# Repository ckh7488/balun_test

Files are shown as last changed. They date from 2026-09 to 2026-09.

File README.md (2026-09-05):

# LibreVNA balun Ethernet 측정

**2026-09-05 임피던스·주문 갱신:** [실제 화면과 옵션별 이유](docs/jlcpcb/README.md) · [계산기 결과 및 CAD 변경/검증](docs/jlcpcb/IMPEDANCE.md). 현재 W/G=0.234/0.216 mm, RF W=0.357 mm를 적용했다.

**Molex 배선 후속 개선:** [전후 그림·수치·설계 판단](docs/molex-routing/README.md). 신호 비아 0개를 유지하며 폭 0.234 mm 통일, A/B 길이 차이 0.79/0.99 mm를 적용했다.

산업용 100BASE-TX 케이블·커넥터·슬립링의 **정적 전송 품질을 먼저 평가**하기 위한 프로젝트다. 일반 RJ45 케이블과 사내 전용 핀맵의 케이블을 같은 플랫폼에서 측정한다.

**설계 검토를 시작한다면 [설계 의도·패치 범위·검토 인계](DESIGN_REVIEW_HANDOFF.md)를 먼저 읽는다.** 사용자 요구, 구현 선택 이유, 현재/이전 문서 구분, 검증 증거와 남은 질문을 정리했다. 현재는 배선된 CAD와 합성 검증 단계이며, O/S/L/T 표준 PCB·실물 RF 검증·새 구성의 제조 release는 아직 없다.

## 현재 기본 구성

양쪽에 `LibreVNA coax → SMA–balun–RJ45 PCB → 고정 RJ45 연결 → 교체형 커넥터 어댑터 → DUT`를 사용한다. 일반 RJ45 DUT는 어댑터 없이 연결한다. 최종 보정 기준면은 **어댑터 뒤의 DUT 접속면**이다. M12와 Molex 조합처럼 양끝 커넥터가 달라도 같은 원리를 사용한다.

1. LibreVNA에서 두 coax 끝의 **50 Ω full 2-port SOLT**를 수행하고 계속 활성화한다.
2. 지그와 어댑터를 고정하고 양쪽 DUT 접속면에서 O/S/L 각 3개와 자작 reciprocal thru 1개를 **측정·저장**한다.
3. Python `UnknownThru`가 이 **7개 표준 데이터**로 커넥터 끝 보정계수를 만든다.
4. 같은 SMA 보정 상태로 측정한 DUT `.s2p`에 저장된 계수를 적용한다. 결과는 **100 Ω balanced effective two-port** `.s2p`, CSV, 그래프다.

LibreVNA 화면은 SMA 기준으로 남는다. 자작 thru를 이상적인 0 ps thru로 등록해 LibreVNA에서 두 번째 SOLT를 켜는 절차가 아니다. 보정에 DUT 파일을 포함하지 않는다.

## 읽는 순서

| 문서/경로 | 내용 |
| --- | --- |
| [DESIGN_REVIEW_HANDOFF.md](DESIGN_REVIEW_HANDOFF.md) | 패치 목적과 변경 범위, 설계 판단 근거, 검토 우선순위·재현 방법 |
| [VNA_TEST_PLAN.md](VNA_TEST_PLAN.md) | 목적, 기준면, 표준 제작, 측정·검증 순서 |
| [analysis/README.md](analysis/README.md) | 설치, 3+3+1 파일 입력, 보정 저장과 DUT 처리 |
| [balun_eth_rj45](balun_eth_rj45/README.md) | 공통 SMA–RJ45 balun PCB |
| [adapters](adapters/README.md) | JLCPCB용 교체형 어댑터와 지그 검토 |
| [docs/legacy](docs/legacy/README.md) | 종전 SMA 기준 비교 계획; 변경 이력용 |

`balun_slipring/`과 `balun_llc16/`의 커넥터 전용 balun PCB는 기존 설계 자산이다. 현재 기본안은 **공통 RJ45 balun PCB + 커넥터별 수동 어댑터 PCB**이며, 과거 4/8/10장 등 구매 문서는 이 기본안의 최신 발주 수량표가 아니다. 기존 설계·BOM을 삭제하거나 이미 주문한 물량을 취소한 것은 아니다. 기존 `export_jlc_release.ps1`도 새 `adapters/`를 export하지 않는다. [이력 자료 목록](docs/legacy/README.md)에서 적용 범위를 확인한다.

## 결과의 의미

OSL의 모델 오차, 재체결 변화, 지그 간 누설과 mode conversion은 남는다. 소프트웨어의 합성 데이터 검증은 실제 커넥터 정확도 검증과 구분한다. 보정된 IL/RL이 좋아도 산업 환경의 EMC·회전 중 순간단선·장기 수명을 보장하지 않는다. 먼저 실제 길이의 수동 조립체를 평가하고, 이후 동작·환경 시험으로 이어간다.

실측 데이터와 결과는 기본적으로 `measurements/`, `results/`에 두며 Git에서 제외한다. 이 공개 저장소에는 코드와 설계·절차를 관리한다.

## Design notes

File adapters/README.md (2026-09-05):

# RJ45 공통 지그용 커넥터 어댑터 PCB

설계 의도·이전 전용 지그와의 차이·검토 우선순위는 [설계 검토 인계](../DESIGN_REVIEW_HANDOFF.md)를 따른다. 아래 세 보드는 **수동 연결 어댑터**다. O/S/L/T 표준 PCB와 패널 도면, 제조 release까지 설계된 상태는 아니다.

**선택: 공통 balun 지그는 기존 RJ45 Rev B를 사용하고, 반복 측정용 어댑터는 PCB로 만든다.** 손배선에서 움직이는 untwist·납땜 부위의 형상을 고정할 수 있고, 커넥터 종류가 바뀌어도 balun PCB를 새로 만들 필요가 없다.

상태: **배선 완료, KiCad 10.0.x DRC/ERC/회로도 대조 통과. 실물 mating·패널 기구·JLC 생산 CAM/coupon 승인 전 설계 초안. 공식 계산기 치수 반영은 완료했다.** 정확한 재검증 버전은 `verification.json`에 기록한다. 제조사 임피던스 시험이나 실측 RF 검증까지 완료했다는 뜻은 아니다.

## 구성과 제작 방식

`공통 SMA–balun–RJ45 PCB → 짧은 shielded RJ45 patch cable → 이 어댑터 PCB → DUT`

PCB용 RJ45 jack과 공장제 patch cable을 사용한다. 일반 RJ45 plug를 PCB 끝에 억지로 납땜하는 형태는 피하고, 측정 중 patch cable과 두 PCB를 고정한다. patch cable까지 어댑터 끝 보정에 포함한다. 일반 RJ45 DUT는 어댑터 없이 공통 지그에 연결한다.

| 어댑터 | DUT 쪽 PCB 커넥터 | 조립 판단 |
| --- | --- | --- |
| [m12_slipring](m12_slipring/m12_slipring.kicad_pro) | Finecables `MB12FBAFF08ST-3`, A-code 8핀 **암** | THT; 부품 조달 뒤 손납땜 가능한 구조. PG9 패널/브래킷으로 체결 토크 지지 |
| [m12_llc](m12_llc/m12_llc.kicad_pro) | Finecables `MB12MBAFF08ST-3`, A-code 8핀 **수** | THT; LLC 암 케이블용. 위 암 버전과 핀맵/성별이 다름 |
| [molex_slipring](molex_slipring/molex_slipring.kicad_pro) | Molex `5055680571`, 1.25 mm 5핀 SMT | 손납땜 가능성은 있으나 작은 SMT이므로 stencil/reflow 또는 JLC PCBA 권장 |

M12는 기존 저장소의 PCB 핀형 후보를 사용했다. 사내에 있는 **전선 인출형/납땜 컵형 M12 몸체를 그대로 이 풋프린트에 꽂을 수 있다는 의미가 아니다.** 실제 사내 부품을 재사용하려면 몸체 형식·핀 배열 도면에 맞춘 별도 carrier가 필요하다. 본 세 설계는 표에 적힌 PCB용 부품을 기준으로 한다.

Molex 케이블 housing은 기존 문서의 `5055650501` 후보와 실제 체결을 확인해야 한다. 같은 Molex 브랜드, 같은 핀 수만으로 호환되지 않는다. [제조사 제품 페이지](https://www.molex.com/en-us/products/part-detail/5055680571)의 mating cycle 정격도 고려해 시험용 커넥터의 교체/재체결 기록을 남긴다.

## 고정 핀맵

다음은 **저장소에 있던 사내 케이블 두 종류의 전용 배선**이다. 범용 M12 Ethernet 핀맵이 아니다. 임의 solder jumper 선택지를 넣지 않고 각 PCB 이름과 결선을 고정했다.

| RJ45 | 신호 | M12 슬립링 암 | M12 LLC 수 | Molex 슬립링 |
| --- | --- | ---: | ---: | ---: |
| 1 | A+ | 4 | 8 | 1 |
| 2 | A− | 3 | 2 | 2 |
| 3 | B+ | 2 | 3 | 3 |
| 6 | B− | 1 | 4 | 4 |
| 4, 5, 7, 8 | 미사용 | 연결 안 함 | 연결 안 함 | 연결 안 함 |

- 슬립링 M12 5–8, LLC M12 1/5/6/7, Molex 5는 PCB에서 각각 독립 NC다.
- LLC 전원 핀이나 슬립링 보조 신호/전원 핀을 GND 또는 shell에 연결하지 않는다.
- 핀맵 근거: [슬립링 PINMAP](../balun_slipring/PINMAP.md), [LLC fixture_spec](../balun_llc16/fixture_spec.json). 실제 DUT continuity 검증은 별도다.
- Open/Short/Load는 각 DUT 접속면에서 해당 **pair의 두 핀 사이**로 만든다. 이 어댑터 자체에 O/S/L 스위치를 넣지 않았다. 표준 정의는 [측정 계획](../VNA_TEST_PLAN.md)을 따른다.

## PCB 사양

| 항목 | 설계값 |
| --- | --- |
| 크기 / 홀 | 66 × 40 mm / 네 모서리 Ø3.2 mm NPTH, M3용 |
| stack-up | 4층 `JLC04161H-7628`, 주문 1.6 mm, nominal 1.5862 mm |
| 동박 | 외층 1 oz, 내층 0.5 oz |
| reference planes | L2/L3 SHIELD plane, stitch via 연결; 내층 신호 배선 없음 |
| pair A / pair B | M12 슬립링·Molex는 두 pair 모두 F.Cu; M12 LLC만 각각 F.Cu / B.Cu |
| coupled trunk | 100 Ω 목표, W 0.234 mm / edge gap 0.216 mm |
| KiCad differential pair 설정 | `ETH100`: width 0.234 mm / gap 0.216 mm; `/PAIR_*` 자동 할당 |
| RJ45 pad escape | M12는 W 0.15 mm neckdown; **Molex는 전 구간 W 0.234 mm**. 팬아웃 전체의 100Ω 보장을 의미하지 않음 |
| signal via | 세 어댑터 모두 0개 |
| shield 접속 | RJ45 SH ↔ 내층 plane; TP1은 M12 두 종류에만 있고 Molex에는 DUT-side bond 없음 |
| M12 body | PCB 신호 핀에 shell 접속 없음; 패널/TP1 연결 여부를 별도 정의·기록 |

모든 부품 몸체는 F면이다. LLC M12는 부품 기준 180° 회전이며 도면/PCB의 A-key와 pin 1 표시를 따른다. M12 체결 토크를 신호 핀 납땜부에 맡기지 않는다. M3 head/washer는 OD 7 mm 이하의 기구 검토 범위이며, M12 panel 높이·nut 접근·실제 connector seating은 실물 도면으로 맞춘다.

| 어댑터 | A+ / A− 배선 길이 | B+ / B− 배선 길이 |
| --- | ---: | ---: |
| M12 슬립링 | 32.793 / 31.855 mm | 32.253 / 33.084 mm |
| M12 LLC | 36.659 / 36.659 mm | 28.514 / 28.514 mm |
| Molex 슬립링 | 31.247 / 30.455 mm | 30.410 / 29.424 mm |

M12 슬립링은 M12 body를 −30° 회전하고 두 pair를 F.Cu에 배치했다. PCB track 길이 차이는 A 약 0.94 mm, B 약 0.83 mm이며 signal via는 없다. [계산·검증 상세](../docs/jlcpcb/IMPEDANCE.md)를 참고한다.

길이는 track 중심선 합계이며 커넥터 내부 핀 길이와 via 전기 길이를 포함하지 않는다. M12 슬립링과 Molex는 큰 길이보정 우회로·layer change보다 짧고 밀접한 배선을 우선했다. Molex는 후속 RJ45 탈출부 개선으로 0.15 mm 구간을 제거했고, PCB track 길이 차이는 **A 0.792 mm / B 0.987 mm**다. 긴 결합 구간과 페어 간격을 함께 고려했으며 [수정 의도·전후 비교](../docs/molex-routing/README.md)를 참고한다. 최종 mode conversion이나 정확한 임피던스는 이 표만으로 보장하지 않는다.

**RF 재검토 우선 항목:** 특히 M12 LLC pair A의 넓은 fanout이 작은 skew를 허용한 더 짧고 밀접한 배선보다 유리한지 확인해야 한다. track 합계 길이 일치에 앞서 uncoupled 길이, loop 면적, 기준면에 대한 대칭을 함께 비교한다. 현재 형상의 우월성을 EM 해석이나 실측으로 검증하지 않았다.

## 레이아웃

빨강 F.Cu, 파랑 B.Cu. M12 LLC의 교차처럼 보이는 다른 색 선은 서로 다른 외층이며 사이에 두 reference plane이 있다. M12 슬립링과 Molex의 두 pair는 모두 빨강 F.Cu다. `planes.svg`에서 채워진 내층 plane도 확인할 수 있다.

### M12 슬립링용 암

M12 slipring layout

[회로도](m12_slipring/m12_slipring.kicad_sch) · [PCB](m12_slipring/m12_slipring.kicad_pcb) · [내층](m12_slipring/planes.svg)

### M12 LLC용 수

M12 LLC layout

[회로도](m12_llc/m12_llc.kicad_sch) · [PCB](m12_llc/m12_llc.kicad_pcb) · [내층](m12_llc/planes.svg)

### Molex 슬립링용

Molex slipring layout

[회로도](molex_slipring/molex_slipring.kicad_sch) · [PCB](molex_slipring/molex_slipring.kicad_pcb) · [내층](molex_slipring/planes.svg)

## 검증과 JLC 제작

- [기존 지그 검토](FIXTURE_REVIEW.md)
- [JLCPCB 제작 조건과 조립 BOM](JLCPCB_BUILD.md)
- [검증 결과와 CAD SHA-256](verification.json)
- [풋프린트 출처](FOOTPRINT_SOURCES.md)

```bash
# KiCad 10의 pcbnew가 설치된 Python으로 새 폴더에만 재생성
python adapters/generate_adapters.py /path/to/new-output
# 저장소의 세 보드 zone refill / DRC / ERC / parity / pinmap / SVG
python adapters/verify_adapters.py --kicad-cli /path/to/kicad-cli
```

generator는 이미 존재하는 출력 폴더를 덮어쓰지 않는다. `verify_adapters.py`는 zone fill을 보드에 저장한 뒤 검사와 hash를 기록한다. 검사 통과는 핀맵의 CAD 전사·배선 검증이며 제조사 mating 검증이나 양산 release 승인이 아니다.

세 프로젝트의 `ETH100` netclass에는 differential width 0.234 mm와 gap 0.216 mm가 실제 저장되어 있다. 사용자 규칙은 coupled gap 최소 0.21 mm, pair skew 최대 2.00 mm, uncoupled 길이 최대 16.60 mm와 signal via 0개를 DRC에서 추가로 강제한다.

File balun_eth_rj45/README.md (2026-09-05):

# balun_eth_rj45 Rev B

**2026-09-05 현재 역할:** 교체형 수동 어댑터와 공유하는 공통 balun PCB다. 방향 전환 당시 회로/동박을 유지했으며, 후속 임피던스 확인에서 배선 폭을 수정했다. [2026-09-05 계산·검증](../docs/jlcpcb/IMPEDANCE.md)과 [주문 화면 가이드](../docs/jlcpcb/README.md)를 따른다. 설계 선택 이유와 검증 한계는 [설계 검토 인계](../DESIGN_REVIEW_HANDOFF.md), 실제 CAD 검토는 [FIXTURE_REVIEW](../adapters/FIXTURE_REVIEW.md)를 참고한다.

2026-09-03: 기존 회로도를 채널별 A3 한 장으로 재배치했다. 연결·부품·DNP와 PCB는 그대로이며, [가독성 정리 결과 및 PDF](../SCHEMATIC_READABILITY_2026-09-03.md)를 참고한다.

LibreVNA 2-port로 일반 Ethernet 케이블과 전용 Ethernet 슬립링을 측정하기 위한 수동 4-pair RJ45 지그다. 동일 보드 2장을 DUT 양쪽에 사용하며, 한 번에 한 pair를 VNA의 두 포트로 측정한다. through 측정에서는 각 보드의 미사용 SMA 3개씩, 두 장 합계 **6개**에 외부 50 Ω 종단기를 연결한다. NEXT/FEXT 등 다른 포트 배치에서도 전체 8개 중 미사용 6개를 종단한다.

> 수동 DUT 전용이다. PoE나 동작 중인 Ethernet 장비에는 연결하지 않는다.

현재 기본안은 이 공통 PCB 두 장과 교체형 RJ45–M12/Molex 어댑터다. 최종 기준면은 어댑터 뒤 DUT 접속면으로 두며 [공통 측정 계획](../VNA_TEST_PLAN.md)과 [어댑터 설계](../adapters/README.md)를 따른다. 기존 LLC/M12 전용 balun PCB와 PCBA 10장 계획은 이전 설계 선택지로 보존한다.

## 채널 구성

| SMA | RJ45 pair | Balun |
|---|---|---|
| J2 / A | 1(+)–2(-) | T1 |
| J3 / B | 3(+)–6(-) | T2 |
| J4 / C | 4(+)–5(-) | T3 |
| J5 / D | 7(+)–8(-) | T4 |

T1–T4는 Mini-Circuits `ADT2-1T+`다. primary pin 3은 SMA center, pin 1은 GND이며, secondary pin 4/6은 각각 pair P/N, pin 5는 RCT, pin 2는 NC다.

ADT2-1T+의 dot은 primary pin 3과 secondary pin 6이다. 따라서 현재 `P=pin 4`, `N=pin 6` 명명은 **지그 한 장에서 한 번의 극성 반전**을 만든다. 동일한 두 보드를 back-to-back으로 쓰는 기본 비교에서는 두 번 반전되어 전달 극성이 복구되지만, 단일 지그 de-embedding, 절대 위상 또는 mixed-mode 부호에는 이 convention을 반영해야 한다.

## JLCPCB Rev B 기판 사양

- KiCad 10, 4층, 주문 두께 1.6 mm, 외층 1 oz / 내층 0.5 oz.
- JLCPCB stack-up `JLC04161H-7628 (Standard)`, nominal stack 1.5862 mm.
- 재료 `FR-4 TG155 / Nan Ya NP-155F`, green solder mask, ENIG.
- L1(F.Cu): 신호와 필요한 짧은 GND 연결만 사용. blanket GND pour 없음.
- L2(In1.Cu): 끊김 없는 `/GND` plane.
- L3(In2.Cu): 끊김 없는 `/GND` plane.
- L4(B.Cu): pair B와 필요한 짧은 GND 연결만 사용. blanket GND pour 없음.
- L1/L4 신호 아래의 기준면은 각각 L2/L3이며, outer pour가 없는 non-coplanar microstrip으로 계산했다.

상세 주문값과 적층 구조는 [JLCPCB_FAB_NOTES.md](JLCPCB_FAB_NOTES.md)를 따른다. 주문 화면에서 다른 stack-up으로 자동 변경되면 그대로 발주하지 말고 선폭을 다시 계산한다.

## 임피던스와 배선 규칙

- SMA single-ended 50 Ω 목표: 외층 폭 `0.357 mm`.
- Ethernet differential 100 Ω 목표: 외층 폭 `0.234 mm`, edge-to-edge gap `0.216 mm`. 2026-09-05 공식 계산기 결과를 반영한 nominal 치수이며 제조 CAM/coupon은 별도 확인한다.
- RJ45 pin field만 폭 `0.15 mm`로 짧게 neck-down한다.
- J1 signal PTH는 pad `1.30 mm`, drill `0.90 mm`; 인접 PTH와 escape trace 사이 최소 동박 간격은 약 `0.295 mm`다.
- 일반 신호 via는 `0.60/0.30 mm`; pair B만 P/N에 각각 같은 through-via 1개를 쓴다.
- A/C/D는 F.Cu, B는 J1 쪽 B.Cu에서 진행한 뒤 T2 앞에서 대칭적으로 F.Cu로 전환한다.
- T2의 기준면 전환용 GND via 네 개는 P/N 사이가 아닌 바깥쪽에 대칭 배치한다. 각 signal via와의 중심 간격은 `1.355 mm`, 동박 가장자리 간격은 `0.755 mm`다.
- T4도 F.Cu에 둔다. B.Cu로 뒤집으면 F.Cu 전용 SMA center launch 때문에 single-ended 쪽 via가 필요하고 채널 간 fixture 대칭성이 나빠진다.
- SMA는 MyAntenna `A-SMA-KE-16.5A` (`C22467617`)로 통일한다. 권장 PCB 두께 `1.6 ±0.05 mm`에 nominal 1.5862 mm는 들어가지만 JLC 일반 두께 ±10%는 이 기구 공차를 보장하지 않으며, 정격은 50 Ω / DC–6 GHz다. 기존 Amphenol `132289`는 PCB 두께 상한 1.57 mm가 nominal stack보다 작아 최종 BOM에서 제외했다.
- `A-SMA-KE-16.5A`는 기존 JLC 조달 검토에서 Standard PCBA의 wave-solder/high-difficulty 품목으로 분류됐다. 현재 CAD의 부품/land pattern을 유지하며, 실제 조립 방식에 맞춰 board-edge 안착, 방향, 납땜 접근성과 두께 공차를 확인한다. PCBA를 선택하면 업체 공정도 확인한다.
- 서로 다른 controlled signal 사이 최소 clearance는 `0.60 mm`; 가능하면 그 이상을 유지한다.
- 결합 gap은 최소 `0.21 mm` / 권장 `0.216 mm`; fan-out을 포함한 uncoupled 길이는 일반 pair `16.0 mm`, split pair B `16.5 mm` 이하로 제한한다.
- transformer 앞에서는 한쪽 선에 짧은 U자 보정을 넣지 않는다. 대신 coupled trunk의 마지막 분기점을 약 1.3 mm 이동해 부드러운 fan-out 형상으로 end-to-end 길이를 맞춘다.
- RCT4를 포함한 선택형 CT-GND 경로는 0 Ω 저항의 GND pad를 내부 GND plane에 짧게 연결한다. RCT가 DNP이면 GND측 동박과 via는 plane에 남지만 transformer center-tap으로 이어지는 경로는 개방된다.
- L2/L3에는 track 및 non-GND zone을 금지한다.

저장된 외층 선분 길이 검산 결과는 다음과 같다. B만 P/N에 동일한 via 한 개가 있으므로 via 지연도 대칭이다.

| Pair | P length | N length | P–N 차이 | P/N via |
|---|---:|---:|---:|---:|
| A | 44.9649 mm | 44.9649 mm | 0.0000 mm | 0 / 0 |
| B | 32.9301 mm | 32.9301 mm | 0.0000 mm | 1 / 1 |
| C | 32.8357 mm | 32.8357 mm | 0.0000 mm | 0 / 0 |
| D | 43.6677 mm | 43.6677 mm | 0.0000 mm | 0 / 0 |

KiCad의 `skew (within_diff_pairs)`는 전체 선분 합이 아니라 결합 구간을 평가한다. bend의 안쪽/바깥쪽 차이를 허용하도록 최대 `0.55 mm`로 두었고, 위 표의 end-to-end 합계는 별도로 검산했다.

## 조립

- T1–T4: Mini-Circuits `ADT2-1T+`, CD542.
- J1: Amphenol `RJE591885401`, CAT6 shielded, LED/magnetics 없음.
- J2–J5: MyAntenna `A-SMA-KE-16.5A` edge-mount SMA, JLC/LCSC `C22467617`; 현재 CAD 기준 부품. 손납땜/PCBA 중 실제 조립 방법에 맞는 안착·납땜 조건을 확인한다.
- RCT1–RCT4: 각 보드에서 기본 DNP이며, 이 `CT-FLOAT` 상태를 golden/DUT 비교의 baseline으로 사용한다.
- `CT-GND` 영향만 별도로 비교할 때 두 보드의 RCT1–RCT4, 총 8개 위치에 0 Ω을 모두 장착한다. 보드 한쪽만 또는 일부 pair만 장착한 mixed 상태는 사용하지 않는다.
- RSH1: 동일 PCB 두 장 중 VNA Port 1 쪽 보드에만 기본 0 Ω을 장착하고, Port 2 쪽 보드는 DNP로 둬 DUT shield의 DC 접점을 한 점으로 만든다. 어느 쪽을 접지했는지는 결과와 함께 기록한다.
- CSH1: 두 보드 모두 기본 DNP. AC shield bond 시험 시 해당 보드의 RSH1을 제거한 뒤 1 nF / 2 kV를 장착한다. 한 보드에서 RSH1과 CSH1을 동시에 장착하지 않는다.

LibreVNA의 두 RF port는 공통 GND를 사용하므로 RCT 8개를 장착하면 두 fixture의 center tap에 공통모드 기준 경로가 추가된다. 따라서 `CT-GND` 결과는 케이블/슬립링 고유값이 아니라 해당 종단 조건을 포함한 비교값으로 해석한다.

두 지그는 같은 PCB artwork를 사용하지만 기본 RSH1 상태는 서로 다르다. CT-FLOAT와 CT-GND를 비교할 때 RSH1/CSH1과 cable 배치를 고정하고, **CT 상태 변경 후 커넥터 끝 O/S/L/T 보정을 다시 취득**한다. patch shield, 어댑터 SHIELD plane, M12 body/패널에 추가 접지 경로가 있으면 한쪽 RSH1만 장착했다는 사실만으로 전체가 단일 접지점이라고 할 수 없다. 실제 경계를 기록한다.

현재 구성의 최소 공통 지그는 한 측정 세트당 **2장**이며, 예비품과 동시 운용 세트 수를 포함한 신규 총 발주량은 아직 정하지 않았다. 사용자가 희망한 bare PCB + 손납땜을 기본 조립 선택지로 검토하고, 작은 RF/SMT 부품의 작업성에 따라 부분 reflow/PCBA를 선택할 수 있다. 과거 문서의 “사용자 납땜을 가정하지 않는다”는 조건을 현재 요구에 적용하지 않는다.

RSH1 조립 상태는 실제 작업 지시와 보드 표기에 반영한다. 공통 CAD/export의 RSH1 DNP 후보를 그대로 쓰면 bonded variant가 자동으로 만들어지지 않는다. 과거 구매 수량·BOM은 [이력 자료](../docs/legacy/README.md)이며, 새 어댑터의 조립 부품은 [JLCPCB_BUILD](../adapters/JLCPCB_BUILD.md)에 있다. 조립 후 RJ45 1–8, shield tab, SMA–transformer 연결과 RSH1 상태를 continuity로 확인한다.

## 측정 순서

1. 두 coax 끝에서 50 Ω full 2-port SOLT를 수행하고 활성화한다.
2. 이 보드와 선택한 어댑터·RJ45 연결을 고정한다. 각 보드의 미사용 SMA를 50 Ω으로 종단한다.
3. 어댑터 뒤 DUT 접속면에서 Port 1 O/S/L 3개, Port 2 O/S/L 3개, reciprocal 자작 thru 1개를 측정해 저장한다.
4. [Python 도구](../analysis/README.md)로 커넥터 끝 UnknownThru 보정계수를 만든다.
5. 같은 SMA 보정 상태에서 DUT를 측정하고 저장된 계수로 보정한 100 Ω 결과를 분석한다.
6. pair·어댑터·포트 할당·CT/shield 상태가 달라지면 해당 구성의 보정을 새로 만든다.

SMA SOLT만 적용한 원본에는 지그가 포함된다. Python 결과는 표준 모델과 고정된 두 error box 가정 아래 커넥터 기준면으로 이동한 balanced effective two-port다. full mixed-mode Sdd/Sdc/Scd/Scc나 산업 환경 적합 판정을 뜻하지 않는다. NEXT/FEXT는 별도 연결별 보정 및 fixture 누설 검증이 필요하다. 최신 설정과 결과 해석은 [VNA_TEST_PLAN.md](../VNA_TEST_PLAN.md)를 따른다.

## 파일과 재생성 주의

- `balun_eth_rj45.kicad_pcb/.kicad_pro/.kicad_dru`: Rev B 설계와 규칙.
- `balun_eth_rj45_drc.rpt`: 최종 KiCad DRC 결과.
- `apply_jlc_rev_b.py`: 수동 저장본을 JLC Rev B로 변환한 재현용 updater. 전체/`--routing-only` 경로 모두 변경 뒤 native KiCad zone refill+save와 DRC/schematic parity를 강제하고, 실패하면 nonzero로 중단한다. 이미 Rev B인 보드에는 전체 변환을 다시 실행하지 말고 fan-out만 갱신할 때 `--routing-only`를 사용한다.
- `generate_pcb.py`: 이전 Rev A 생성기. 기본 실행은 차단되어 있으며 현 Rev B PCB를 만들지 못한다.
- `fabrication/`과 `*_fabrication_HOLD.zip`: 폐기된 Rev A 로컬 참고 자료다. Git에서 제외하며 발주에 사용하지 않는다.

제작 Gerber는 항상 zone을 확인·재충전하는 `--check-zones`로 export하고, In1/In2에 실제 GND plane region이 있는지 CAM에서 확인한다. updater가 fill을 저장하더라도 이후 수동 편집본에 대한 release 검사는 생략하지 않는다.

## 공식 자료

- [JLCPCB impedance calculator guide](https://jlcpcb.com/help/article/user-guide-to-the-jlcpcb-impedance-calculator)
- [JLCPCB impedance stack-ups](https://jlcpcb.com/impedance)
- [JLCPCB multilayer structures](https://jlcpcb.com/help/article/multi-layer-pcb-standard-laminated-structures)
- [JLCPCB PCB capabilities](https://jlcpcb.com/capabilities/pcb-capabilities/)
- [ADT2-1T+ datasheet](https://www.minicircuits.com/pdfs/ADT2-1T+.pdf)
- [RJE591885401 product page](https://www.amphenol-cs.com/product/rje591885401.html)
- [MyAntenna A-SMA-KE-16.5A / C22467617](https://jlcpcb.com/partdetail/MyAntenna-A_SMA_KE_165A/C22467617)
- 현재 제작 범위는 [설계 검토 인계](../DESIGN_REVIEW_HANDOFF.md)와 [어댑터 제작 초안](../adapters/JLCPCB_BUILD.md)을 따른다. 루트의 기존 합산 구매 CSV/가이드는 과거 구성의 기록이다.

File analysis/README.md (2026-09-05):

# M12 / 커넥터 끝 UnknownThru 보정 도구

전체 설계와 보정 가정을 검토할 때는 [설계 검토 인계](../DESIGN_REVIEW_HANDOFF.md)를 먼저 읽는다. 특히 adapter-end 기준면, 50/100 Ω 처리, 첫 full SMA SOLT 이후의 zero switch terms 가정과 실물 미검증 범위를 확인한다.

대상: **LibreVNA full 2-port SMA SOLT가 이미 적용된** complex Touchstone. raw 측정, 포트별 SOL만 적용한 측정, 크기만 저장한 CSV에는 사용하지 않는다. 이름은 `m12_cal`이지만 양끝이 M12/RJ45/Molex인 경우도 해당 접속면의 표준과 핀맵을 정의하면 같은 방식이다.

## 설치

저장소 루트에서 실행한다. Python 3.10 이상을 사용한다.

```bash
python -m venv .venv
# Windows PowerShell: .venv\Scripts\Activate.ps1
# Linux/macOS: source .venv/bin/activate
python -m pip install -r requirements-analysis.txt
```

## 입력: 3 + 3 + 1, DUT는 별도

하나의 고정된 VNA 포트/지그/어댑터/차동 pair 조합마다 한 세트를 만든다.

| 기본 파일명 | 내용 |
| --- | --- |
| `p1_open.s1p`, `p1_short.s1p`, `p1_load.s1p` | Port 1에서 본 세 표준의 S11 |
| `p2_open.s1p`, `p2_short.s1p`, `p2_load.s1p` | Port 2에서 본 세 표준의 **S22를 단일 포트로 내보낸 값** |
| `thru.s2p` | 양 어댑터 사이 자작 thru의 S11/S21/S12/S22 |
| `dut_001.s2p` 등 | 같은 SMA 보정 상태의 DUT; 보정계수 생성에 사용하지 않음 |

Port 2의 잘못된 S11 내보내기를 피하려면 O/S/L도 `.s2p`로 저장하고 설정의 파일명을 바꿔도 된다. 코드는 `p1`에서는 S11, `p2`에서는 S22를 추출한다. 단일 `.s1p` 안에는 원래 어느 포트에서 왔는지 표준화된 정보가 없으므로 사용자가 확인해야 한다.

모든 파일은 같은 주파수 grid와 50 Ω SMA reference를 유지한다. 자동 보간하지 않는다. RI, MA, DB 형식은 Touchstone이 지원하는 복소 표현이면 읽을 수 있다. LibreVNA에서 보정을 켠 채 내보냈는지는 파일만으로 증명할 수 없으므로 세션 기록에 남긴다.

## 사용

```bash
python -m analysis.m12_cal init measurements/run01/session.json
```

생성된 `session.json` 옆에 일곱 표준 파일을 놓는다. `setup_id`, `reference_planes`, 표준 모델과 thru 극성/지연, 실제 핀 번호, 지그·어댑터·coax·load ID, CT/shield 상태, sweep 설정, SMA calibration ID를 기록한다. 파일 경로는 **설정 파일 위치 기준**이다.

```bash
python -m analysis.m12_cal calibrate measurements/run01/session.json --out measurements/run01/cal.npz
python -m analysis.m12_cal apply measurements/run01/cal.npz measurements/run01/dut_001.s2p --out results/run01
python -m analysis.m12_cal apply measurements/run01/cal.npz measurements/run01/dut_002.s2p measurements/run01/dut_003.s2p --out results/run01
```

출력 파일명은 `dut_001_m12.s2p/.csv/.png/.json`이다. 입력 원본은 수정하지 않으며 기존 결과와 보정 파일을 덮어쓰지 않는다. `.npz`에는 주파수·복소 보정계수·설정·표준 파일 SHA-256이 포함된다. pickle을 사용하지 않는다.

| 출력 | 의미 |
| --- | --- |
| `.s2p` | 최종 접속면에서 100 Ω으로 환산한 balanced effective two-port |
| `.csv` | RL1/RL2, IL21/IL12, 전달 위상, group delay, complex reciprocity 차이 |
| `.png` | 주파수별 IL/RL/위상/지연 |
| `.json` | 모델·세션·파일 hash, passivity 진단용 최대 singular value, 한계 |

IL/RL은 양의 loss 부호다. group delay/위상은 전달이 noise floor에 가까우면 의미가 약하다. 최대 singular value가 1을 넘는 현상은 수동 DUT에서 보정·노이즈·모델 문제를 조사할 단서다. 코드는 합격/불합격이나 절대 정확도를 자동 판정하지 않는다.

## O/S/L 모델

초기 설정은 이상적인 Open, Short, 100 Ω Load다. **실물 표준이 이상적이라는 검증 결과가 아니다.** 실제 제작에 맞는 추정·모델이 있으면 포트별로 독립 수정한다.

| 표준 | 설정 | 모델 |
| --- | --- | --- |
| Open | `capacitance_pf` | pair 사이 병렬 C |
| Short | `resistance_ohm`, `inductance_nh` | 직렬 R+L |
| Load | `resistance_ohm`, `inductance_nh`, `capacitance_pf` | 직렬 R+L 전체에 병렬 C |
| 공통 | `offset_delay_ns`, `offset_z0_ohm` | 종단 앞 lossless 선로의 **편도** 지연과 차동 특성 임피던스; 기본 0 ns, 100 Ω |

M12 수 플러그의 핀과 배선이 만드는 길이는 offset/기생성분의 일부다. 빈 암 커넥터 Open과 수 커넥터 Short/Load를 모두 지연 0으로 가정하면 그 차이가 오차로 남는다. 여기의 lumped/단일 선로 모델은 복잡한 커넥터 모드 변환을 표현하지 못한다.

표준을 보정한 결과가 정확히 이상적으로 보이는 것은 **그 모델을 강제한 결과**다. 모델 검증에는 다른 저항(예: 별도 제작 150 Ω), 다른 짧은 선로, 재체결 반복과 모델 민감도 비교를 사용한다. 예시 수치를 실제 M12의 측정값으로 취급하지 않는다.

## 자작 thru

필요한 것은 reciprocal 연결과 대략적인 전달 위상/극성이다. 완전한 S-parameter 파일을 미리 알 필요가 없다. 두 핀쌍의 P→P/N→N을 기준으로 `polarity=1`, 한쪽이 교차되면 `-1`이다. `delay_ns`에는 대략적인 **편도** 지연을 넣는다. 두 해의 전달 위상은 180° 차이이므로 예상 위상 오차를 각 주파수에서 90°보다 충분히 작게 유지한다. 길이가 짧고 극성이 확인된 thru가 실용적이다.

UnknownThru는 비상호 thru나 추가적인 mode conversion을 해결하지 못한다. 잘못된 극성으로도 그럴듯한 IL/RL이 나올 수 있으며, 결과 그래프만으로 올바른 부호를 자동 보장할 수 없다.

## 50 Ω / 100 Ω 처리와 switch terms

scikit-rf는 measured/ideal의 z0 일치를 요구한다. 따라서 보정 계산 자체를 **50 Ω 기준으로 일관되게** 수행한다. 균형 포트의 실제 100 Ω Load 모델은 이 단계에서 `Γ=(100−50)/(100+50)=1/3`이다. 보정된 DUT를 얻은 다음 `Network.renormalize(100)`으로 파동 기준을 변환한다. 원본의 `R 50`을 `R 100`으로 바꾸거나 보정 전에 입력을 임의 환산하지 않는다.

SMA의 첫 full SOLT가 장비의 source/load match와 switching 효과를 보정했다는 전제에서 두 번째 단계는 고정 fixture 두 error box만 추정하고 switch terms를 0으로 둔다. LibreVNA raw 데이터의 switch terms를 0이라고 가정하는 방식이 아니다. 초기 보정 잔차, fixture 간 직접 누설, 다른 pair와의 결합·공통모드 경로는 이 단순 모델 밖이다.

## 합성 데이터로 실행 확인

```bash
python -m analysis.synthetic_demo measurements/synthetic
python -m analysis.m12_cal calibrate measurements/synthetic/session.json --out measurements/synthetic/cal.npz
python -m analysis.m12_cal apply measurements/synthetic/cal.npz measurements/synthetic/dut.s2p --out results/synthetic
python -m pip install pytest
python -m pytest tests/test_m12_cal.py -q
```

합성 예제는 비대칭·손실·부정합 fixture, 50↔100 Ω 변환, 서로 다른 OSL 기생성분과 부정합 thru를 포함한다. `expected_dut_100ohm.s2p`가 정답이다. 이 검증은 파일 입출력·수학·기준 임피던스 처리를 확인하며 실측 정확도를 인증하지 않는다.

## 구현 근거

- [scikit-rf UnknownThru](https://scikit-rf.readthedocs.io/en/latest/api/calibration/generated/skrf.calibration.calibration.UnknownThru.html)
- [검증한 scikit-rf 1.8.0 소스](https://github.com/scikit-rf/scikit-rf/blob/v1.8.0/skrf/calibration/calibration.py)
- [LibreVNA calibration 구현](https://github.com/jankae/LibreVNA/blob/master/Software/PC_Application/LibreVNA-GUI/Calibration/calibration.cpp)
- [Keysight calibration standard 모델 설명](https://helpfiles.keysight.com/csg/e5080a/s3_cals/calibration_standards.htm)

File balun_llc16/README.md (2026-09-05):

# LLC 케이블 VNA 지그 — 구동기 to RJ45

> **2026-09-05 이력 안내:** 아래는 LLC 커넥터 전용 balun 보드의 이전 설계·구매 기록이다. 현재 기본안은 [공통 RJ45 balun + 수동 어댑터](../adapters/README.md)이며, [설계 검토 인계](../DESIGN_REVIEW_HANDOFF.md)를 먼저 읽는다. 아래의 “최신 구매” 표기는 당시 기준이고 현 구성의 발주 지시가 아니다. 기존 B면 M12 보드와 새 F면 수동 어댑터는 별개 CAD다. 과거 커넥터 삽입 확인을 새 보드의 패널/체결 검증 완료로 확대 해석하지 않는다.

> **2026-09-03 최신 구매 상태:** PCB는 JLCPCB에서 미조립 제작, 부품은 DigiKey 한국 중심(국내 인두팁만 예외)으로 구매한다. 실사용 Molex 2 + RJ45 4 + LLC 2 = 8장, 제작 예산 3종×5장=15장. 슬립링 M12 암 보드/암커넥터는 기존 케이블→RJ45 개조로 제외하며 LLC M12 수커넥터는 사내품 사용이다. **사내 수커넥터의 PCB 삽입은 사용자 확인 완료**이고 전기적 핀맵/수량 확인은 별도다. Samtec SMA는 구매 후보이며 현 CAD/MyAntenna와 최종 두께·공차/제조파일 정합 승인 전이다. 아래 이전 PCBA/구매 수량·품번은 발주에 사용하지 말고 [최신 구매요청서](../PURCHASE_REQUEST_FORM_DRAFT_2026-09-03.md)를 따른다. 이번에 PCB/회로/풋프린트는 변경하지 않았다.

상태: **PCB DRAFT A (CAD Rev A-PCB) 배치·배선 및 ERC/DRC/parity 검증 완료 / JLC 조달·조립 및 기구 승인 대기 / DO NOT ORDER**

새 PCB는 [balun_llc16.kicad_pcb](balun_llc16.kicad_pcb)다. [앞·뒷면 및 내부 GND 면 검토 PDF](../../output/pdf/balun_llc16_pcb_review.pdf)와 [대응 회로도 PDF](../../output/pdf/balun_llc16_schematic.pdf)를 함께 제공한다. 기존 RJ45·슬립링 PCB는 이번 작업에서 수정하지 않았다.

검토 원본은 `../Docs/16. LLC16_13M_1. 케이블 조립체 전원 및 통신용.pdf` 1페이지다. 파일명은 LLC16_13M_1이지만 도면 제목란과 케이블 마킹은 **LLC-13M-1**, 작성일은 **2022-04-25**다. 사용자가 제시한 LLC 케이블의 설계자료로서 이 도면을 기준으로 회로와 PCB를 설계한다. 원본 PDF는 변경하지 않았다.

**설계 기준:** 도면의 핀 번호와 배선선을 기준으로 PCB까지 작성했다. 실물 continuity 측정은 설계 착수 조건이 아니라 최초 VNA 연결 전 확인 항목이다. 수커넥터는 제조사 자료를 기준으로 선정했으며, 추가 내부 배선 자료를 기다리지 않는다. 실제 조달·조립 가능 여부와 케이블 체결·패널 지지는 제조 승인 전에 확인한다.

## PCB 구성과 검증 결과

| 항목 | PCB DRAFT A |
| --- | --- |
| 외형 / 적층 | 68 x 44 mm, 4층, JLC04161H-7628, 주문 1.6 mm / CAD 1.5862 mm |
| J1 | Finecables `MB12MBAFF08ST-3`, M12 A-coded 8핀 수, PG9, B면 장착, 필수 FIT |
| 신호층 / 기준면 | 모든 RF·차동 신호 F.Cu, In1/In2 GND 면, 신호 비아 0개 |
| 목표 임피던스 | SMA 50 Ω: W0.35 mm / 차동 100 Ω: W0.23, gap0.22 mm |
| TX P/N 길이 | 약 30.487329 / 30.487329 mm |
| RX P/N 길이 | 약 25.454235 / 25.454237 mm |
| P/N 길이 차이 | 두 pair 모두 0.001 mm 미만, CAD 계산값이며 제조 공차가 아님 |
| 50 Ω A/B 경로 | 각각 26.762102 mm, 기존 RF launch와 같은 형상 |
| fan-in/out | TX 최대 9.393 mm / RX 최대 10.627 mm, native 11.2 mm 제한 유지 |
| 기본 실장 | J1/J2/J3/T1/T2 FIT, RCT1/RCT2 DNP |
| 전원 핀 | J1.1/5/6/7 모두 단독 NC, 신호/GND/plane/track 연결 없음 |
| 검사 | ERC 오류·경고 0, DRC 위반 0, 미연결 0, 회로도-PCB 불일치 0 |

내층 GND는 native refill 후 저장되어 있으며 각 층의 단일 연결 polygon을 확인했다. 두 pair의 전체 길이는 서로 다르므로 TX와 RX가 같은 지연을 갖는다는 뜻은 아니다. 임피던스는 기존 [지정 적층 검증](../JLCPCB_IMPEDANCE_VERIFICATION_2026-08-31.md)의 geometry를 적용한 **설계 목표**이며, 새 M12 전이부의 3D EM 해석·실측 보증이나 정식 Ethernet 적합성 인증을 수행한 것은 아니다. 짧은 비결합 fan-out과 커넥터 응답은 REF/DUT 지그 비교에 포함된다.

### 수커넥터 풋프린트와 장착

[Finecables 제품 도면 p259](https://www.finecables.com/uploadfiles/2022/06/259%20M12%20A_coding%20Straight%20Connector%2C%20Panel%20Mount%2C%20PCB%20Type%2C%20Front%20fastened.pdf) 및 [2025 제조사 카탈로그](https://www.finecables.com/uploadfiles/2025/09/2025_Finecables_Industrial_Connector_Catalogue.pdf)의 p293/p415를 직접 확인했다. p415의 **Male recommended PCB layout**으로 별도 `llc16.pretty/Finecables_MB12MBAFF08ST-3.kicad_mod`를 만들었다.

- pin 8 중앙, 외곽 pin 1~7의 PCD 5.5 mm, key 기준 ±33° 및 나머지 49° 간격.
- 제조사 권장 finished hole Ø1.0 mm, pad Ø1.8 mm. 암 풋프린트 이름만 변경한 것이 아니라 수커넥터 PCB-view의 번호를 확인한 좌표다.
- J1은 보드 뒷면에서 아래로 돌출한다. 중심은 (32,42) mm, 회전 0°이며 key는 위에서 투영하면 보드 위쪽을 향한다. 반대쪽 면에서 보면 좌우가 바뀌므로 조립 도면의 면을 확인한다.
- 본체/너트 공간은 보수적으로 Ø20 mm envelope와 Ø21 mm courtyard로 예약했다. 커넥터는 **PG9 패널 고정형**이므로 납땜 핀만으로 케이블 체결 하중을 받게 하지 않는다. 패널 cut-out, 보드-패널 거리, standoff와 케이블 굽힘 공간은 아직 기구 승인 대상이다.
- 이 부품에는 earth/shield pin이 없다. shell을 VNA GND에 임의 연결하지 않고 실제 fixture의 shield 조건을 측정 기록에 남긴다.
- 정확한 JLC/LCSC 번호, 재고와 Standard PCBA 공정 승인은 미확인이다. 부품이 없으면 업체 사급/조달을 확인하거나 새 후보를 별도 검증한다. 자동 대체·사용자 손납땜을 가정하지 않는다.
- M12 상세 3D STEP 모델은 아직 연결하지 않았다. KiCad 3D 화면에서 본체가 생략되더라도 J1은 필수 실장 대상이다.

## 수량과 공유 방식

- 기존 슬립링 2세트: Molex 2장 + 슬립링 M12 2장 = 4장.
- 기존 RJ45 2세트: RJ45 보드 4장.
- LLC 측정용: **LLC 전용 M12 보드 2장 추가**, 기존 RJ45 보드 중 2장을 번갈아 공유.
- 요청 조립품 합계는 **10장**이다. 세 종류 DUT용 지그를 모두 독립된 두 세트씩 상시 구성하려면 RJ45 보드도 2장 더 있어야 하므로 그때는 12장이다.
- 전부 JLC PCBA를 목표로 하며, 커넥터·RF 부품의 사용자 손납땜을 전제로 하지 않는다. 아직 10장 확정 견적이나 제조 승인은 없다.

## 원본 배선선과 핀 번호로 확인한 매핑

| 신호 | LLC M12 P1 | RJ45 P2 | 기존 RJ45 지그 포트 | LLC 지그 네트 |
| --- | ---: | ---: | --- | --- |
| TX+ | 8 | 1 | J2 / A, + | PAIR_TX_P |
| TX- | 2 | 2 | J2 / A, - | PAIR_TX_N |
| RX+ | 3 | 3 | J3 / B, + | PAIR_RX_P |
| RX- | 4 | 6 | J3 / B, - | PAIR_RX_N |
| P24 / P242 | 1 | RJ45로 연결되지 않음, 전원 꼬리선 | 연결 금지 | NC |
| P24 / P242-1 | 7 | RJ45로 연결되지 않음, 전원 꼬리선 | 연결 금지 | NC |
| N24 / N242 | 5 | RJ45로 연결되지 않음, 전원 꼬리선 | 연결 금지 | NC |
| N24 / N242-1 | 6 | RJ45로 연결되지 않음, 전원 꼬리선 | 연결 금지 | NC |

도면은 RJ45 핀 이름 표에서 4번을 BD-, 6번을 CD-로 기입하지만, 실제 RX- 배선선은 **RJ45 6번**에 닿는다. 초안은 핀 이름 표가 아니라 연속된 배선선과 숫자 1/2/3/6을 기준으로 한다. 실측에서 RX-가 4번으로 나오면 기존 RJ45 A/B 지그를 그대로 사용할 수 없으므로 중지하고 케이블 도면/결선을 다시 확인한다. 핀 번호를 임의로 보정하거나 케이블을 개조하지 않는다.

## 기존 슬립링 M12 보드를 그대로 쓰면 안 되는 이유

| 용도 | TX+ / TX- | RX+ / RX- | 지그에서 NC로 둘 핀 |
| --- | --- | --- | --- |
| 기존 슬립링 | M12 4 / 3 | M12 2 / 1 | 5, 6, 7, 8 |
| LLC-13M-1 도면 | M12 8 / 2 | M12 3 / 4 | 1, 5, 6, 7 |

특히 M12 **1번은 기존 슬립링의 RX-지만 LLC에서는 P24**, 8번은 기존 슬립링에서 NC인 전원 귀로지만 LLC에서는 TX+다. 같은 모양이라는 이유로 실크만 바꿔 재사용하지 않는다. 모든 측정은 전원을 분리한 수동 케이블에만 수행한다.

도면 BOM은 P1을 **NorComp / T4112012081-000**으로 적지만, 이 정확한 부품번호의 [TE Connectivity 공식 페이지](https://www.te.com/en/product-T4112012081-000.html)는 **M12 A-code, 8핀, female/socket, right-angle**로 설명한다.

**2026-09-03 확인:** 사용자가 제공한 LLC 실물 정면 사진에서 socket 접점인 암커넥터를 확인했고, 사용자도 LLC 지그에는 수커넥터, 슬립링 지그에는 암커넥터가 필요함을 확인했다. 앞서 남겼던 암수 방향의 불확실성은 해소되었다.

| 용도 | DUT 측 | PCB 지그 측 | 확인 근거 |
| --- | --- | --- | --- |
| LLC / 구동기 to RJ45 | 암 / socket | **수 / pin** | 이번 실물 사진 + 사용자 확인 |
| 슬립링 | 수 / pin | **암 / socket** | 사용자 확인 + 기존 설계 조건 |

사진 원본은 `C:/Users/artzy/Documents/DaouMessenger 4.0/4ebb4012-2e32-4099-8901-afd8052dfe48.jpg`이며 변경하지 않았다. 사진만으로 정확한 MPN, 치수, 핀 번호별 내부 배선까지 확인된 것은 아니다. 제조사/부품번호 표기의 불일치와 실제 continuity 검증은 별도로 남는다. 기존 슬립링 PCB의 Finecables `MB12FBAFF08ST-3`는 암 후보이므로 LLC에는 위의 수커넥터를 별도 선정했으며, 단순 반전 배치로 같은 footprint를 재사용하지 않았다.

## CAD 및 표기 상태

- `balun_llc16.kicad_sch`, revision **A-PCB**: 기존 SMA/발룬 TX·RX 연결을 유지하고 선정한 J1 MPN/footprint를 반영했다. M12 논리 핀맵, 케이블 연결표 및 주의사항은 A4 1페이지에 유지했다. 전원 핀 J1.1/5/6/7은 모두 명시적 NC다. RCT1/RCT2는 모두 DNP다.
- J1은 **필수 실장할 수커넥터**다(`dnp no`). MPN/footprint는 위와 같이 선정했으며 LCSC 번호와 JLC 조립 승인은 미확인이다. 제조 보류는 Assembly 속성과 도면 상태로 표시하며 커넥터를 빼고 납품한다는 뜻이 아니다.
- `CT_A`, `CT_B`는 각 발룬 5번과 DNP 저항만 연결한다. 기본 조립에서 중심탭은 GND와 연결되지 않는다. 발룬 2번은 라이브러리 정의상 NC이며 배선하지 않는다.
- 확인용 PDF는 저장소 루트의 `output/pdf/balun_llc16_schematic.pdf`다. KiCad에서 직접 출력한 회로도이며 원본 schematic과 전기 연결이 동일하다.
- `.kicad_pcb`, `.kicad_dru` 및 대응 프로젝트 설정을 만들었다. 제조 Gerber/BOM/CPL은 **아직 내보내지 않았다**. ERC/DRC 통과만으로 제조 승인하지 않는다.
- 기존 슬립링 M12 보드의 실제 F.Silkscreen 제목은 **`슬립링 / SLIPRING`**으로 구분했다. 전기 연결은 변경하지 않았다.
- LLC PCB F.SilkS에 **`구동기 to RJ45`**, `LLC-13M-1 / M12 MALE`, `TX 8/2 RX 3/4`와 전원 NC 경고를 넣었다. 실제 한글 font가 native PDF에 출력되는지도 확인했다.
- 성별이 다르더라도 실제 부품/어댑터로 오접속될 수 있으므로, 두 지그는 각각 `SR-01/02`와 `LLC-01/02`로 식별한다.

회로도 재생성은 KiCad 10 번들 Python으로 `generate_schematic.py --output-directory <비어 있는 검토 폴더>`를 실행한다. 기존 파일은 기본적으로 덮어쓰지 않으며, 검토한 자동 생성 파일에 한해 `--replace-generated-sha256 <기존 파일의 SHA-256>`를 지정할 수 있다. 저장 직전에도 hash를 재검사해 동시 수정 내용을 덮어쓰지 않는다. `layout_schematic.py`는 LLC 도면 배치만 담당하며 공유 슬립링 생성기나 기존 슬립링/RJ45 회로·PCB는 이번 회로도 정리에서 수정하지 않았다.

### PCB 재생성과 검증 기록

KiCad 10 번들 Python으로 먼저 `generate_schematic.py --output-directory <검토 폴더>`, 이어서 `generate_pcb.py --output-directory <동일 검토 폴더>`를 실행한다. PCB 명령은 그 폴더의 회로도에서 native XML을 내보낸 뒤 LLC 배치·배선을 만들고 zone refill/save, ERC, DRC와 schematic parity를 검사한다. live 프로젝트 폴더로 직접 생성하지 못하게 했으며, 기존 PCB 덮어쓰기는 일치하는 `--replace-generated-sha256`이 있어야 한다. 검토 폴더의 기존 자동 생성 보조 파일은 갱신될 수 있으므로 수작업 파일이 없는 전용 폴더를 사용한다.

`verify_pcb.py <검토 폴더 또는 live 프로젝트 폴더>`는 저장된 PCB의 전체 pad/net 일치, male 핀 좌표·홀, 전원 핀 절연, FIT/DNP, GND fill, 신호 경로 및 길이를 추가 검사한다. 같은 폴더의 최신 native `balun_llc16.xml`과 `drc.json`이 필요하다. [verification.json](verification.json), [drc.json](drc.json), [erc.rpt](erc.rpt), [routing_metrics.json](routing_metrics.json)에 이번 결과를 보존했다.

수정 전 LLC 회로도·설정·생성기는 `../../outputs/balun-llc16-pcb-20260903/before/`, 검토용 CAD는 같은 경로의 `stage/`에 보존했다. 기존 세 PCB는 이번 작업에서 수정하지 않았다.

최종 live CAD에서 native XML/ ERC/DRC를 다시 출력하고 `verify_pcb.py`를 통과했다. 검사 전후 PCB·회로도 hash와 검토용 CAD 일치를 확인했다. PCB 생성기의 무승인/틀린 hash 덮어쓰기와 live 폴더 직접 생성도 모두 거부되는 것을 확인했으며 이 검사로 검토 파일은 바뀌지 않았다. `../verify_schematic_refresh.py` 회귀 검사에서 기존 3종의 새 회로도-PCB 일치, ERC/DRC, 기존 PCB·규칙 파일 무변경 및 LLC 회로도 재생성 일치도 통과했다.

### 회로도 검증 이력

KiCad 10의 native ERC는 **오류 0 / 경고 0**이다. `verify_schematic.py <KiCad XML netlist>` 검산은 전체 7개 부품/15개 net, M12 8개 핀의 실제 net membership, 양쪽 발룬/SMA 경로, primary GND, CT 경로, 전원 핀·발룬 2번의 단독 NC, 필수 부품 FIT 및 RCT DNP, 10장 구성과 LLC load 4개를 확인한다. 이는 문서 전사와 회로 연결 검사이지 실제 케이블의 RF 성능이나 부품 체결을 검증한 결과가 아니다.

추가 회귀 검사에서 동일 회로도의 재생성 일치, 무승인/틀린 hash 덮어쓰기 거부를 확인했다. 핀 2/4 교환, 전원 핀의 신호 net 연결, RCT 오실장, 필수 J1의 DNP 처리라는 4개 변조 netlist도 모두 검산에서 거부되었다. PDF는 최종 출력을 렌더링해 한글, 주석, 부품명 방향 및 페이지 잘림을 확인했다. 이전 회로도는 `../../outputs/balun-llc16-review-20260903/before-schematic-a/balun_llc16.kicad_sch`에 보존했다.

표기만 변경한 기존 슬립링 M12 PCB는 zone refill과 schematic parity를 포함한 native DRC에서 위반 0 / 미연결 0이었다. 원본 커넥터 후보·기구·임피던스 release HOLD는 그대로 유지한다.

## 남은 작업의 구분

### 설계·제조 준비

1. 선정한 `MB12MBAFF08ST-3`의 업체 공급·조립, 실제 mating, 패널 cut-out/지지·장착 높이와 접근 공간을 승인한다.
2. 작성된 4층 PCB를 제조 시점의 stack-up/임피던스, SMA 두께 fit 및 CAM 자료와 대조한다. 이후 PCB를 수정하면 ERC/DRC/parity와 NC 검사를 다시 수행한다.
3. 부품 조달·JLC 조립·생산파일과 최종 견적을 검토한 후 제조 승인한다. 도면의 브랜드/핀 이름 불일치는 위에 기록한 해석을 유지하며 미해결 실측 대기라는 이유로 설계 자체를 중단하지 않는다.

### 최초 VNA 연결 전 실물 검사

1. 암수 확인용 정면 사진은 이미 수령했다. 실제 케이블의 마킹/개정과 key/pin 1을 가능한 범위에서 기록한다.
2. 전원과 활성 장비를 모두 분리하고, M12 8→RJ45 1, 2→2, 3→3, 4→6 및 전원선 1/5/6/7의 분리를 검사한다. 특히 도면의 RX- 배선은 숫자 6번을 사용한다.
3. shell/shield 관계를 확인해 REF와 DUT의 차폐 조건을 고정한다. 실물이 도면과 다르면 연결을 중단하고 원인을 확인한다.

측정 연결표와 종단 수량은 [`MEASUREMENT.md`](MEASUREMENT.md), 전체 구매 범위는 [`../PCBA_PURCHASE_SCOPE_2026-09-03.md`](../PCBA_PURCHASE_SCOPE_2026-09-03.md)를 따른다.

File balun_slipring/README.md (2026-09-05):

# balun_slipring

> **2026-09-05 이력 안내:** 아래는 커넥터 전용 balun 보드의 이전 설계·구매 기록이다. 현재 기본안은 [공통 RJ45 balun + 수동 어댑터](../adapters/README.md)이며, [설계 검토 인계](../DESIGN_REVIEW_HANDOFF.md)를 먼저 읽는다. 아래의 “최신 구매” 표기는 당시 기준이고 현 구성의 발주 지시가 아니다. 공개 핀맵/풋프린트 근거는 계속 참고하되 새 어댑터의 치수·실장면·검증 결과와 구분한다.

2026-09-03: Molex측·M12측 회로도를 각각 A4 한 장으로 재배치했다. 연결·부품·DNP와 PCB는 그대로이며, [가독성 정리 결과 및 PDF](../SCHEMATIC_READABILITY_2026-09-03.md)를 참고한다.

PALA720 2세대 슬립링의 100BASE-TX 전송 특성을 LibreVNA 2포트로 비교 측정하기 위한 지그 프로젝트다.

`Docs/[인수인계] PALA720.pptx` 슬라이드 14에서 2세대 Ethernet 논리 핀맵을 확인하고, KiCad `DRAFT 1` 회로도와 두 PCB의 connector fan-out에 반영했다. 다만 이 표는 인수인계 문서의 전사값이며 실물 `REV-504`의 continuity 측정값은 아니다. 커넥터 기구와 SMA/stack-up도 아직 차단 항목이므로 **DO NOT FABRICATE** 상태다.

## 문서에서 확인한 2세대 핀맵

슬라이드 14는 2세대의 Ethernet 4선 핀 번호와 선색을 보여 주지만 5극 하우징의 정확한 MPN을 직접 적지 않는다. Molex `5055650501`은 슬라이드 15의 별도 4세대 케이블 표에 명시된 부품을 2세대에도 적용해 본 **교차 슬라이드 추론 후보**다. PCB측 `5055680571`은 Molex가 공식적으로 `505565` series와 맞물린다고 지정한 같은 Micro-Lock Plus 1.25 mm 5극 header지만, 두 부품이 실제 `REV-504` 조합이라는 점은 라벨·BOM·실물 체결로 확인해야 한다.

| 신호 | Molex 5극 핀 (`5055650501` 후보) | 슬립링 선색 | M12 핀 |
| --- | ---: | --- | ---: |
| Ethernet TX+ | 1 | YEL | 4 |
| Ethernet TX− | 2 | ORN | 3 |
| Ethernet RX+ | 3 | BRN | 2 |
| Ethernet RX− | 4 | BLK | 1 |
| 지그 NC | 5 | 문서상 배정 없음 | — |

최종 지그 네트는 `PAIR_TX_* = TX`, `PAIR_RX_* = RX`로 정의한다.

| 지그 네트 | Molex측 J1 | M12측 J1 |
| --- | --- | --- |
| `PAIR_TX_P` / TX+ | pin 1 | pin 4 |
| `PAIR_TX_N` / TX− | pin 2 | pin 3 |
| `PAIR_RX_P` / RX+ | pin 3 | pin 2 |
| `PAIR_RX_N` / RX− | pin 4 | pin 1 |

M12 5–8번은 빈 핀이 아니다. 같은 슬라이드에서 5번은 GPS RS232_RX, 6번은 GPS 1PPS, 7번은 24VDC, 8번은 24VDC GND로 지정된다. 이 측정 지그에서는 네 핀 모두 **NC**로 두며 GND, shield 또는 종단에 연결하지 않는다. 특히 DUT에 전원이 연결된 상태에서 VNA 지그를 체결하지 않는다.

## 커넥터 판단

| 위치 | 부품 번호 | 판단 |
| --- | --- | --- |
| REV-504 Ethernet 케이블 하우징 | Molex `5055650501` 후보 | 슬라이드 15의 4세대 표에서 확인한 MPN을 2세대에 교차 적용한 추론; 실물 확인 필요 |
| Molex측 지그 PCB | Molex `5055680571` | 제조사가 `505565` series mate로 지정한 5극 PCB header; 실제 REV-504 체결·키·pin 1 확인 전 DNP |
| 슬립링 M12측 | Finecables `MB12MBAFF08ST-0` 후보 | catalog에 존재하는 8핀 A-coded male이지만 실제 DUT의 정확한 MPN은 미확인 |
| M12측 지그 PCB | Finecables `MB12FBAFF08ST-3` | catalog상 front-fastened 8핀 A-coded female 후보; suffix, 패널 구조, pin view와 구매 가능성 확인 전 DNP |

기존 4극 `5055680471`은 문서 연결과 맞지 않아 KiCad에서 제거했다. `5055680571`은 제조사 도면 기반 로컬 풋프린트다. `MB12FBAFF08ST-3`은 제조사의 female 8P 권장 PCB 배열(Ø5.5 원주, 중앙 pin 8, key축 기준 pin 1/2 ±33°)로 바로잡아 배치·배선했다. 도면상 pad geometry를 반영했어도 실제 체결, PCB면/패널 방향과 1:1 출력 검증은 남아 있으므로 둘 다 계속 DNP다.

## SRS1202-12CZ 근거와 한계

`Docs/05. 회전구동장치_슬립링(SRS1202-12CZ).pdf`의 SRS1202 Series 자료는 다음을 명시한다.

- 6/12/18회로, 회로당 2 A, 220 VDC/240 VAC
- precious-metal 접점, noise 50 mΩ max @ 100 rpm
- 절연저항 1000 MΩ @ 250 VDC, 내전압 시험 누설전류 0.1 mA 미만 @ 250 VAC
- CW/CCW 연속 회전, 정격 100 rpm, −30~80 °C
- 30 AWG Teflon lead, rotor/stator 각 200 mm
- 12회로형 본체 길이 `L=21 mm`, Ø24 flange, 3×Ø3.5 THRU on Ø18 PCD

이 일반 자료에는 100 Ω, twisted pair, Ethernet 대역폭, insertion/return loss 또는 crosstalk 보증이 없다. 또한 일반 색상표의 11/12번 `Pink/Silver`와 2세대 조립도상의 `WHT-BLK/WHT-BRN`이 다르므로 `-12CZ` 실제 연결에는 슬라이드 14를 우선한다.

`Docs/로텍_슬립링_SRS1202-12CZ_검사성적서.pdf`는 2022-11-14 출하 LOT 8 EA에 대한 외관·치수·DC 검사다. 기록된 두 시료는 절연 1.2 GΩ, 접촉회로 저항 241/248 mΩ, 순간단선 양호 및 합격이다. 이는 RF/Ethernet 성능 검증이 아니며, 접촉회로 저항과 데이터시트의 동적 noise 50 mΩ 사양은 같은 측정항목으로 해석하지 않는다.

`Docs/RS422_Cable_Assembly_Spec.pptx`는 EM2 Encoder Interposer와 Control Board 사이의 별도 10핀 RS-422 케이블 문서다. 그 핀맵, 부품번호와 길이는 이 슬립링 지그의 설계 근거에서 제외한다.

## 측정 및 PCB 전제

- 대상 신호: 100BASE-TX, 100 Ω 차동 2페어
- 구성: 슬립링 양 끝에 서로 다른 balun 지그 보드 1장씩
- 각 보드: SMA 2개와 임피던스비 1:2 `ADT2-1T+` 2개
- 동일 커넥터와 짧은 100 Ω twisted pair로 REF/bypass를 별도 제작
- 측정하지 않는 한 페어의 양끝 SMA 두 곳은 외부 50 Ω로 종단
- 최종 fan-out에는 점퍼 매트릭스를 두지 않고 짧고 대칭적인 고정 배선을 사용

센터탭 조립 기준은 다음 두 상태로 제한한다.

- `CT-FLOAT` — **기본 상태**. Molex측 `RCT1/RCT2`와 M12측 `RCT1/RCT2`, 즉 양단의 네 저항을 모두 DNP로 둔다.
- `CT-GND` — 공통모드 민감도를 확인하는 별도 진단 상태. 네 저항을 모두 0 Ω로 동시에 장착한다.

양끝 또는 TX/RX 사이에 RCT 상태를 섞지 않는다. 측정하지 않고 SMA를 50 Ω로 종단한 페어도 예외가 아니다. `CT-GND`에서는 양끝 secondary center tap이 LibreVNA의 공통 coax/chassis GND에 연결되어, pair 불균형과 mode conversion으로 생긴 공통모드 전류가 chassis로 빠지는 추가 경로가 생긴다. 이 때문에 insertion/return loss 또는 crosstalk가 더 좋아 보일 수 있지만, 이는 슬립링 자체가 개선된 것이 아니라 측정 경계조건이 바뀐 결과일 수 있다. REF와 DUT는 반드시 같은 CT 상태로 비교하고 상태를 결과에 기록한다.

두 보드의 각 P/N은 `balun_eth_rj45`와 같은 shared-centerline 방식으로 생성한다. 공통 중심선에서 P/N을 각각 ±0.225 mm offset해 W=0.23 mm, center spacing=0.45 mm, edge gap=0.22 mm를 유지하고, 커넥터와 transformer 바로 앞의 짧은 fan-in/out에서만 쌍을 연다. 모든 Ethernet trace는 F.Cu이며 signal via는 네 쌍 모두 0/0이다. 선택 조립용 중앙탭 0 Ω 저항은 B.Cu에 배치해 차동 트렁크를 가로막지 않으며, `CT-FLOAT` 기본 조립에서는 비운다.

이 구성의 2-port VNA 결과는 두 balun을 거친 single-ended 전송의 비교 proxy다. 차동·공통모드 성분을 독립적으로 분리하는 mixed-mode `Sdd/Sdc/Scd/Scc` 측정은 아니므로, `CT-GND` 결과를 본래의 differential 특성으로 해석하지 않는다. 절대 mixed-mode 특성이 필요하면 검증된 4-port 측정 또는 별도의 fixture characterization/de-embedding 절차가 필요하다.

ADT2-1T+의 dot은 primary pin 3과 secondary pin 6이다. 현재 P/N 이름은 secondary pin 4/6을 각각 P/N으로 두므로 **지그 한 장만 보면 한 번의 극성 반전**이 있다. 동일한 두 지그를 back-to-back으로 쓰는 비교 측정에서는 두 번 반전되어 전달 극성이 복구되지만, 단일 지그 de-embedding이나 절대 mixed-mode 위상 부호에는 이 convention을 반드시 반영한다.

M12 J1은 pin 1–4가 transformer 쪽을 향하도록 **PCB B면 electrical-layout 후보**로 배치했다. 제조사가 말하는 `front fastened`는 패널 체결 방식이고, KiCad의 B면 배치는 PCB 실장면이므로 서로 같은 용어가 아니다. 이 배치에서는 이전의 한쪽 극성만 B.Cu/via를 쓰던 비대칭 crossover가 없고, 모든 P/N이 connector PTH barrel 뒤 F.Cu에서 별도 routing via 0/0으로 진행한다. 실제 A-key/pin-1 mating view, PCB의 어느 면이 장비 외부를 향하는지, 패널 너트 접근과 케이블 방향은 실물로 확인하기 전까지 J1 DNP 차단 항목이다.

| 보드 / pair | P 길이 | N 길이 | P–N 차이 | 0.22 mm 결합 트렁크 최소 | Signal via P/N |
| --- | ---: | ---: | ---: | ---: | ---: |
| Molex TX | 31.082091 mm | 31.082091 mm | <0.000001 mm | 20.292153 mm | 0 / 0 |
| Molex RX | 31.910806 mm | 31.910806 mm | <0.000001 mm | 21.120867 mm | 0 / 0 |
| M12 TX | 28.060990 mm | 28.060991 mm | 0.000001 mm | 18.759529 mm | 0 / 0 |
| M12 RX | 27.579764 mm | 27.579765 mm | 0.000001 mm | 18.110302 mm | 0 / 0 |

생성기는 source geometry에서 skew ≤0.01 mm, 결합 트렁크 ≥16 mm와 fan-in/out ≤11 mm를 검사하고, 저장된 KiCad track에서 다시 skew ≤0.01 mm, F.Cu-only와 P/N via 0/0을 검사한다. KiCad가 꺾임에서 산출한 최대 uncoupled는 11.1474 mm이며, DRU는 gap 0.21/0.22/0.23 mm min/opt/max, uncoupled ≤11.20 mm, skew ≤0.10 mm, signal via 0개로 제한한다. 이는 기준 보드의 uncoupled 16/16.5 mm보다 더 엄격하다.

두 KiCad 초안은 68 × 44 mm, 4층 JLCPCB `JLC04161H-7628` 기준이며 core εr은 기준 보드와 같은 4.36으로 통일했다. W=0.23/G=0.22 mm는 이 stack, 외층 1 oz, green soldermask, non-coplanar 조건의 nominal 100 Ω 발주 geometry다. 저장소에는 JLC field-solver 결과 원본이 없으므로 실제 주문 전 JLC impedance calculator와 impedance-control/coupon으로 다시 승인해야 한다. SMA는 1.6 ±0.05 mm 권장 두께의 MyAntenna `A-SMA-KE-16.5A` (`C22467617`, 50 Ω / DC–6 GHz)로 통일한다. 기존 Amphenol `132289`는 1.57 mm 두께 상한 때문에 최종 BOM에서 제외했다. 새 SMA는 JLC Standard PCBA 전용 wave-solder/high-difficulty 품목이므로 두 endpoint 작업에서 land pattern, board-edge 안착, 방향과 fixture/engineering 비고를 각각 승인해야 한다.

2026-09-01에 두 RF50 launch는 transformer의 0.55 mm flare 뒤 0.35 mm로 바뀐 다음 1.0 mm 직진하고, 2.54×2.54 mm 45° jog를 거쳐 SMA 중심선으로 곧게 진입하는 형상으로 통일했다. A/B는 정확한 22 mm 평행이동 관계이고 각 centerline 길이는 `26.762102 mm`다. 긴 직선은 각각 `y=31/53 mm`라 H3/H4 중심에서 모두 6.0 mm 떨어지며, 채워진 In1 plane void edge와 trace copper edge 사이 계산 여유는 약 `3.9745 mm`다. 이는 기존 상단 경로가 금속 M3 head/washer와 가까워지는 문제를 피하기 위한 fixture 조립 변경이다. 그래도 실제 head/washer 외경, 장착 면과 조임 공구 영역은 1:1 실물 대조 전까지 provisional이다.

## 제작 전 차단 항목

1. `REV-504` 실물에서 Molex housing MPN, 1–4 ↔ M12 4–1 continuity, pin 1과 key 방향을 확인한다.
2. 추론 후보 `5055680571`의 실제 체결성, pad numbering과 footprint를 확인한다.
3. M12 female 후보 `MB12FBAFF08ST-3`의 suffix, mating view, PCB B면 배치 시 A-key/pin-1 방향, 제조사의 front-fastened 패널 체결과 기구 간섭을 확인한다. 권장 PCB 배열은 CAD에 반영했지만 1:1 출력과 실부품 삽입으로 재확인한다.
4. 새 SMA `A-SMA-KE-16.5A`의 제조사 land pattern과 board-edge 안착, 바깥쪽 방향, JLC wave-solder fixture/engineering 비고를 두 보드에서 확인한다.
5. 실제 M3 head/washer 외경과 장착 면을 기록하고, 상면 hardware가 RF trace 또는 solder mask를 누르거나 조임 공구가 SMA/transformer와 간섭하지 않는지 확인한다.
6. 커넥터/SMA 또는 stack-up을 바꾼 뒤 ERC, DRC, schematic–PCB parity와 1:1 실물 대조를 다시 수행한다.

현재 문서 매핑 초안은 KiCad 10에서 두 회로도 ERC 0, 두 PCB DRC 0, 미연결 pad 0, schematic–PCB parity 0을 통과했다. 이는 전기적 CAD 정합성 검사 결과이며 실물 핀 방향, 체결성 또는 RF 성능을 승인한 결과는 아니다.

## 재생성과 검사

역사적인 파일명은 유지했지만 [`generate_pinmap_tbd_drafts.py`](generate_pinmap_tbd_drafts.py)는 이제 문서 매핑 `DRAFT 1` 두 프로젝트와 로컬 후보 풋프린트를 재생성한다. 각 variant를 임시 sibling directory에서 완전히 생성한 뒤 회로도/PCB/project/rule 파일을 교체하므로 중간 계산 실패가 live 회로도만 먼저 바꾸지 않는다. KiCad 번들 Python으로 `--force` 실행하면 기존 검증 보고서를 무효화하므로, 뒤이어 ERC/DRC를 다시 실행해야 한다. `--variant molex` 또는 `--variant m12`로 한 endpoint만 선택할 수 있다. 수동으로 후속 설계를 시작해 draft 표식을 제거하면 생성기는 덮어쓰기를 거부한다.

KiCad 10 Windows의 Python zone filler는 생성기 안에서 사용하지 않는다. 대신 staged board에 native `kicad-cli pcb drc --refill-zones --save-board --schematic-parity`를 강제해 두 inner GND plane의 fill을 실제 PCB 파일에 저장하고, 위반이 있으면 live 파일 교체 전에 중단한다. 제작용 Gerber export에도 반드시 `--check-zones`를 사용하고 In1/In2 Gerber에 plane polygon이 존재하는지 확인한다. 이후 회로/보드를 수동 수정하면 새 ERC/DRC 보고서를 다시 생성해야 한다.

```powershell
& 'C:\Program Files\KiCad\10.0\bin\python.exe' `
  'balun_slipring\generate_pinmap_tbd_drafts.py' --force
```

위 항목이 끝나기 전에는 BOM의 개별 전기부품 상태와 무관하게 전체 설계는 **DO NOT FABRICATE**다. 핀맵의 근거와 실측 기록은 [`PINMAP.md`](PINMAP.md), 측정 절차는 [`MEASUREMENT.md`](MEASUREMENT.md), 보드별 조달 판단은 [`balun_slipring_draft_bom.csv`](balun_slipring_draft_bom.csv), 전체 구매 수량은 [`../JLCPCB_FINAL_BOM.csv`](../JLCPCB_FINAL_BOM.csv)와 [`../JLCPCB_ORDER_GUIDE.md`](../JLCPCB_ORDER_GUIDE.md)를 따른다.

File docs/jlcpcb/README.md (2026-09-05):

# JLCPCB 주문 옵션 — 현재 공통 지그와 수동 어댑터

확인일: **2026-09-05**. 이 문서는 현재 `balun_eth_rj45`와 `adapters/` 3종의 주문 설정 기준이다. 루트의 이전 구매 가이드보다 이 문서를 우선한다. **실제 JLC 주문 화면에서 옵션을 선택하고 캡처했다.** Gerber 업로드·CAM 승인·주문·결제는 하지 않았다. 이미지의 5장은 설정 확인용 예시이며 전체 구매 수량을 확정한 것이 아니다.

**결정: FR-4 / 4층 / 1.6 mm / Nan Ya NP-155F / 외층 1 oz·내층 0.5 oz / JLC04161H-7628 / Green / ENIG / 임피던스 제어 선택.** 배선도 [공식 계산 결과](IMPEDANCE.md)에 맞춰 수정했다. 균일 구간은 차동 W **0.234 mm**, edge gap **0.216 mm**, 공통 지그 SMA 측 W **0.357 mm**다.

## 1. 보드별로 따로 입력

| 프로젝트 | Dimensions | Different Design | Delivery Format | 필요한 실사용 수량의 기준 |
| --- | --- | --- | --- | --- |
| `balun_eth_rj45` | 80 × 74 mm | 1 | Single PCB | 양단 측정에 동일 보드 2장 |
| `adapters/m12_slipring` | 66 × 40 mm | 1 | Single PCB | 실제 양단 커넥터 구성에 맞춰 결정 |
| `adapters/m12_llc` | 66 × 40 mm | 1 | Single PCB | 위와 같음 |
| `adapters/molex_slipring` | 66 × 40 mm | 1 | Single PCB | 위와 같음 |

세 어댑터를 한 ZIP에 넣고 Different Design=1로 주문하지 않는다. 각 보드별 Gerber ZIP을 별도 품목으로 올린다. PCB Qty=5는 이번 화면의 시제품 예시다. 부품 실장 수량과 bare PCB 제조 수량을 구분한다. 기존 전용 balun 보드의 총수량을 합산하지 않는다.

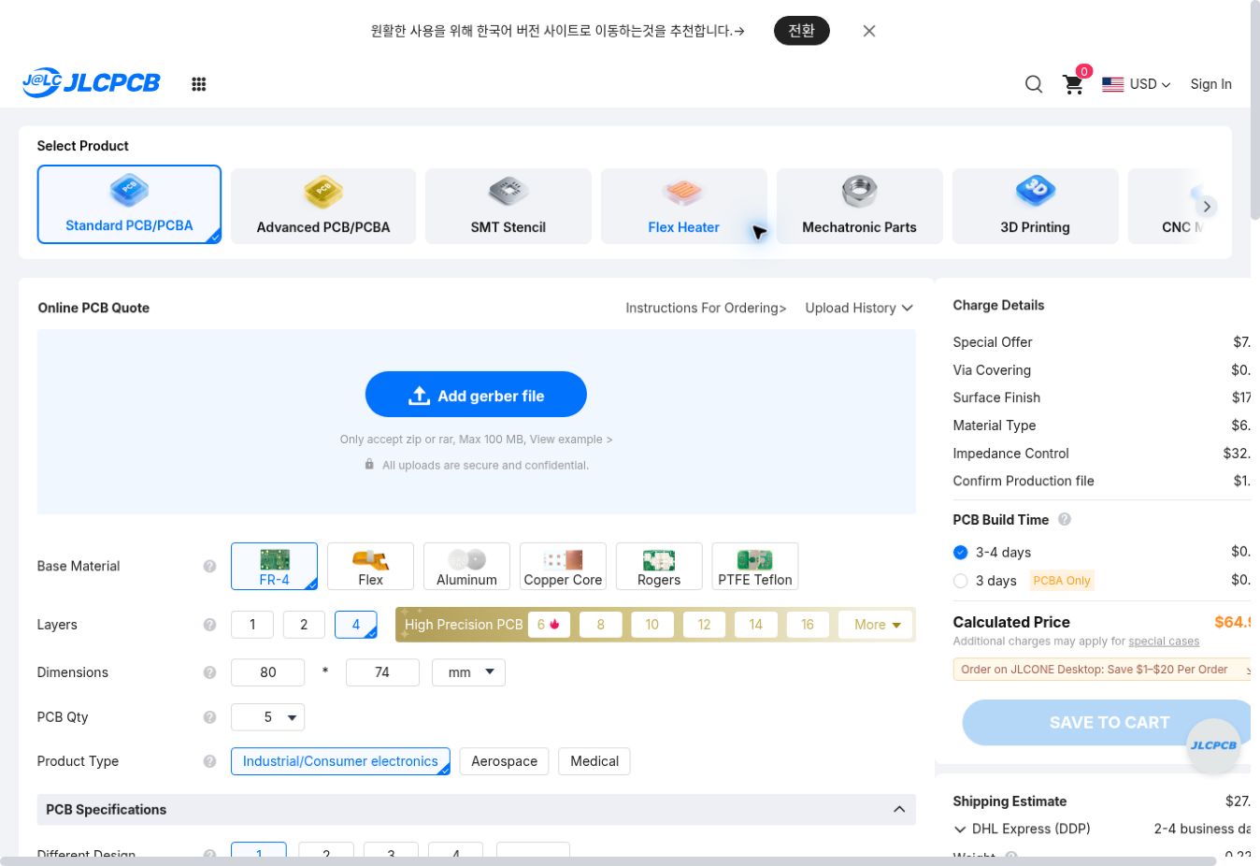
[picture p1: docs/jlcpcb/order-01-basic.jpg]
공통 지그 기본 설정


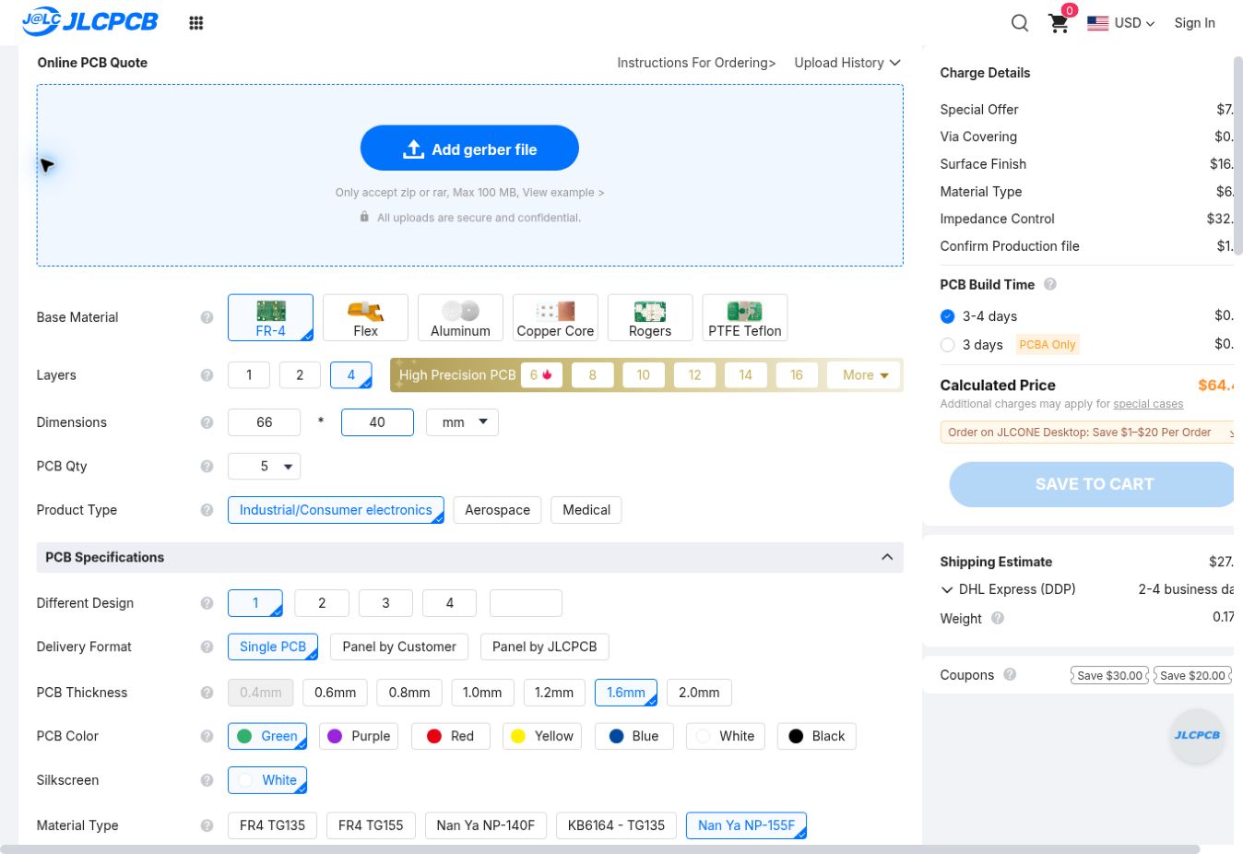
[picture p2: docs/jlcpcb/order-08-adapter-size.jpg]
어댑터는 66×40 mm


## 2. 재료와 기본 제작 옵션

| 화면 항목 | 선택 | 이유 / 다른 선택과의 차이 |
| --- | --- | --- |
| Select Product | Standard PCB/PCBA | 일반 rigid 다층 PCB 제작 |
| Base Material | FR-4 | 유리섬유/에폭시 기판. 이 측정 지그는 특수 Rogers/PTFE, 금속 코어, Flex를 전제로 설계하지 않음 |
| Layers | 4 | L1→L2, L4→L3의 가까운 기준면을 확보한 현 CAD와 일치 |
| Product Type | Industrial/Consumer electronics | 측정용 전자기기 분류. 이 선택 자체가 산업 안전 인증은 아님 |
| PCB Thickness | 1.6 mm | 선택한 적층과 커넥터 기구 기준. 총두께만 맞추고 다른 적층을 쓰면 안 됨 |
| PCB Color / Silkscreen | Green / White | 식별·검사가 쉽고 현재 제조 기준과 일치 |
| Material Type | **Nan Ya NP-155F** | 공식 계산기 안내의 4–8층 재료 가정과 맞춤. 일반 `FR4 TG155` 버튼 대신 제조사·등급을 명시 |
| Surface Finish | **ENIG** | 평탄한 패드로 작은 SMT와 반복 조립에 유리. 100Ω 달성의 필수 조건은 아니며 비용을 더 내고 조립 재현성을 택한 것 |
| Gold Thickness | 1 U″ | 이번 화면의 기본 ENIG 두께. PCB 접촉식 금도금 단자가 없는 설계라 2 U″를 요구하지 않음 |
| Outer / Inner Copper | **1 oz / 0.5 oz** | 계산기와 CAD 적층 조건. 더 두꺼운 동박은 단순 업그레이드가 아니라 선폭 재계산 대상 |

재료 메뉴에서 **TG135/TG155/TG140은 유리전이온도 등급**이고, NP-140F/NP-155F, KB6164/KB-6165, S1141/S1000H는 공급사별 재료명이다. Tg가 높다고 차동 임피던스가 더 정확해지는 것은 아니다. 같은 Tg라도 Dk·수지·적층 조건이 동일하다고 볼 수 없으므로 이번에는 계산과 같은 NP-155F를 지정한다. OSP는 유기 보호막, HASL은 납땜 합금 표면처리이며 유연/무연 공정이 나뉜다. ENIG는 무전해 니켈/침금이다. 비용 때문에 finish를 바꾸려면 조립성·제조 조건을 재검토한다.

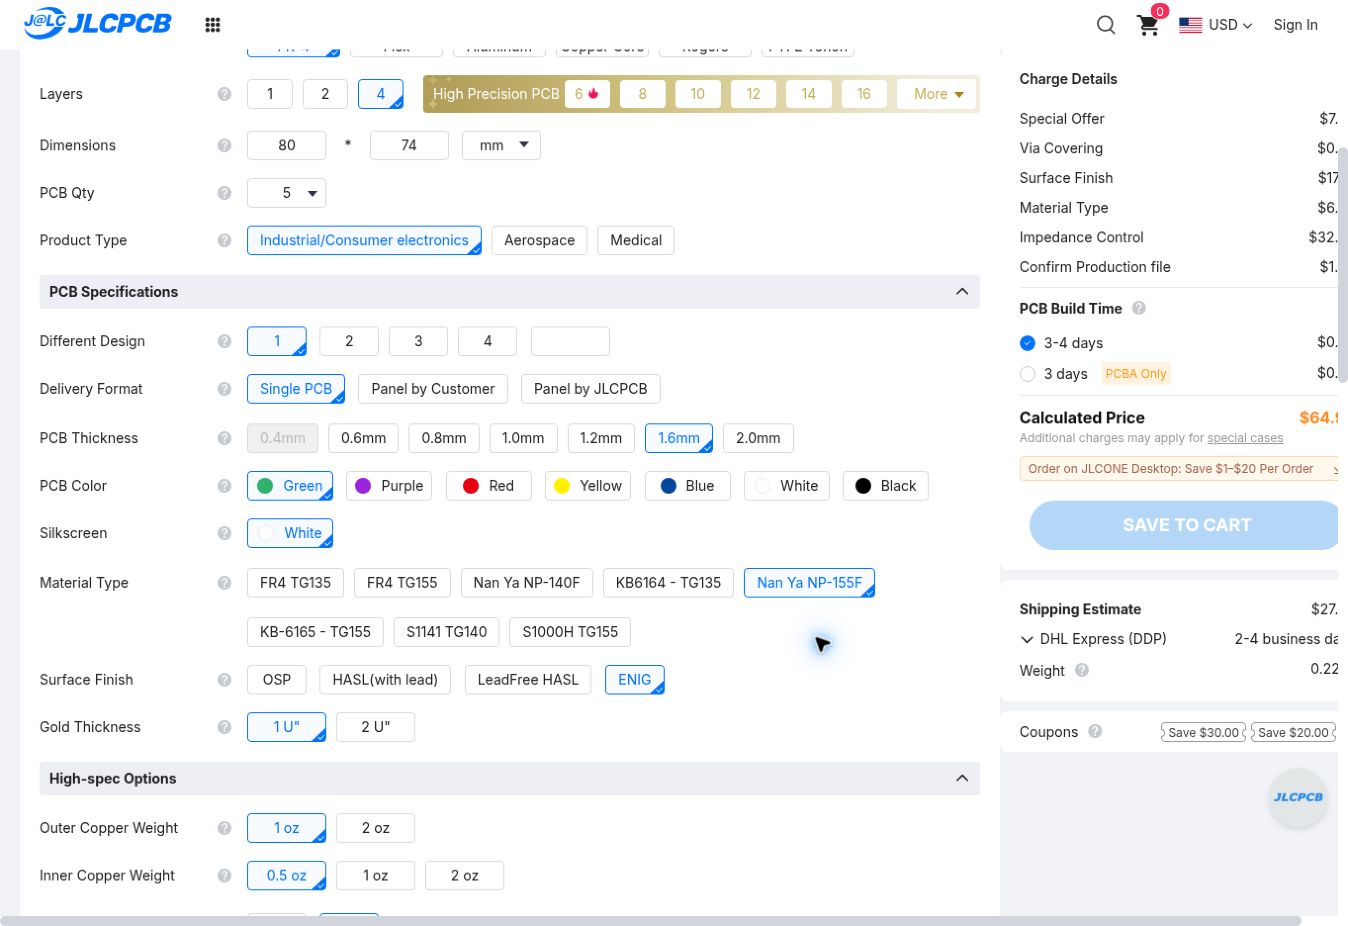
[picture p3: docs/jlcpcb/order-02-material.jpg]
두께·재료·표면처리·동박


## 3. 적층과 임피던스 — 반드시 함께 선택

| 항목 | 선택 | 이유 |
| --- | --- | --- |
| Specify Stackup | **Yes** | 두께만 같고 reference plane 간격이 다른 적층으로 자동 배정되는 것을 방지 |
| Layer Stackup | **JLC04161H-7628** | 현재 계산 및 CAD와 동일. `7628A/B` 등 suffix가 다른 것은 대체값이 아님 |
| Impedance Control | **±10% (±5Ω if value≤50Ω)** | 지정 적층과 별개의 유료 옵션. 100Ω는 ±10Ω, 50Ω는 ±5Ω 목표 제조 공차 |
| Confirm Production file | **Yes** | 제조사가 준비한 적층·선폭·mask·drill을 생산 전에 검토 |

과거의 “적층과 메모만 지정” 안내로는 부족하다. 현재 주문 화면에는 별도 **Impedance Control** 버튼과 비용이 실제로 표시된다. 아래 비고로 대상 선로와 기준면을 명확히 하고, coupon/측정 성적서 제공 여부는 제조 검토에서 확인한다. Flying Probe나 일반 Electrical Test Report는 임피던스 coupon 결과의 대체물이 아니다.

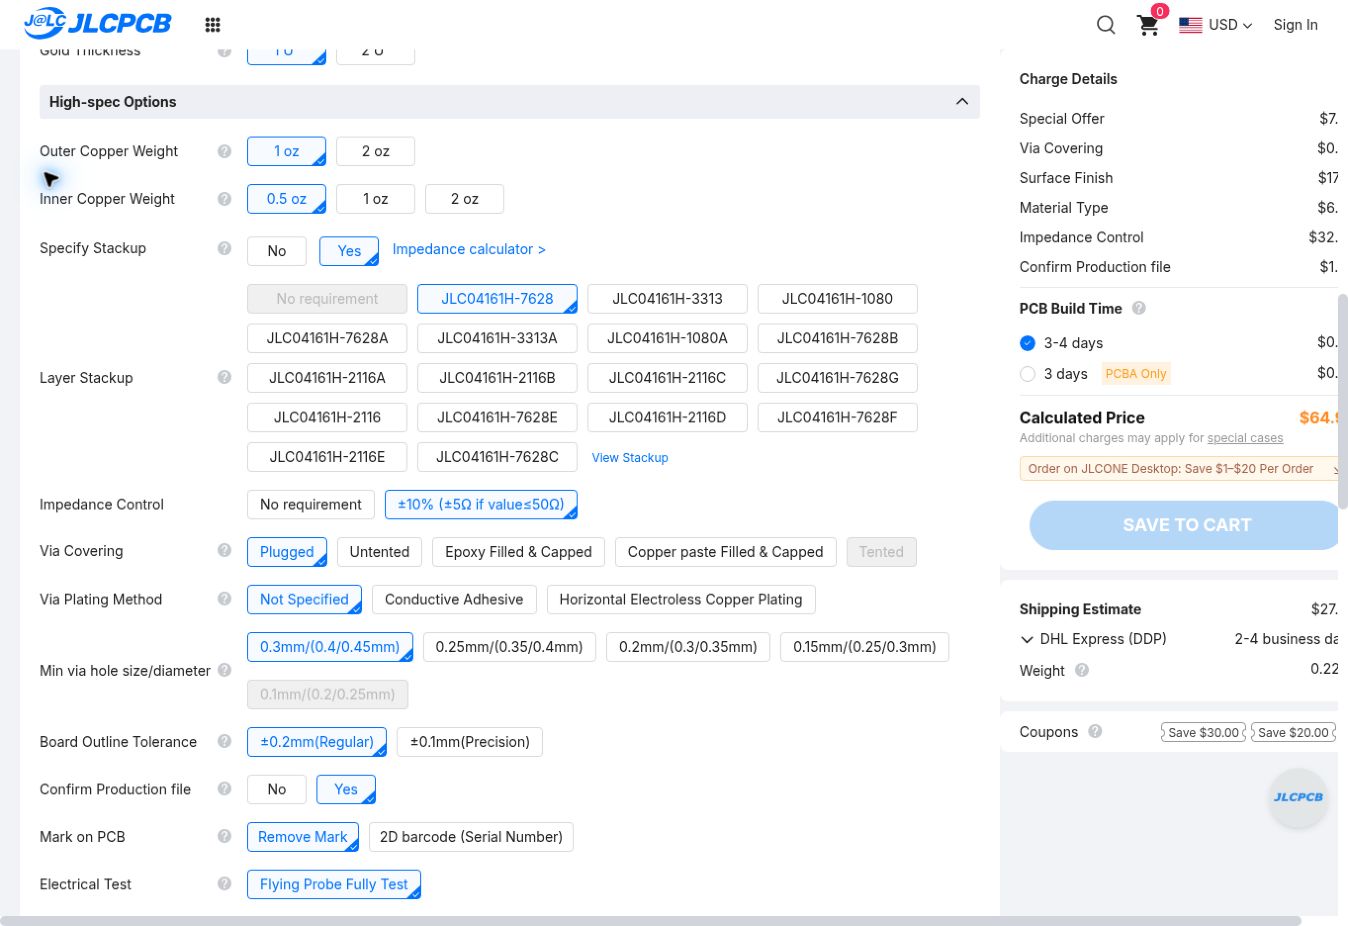
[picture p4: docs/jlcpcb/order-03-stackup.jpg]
적층 지정과 별도 임피던스 제어


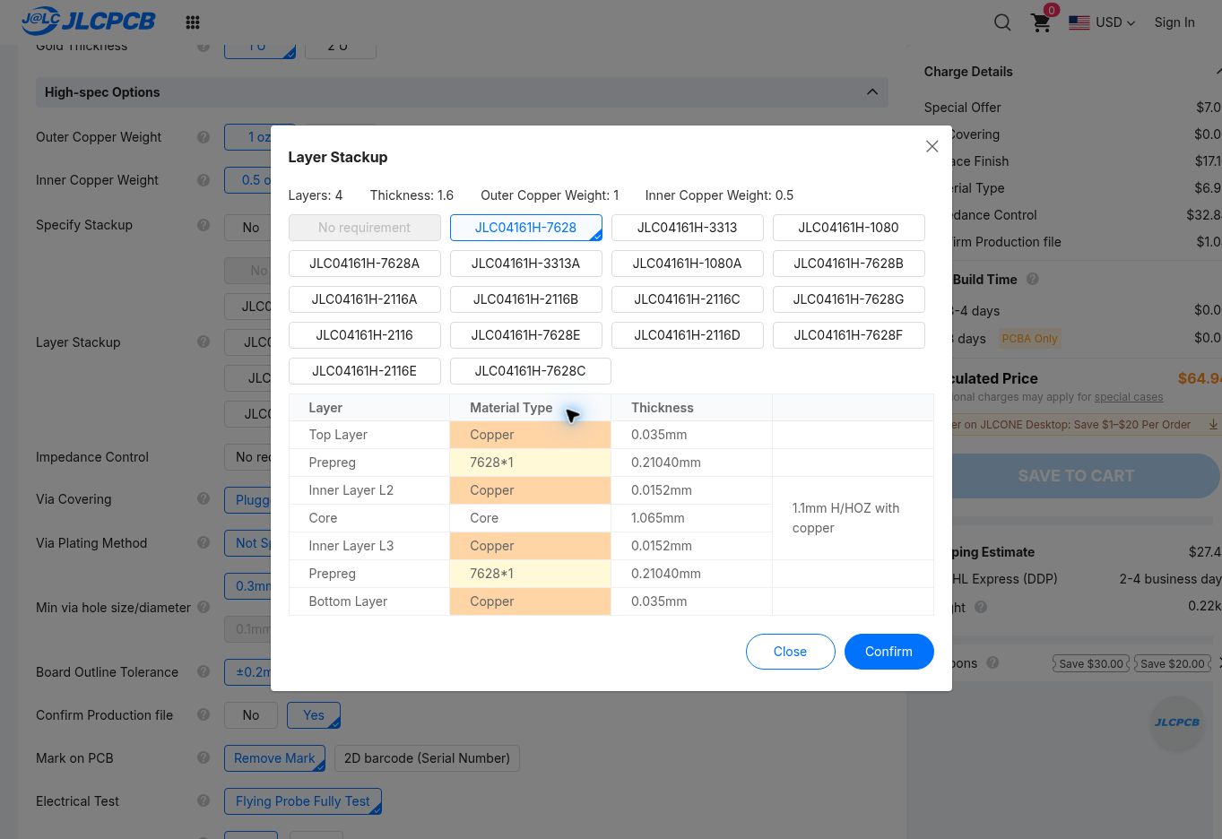
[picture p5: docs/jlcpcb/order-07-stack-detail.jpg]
실제 선택한 적층 상세


## 4. 비아, 외형, 검사

| 항목 | 선택 | 이유 / 적용 범위 |
| --- | --- | --- |
| Via Covering | **Plugged, 아래 예외 조건 포함** | 이번 4층 화면에서는 Tented 비활성. 가능한 0.30 mm 비아를 잉크로 막는 기본 선택. 모든 비아가 완전히 막힌다는 보증은 아님 |
| Via Plating Method | Not Specified | 이 설계는 별도 지정 도금 공정을 요구하지 않음 |
| Min via hole size/diameter | 0.3 mm/(0.4/0.45 mm) | 실제 CAD 비아는 **드릴 0.30 / 패드 0.60 mm**. 메뉴는 공정 등급이며 실제 패드를 0.45 mm로 줄이라는 뜻이 아님 |
| Board Outline Tolerance | ±0.2 mm (Regular) | 일반 외형 기준. SMA edge 안착과 부품 간섭은 별도로 확인 |
| Mark on PCB | Remove Mark | 제조 식별 인쇄가 핀맵/보드 식별을 방해하지 않도록 선택 |
| Electrical Test | Flying Probe Fully Test | bare PCB의 단락/단선 검사. RF·커넥터 접촉 신뢰성 판정은 아님 |
| Gold Fingers | No | SMA edge connector가 있다고 PCB gold finger가 되는 것은 아님 |
| Castellated Holes | No | 반홀 없음 |
| Press-Fit Hole | No | 현재 커넥터는 납땜용. TP snap-fit 보유력은 별도 부품·홀 공차 검토 |
| Edge Plating / Blind Slots | No / No | 설계에 해당 가공 없음 |
| UL Marking / Backdrill | No / No | UL 표시 요구 및 backdrill 정의 없음 |
| Humidity Indicator Card | No | 이번 bare PCB 시제품에서 별도 요청하지 않음 |

**Plugged 예외:** [JLC 안내](https://jlcpcb.com/help/article/pcb-via-covering)는 pad 근접 비아 등의 잉크 충진 제한을 명시한다. CAD의 동박 가장자리 간격을 계산하니 공통 지그에서 아래 네 곳이 0.35 mm보다 가깝다. 어댑터 3종에는 같은 검사 기준의 근접 후보가 없었다. 이 검사는 mask opening을 포함한 제조사 CAM 판정의 대체가 아니다.

| 공통 지그 비아 중심 X/Y (KiCad mm) | 근접 패드 | 동박 간격 |
| --- | --- | --- |
| 57.5 / 84.2 | RCT4.1 | 0.20 mm |
| 61.0 / 83.0 | RCT4.2 | 0.10 mm |
| 61.0 / 65.0 | RCT3.2 | 0.10 mm |
| 61.0 / 29.0 | RCT1.2 | 0.10 mm |

이 네 곳은 **잉크 충진 제외 후보로 명시하고**, 제조 파일에서 가능한 mask 피복과 납땜 브리지 위험을 확인한다. 잉크 충진이 되지 않는다고 곧바로 고가의 epoxy/copper-filled 옵션을 살 필요는 없다. 다만 JLC가 선택적 제외를 지원하지 않으면 공통 보드의 via covering을 재협의해야 한다. 커넥터 PTH·TP 홀·장착홀을 막지 않도록 비아 드릴 0.30 mm만 지정한다. 현 설정은 이 CAM 확인 조건을 포함한 주문 기준이다.

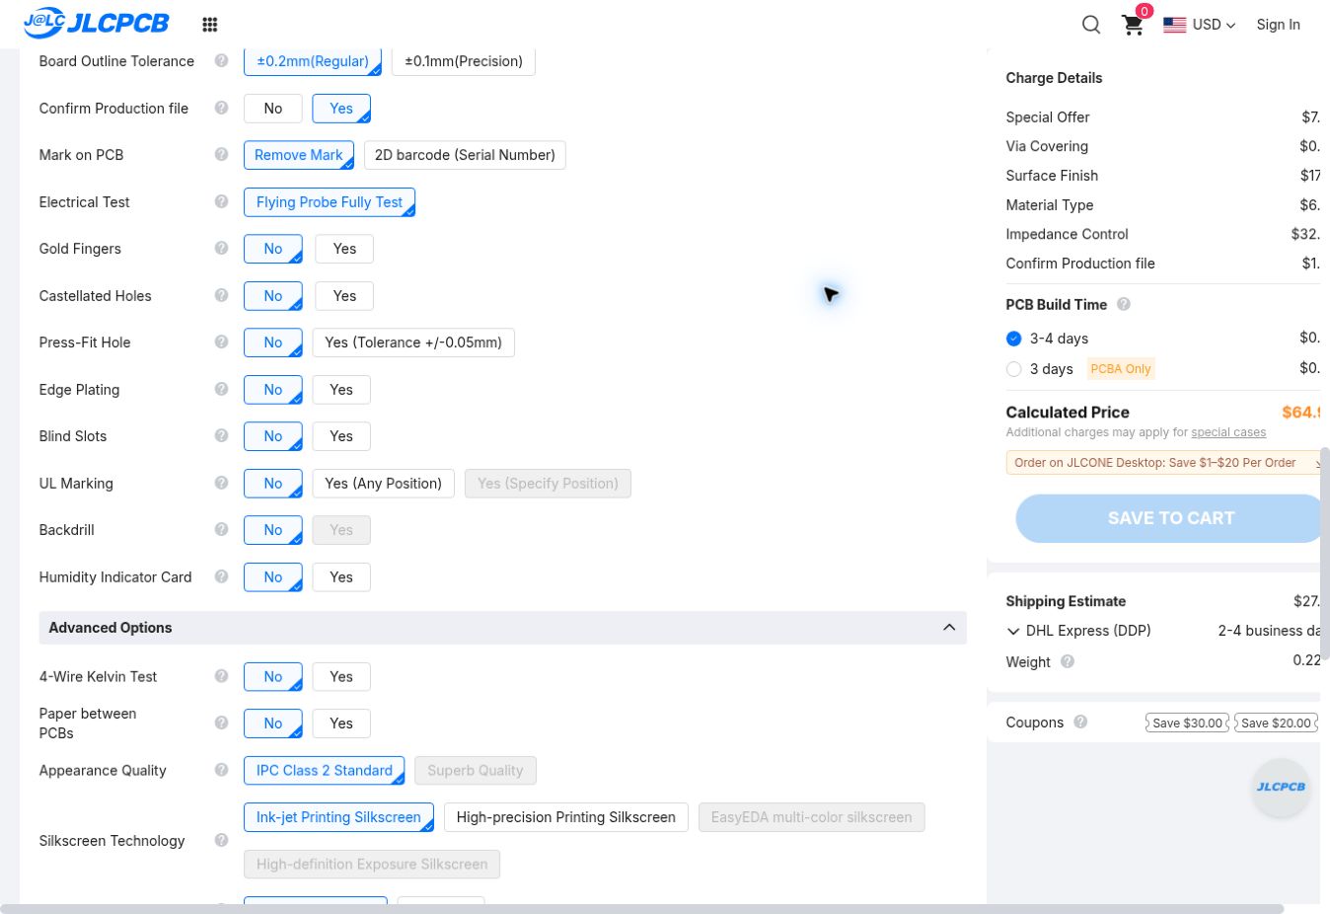
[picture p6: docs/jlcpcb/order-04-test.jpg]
전기 검사와 특수 가공


## 5. Advanced Options, 조립, 납기

| 항목 | 선택 | 이유 |
| --- | --- | --- |
| 4-Wire Kelvin Test | No | bare PCB 도통 검사로 시작. DUT 커넥터의 접촉저항 시험은 별도이며 이 옵션으로 대신하지 않음 |
| Paper between PCBs | No | 이번 시제품의 별도 포장 요구 없음 |
| Appearance Quality | IPC Class 2 Standard | 기본 외관 품질. 시스템 산업 적합 인증 의미 없음 |
| Silkscreen Technology | Ink-jet Printing Silkscreen | 기본 문자 인쇄로 충분; PCB 핀 번호는 CAM에서 판독 확인 |
| Package Box | With JLCPCB logo | 무지 포장에 추가 요구 없음 |
| Inspection Report | No | 선택 목록은 Final/Electrical/ROHS 보고서이며 전용 impedance report 버튼은 없었음. 임피던스 성적서는 비고로 별도 요청 |
| PCB Assembly | **OFF** | bare PCB를 받아 사내 조립하는 기준 |
| Stencil | **OFF** | 인두/수동 paste 작업 기준의 기본안. Molex를 stencil+reflow로 조립하기로 하면 해당 보드만 별도 주문 |
| PCB Build Time | 기본 3–4 days | 긴급 제조 요구 없음. 주문일과 CAM 승인 시점에 재확인 |
| 배송 | 실제 수령지·납기·세금 기준으로 선택 | 화면 자동 견적을 확정 배송비로 사용하지 않음 |

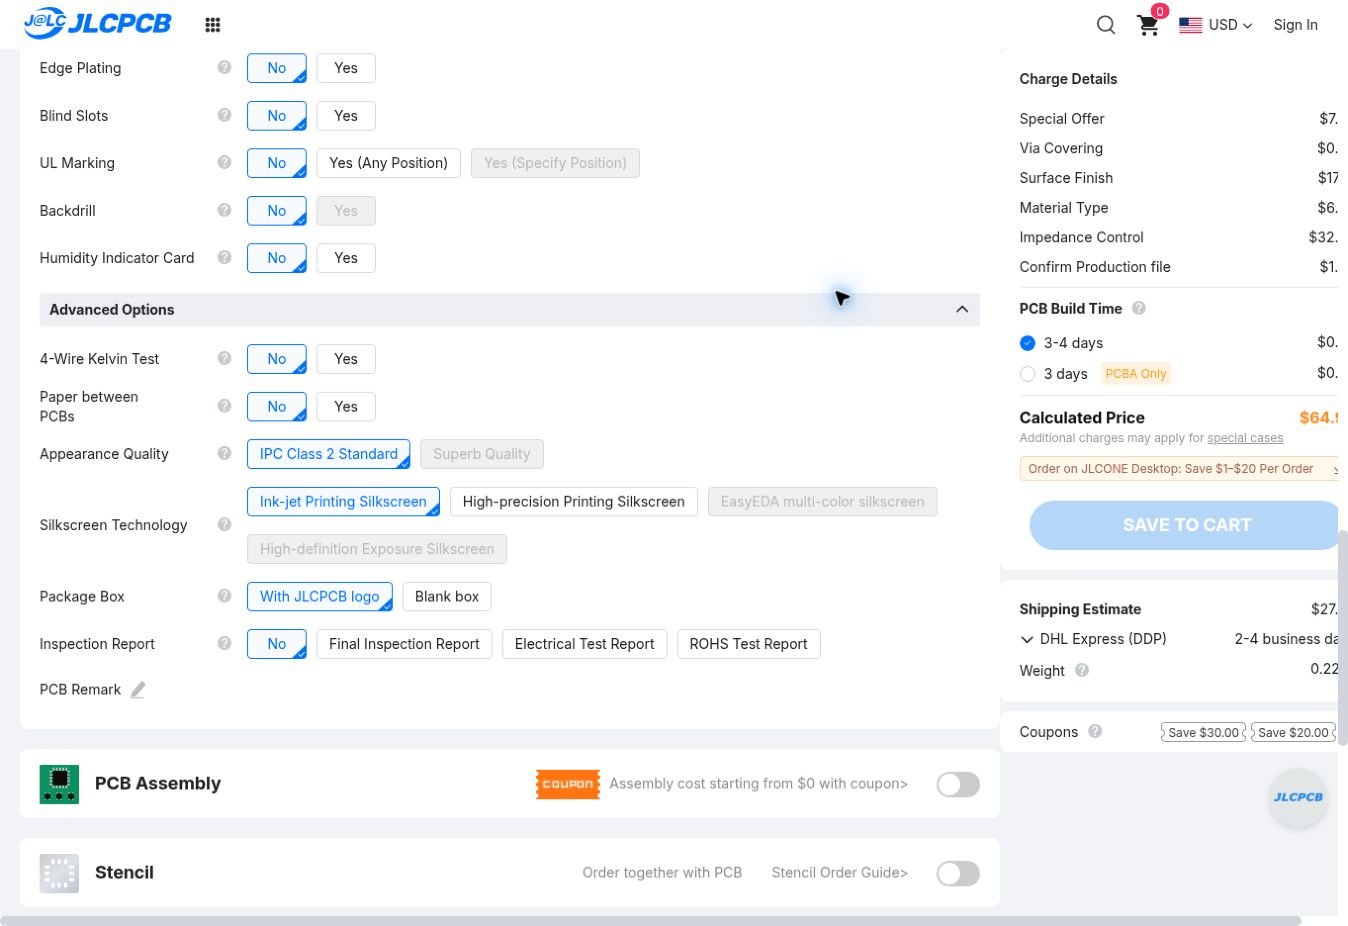
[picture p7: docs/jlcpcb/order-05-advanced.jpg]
추가 옵션과 조립 OFF


2026-09-05 공통 보드 80×74 mm/5장 수동 입력 화면은 PCB **$64.94**를 표시했다(기본 $7.00, ENIG $17.10, 재료 $6.96, 임피던스 $32.84, 제조 파일 확인 $1.04). **업로드 전 참고값**이며 최종 구매 견적이 아니다. 배송 자동 추정 $27.45도 실제 주소로 확인하지 않았다. 특히 이번 설정에서 비용이 큰 것은 임피던스 제어와 ENIG다. 촬영 해상도로 오른쪽 가격 일부가 잘려 있어 [당시 화면 텍스트](order-state.txt)도 함께 저장했다.

## 6. PCB Remark에 넣을 내용

공통 지그용(현재 CAD와 함께 제출):

```text
4-layer rigid FR-4, Nan Ya NP-155F, 1.6 mm nominal.
Fixed stackup: JLC04161H-7628. Outer copper 1 oz, inner 0.5 oz.
Green solder mask, ENIG 1 microinch.
Controlled impedance: 50 ohm single-ended on L1 referenced to L2,
trace width 0.357 mm; 100 ohm differential on L1/L4 referenced to
L2/L3 respectively, width 0.234 mm, edge gap 0.216 mm.
Non-coplanar outer microstrip with solder mask. Apply to uniform
trunks only; connector/transformer fanout and 0.15 mm RJ45 escapes
are not uniform controlled lines.
Please confirm target tolerance, coupon test and impedance report.
Do not change material, stackup, reference planes or geometry
without sending the proposed values for review.
Plug eligible 0.30 mm drill vias only. Do not plug component PTH,
test-point holes or mounting holes. Four pad-near via exceptions
(KiCad X/Y mm): (57.5,84.2), (61,83), (61,65), (61,29).
Please confirm feasible mask coverage and ink-plug exclusions in CAM.
Please provide production files for confirmation before production.
SMA connector PCB thickness requirement: 1.60 +/-0.05 mm;
please confirm achievable finished thickness separately.
```

어댑터용은 50Ω 항목, 네 근접 비아 좌표, SMA 두께 요구를 빼고 **100Ω 항목과 나머지 공통 조건**을 유지한다. **Molex는 후속 배선 개선으로 0.15 mm 구간이 없으므로 그 문구도 제외**하고 connector fanout 예외만 남긴다. 실제 비고를 제출할 때 보드 이름과 revision/hash도 함께 명시한다.

## 7. 업로드 전과 생산 승인 시 확인

1. 현재 수정된 KiCad에서 zone refill 후 보드별 Gerber/PTH/NPTH drill을 새로 내보낸다. `export_jlc_release.ps1`는 새 어댑터 3종을 처리하지 않는다. 예전 HOLD ZIP을 재사용하지 않는다.
2. 업로드 후 자동 인식 외형/4층을 표와 대조하고, material·stackup·impedance 버튼이 유지되는지 재확인한다.
3. 생산 파일의 동박 선폭/간격, L2/L3 plane, 드릴 및 mask를 확인한다. 일반 비아와 부품 구멍을 구분한다.
4. 공통 SMA가 요구하는 두께 **1.60±0.05 mm**는 JLC 적층 화면의 완성 두께 **1.59±10%**로 자동 보장되지 않는다. nominal은 맞지만 공차는 다르므로 제조사 또는 실제 부품 끼움으로 해결해야 한다.
5. M12 실제 mating·패널/브래킷과 Molex 짝 커넥터를 확인한다. 이 문서는 표준 O/S/L/T PCB나 패널 설계를 추가하지 않는다.
6. CAM 변경이 있으면 CAD·규칙·계산·DRC를 함께 갱신한다. 입고 후 continuity, 재체결, 보정 검증을 거쳐 측정에 사용한다.

## 공식 확인 출처와 증거

- [실제 주문 화면](https://cart.jlcpcb.com/quote), 공통 주문 설정 6장·어댑터 1장 및 계산 화면을 이 폴더에 저장. 파일 번호 06은 사용하지 않음.
- [JLC 공식 적층](https://jlcpcb.com/impedance)
- [공식 계산기](https://jlcpcb.com/pcb-impedance-calculator) / [계산기 입력 가정 안내](https://jlcpcb.com/help/article/user-guide-to-the-jlcpcb-impedance-calculator)
- [표면처리 안내](https://jlcpcb.com/help/article/jlcpcb-surface-finish)
- [비아 처리 안내](https://jlcpcb.com/help/article/pcb-via-covering)
- [계산 결과 및 CAD 대조](IMPEDANCE.md) / [CAD geometry audit](geometry-audit.json)

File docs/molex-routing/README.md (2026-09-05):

# Molex 어댑터 후속 배선 개선

배선 비교 기준: `acf822565702fcede400a967594e16c81a13b017`. 통합 기준은 M12와 공통 검사 규칙을 갱신한 `dd8b6fb0e8e581035004fc2e971fd26357f73b94`이며, 그 커밋에서 Molex 배선 자체는 바뀌지 않았다. 대상은 **`adapters/molex_slipring` 한 보드**다. 사용자가 정리한 신호 비아 0개 / F.Cu 배선 / TP 제거를 유지하면서, RJ45 탈출부의 좁은 배선과 P/N 길이 차이를 함께 줄였다.

**결과: 신호 전 구간 W 0.234 mm, 균일 결합 구간 edge gap 0.216 mm, A skew 0.792 mm / B skew 0.987 mm.** 기존 부품 위치·풋프린트·핀맵·4층 적층·실드 비아 8개를 유지했다. 커넥터 팬아웃은 폭이 같아도 간격이 벌어지므로 구간 전체를 100Ω으로 인증한 것은 아니다.

## 1. 길이 권고와 배선 구조 중 무엇을 우선했나

[TI Ethernet PHY 배치 지침](https://www.ti.com/lit/pdf/snla387)은 100M/10M MDI 배선의 길이 차이를 50 mil(1.27 mm) 이내로 권고하며, 비아/분기 최소화와 차동 임피던스 및 기준면 관리도 함께 요구한다. **1.27 mm는 이 수동 VNA 어댑터의 독립적인 합격선이 아니다.** 1.26과 1.28 mm 사이에서 성능이 갑자기 달라지는 경계로 사용하지 않는다.

이번 목적에서는 다음을 함께 관리했다.

1. 핀맵·제조 clearance·연속 기준면을 지킨다.
2. 균일 폭과 페어 간격을 확보하고, 좁거나 크게 벌어진 탈출 구간을 줄인다.
3. 불필요한 신호 비아/기준면 전환과 큰 길이 보정 우회로를 피한다.
4. 그 범위 안에서 P/N 길이 차이를 줄인다. 이번에는 **둘 다 1 mm 미만**을 얻었다.

이는 모든 주파수에서 성립하는 절대 우선순위가 아니다. 큰 길이 오차도 mode conversion을 만들 수 있고, 선폭/기준면이 달라지면 같은 물리 길이도 같은 전기적 지연이 되지 않는다. 기존 1.39/1.75 mm를 맞추려고 신호 비아나 큰 루프를 되돌리는 대신, RJ45 탈출 방향과 B 페어의 높이를 조정했다. 이번 수치는 native PCB 중심선 길이이며 커넥터 내부 핀·접점의 지연은 포함하지 않는다.

## 2. 전후 비교

| 항목 | 변경 전 | 변경 후 |
| --- | ---: | ---: |
| A P / N 길이 | 30.738 / 29.349 mm | 31.247 / 30.455 mm |
| A 길이 차이 | 1.388 mm | **0.792 mm** |
| B P / N 길이 | 31.798 / 30.046 mm | 30.410 / 29.424 mm |
| B 길이 차이 | 1.752 mm | **0.987 mm** |
| A P / N의 0.15 mm 구간 | 5.297 / 3.953 mm | **0 / 0 mm** |
| B P / N의 0.15 mm 구간 | 4.501 / 2.974 mm | **0 / 0 mm** |
| 긴 평행 결합 구간 A / B | 22.950 / 18.664 mm | **24.400 / 25.180 mm** |
| 신호 비아 / 신호층 | 0 / F.Cu | 0 / F.Cu |
| 실드 비아 / 기준면 | 8 / L2·L3 SHIELD | 8 / L2·L3 SHIELD |
| 두 페어의 긴 직선 구간 동박 간격 | 3.391 mm | **1.716 mm** |
| 서로 다른 페어의 배선끼리 최소 동박 간격¹ | 0.870 mm | **0.786 mm** |

¹ 마지막 행은 connector pad를 제외한 trace-to-trace 값이다. 부품 패드와의 제조 clearance는 native DRC로 따로 확인했다. 좁은 구간 길이와 P/N 길이는 패드 내부 중심선도 포함한다.

**절충도 있다.** A의 두 선은 기존보다 각각 약 0.51 / 1.11 mm 길어졌다. B는 양쪽 모두 짧아졌지만 A와 가까워졌다. 첫 후보는 B를 더 위로 옮겨 긴 구간의 페어 간격이 1.281 mm였고, 최종안에서는 길이 차이 1 mm 미만을 유지하면서 1.716 mm로 더 띄웠다. 이 비교는 배선 형상에 근거한 설계 판단이며 NEXT/FEXT 개선을 실측했다는 뜻은 아니다.

변경 전:

변경 전

변경 후:

변경 후

## 3. 실제 수정 내용

- A의 RJ45 접근부를 조금 위로 정리하고, P/N이 같은 0.234 mm 폭으로 합류하도록 했다. N의 짧은 수직 접근은 큰 serpentine 없이 길이 차이를 줄이는 데 사용했다.
- B의 긴 구간을 Y=19.000 / 19.450 mm로 옮겼다. RJ45 pin 3/6과 Molex pin 3/4 사이의 불필요한 상하 이동을 줄이고 두 선의 폭을 유지했다.
- Molex 보드의 `RJ45 pin escape` 폭 예외를 삭제했다. 이제 RJ45 안쪽도 일반 0.233–0.235 mm DRC 폭 규칙을 적용한다. M12 보드의 0.15 mm 탈출부 예외는 유지한다.
- `generate_adapters.py`, native PCB, `design.json`의 경로와 길이를 함께 갱신했다.
- `verify_adapters.py --board molex_slipring`으로 해당 보드만 검증할 수 있게 했다. 선택하지 않은 보드와 기존 검사 기록은 보존하며, 실행 버전은 `last_run`과 해당 보드 항목에 기록한다.

## 4. 검증 근거

- `dd8b6fb`의 새 공통 규칙(coupled gap 최소 0.21 mm, skew 최대 2.00 mm, uncoupled 길이 최대 16.60 mm, 신호 비아 0개)을 유지했다. 2.00 mm는 프로젝트 DRC 상한이며 TI의 1.27 mm 권고와 별개다. 이번 Molex의 실제 skew는 둘 다 1 mm 미만이다.
- KiCad 10.0.6: zone refill/save 후 **DRC 0, 미연결 0, schematic parity 0, ERC 0**.
- 기존 고정 pinmap / 독립 NC 검증 통과. [native 검사 보고서와 SHA-256](../../adapters/verification.json).
- 신규 생성 폴더의 Molex PCB와 저장된 PCB를 비교해 **net·층·폭·각 선분 양 끝 좌표가 일치**함을 확인했다.
- 변경 전후 부품 위치/회전, pad 크기·드릴·좌표·net이 일치한다. [전후 수치와 검사 결과](comparison.json).
- [geometry audit](../jlcpcb/geometry-audit.json)에서 최종 선폭과 긴 결합 구간의 gap을 다시 확인했다.

```bash
# 선택한 보드의 native 검사와 그림·hash 갱신
python adapters/verify_adapters.py --board molex_slipring --kicad-cli /path/to/kicad-cli

# KiCad pcbnew Python이 필요함; 읽기 전용 geometry 검사
python docs/jlcpcb/audit_geometry.py > /tmp/geometry-audit.json

# 기존 출력 폴더를 덮어쓰지 않는 재생성
python adapters/generate_adapters.py /path/to/new-output
```

공식 JLC 단면 계산의 0.234/0.216 mm 및 적층 조건은 그대로다. 이번 작업은 새 EM 해석이나 실물 RF 시험, 커넥터 기구 승인, 제조 release를 수행한 것이 아니다. 입고 뒤 OSL/UnknownThru 보정과 독립 검증 표준으로 최종 측정 재현성을 확인한다.

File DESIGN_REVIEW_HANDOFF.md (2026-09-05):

# 설계 의도와 검토 인계 — 2026-09-05

**검토의 출발점은 이 문서다.** 현재 방향은 공통 RJ45 balun 지그와 교체형 수동 어댑터를 사용하고, 어댑터 뒤 DUT 접속면까지 Python으로 보정하는 것이다. 기존 커넥터 전용 balun 보드와 과거 구매 문서가 함께 남아 있으므로, 파일이 존재한다는 이유만으로 모두 현재 제작 대상이라고 해석하지 않는다.

현재 성숙도는 **Python 합성 검증 + 배선된 어댑터 CAD 검증**이다. 공식 JLC 계산기 결과는 후속 패치로 반영했으나 실물 RF 정확도, 커넥터 호환·패널 기구, 생산 CAM/coupon은 미검증이며, O/S/L/T 표준의 전용 PCB도 아직 없다.

## Molex 탈출 배선 후속 개선

사용자의 `acf8225` 수정(신호 비아 제거/F.Cu 통합/TP 제거)을 유지하고, RJ45 쪽 0.15 mm 배선을 전부 0.234 mm로 바꾸는 경로로 정리했다. A/B skew는 **0.792/0.987 mm**, 긴 결합 구간은 **24.40/25.18 mm**다. A 선로는 조금 길어지고 B는 A에 더 가까워지는 절충이 있어, [전후 수치·이유·검증](docs/molex-routing/README.md)을 함께 검토한다. 1.27 mm를 유일한 합격 기준으로 삼거나 큰 루프/신호 비아를 되살리지 않았다. 변경은 Molex 보드와 관련 생성·검증·문서에 한정한다.

## 2026-09-05 후속 패치: 공식 계산기와 실제 주문 조건

이번 추가 요청은 “JLC 적층 기준 100Ω 여부를 검사·확정하고, 주문 옵션 전체와 이유를 실제 화면으로 남기기”다. [계산 증거](docs/jlcpcb/IMPEDANCE.md)와 [주문 가이드](docs/jlcpcb/README.md)가 이 패치의 기준이다.

- 공식 JLC 역산 결과를 반영해 네 활성 PCB의 차동 폭/간격을 **0.234/0.216 mm**, 공통 SMA 측 폭을 **0.357 mm**로 바꿨다. CAD·규칙·생성 스크립트를 함께 수정했다.
- M12 슬립링 B+ fanout 지점 하나를 0.05 mm 이동해 폭 증가로 드러난 clearance 문제를 해결했다. 중심선 길이 skew 약 0.002 mm를 허용했다.
- 네 보드 DRC/미연결/parity, 어댑터 3종 ERC/pinmap/NC 검사와 geometry audit를 통과했다. 이 변경은 문서만의 패치가 아니다.
- 실제 quote에서 NP-155F, 적층 지정, **별도 임피던스 제어**, ENIG와 제조 파일 확인을 선택해 기록했다. 가까운 비아의 Plugged 예외 및 SMA 완성 두께 공차는 CAM 확인 조건으로 남겼다.
- 측정 알고리즘·표준 PCB·패널·부품 선정은 이번 변경 대상이 아니다. 아래의 기존 설계 의도는 유지한다. 제조 release나 구매 집행을 완료했다고 해석하지 않는다.

## 1. 목적과 사용자 요구

목적은 일반 케이블과 전용 핀맵의 100BASE-TX 케이블·커넥터·슬립링 조립체가 실제 산업 환경에 투입될 후보인지 **정적 전송 품질부터 평가**하는 것이다. 대상은 100 Ω 차동 두 pair의 100BASE-TX이며, 단일 pair Ethernet이나 모든 M12 Ethernet 규격을 포괄하는 설계는 아니다.

| 요구 | 설계에 반영한 내용 |
| --- | --- |
| LibreVNA와 balun 기반으로 측정 | 2-port VNA와 공통 SMA–ADT2-1T+–RJ45 PCB 사용 |
| 정상 RJ45 및 특이한 커넥터 조립체를 같은 장비로 측정 | RJ45 접속을 공통으로 하고 커넥터별 수동 어댑터 교체 |
| 길이가 있는 M12 몸체·손배선의 영향을 가능한 한 보정 | 최종 기준면을 어댑터 뒤 DUT 접속면에 설정 |
| 자작 thru의 완전한 S-parameter를 먼저 측정해야 하는 순환 문제 회피 | reciprocal thru와 대략적인 위상/극성을 사용하는 UnknownThru/SOLR |
| 결과를 반복 처리 | 표준 7개로 보정계수 저장, 이후 DUT 파일에 재사용 |
| JLCPCB 제작, 가능한 곳은 손납땜 | 4층 어댑터, M12/RJ45 THT 중심; 작은 Molex SMT는 reflow 선택지 |
| 산업 사용 가능성의 1차 판단 | DC/IL/RL/반복성/필요 시 crosstalk를 평가하고 PHY·동적·환경 시험으로 연결 |

이 요구와 아래의 구현 선택을 구분한다. **4층 구성, 특정 커넥터 MPN, 선폭/간격, 길이 보정 형상, shield 처리, 표준의 단순 모델은 검토·수정 가능한 설계안**이다. 사용자가 그 수치나 RF 성능을 확정했다는 뜻이 아니다.

## 2. 패치 범위와 이전 설계와의 차이

구현 패치는 [3b11656](https://github.com/ckh7488/balun_test/commit/3b11656c7db1514880bdfb173876c14c57d90c0c)이며, [직전 c9ee74f와의 비교](https://github.com/ckh7488/balun_test/compare/c9ee74f103a5f79e9ecf2f28fc48504b0bb64348...3b11656c7db1514880bdfb173876c14c57d90c0c)로 코드/CAD 변경을 볼 수 있다. 이 인계 문서를 추가하는 후속 패치는 문서 정합성 정리이며 회로·PCB·분석 알고리즘 변경을 포함하지 않는다.

| 항목 | 이전 방향 | 현재 방향 / 실제 변경 |
| --- | --- | --- |
| 지그 구성 | 커넥터마다 balun을 포함한 전용 PCB | 공통 RJ45 Rev B 유지 + 수동 어댑터 PCB 3종 추가 |
| 기준면 | SMA에서 보정한 fixture 포함 응답과 REF 비교 | SMA full SOLT 후 adapter-end UnknownThru 보정 |
| 자작 T | 이상적인 thru로 취급하면 모델 오차 발생 | 전체 S를 알려진 값으로 입력하지 않고 reciprocal 조건 사용 |
| O/S/L | SMA 보정 키트 중심 | SMA 표준과 별도로 DUT 접속면의 pair 간 표준 정의 |
| 데이터 처리 | SMA 기준 비교 계획 | Python 보정 저장/재사용, 100 Ω 결과와 provenance 출력 |
| 공통 RJ45 CAD | Rev B | 기존 회로/동박 유지, 검토와 현재 절차 설명 갱신 |
| 전용 balun CAD | `balun_slipring/`, `balun_llc16/` | 이력 자산으로 보존; 새 어댑터 CAD와 별개 |
| 구매·제조 산출물 | 여러 날짜의 수량·BOM·export 계획 | 최신 전체 발주 수량/BOM/Gerber 패키지는 아직 재작성하지 않음 |

**새 어댑터를 추가했다는 것과 발주 가능한 완성 세트를 만들었다는 것은 다른 상태다.** 보정 표준, 패널/브래킷, 최신 전체 수량표와 어댑터 제조 export는 남아 있다. 과거 주문의 집행·취소 여부도 이 패치에서 확인하거나 변경하지 않았다.

## 3. 어느 문서를 기준으로 읽을 것인가

| 범위 | 현재 기준 | 과거 자료의 사용 범위 |
| --- | --- | --- |
| 목적·설계 선택·남은 검토 | 이 문서, [루트 README](README.md) | 날짜가 붙은 이전 리뷰는 당시 상태 |
| 측정·기준면·표준 제작 개념 | [VNA_TEST_PLAN](VNA_TEST_PLAN.md) | 전용 지그의 `MEASUREMENT.md`는 이전 구성 설명 |
| 파일 형식·계산 동작 | [analysis/README](analysis/README.md), `analysis/m12_cal.py`, tests | 문서와 코드가 다르면 검토 finding으로 기록 |
| 공통 balun 보드 | [balun_eth_rj45/README](balun_eth_rj45/README.md), 같은 폴더의 Rev B CAD | [FAB_NOTES](balun_eth_rj45/JLCPCB_FAB_NOTES.md)는 해당 보드의 nominal 제작값 |
| 새 어댑터 | [adapters/README](adapters/README.md), 각 native KiCad 파일 | 기존 전용 balun 보드의 크기·실장면·BOM을 복사하지 않음 |
| 새 어댑터 제작 조건 | [adapters/JLCPCB_BUILD](adapters/JLCPCB_BUILD.md) | 루트 구매 문서는 이번 구성의 수량표가 아님 |
| 커넥터 핀맵 근거 | [PUBLIC_SOURCE_PROVENANCE](adapters/PUBLIC_SOURCE_PROVENANCE.md), [FOOTPRINT_SOURCES](adapters/FOOTPRINT_SOURCES.md) | 기존 공개 PINMAP/spec는 근거로 유지; 실물 확인은 별도 |
| 이전 설계/구매/export | [이력 자료 목록](docs/legacy/README.md) | 원문을 보존하며 현재 구성에 대한 자동 발주 지시로 사용하지 않음 |

각 문서의 역할을 구분하기 위한 표다. 기존 검사 결과나 CAD와 설명의 모순을 이 표만으로 덮지 말고, 실제 파일과 근거를 대조한다.

## 4. 측정 경계와 데이터 흐름

양쪽 fixture는 `coax 끝 → 공통 balun PCB → 짧고 고정된 shielded RJ45 patch → 수동 어댑터`다. 그 뒤가 DUT 접속면이다. 일반 RJ45 DUT는 어댑터 없이 공통 PCB의 RJ45 접속면에서 같은 절차를 수행한다. 양끝의 어댑터 종류가 달라도 된다.

**무엇을 DUT로 부를지 먼저 기록한다.** 목표가 케이블 전체이면 두 기준면 사이의 케이블 조립체를 측정한다. 특정 M12 체결부 자체의 성능을 보고 싶다면 그 체결부가 기준면 사이에 포함되도록 시험편을 구성해야 한다. 보정에 흡수된 어댑터 쪽 커넥터의 손실을 다시 DUT 커넥터 단독 손실이라고 부를 수 없다. 빈 암 Open과 플러그 S/L의 서로 다른 offset도 이 경계 정의와 연결된다.

| 단계 | 입력/행동 | 결과와 의미 |
| --- | --- | --- |
| 1 | LibreVNA 두 coax 끝에서 알려진 SMA 표준으로 full 2-port 50 Ω SOLT | 이후 취득 전체에 이 보정을 켜 둠 |
| 2 | 고정 fixture에서 p1 O/S/L, p2 O/S/L, 자작 T 취득 | **3 + 3 + 1 = 7개** SMA 기준 복소 Touchstone |
| 3 | `calibrate session.json --out cal.npz` | 표준 모델과 7개 파일로 반복 사용 가능한 계수 저장 |
| 4 | 같은 SMA 보정과 fixture에서 DUT 취득 | DUT 1개라면 총 취득 파일은 **3 + 3 + 1 + 1 = 8개** |
| 5 | `apply cal.npz dut.s2p --out …` | DUT 접속면 기준 100 Ω effective balanced `.s2p`, CSV, PNG, JSON |

LibreVNA GUI는 SMA 기준으로 남는다. Python의 보정 결과와 계수 파일은 저장되지만 LibreVNA에 두 번째 보정으로 자동 업로드하지 않는다. DUT는 계수 추정에 사용하지 않는다. 다른 DUT에도 계수를 재사용할 수 있으나 pair/포트 할당, adapter, patch/coax 상태, CT/shield/종단 상태 또는 첫 SMA 보정이 바뀌면 해당 구성의 7개 표준을 다시 취득한다.

## 5. 보정 구현에서 반드시 검토할 가정

### O/S/L과 T

Open은 빈 어댑터로 만들 수 있고, Short와 100 Ω Load는 mating 커넥터의 **pair 두 핀 사이**에 구성한다. 짧은 S/L 배선도 R/L/C와 전기적 offset을 가진다. 보정 표준의 자체 S-parameter를 무시하는 것이 아니라, **간단한 물리 모델로 근사하고 그 근사가 용도에 충분한지 검증**하는 접근이다. 표준의 전체 S를 다른 VNA로 반드시 먼저 측정해야 한다는 요구는 없다.

현재 모델은 Open의 shunt C, Short의 series R/L, Load의 series R/L와 shunt C, 종단 앞 lossless offset line을 지원한다. 초기 ideal O/S/100 Ω L 설정은 실물 검증 결과가 아니다. 보정에 사용한 표준을 다시 이상적인 값으로 만드는 것만으로는 정확도가 입증되지 않는다. 독립 저항/선로, 반복 체결, R/L/C/offset 민감도 비교가 필요하다.

UnknownThru는 상호성 `S21 = S12`와 충분한 전달을 전제로 한다. 알고리즘의 180° 떨어진 두 전달 해를 선택하려면 실제 P/N 극성과 대략적인 편도 지연이 필요하다. 예상 위상 오차를 대역 전체에서 90°보다 충분히 작게 유지하는 짧은 T가 출발점이다. **T의 정확한 손실·반사 전체를 알고 있어야 하는 일반 SOLT와 구분한다.**

### 임피던스와 error box

- 입력 파일은 SMA 보정된 50 Ω 데이터다. Port 2 표준은 S22를 사용한다. `.s1p`의 실제 취득 포트나 SMA 보정 활성 여부는 파일만으로 확정할 수 없다.
- scikit-rf 계산에서 measured/ideal의 numerical reference를 50 Ω으로 일치시킨다. 이 단계의 실제 100 Ω Load 모델은 `Γ = (100−50)/(100+50) = 1/3`이다.
- 보정 후 DUT를 `Network.renormalize(100)`으로 변환한다. 원본 Touchstone의 `R 50`을 `R 100`으로 바꾸는 방식은 아니다.
- 첫 full 2-port SMA SOLT가 switching/source/load match를 보정했다는 전제에서, 두 번째 단계는 고정 fixture 두 error box와 **zero switch terms**를 사용한다. 첫 보정의 잔차까지 없어지는 것은 아니다. LibreVNA raw 데이터에 곧바로 이 가정을 적용하지 않는다.
- 별도 취득한 양쪽 O/S/L을 diagonal reflective two-port로 합치는 구현은 표준 측정 사이의 추가 coupling을 무시한다. fixture 사이 직접 누설, 다른 pair 및 common mode와의 강한 결합은 모델의 적용성 문제다.
- 모델화 가능한 안정된 mismatch/loss/delay는 보정할 수 있어도 손실로 낮아진 SNR, 형상 변화, mode conversion이나 누설이 자동 복구되지는 않는다. 결과는 full mixed-mode 측정이 아니다.

수학과 적용성은 [scikit-rf UnknownThru](https://scikit-rf.readthedocs.io/en/latest/api/calibration/generated/skrf.calibration.calibration.UnknownThru.html), [검증 버전 1.8.0 소스](https://github.com/scikit-rf/scikit-rf/blob/v1.8.0/skrf/calibration/calibration.py), [LibreVNA calibration 구현](https://github.com/jankae/LibreVNA/blob/master/Software/PC_Application/LibreVNA-GUI/Calibration/calibration.cpp)과 대조한다. 코드의 수치적 zero guard는 실측 정확도나 불확도 보증 범위가 아니다.

## 6. PCB 설계 선택과 검토 지점

| 선택 | 목적 | 남은 검토 |
| --- | --- | --- |
| 기존 공통 RJ45 Rev B 재사용 | balun 설계를 공유하고 커넥터별 변경 비용 감소 | 실제 balun 대역·손실·balance·fixture coupling |
| RJ45 jack + 공장제 patch | 손제작 plug보다 연결/고정 방식 반복 가능 | 추가 접점·patch 손실과 재체결 변화; 표준/DUT 취득 시 고정 |
| 수동 어댑터 3종, 고정 핀맵 | 움직이는 untwist를 PCB 형상으로 고정, 설정 착오 감소 | PCB용 M12와 보유 커넥터 호환; 범용 M12 핀맵으로 오해 금지 |
| 66 × 40 mm, 4층, M12 슬립링·Molex F.Cu 통합, M12 LLC A/B 외층 분리 | 반복 가능한 배선과 각 신호층의 인접 reference plane | 더 작은 보드/짧은 fanout의 장점과 조립 공간 비교 |
| L2/L3 SHIELD, M12에만 TP1 body/패널 접속점 | M12 shield 경계 설정 가능; Molex는 DUT-side bond 없음 | common balun GND plane과 동일 조건이 아님; floating/bonded 조건과 접점 모델 |
| W 0.234 / gap 0.216 mm trunk | 공식 JLC 역산 결과를 반영한 100Ω 목표 치수 | 생산 CAM/coupon; escape/fanout은 목표 보장 범위 밖 |
| M12 슬립링·Molex는 짧고 결합된 배선 우선 | 큰 loop·layer change·signal via 감소 | 커넥터 내부 길이·실제 전기적 대칭까지 보장하지 않음; PCB skew M12 약 0.94/0.83 mm, Molex 약 0.79/0.99 mm |
| M12 THT + 패널 지지 | 손납땜 접근성과 체결 하중 분리 | 부품 높이, PG9 panel, nut 접근, standoff, hole 공차 |
| Molex 1.25 mm SMT | 기존 공개 케이블 후보와 연결 | 실제 mating과 pin 1, 납땜 접근성; reflow 권장 선택지 |

**fanout은 우선 검토 항목이다.** Molex와 M12 슬립링은 큰 길이보정 절선과 B-pair layer change를 없애고 두 pair를 F.Cu의 긴 결합 구간으로 수정했다. M12 LLC의 pair A에는 여전히 “track 길이 동일”을 얻는 대신 pair 간격과 loop가 커질 수 있는 절선이 남아 있다. 기존 CAD를 방어하기보다 uncoupled 길이·loop·plane에 대한 대칭을 함께 비교한다. 현재 DRC와 길이 표만으로 mode conversion이나 100 Ω을 입증하지 않는다.

기본 CT-FLOAT 및 M12의 선택적 한쪽 shield bond는 초기 시험 조건이다. Molex는 DUT-side shield bond를 두지 않는다. 새 어댑터 내층, patch shield, M12 body/패널을 포함한 실제 경계를 명시해야 한다. “SHIELD라는 net 이름이 있으므로 적절히 접지된다”거나 “기준면 보정이므로 shield 상태는 무관하다”는 해석은 부정확하다.

## 7. 완료한 검증과 아직 없는 증거

아래는 구현 당시와 후속 임피던스 패치의 검증 범위다. 공식 계산기와 CAD 검사를 수행했으며 실물 RF 검증은 추가하지 않았다.

| 영역 | 증거 | 입증하지 않는 것 |
| --- | --- | --- |
| Python | `tests/test_m12_cal.py` **7 cases 통과**, scikit-rf 1.8.0 | 실측 LibreVNA/표준 정확도 |
| 합성 회복 | 비대칭·손실·부정합 fixture, 50↔100 Ω 변환, nonideal OSL, unknown reciprocal T, 극성 ±, 저장 계수 재사용 | 실제 mode conversion·coupling이 two-error-box로 충분한지 |
| 입력/출력 | p2 S22 추출, 주파수/reference 불일치 거부, 원본 보존, 출력 형식 | 잘못 기록된 하드웨어 상태의 자동 탐지 |
| 기존 공통 지그 | [fixture_drc.json](adapters/fixture_drc.json): DRC/미연결/parity 0 | 회로 변경이나 실물 성능 승인 |
| 어댑터 3종 | [verification.json](adapters/verification.json): native DRC/ERC/parity 0, 결선/NC 확인, CAD SHA-256 | 제조사 도면의 해석·실물 mating·최종 임피던스 |
| 육안 CAD 검토 | 각 어댑터 layout/plane SVG와 native 회로도 | EM 해석 또는 제조 샘플 검증 |

DRC 0은 저장된 검사 설정에서의 결과다. 각 `drc.json`의 `ignored_checks`도 함께 검토한다. CAD 텍스트의 SHA-256은 Git에 저장되는 LF 줄바꿈으로 정규화해 계산하며, 검사한 파일과의 일치 확인용이지 별도 제3자 인증이나 전자서명을 의미하지 않는다.

아직 없는 산출물은 **전용 O/S/L/T 표준 PCB, 실제 표준 모델의 측정/추정 근거, 불확도 예산, 실측 DUT 결과, JLC 생산 CAM/coupon, 패널 제작 도면, 새 구성의 통합 구매 수량표와 어댑터 제조 release**다. 기존 `export_jlc_release.ps1`는 새 `adapters/`를 export하지 않는다.

## 8. 다른 검토자에게 요청할 작업

| 우선순위 | 검토 질문 | 원하는 결과 |
| --- | --- | --- |
| 1 | 첫 full SMA SOLT 이후의 8-term/zero-switch-term 가정과 50→100 Ω 처리가 타당한가? | 코드/원문 근거, 독립 계산 또는 재현 예제; 적용 범위와 반례 |
| 1 | 실제 평가하려는 커넥터가 DUT 경계 안에 들어가는가? 빈 Open과 mating S/L의 offset을 정의할 수 있는가? | 접속면·표준의 치수/모델 정의와 필요한 변경 |
| 1 | 기존 공개 핀맵이 PCB로 정확히 전사되고 NC가 유지되는가? 실장면/성별/key/mating이 맞는가? | 제조사 도면·CAD 위치와 대조한 finding; 실물 필요 항목 구분 |
| 2 | fanout, loop, plane, CT/shield, signal/return via가 balance와 재현성에 적합한가? | 단순 길이 일치보다 유리한 구체적 배선 수정안 |
| 2 | JLC nominal geometry와 손납땜/기구 설계가 실제 제작 가능한가? | 확인된 값과 미확인 값 분리; 필요한 stack/부품/패널 수정 |
| 2 | 실물 OSL/T를 어떤 방식으로 만들고 어느 정확도까지 주장할 수 있는가? | 간단한 제작안, 독립 check와 모델 민감도 시험; 필요 시 표준 PCB 설계 |
| 3 | 초기 1–100 MHz 정적 측정으로 목적에 필요한 결함을 찾을 수 있는가? | 최소 실측 순서, 정상 REF 비교, 반복성/누설 floor, 이후 PHY 시험 연결 |

finding은 **영향도 → 파일/위치 또는 출처 → 재현/계산 근거 → 수정 제안 → 확인이 필요한 항목** 순서로 작성한다. 확인된 오류와 설계상 추정/실물 미확인을 구분한다. 현재 구현도 검토 대상이며, DRC 통과나 이 문서의 결론 자체를 타당성의 근거로 삼지 않는다.

수정안을 제시할 때는 목적과 기준면을 유지하면서 어떤 가정을 바꾸는지 설명한다. 대안으로 SMA-only 비교나 다른 calibration을 제안할 수 있으나, 그 경우 DUT 경계/남는 fixture 오차/필요한 추가 장비와 표준을 함께 설명한다. 사용자에게 자작 T의 전체 S를 이미 알고 오라고 요구하는 것으로 해결을 대신하지 않는다.

## 9. 재현과 다음 실측 단계

저장소 루트에서 Python 3.10 이상으로 실행한다. 상세 CLI 예시는 [analysis/README](analysis/README.md)를 따른다.

```bash
python -m pip install -r requirements-analysis.txt pytest
python -m pytest tests/test_m12_cal.py -q
python -m analysis.synthetic_demo measurements/review_demo
python -m analysis.m12_cal calibrate measurements/review_demo/session.json --out measurements/review_demo/cal.npz
python -m analysis.m12_cal apply measurements/review_demo/cal.npz measurements/review_demo/dut.s2p --out results/review_demo
```

출력은 예제의 `expected_dut_100ohm.s2p`와 비교한다. 도구는 기존 파일을 덮어쓰지 않으므로 재실행 때 새 출력 경로를 사용한다.

KiCad 검증은 **검토용 별도 checkout**에서 KiCad 10.0.x와 필요한 라이브러리를 사용한다. 정확한 실행 버전은 `adapters/verification.json`에 기록한다. 아래 스크립트는 zone refill/save와 보고서·SVG 갱신을 수행하므로 읽기 전용 검사가 아니다.

```bash
python adapters/verify_adapters.py --kicad-cli /path/to/kicad-cli
```

최초 실측은 조립체 continuity/각 선 저항 확인, full SMA SOLT, 한 pair의 O/S/L/T 취득, 독립 check standard, 정상 REF와 DUT, 반복 체결, 표준 모델 민감도 순서로 진행한다. 1–100 MHz를 시작 대역으로 쓰되 정확도와 판정 기준은 실제 check/floor/용도에 따라 정한다. NEXT/FEXT는 별도 포트 조합의 보정과 누설 바닥값이 필요하다.

이후의 완료 기준은 “그래프가 나온다”가 아니라 **DUT 차이가 반복성·표준 모델 변화·fixture floor보다 충분히 구분되고, 그 판단 범위를 기록할 수 있는가**다. VNA 정적 결과만으로 산업 환경의 EMC, 회전 중 순간단선, 온도/진동, PHY 오류율이나 장기 수명을 판정하지 않는다.

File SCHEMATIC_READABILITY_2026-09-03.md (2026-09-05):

# 기존 BALUN 회로도 가독성 정리

2026-09-03, 기존 세 회로도의 **표현만 정리**했다. 부품 선정, 핀맵, 조립 상태, PCB 배선 및 제조 승인 상태를 변경하는 작업이 아니다.

## 결과 파일

| 지그 | 편집 가능한 KiCad 원본 | 확인용 PDF | 용지 |
| --- | --- | --- | --- |
| RJ45 4-pair | [회로도](balun_eth_rj45/balun_eth_rj45.kicad_sch) | [PDF](../output/pdf/balun_eth_rj45_schematic.pdf) | A3 가로, 1쪽 |
| 슬립링 Molex측 | [회로도](balun_slipring/molex_end/balun_slipring_molex.kicad_sch) | [PDF](../output/pdf/balun_slipring_molex_schematic.pdf) | A4 가로, 1쪽 |
| 슬립링 M12측 | [회로도](balun_slipring/m12_end/balun_slipring_m12.kicad_sch) | [PDF](../output/pdf/balun_slipring_m12_schematic.pdf) | A4 가로, 1쪽 |

- RF 경로는 SMA -> balun -> 차동 pair 순서로 정렬했다. 같은 이름의 네트 라벨은 서로 전기적으로 연결된다.
- 커넥터의 논리 핀 번호, 슬립링 양단 핀맵, CT 미실장 조건, 차폐 옵션과 외부 종단 주의사항을 별도 영역으로 나눴다.
- 기존 `ETH100` / `RF50`의 `schematic_color` 알파값이 `0.000`이라 PDF에서 해당 선과 라벨이 투명해졌다. 각 프로젝트에서 이 두 표시값만 `1.000`으로 수정했다. 기존 RGB와 `pcb_color`, 임피던스 관련 선폭/간격, netclass 배정 및 모든 PCB 설정은 유지했다.
- symbol/pin UUID, 모든 부품 속성값, MPN, footprint, FIT/DNP, BOM/position-file 포함 여부와 정확한 네트 이름 및 핀 연결을 보존했다. 도면의 배치, 표시 글자, 주석, 날짜 및 용지 크기는 달라졌다.
- LLC 회로도와 PCB 파일은 수정하지 않았다. 슬립링 생성기는 새 배치를 사용하도록 연결하고, RF 원본의 배치에 의존하지 않도록 수정했다.

## 검증

| 지그 | 부품 / 네트 | ERC 오류·경고 | DRC / 미연결 / 회로도-PCB 불일치 |
| --- | --- | --- | --- |
| RJ45 | 17 / 22 | 0 / 0 | 0 / 0 / 0 |
| 슬립링 Molex | 7 / 12 | 0 / 0 | 0 / 0 / 0 |
| 슬립링 M12 | 7 / 15 | 0 / 0 | 0 / 0 / 0 |

KiCad 10 네이티브 XML netlist의 부품 정보와 네트/핀 목록을 변경 전후 정확히 비교했다. 실제 반영 파일도 다시 검사했다. DRC는 `--refill-zones --schematic-parity`로 실행하되 `--save-board` 없이 수행했으며, `.kicad_pcb`와 `.kicad_dru`의 SHA-256은 원본과 같다. 프로젝트 JSON은 위의 표시 색상 두 필드만 다르다.

새 RJ45 회로도를 원본으로 슬립링 두 회로도 및 LLC 회로도를 별도 검증 폴더에 재생성해 기존 연결과 부품 정보가 유지되는지 확인했다. LLC의 M12 핀맵, 전원 핀 NC, 커넥터 필수 FIT와 CT DNP 검사도 통과했다. PDF 세 장은 이미지로 렌더링해 배선·라벨 표시, 글자 겹침 및 잘림을 확인했다.

원본 백업과 검증 보고서는 [`../outputs/balun-schematic-refresh-20260903/`](../outputs/balun-schematic-refresh-20260903/)에 있다. 각 프로젝트의 `before/`가 수정 전 CAD 백업이며, `verification.json`과 `regression.json`에 검사 결과를 기록했다.

## 유지보수

KiCad 10의 Python으로 다음을 실행한다.

```powershell
& 'C:\Program Files\KiCad\10.0\bin\python.exe' 'balun\refresh_schematic_layouts.py'
& 'C:\Program Files\KiCad\10.0\bin\python.exe' 'balun\refresh_schematic_layouts.py' --apply
& 'C:\Program Files\KiCad\10.0\bin\python.exe' 'balun\verify_schematic_refresh.py'
```

첫 명령은 후보 회로도와 PDF만 생성한다. `--apply`는 검증 후 세 회로도와 해당 표시 색상만 반영한다. 변경 전 백업 또는 마지막 반영본과 현재 파일의 해시가 다르면 사용자 편집을 덮어쓰지 않고 중단한다. 마지막 명령은 실제 CAD와 재생성 결과를 검사하며 현재 PCB를 저장하거나 재생성하지 않는다. 이 날짜의 백업에 기반한 정리 도구이므로 이후 전기적 설계가 바뀌면 이전 백업으로 강제 되돌려 사용하지 않는다.

KiCad에서 기존 파일을 열어 둔 경우, 오래된 화면을 다시 저장하지 말고 프로젝트와 회로도를 다시 열어 갱신된 배치를 확인한다.

## 제조 상태는 그대로

- 슬립링 J1 후보의 기존 DNP/HOLD와 `DO NOT FABRICATE`를 유지했다. 커넥터를 빼고 주문하라는 뜻이 아니다.
- RJ45 공통 CAD의 RSH1/CSH1 DNP를 유지했다. 업체가 조립할 SHIELD-BONDED / SHIELD-FLOAT 구분은 [기존 구매 범위 문서](PCBA_PURCHASE_SCOPE_2026-09-03.md)를 따른다.
- 검사 통과는 이번 표현 변경이 전기적 연결을 바꾸지 않았다는 확인이지, RF 성능 보증이나 제조 승인 선언이 아니다.

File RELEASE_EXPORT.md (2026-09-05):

# JLCPCB release export

> **Scope update, 2026-09-05:** The active design is the common RJ45 balun fixture plus passive adapters. Start with [DESIGN_REVIEW_HANDOFF](DESIGN_REVIEW_HANDOFF.md) and [adapter build notes](adapters/JLCPCB_BUILD.md). The exporter described below **does not export the new `adapters/` designs**. Its historical quantity/assembly overrides do not define the current system order. Existing export behavior is unchanged; no new adapter manufacturing release is provided by this documentation update.

> **Latest procurement override, 2026-09-03:** The user subsequently chose bare PCB fabrication plus separately purchased components and in-house hand soldering. See [`HAND_ASSEMBLY_PURCHASE_2026-09-03.md`](HAND_ASSEMBLY_PURCHASE_2026-09-03.md). The older PCBA delivery assumptions below are historical. This changes procurement only: ten intended assembled boards, electrical FIT/DNP variants, connector/mechanical HOLDs, release checks and the exporter's lack of LLC fabrication support remain unchanged. Do not treat this decision as fabrication approval.

> **2026-09-03 purchase-scope update:** The planned delivery is now ten PCBAs: four slip-ring, four RJ45 (two SHIELD-BONDED and two SHIELD-FLOAT), and two new LLC M12 endpoints sharing the RJ45 boards. No default user soldering step is assumed. See [`PCBA_PURCHASE_SCOPE_2026-09-03.md`](PCBA_PURCHASE_SCOPE_2026-09-03.md). The current exporter still produces the common RSH1-DNP candidate, not both assembly variants. Do not use its RJ45 BOM/CPL unchanged for the SHIELD-BONDED boards. Supplier approval and validated variant-specific outputs are required; slip-ring HOLD status is unchanged. **The [LLC design](balun_llc16/README.md) now has a routed PCB DRAFT A with clean native ERC/DRC/parity, but no fabrication Gerber/BOM/CPL and is still not covered by this exporter.** Its male M12 MB12MBAFF08ST-3 footprint follows the manufacturer's male PCB layout and the cable drawing's numeric pin map. JLC sourcing/assembly, actual mating and panel support, manufacturing stack/impedance/CAM and release approval remain outstanding. Cable continuity and no-power checks belong before the first VNA connection, not as prerequisites to starting PCB design.

`export_jlc_release.ps1` creates reproducible JLCPCB fabrication outputs without saving or editing the live KiCad projects. Each project is copied to a separate temporary staging directory before KiCad refills and saves zones, runs DRC with schematic parity, and runs ERC.

## Default release-candidate export

Run from PowerShell in the repository root:

```powershell
.\export_jlc_release.ps1
```

The default output directory is `release_jlc/<timestamp>/`. The script validates all three projects, but creates fabrication files and a Gerber ZIP only for `balun_eth_rj45`.

- `balun_eth_rj45`: `RELEASE_CANDIDATE`
- `balun_slipring_molex`: `HOLD_DO_NOT_ORDER`
- `balun_slipring_m12`: `HOLD_DO_NOT_ORDER`

The two slip-ring boards remain blocked by connector, pin-map, mechanical, and final impedance-release checks. Their default output directories contain validation reports and an explicit HOLD notice, but no fabrication ZIP.

## Explicit engineering export of HOLD boards

```powershell
.\export_jlc_release.ps1 -IncludeHoldBoards
```

This creates engineering-review Gerbers for the two HOLD boards. Their ZIP filenames contain `HOLD_DO_NOT_ORDER`. This switch does not approve them for fabrication or ordering.

An alternate empty output directory and an explicit KiCad 10 CLI may be supplied:

```powershell
.\export_jlc_release.ps1 `
  -OutputDirectory 'C:\release\balun-review' `
  -KiCadCli 'C:\Program Files\KiCad\10.0\bin\kicad-cli.exe'
```

The script refuses to write into a non-empty output directory.

## Output structure

For an exported project:

```text
<project>/
  fabrication/     RS-274X Gerbers, separate PTH/NPTH Excellon, drill maps, IPC-D-356 netlist
  assembly/        DNP-excluded JLCPCB-format BOM and CPL CSV
  reports/         DRC, ERC, and drill reports
  README.txt       status and order warnings
  *-JLCPCB_GERBER.zip
```

The Gerber ZIP contains only the files in `fabrication/` and is the PCB-fabrication upload. The component position CSV is deliberately outside that ZIP. `SHA256SUMS.txt` covers all generated files and ZIPs.

## Assembly BOM/CPL

The script exports a project-specific BOM with `Comment`, `Designator`, `Footprint`, and `LCSC Part #`, and a CPL with `Designator`, `Mid X`, `Mid Y`, `Rotation`, and `Layer`. Both exclude schematic/PCB items marked DNP. The repository-wide combined BOM is not a valid per-project JLCPCB assembly BOM and must not be uploaded.

The generated files are upload-format candidates, not automatic placement approval. In particular, JLC's own KiCad guidance requires checking component translations and rotations in the placement preview.

Before paying for any PCBA order, manually verify all of the following:

1. project-specific BOM fields, LCSC numbers, FIT/DNP state, and assembly quantities;
2. the DNP-excluded position CSV side, rotation, origin, and JLC placement preview;
3. SMA and connector orientation in the JLC 2D/3D viewer;
4. current JLC stack-up selection and impedance-calculator result;
5. Gerber CAM, inner-plane fill, PTH/NPTH drills, and board outline;
6. the project status in `RELEASE_README.txt` and each project `README.txt`.

`RELEASE_CANDIDATE` means the automated CAD checks passed. It does not replace controlled-impedance approval, BOM/CPL review, mechanical validation, or an engineering decision to order.

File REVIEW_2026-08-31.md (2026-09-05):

# balun 설계 심층 검토 — 2026-08-31

## 결론

- `balun_eth_rj45` Rev B의 현재 회로 연결, 배선, 규칙과 inner GND plane은 의도한 상대 비교용 2-port VNA fixture 구조와 일치한다.
- `balun_slipring/molex_end`의 논리 핀맵과 RF core는 타당하지만 실제 REV-504 connector identity와 mating은 미확인이다.
- `balun_slipring/m12_end`에는 제조사 female 8P 배열과 다른 치명적인 pad-number topology가 있었고 수정했다. 수정된 보드는 재배선·재생성 후 CAD 검사를 통과했다.
- 세 설계 모두 현재 CAD 기준 ERC 0, DRC 0, unconnected 0, schematic–PCB parity 0이다.
- JLCPCB 2026 공식 solver로 main 50 Ω geometry는 `49.9328–49.9955 Ω`, 100 Ω differential geometry는 `100.1103–100.2795 Ω`로 재검증됐다. 생산 보증은 nominal 계산 오차가 아니라 JLC 표준 `±10%`다.
- 2-port VNA로 S11/S21/S12/S22, NEXT/FEXT 전체 비교 측정이 가능하다. SMA 쪽 50 Ω load가 balun 뒤에서 nominal 100 Ω differential load로 보이므로 100 Ω 종단기를 자작할 필요는 없다.
- 이 결과는 전기적 CAD 정합성을 뜻할 뿐이다. slip-ring 두 endpoint는 실물 connector/continuity/mechanics와 측정 limit가 미확정이므로 계속 **DO NOT FABRICATE**다.

## 확정 수정 사항

1. Finecables M12 female 8P footprint를 제조사 권장 배열로 수정했다.
   - signal ring diameter: 5.5 mm
   - pin 8: center
   - key축 기준 pin 1/2: ±33°
   - pin 1–2 gap: 66°, 나머지 gap: 49°
2. 수정된 M12 pad 위치에 맞춰 TX/RX fan-in과 coupled trunk를 다시 배선했다.
   - TX: 28.060990/28.060991 mm, coupled 18.759529 mm, F.Cu, signal via 0/0
   - RX: 27.579764/27.579765 mm, coupled 18.110302 mm, F.Cu, signal via 0/0
3. slip-ring generator를 variant별 staging/rollback 구조로 변경했다.
   - live 회로도/PCB를 쓰기 전에 전체 산출물을 임시 sibling directory에 생성
   - native KiCad DRC, parity, zone refill+save 통과 후에만 live 파일 교체
   - 실패 주입 시험에서 live 파일 hash 변화 0 확인
4. RJ45 updater의 zone-fill 손실 문제를 수정했다.
   - 기존 `--routing-only`는 fill cache를 지운 뒤 성공해 plane 없는 Gerber를 만들 수 있었음
   - 현재는 변경 후 native zone refill+save, DRC/parity와 저장된 In1/In2 fill 존재를 강제
   - backup 범위에 SCH/PCB/PRO/DRU와 전체 custom footprint library 포함
5. SMA updater를 SCH/PCB staging+rollback 방식으로 변경했다.
6. CAD BOM field를 조달 manifest와 동기화했다.
   - RCT/RSH: UNI-ROYAL `0805W8F0000T5E`, `C17477`
   - TP1/TP2: Keystone `5001`, `C238122`
7. 문서의 근거 강도를 바로잡았다.
   - slide 14는 2세대 핀/선색 매핑 근거
   - `5055650501` exact MPN은 slide 15의 별도 4세대 표에서 가져온 교차 슬라이드 추론
   - `MB12MBAFF08ST-0`도 실제 DUT MPN이 아니라 catalog에 존재하는 후보
8. `PCB B면 배치`와 제조사 용어 `front-fastened panel`을 구분하고, sample 구매 순서·M3 CAD reference·crimp validation 수량을 정리했다.

## 회귀 검증 결과

| 프로젝트 | ERC | DRC | Unconnected | Schematic parity | 저장된 inner fill |
| --- | ---: | ---: | ---: | ---: | --- |
| `balun_eth_rj45` | 0 | 0 | 0 | 0 | In1/In2 각 1 |
| `balun_slipring_molex` | 0 | 0 | 0 | 0 | In1/In2 각 1 |
| `balun_slipring_m12` | 0 | 0 | 0 | 0 | In1/In2 각 1 |

KiCad 10 native dry-run으로 세 프로젝트의 Gerber, 분리 PTH/NPTH drill과 `--exclude-dnp` position CSV를 생성했다. 모든 명령은 exit 0이었다. `--check-zones` 출력의 In1/In2 Gerber는 각 파일에 region polygon을 포함했고, 저장된 fill만 사용하는 별도 no-check 출력에서도 동일하게 plane이 존재했다.

추가한 [`export_jlc_release.ps1`](export_jlc_release.ps1)은 live CAD를 해시로 보호한 staging copy에서 zone refill, ERC/DRC/parity, Gerber, PTH/NPTH drill/map, IPC-D-356, DNP-excluded JLC BOM/CPL과 SHA256 manifest를 재생성한다. 기본 모드는 RJ45 ZIP만 내고 slip-ring은 HOLD notice만 만든다.

Position CSV의 FIT reference는 다음과 같았다.

- RJ45: `J1,J2,J3,J4,J5,T1,T2,T3,T4,TP1,TP2`
- Molex endpoint: `J2,J3,T1,T2`
- M12 endpoint: `J2,J3,T1,T2`

따라서 slip-ring J1과 RCT1/RCT2는 현재 DNP/position-excluded 상태로 유지된다.

## 현재 의도와의 적합성

적합한 용도:

- 동일 fixture/설정에서 REF bypass와 slip ring의 상대 IL/RL/phase/group-delay 비교
- 정지 각도와 회전 중 변화 비교
- 상대 NEXT/FEXT 및 CT-FLOAT 대 CT-GND 민감도 확인

현재 구조만으로 주장할 수 없는 용도:

- 정식 100BASE-TX compliance 또는 합격 판정
- fixture가 제거된 절대 slip-ring S-parameter
- 순수 mixed-mode `Sdd/Sdc/Scd/Scc` 또는 CMRR

## RF/VNA 측정 결론

- Open, Short, Load는 각각 한 개만 있어도 Port 1/2에 순차 재사용할 수 있다. 다만 두 SMA-male cable end를 잇는 female-female thru가 필요하고 LibreVNA에서 `SOLT_12`를 활성화해야 한다.
- RJ45 두 보드는 미사용 SMA가 6개이므로 동일한 SMA-male 50 Ω terminator 6개가 동시에 필요하다. Slip-ring 두 endpoint는 2개가 필요하며 같은 6개 세트를 공유한다.
- Slip-ring의 모든 logical port pair는 6개 cable configuration, RJ45의 모든 8-port pairwise proxy는 28개 configuration으로 덮인다. 각 파일에 S11/S21/S12/S22 네 complex trace를 모두 저장한다.
- NEXT/FEXT는 DUT coupling이 fixture+REF floor보다 최소 10 dB, 가능하면 20 dB 커야 정량값으로 신뢰한다. 근접하면 upper bound로 표시하고 REF dB를 단순 감산하지 않는다.
- ADT2-1T+ 두 개가 through 경로에 들어가므로 typical transformer loss만 약 `0.96 dB @100 MHz`, `1.38 dB @200 MHz` 누적될 수 있다. 1–200 MHz를 기본 characterization, 200–450 MHz를 exploratory로 분리한다.
- 2-port balun 지그로 mode conversion, TCL/LCL, common-mode S-parameter, 정식 cable certification과 짧은 회전 dropout을 직접 판정할 수 없다.

전체 연결표와 설정은 [`VNA_TEST_PLAN.md`](VNA_TEST_PLAN.md)를 따른다.

## 확인된 지그/제조 caveat

1. RJ45 J1 앞 0.15 mm neckdown은 local 141–144 Ω 구간이다. 3.04/5.07 mm로 짧아 1–200 MHz relative fixture를 폐기할 정도는 아니지만 pair 내 비대칭과 connector fan-out이 mode conversion/NEXT floor에 포함된다.
2. Edge-launch SMA pad는 routed edge에 의도적으로 닿는다. JLC Remark에 pull-back/trim 금지를 넣고 `Confirm Production File=Yes`로 CAM을 승인해야 한다.
3. SMA 권장 PCB 두께는 `1.6±0.05 mm`지만 JLC 일반 1.6 mm 공차는 `±10%`다. 첫 bare PCB와 loose SMA sample-fit 또는 tighter-thickness engineering 확인이 필요하다.
4. 현재 별도 true 2x-thru/isolation coupon이 없다. Golden REF 반복측정이 당장의 authority이며, 더 낮은 crosstalk floor가 필요하면 `fixture_qa` coupon을 별도 설계하는 것이 좋다.
5. 2026-09-01 후속 결정으로 slip-ring RF50 경로는 transformer 쪽 early-jog와 SMA 직선 진입을 A/B 및 두 endpoint에 동일 적용했다. 각 경로는 `26.762102 mm`, H3/H4 중심 이격은 모두 6.0 mm다. 일반적인 금속 M3 head/washer 여유는 크게 개선됐지만 실제 hardware 외경과 장착 면 확인은 여전히 필요하다.

ADT2-1T+는 secondary dot이 pin 6이고 현재 P/N은 pin 4/6이므로 fixture 한 장에서 극성이 한 번 반전된다. 동일 fixture 두 장의 back-to-back 전달에서는 두 번 반전되어 상쇄되지만, 단일 fixture model/de-embedding과 절대 위상 부호에는 이를 반영해야 한다.

## 제작 전 남은 차단 항목

1. 실제 REV-504에서 Molex 1–4 ↔ M12 4–1 continuity, inactive pins 5–8 isolation, key/pin-1과 실제 endpoint MPN을 기록한다.
2. `5055680571` loose sample과 실제 housing을 체결하고 1:1 footprint, key와 pin 1을 확인한다.
3. `MB12FBAFF08ST-3` sample/preorder로 corrected PCB pattern, mating face, PCB B면 배치, front-fastened panel/nut/wrench access와 cable direction을 확인한다.
4. 2026-08-31 solver 검증값은 저장했지만, 주문 시점 JLC `JLC04161H-7628` live calculator 결과와 stack revision을 다시 보관하고 자동 stack/width 변경을 승인하지 않는다.
5. Keystone `5001` 권장 hole 1.02 mm와 현재 drill 1.00 mm의 finished-hole tolerance/retention을 확인하거나 실제 sample을 삽입한다.
6. SMA/RJ45/M12/transformer의 body 3D 또는 1:1 print와 실부품으로 board edge, enclosure와 fixture interference를 확인한다.
7. `MEASUREMENT.md`의 sweep, points, IFBW, power, averaging, calibration kit와 IL/RL/NEXT/FEXT/rotation/repeatability 합격선을 확정한다.
8. 2026-08-13 재고·가격 값은 역사적 snapshot이므로 주문 직전 다시 조회한다.

## 사용자 결정이 필요한 항목

- 목표가 `상대 characterization`인지 `100BASE-TX qualification`인지
- 기본 평가 대역과 200 MHz 초과 구간을 공식 판정에 포함할지
- 별도 `fixture_qa` 2x-thru/isolation coupon을 추가 발주할지
- 실제 장비에서 PCB 어느 면이 외부를 향하고 M12 panel/nut에 접근 가능한지
- 정량 IL/RL/NEXT/FEXT, 각도 변화, dropout과 반복성 limit
- 예상 fixture 탈착 횟수와 connector를 소모품/replaceable interposer로 만들지
- 사용할 calibration kit, coax/terminator ID, torque 관리 방식

위 결정과 실물 검증이 끝나기 전에는 release Gerber/BOM/CPL을 저장소의 제작 산출물로 배포하지 않는다.

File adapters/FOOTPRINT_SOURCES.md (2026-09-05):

# 풋프린트 출처와 확인 범위

새 어댑터는 저장소의 기존 custom connector footprint를 복사해 사용한다. footprint pin 번호를 임의로 재정의하지 않았고, LLC M12만 부품 전체를 180° 회전 배치했다. schematic과 PCB가 같은 핀 번호로 연결되는지는 native parity 및 netlist 검사로 확인했다.

| 로컬 footprint | 기존 출처 | 제조사 자료 |
| --- | --- | --- |
| RJ45_Amphenol_RJE59-188-5401 | balun_eth_rj45.pretty | [Amphenol drawing](https://cdn.amphenol-cs.com/media/wysiwyg/files/drawing/rje591885x01.pdf) |
| Finecables_MB12FBAFF08ST-3 | balun_slipring/common.pretty | [Finecables PCB panel type](https://www.finecables.com/uploadfiles/2022/06/259%20M12%20A_coding%20Straight%20Connector%2C%20Panel%20Mount%2C%20PCB%20Type%2C%20Front%20fastened.pdf) |
| Finecables_MB12MBAFF08ST-3 | balun_llc16/llc16.pretty | [Finecables catalogue, 기존 설계 근거 p415](https://www.finecables.com/uploadfiles/2025/09/2025_Finecables_Industrial_Connector_Catalogue.pdf) |
| Molex_5055680571 | balun_slipring/common.pretty | [Molex product](https://www.molex.com/en-us/products/part-detail/5055680571), [drawing](https://www.molex.com/content/dam/molex/molex-dot-com/products/automated/en-us/salesdrawingpdf/505/505568/5055680571_sd.pdf) |
| Shield_SolderPoint | 이번 설계 | M12 어댑터용 Ø3.0 mm pad / Ø1.2 mm PTH, 부품 없는 solder point |

Finecables의 금속 body/cable-side mating과 component-side PCB pin view는 구분한다. 기존 footprint가 저장되어 있다는 사실만으로 사내 커넥터와의 실제 체결이 증명되지는 않는다. supplier drawing과 샘플로 exact suffix, 성별, pin 1/key, finished-hole, panel seating을 확인한다. 이 확인 전에는 커넥터의 최종 기구 승인으로 표시하지 않는다.

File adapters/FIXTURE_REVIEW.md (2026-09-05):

# 공통 RJ45 balun 지그 검토 — 2026-09-05

설계 판단: **현재 RJ45 Rev B를 공통 플랫폼 후보로 유지한다.** 새 측정 방향은 지그 이후 기준면 보정을 추가하는 변경이다. 현재 CAD 검토에서 공통 balun 회로를 즉시 교체해야 할 근거는 찾지 않았으며, 실측 대역·balance·누설 결과에 따라 재설계할 수 있다. 커넥터별 전용 balun PCB 대신 수동 어댑터 PCB를 교체한다. 전체 변경 의도와 검토 질문은 [설계 검토 인계](../DESIGN_REVIEW_HANDOFF.md)에 있다.

## 실제 CAD에서 확인한 것

KiCad 10.0.6으로 기존 `balun_eth_rj45.kicad_pcb`를 검사했다. 표준 라이브러리를 연결한 환경에서 **DRC 0, 미연결 0, 회로도 parity 0**이다. 최초 검토에서는 copper/net을 유지했고, 후속 [임피던스 패치](../docs/jlcpcb/IMPEDANCE.md)에서 폭을 수정한 뒤 같은 검사를 다시 통과했다. 회로도 net은 유지했다.

| Pair | P / N track 길이 | P / N signal via |
| --- | ---: | ---: |
| A | 44.9649 / 44.9649 mm | 0 / 0 |
| B | 32.9301 / 32.9301 mm | 1 / 1 |
| C | 32.8357 / 32.8357 mm | 0 / 0 |
| D | 43.6677 / 43.6677 mm | 0 / 0 |

- 내층 In1/In2는 실제 fill이 저장된 GND plane이다. pair 아래 기준면을 두는 구조다.
- differential track은 0.234 mm trunk와 0.15 mm RJ45 escape로 구성된다. 0.15 mm 구간을 100 Ω 전송선으로 간주하지 않는다.
- ADT2-1T+의 nominal 1:2 impedance ratio는 50 Ω SMA와 100 Ω differential의 연결 목적에 맞는다.
- dot은 primary 3 / secondary 6이며 기존 P=4, N=6이므로 지그 한 장의 명명상 극성 반전을 기억해야 한다. 자작 thru 모델은 실제 DUT 접속면 P/N 정의로 정한다.
- 미사용 SMA 6개에 연결할 외부 50 Ω load는 계속 필요하다. 이 load는 커넥터 끝 OSL의 100 Ω 표준과 별개다.

## 측정상 한계와 대응

| 한계 | 이번 방향에서의 대응 |
| --- | --- |
| 두 balun·PCB·adapter 손실/부정합 | 고정한 상태에서 adapter-end OSL + UnknownThru로 보정 |
| 수작업 fanout/untwist 변화 | PCB 어댑터와 짧은 고정 patch cable로 재현성 개선 |
| balun 대역·손실·noise | 1–100 MHz부터 검증, 100–200 MHz 확장 관찰; 깊은 notch/낮은 전달은 주의하여 해석 |
| pair 간 fixture coupling | 각 crosstalk 연결의 floor와 반복성 측정; 단순 two-error-box 보정으로 제거된다고 가정하지 않음 |
| common mode / balance | CT/shield 상태 고정; full mixed-mode 또는 산업 EMI 적합성은 별도 시험 |
| 반복 체결·온도 drift | 독립 check standard와 재체결 기록; 유의 변화 시 재보정 |
| JLC nominal geometry | 공식 계산기 반영 완료; 생산 CAM/coupon 및 실물 검증 남음 |

따라서 **PCB 어댑터 + 임피던스 제어는 권장하지만 SOLR가 모든 오차를 없애는 것은 아니다.** PCB 길이를 무조건 짧게 하는 것보다 대칭성·고정 형상·기준면·표준 모델을 함께 관리한다. 커넥터 몸체와 pad field의 mode conversion, OSL 기생성분 정확도는 실측에서 검증해야 한다.

## 이번에 만든 어댑터의 검사 범위

세 보드의 native DRC/ERC/parity, 정확한 pair 결선과 power/NC 핀 분리를 확인했다. 저장된 CAD hash와 검사 결과는 [verification.json](verification.json)에 있다. 각 보드의 inner SHIELD plane fill과 레이어/회로도 SVG를 생성했다.

DRC 0은 각 보고서의 검사 설정에서의 결과이며 `ignored_checks`도 함께 읽어야 한다. 어댑터의 넓은 fanout은 길이 일치만 확인한 것으로, loop/uncoupled 길이와 실제 전기적 대칭은 추가 검토 대상이다. 어댑터의 SHIELD plane과 기존 balun PCB의 GND plane은 접속 조건이 다르므로 body/패널/patch shield까지 포함해 검토한다.

이것은 CAD 검증이다. 아직 실제 JLC 제작품, PCB용 M12의 사내 케이블 체결, 실제 표준과 DUT 데이터는 없다. 임피던스 정밀도나 industrial-use PASS/FAIL을 이 단계에서 단정하지 않는다.

근거: [ADT2-1T+ datasheet](https://www.minicircuits.com/pdfs/ADT2-1T%2B.pdf), [JLC stack-up](https://jlcpcb.com/impedance), 저장소의 KiCad 설계와 위 검사 결과.

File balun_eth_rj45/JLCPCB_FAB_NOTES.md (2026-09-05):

# JLCPCB fabrication notes — balun_eth_rj45 Rev B

**2026-09-05 적용 범위:** 현재도 사용하는 공통 RJ45 Rev B 한 보드의 nominal 적층/geometry 참고다. 전체 시스템 수량과 조립 방식은 [설계 검토 인계](../DESIGN_REVIEW_HANDOFF.md), 새 수동 어댑터는 [adapters/JLCPCB_BUILD](../adapters/JLCPCB_BUILD.md)를 따른다. 현재 CAD의 SMA 부품은 유지했으나 기존 PCBA 공정 설명을 손납땜 금지 조건으로 해석하지 않는다.

최신 실제 화면별 선택과 이유, 비아 예외는 [주문 가이드](../docs/jlcpcb/README.md)를 우선한다. 이 문서는 공통 지그의 적층·geometry 참고다. 임의 대체 stack-up은 허용하지 않는다. 아래 Dk는 설계 당시 입력값이며 현재 주문 solver의 supplier 보증값으로 간주하지 않는다.

## 주문 선택값

| 항목 | 선택값 |
|---|---|
| Layers | 4 |
| PCB thickness | 1.6 mm |
| Outer copper | 1 oz |
| Inner copper | 0.5 oz |
| Material type | FR-4 TG155 / Nan Ya NP-155F |
| Impedance control | 별도 `±10% (±5Ω if value≤50Ω)` 옵션 선택 |
| Stack-up | `JLC04161H-7628 (Standard)` |
| Solder mask | Green |
| Surface finish | ENIG |
| Impedance coupon/test | 비고로 coupon/성적서 요청, 제공 여부 CAM 확인 |

JLC의 주문 두께 표기는 1.6 mm이고 이 stack-up의 nominal 합계는 약 1.5862 mm다. SMA는 MyAntenna `A-SMA-KE-16.5A` (`C22467617`)로 통일했으며, 제조사 권장 PCB 두께 `1.6 ±0.05 mm`에 nominal stack은 들어가지만 일반 JLC 완성 두께 ±10%가 그 공차를 보장하지는 않는다. 생산 두께 확인이 필요하다. 기존 Amphenol `132289`는 PCB 두께 상한 1.57 mm 때문에 최종 BOM에서 제외했다. `C22467617`은 JLC Standard PCBA의 wave-solder/high-difficulty 품목이므로, 주문 시 제조사 land pattern, routed edge 안착, 바깥쪽 방향과 fixture/engineering 비고를 반드시 확인한다.

## 고정 적층

| 위에서 아래 | 재료 | 두께 | Dk |
|---|---|---:|---:|
| L1 copper | Cu | 0.0350 mm | — |
| Prepreg 7628 | NP-155F | 0.2104 mm | 4.40 (설계 입력) |
| L2 copper | Cu | 0.0152 mm | — |
| Core | NP-155F | 1.0650 mm | 4.36 (설계 입력) |
| L3 copper | Cu | 0.0152 mm | — |
| Prepreg 7628 | NP-155F | 0.2104 mm | 4.40 (설계 입력) |
| L4 copper | Cu | 0.0350 mm | — |

L1은 L2, L4는 L3를 기준면으로 사용한다. L1/L4 blanket GND pour를 제거했으므로 JLC calculator에서 coplanar 구조가 아닌 일반 outer microstrip 구조를 선택한다.

## 임피던스 geometry

| Net class | 목표 | Width | Edge gap | 기준면 |
|---|---:|---:|---:|---|
| RF50 | 50 Ω single-ended | 0.357 mm | — | L2 또는 L3 |
| ETH100 | 100 Ω differential | 0.234 mm | 0.216 mm | L2 또는 L3 |

[2026-09-05 공식 계산기 결과와 화면](../docs/jlcpcb/IMPEDANCE.md)을 반영한 치수다. 제조 CAM/coupon은 아직 확인하지 않았다. KiCad rule 폭은 RF 0.356–0.358 mm(권장 0.357), differential 0.233–0.235 mm(권장 0.234)다. 결합 gap 최소 0.21 mm / 권장 0.216 mm이며 connector/transformer fanout은 균일 선로 계산 범위에서 제외한다.

RJ45 PTH pin field의 `0.15 mm` neck-down은 connector 내부의 매우 짧은 escape 구간이며 100 Ω 계산 geometry가 아니다. 이 구간을 늘리지 않는다.

## CAM/DFM 확인표

- L1/L4에 blanket copper zone이 없어야 한다.
- L2와 L3에는 끊김 없는 `/GND` zone만 있어야 한다.
- L2/L3에 signal track이 없어야 한다.
- RF track은 모두 0.357 mm여야 한다.
- 결합 differential trunk는 0.234/0.216 mm여야 한다.
- J1 signal PTH는 1.30/0.90 mm이고 annular ring은 0.20 mm다.
- via는 0.60/0.30 mm다.
- pair B만 signal via를 사용하며 P/N 각각 1개다.
- pair B signal via 주변의 GND return via 네 개는 각 signal via에서 중심 간 `1.355 mm`로 대칭 배치한다.
- unused SMA에는 PCB 부품이 아니라 측정 시 외부 50 Ω terminator를 장착한다.
- Keystone `5001` 권장 mounting hole은 1.02 mm이고 현재 KiCad standard footprint drill은 1.00 mm다. JLC finished-hole 공차와 snap-fit retention을 확인하거나 첫 샘플을 실제 삽입해 승인한다.
- 공통 RJ45 보드 한 장의 SMA 4개는 현 CAD의 MyAntenna `A-SMA-KE-16.5A` / `C22467617` 기준이다. 다른 부품을 사용하면 land pattern과 두께/안착 조건을 함께 검토한다. 과거 전체 구성의 SMA 12개 합계를 현재 신규 발주량으로 사용하지 않는다.
- `C22467617`의 패드가 board edge에 맞닿고 connector body가 보드 밖쪽을 향하는지 JLC placement/DFM 화면에서 확인한다.
- fabrication ZIP 이름에 `Rev A` 또는 `HOLD`가 있으면 발주하지 않는다.
- Gerber는 `--check-zones`로 생성하고 In1/In2 각각에 실제 `/GND` plane region polygon이 있는지 CAM에서 확인한다.

주문 업로드 후 JLC engineering이 stack-up, 선폭 또는 간격 변경을 제안하면 자동 승인하지 않는다. 변경된 수치를 JLC impedance calculator로 다시 계산한 뒤 KiCad 규칙과 배선을 함께 갱신해야 한다.

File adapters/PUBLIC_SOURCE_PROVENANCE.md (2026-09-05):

# 설계 입력의 공개 출처

이번 어댑터의 핀맵과 부품 후보는 이 작업 전부터 공개되어 있던 저장소 커밋 `c9ee74f103a5f79e9ecf2f28fc48504b0bb64348`에서 가져왔다. 별도의 사내 파일이나 PC 폴더를 읽어 새 핀맵을 추출하지 않았다.

- 슬립링 M12/Molex 핀맵: [기존 공개 PINMAP.md](https://github.com/ckh7488/balun_test/blob/c9ee74f103a5f79e9ecf2f28fc48504b0bb64348/balun_slipring/PINMAP.md)
- LLC M12/RJ45 핀맵: [기존 공개 fixture_spec.json](https://github.com/ckh7488/balun_test/blob/c9ee74f103a5f79e9ecf2f28fc48504b0bb64348/balun_llc16/fixture_spec.json)
- RJ45 공통 지그: [기존 공개 PCB/README](https://github.com/ckh7488/balun_test/tree/c9ee74f103a5f79e9ecf2f28fc48504b0bb64348/balun_eth_rj45)
- 커넥터 풋프린트의 원본은 [출처표](FOOTPRINT_SOURCES.md)에 기록했다.

이번 변경은 위 공개 설계 입력을 사용하는 어댑터 CAD, 측정 절차와 합성 검증용 소프트웨어다. 실제 회사 측정 데이터, 구매 내역, 견적, 계정 정보 또는 개인 PC 경로를 새 산출물에 포함하지 않는다. 이전 구매 문서는 수정·복제하지 않고 기존 Git 이력으로 참조한다.

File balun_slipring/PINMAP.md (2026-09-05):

# Slip-ring pin map

상태: **문서 핀맵 확인 / continuity 실측 대기 / DO NOT FABRICATE**

> **LLC 케이블과 혼용 금지:** 아래는 슬립링 전용 핀맵이다. 추가 검토한 LLC-13M-1은 TX 8/2, RX 3/4, 전원 1/5/6/7로 다르다. 2026-09-03 사용자 확인에 따라 슬립링 지그는 **암**, LLC 지그는 **수** M12를 사용하며 LLC 암 cable-end는 실물 사진으로도 확인했다. 같은 M12 8핀이라는 이유로 이 보드를 재사용하지 않는다. [`../balun_llc16/README.md`](../balun_llc16/README.md)를 참조한다. 슬립링 M12 PCB의 표기는 `슬립링 / SLIPRING`이다.

아래 **핀 번호·선색·신호 매핑**은 `Docs/[인수인계] PALA720.pptx` 슬라이드 14의 PALA720 2세대 `REV-504` 연결도를 전사해 KiCad `DRAFT 1`에 반영한 값이다. 정확한 endpoint connector MPN까지 슬라이드 14에서 확인된 것은 아니며, 실물 슬립링에서 측정한 continuity 결과도 아니므로 제작 승인 전에 별도 실측해야 한다.

## 문서 핀맵

`PAIR_TX = Ethernet TX`, `PAIR_RX = Ethernet RX`로 정의한다.

| 지그 네트 | 신호 | Molex 5극 핀 (`5055650501` 후보) | 슬립링 선색 | M12 A-coded 8핀 (`MB12MBAFF08ST-0` 후보) |
| --- | --- | ---: | --- | ---: |
| `PAIR_TX_P` | Ethernet TX+ | 1 | YEL | 4 |
| `PAIR_TX_N` | Ethernet TX− | 2 | ORN | 3 |
| `PAIR_RX_P` | Ethernet RX+ | 3 | BRN | 2 |
| `PAIR_RX_N` | Ethernet RX− | 4 | BLK | 1 |
| NC | 문서상 배정 없음 | 5 | — | — |

`5055650501`은 슬라이드 15의 별도 4세대 케이블 표에서 확인되는 하우징을 2세대에도 적용해 본 교차 슬라이드 추론이다. PCB측 `5055680571`은 제조사가 공식적으로 `505565` series와 mate한다고 지정한 5극 header지만, 그 조합이 실제 `REV-504`라는 전제는 실물 체결과 BOM으로 검증해야 한다. `MB12MBAFF08ST-0`도 catalog에 존재하는 male 8P 후보일 뿐 실제 DUT MPN은 미확인이다. 기존 KiCad 초안의 4극 `5055680471`은 제거했다.

## M12 5–8번의 문서상 역할

| M12 핀 | 슬립링 선색 | PALA720 신호 | 이 VNA 지그 |
| ---: | --- | --- | --- |
| 5 | BLU | GPS RS232_RX | NC |
| 6 | VIO | GPS 1PPS | NC |
| 7 | GRY + WHT | 24VDC | NC |
| 8 | WHT-BLK + WHT-BRN | 24VDC GND | NC |

이 네 핀을 GND, shield, 50 Ω 종단 또는 서로에게 연결하지 않는다. 측정 전 DUT의 24VDC와 다른 활성 장비를 모두 분리한다.

## 실물 continuity 확인표

핀 번호는 각 제조사 도면의 mating-face 기준으로 기록하고, 사진에는 key와 pin 1을 표시한다. 문서 예상값과 다르면 측정을 중지하고 실물/BOM/도면을 우선해 원인을 확인한다.

| 신호 | Molex 예상 핀 | M12 예상 핀 | 정지 저항 | 실측 판정 |
| --- | ---: | ---: | ---: | --- |
| TX+ | 1 | 4 | TBD Ω | 미측정 |
| TX− | 2 | 3 | TBD Ω | 미측정 |
| RX+ | 3 | 2 | TBD Ω | 미측정 |
| RX− | 4 | 1 | TBD Ω | 미측정 |

| M12 핀 | 문서상 신호 | Ethernet 1–4와 연결 | shell과 연결 | 실측 판정 |
| ---: | --- | --- | --- | --- |
| 5 | GPS RS232_RX | TBD | TBD | 미측정 |
| 6 | GPS 1PPS | TBD | TBD | 미측정 |
| 7 | 24VDC | TBD | TBD | 미측정 |
| 8 | 24VDC GND | TBD | TBD | 미측정 |

## 회전 위치별 접촉 검사

| 회전 위치 | TX+ | TX− | RX+ | RX− | 순간 단선/변동 |
| ---: | ---: | ---: | ---: | ---: | --- |
| 0° | TBD | TBD | TBD | TBD | |
| 90° | TBD | TBD | TBD | TBD | |
| 180° | TBD | TBD | TBD | TBD | |
| 270° | TBD | TBD | TBD | TBD | |
| 저속 회전 중 | TBD | TBD | TBD | TBD | |

출하검사성적서의 두 기록값인 접촉회로 저항 241/248 mΩ 및 순간단선 양호는 해당 출하 LOT의 검사 결과일 뿐, 현재 보유한 개별 DUT와 각 핀의 실측값을 대신하지 않는다.

## PCB 반영 상태와 남은 검증

- Molex측: pin 1/2를 `PAIR_TX_P/N`, pin 3/4를 `PAIR_RX_P/N`에 연결하고 pin 5는 NC로 반영함
- M12측: pin 4/3을 `PAIR_TX_P/N`, pin 2/1을 `PAIR_RX_P/N`에 연결하고 pin 5–8은 NC로 반영함
- 두 보드 모두 shared-centerline W=0.23/G=0.22 mm 배선이며 네 쌍 모두 P/N이 F.Cu-only, signal via 0/0, 저장된 track skew 0.001 mm 미만임
- M12 J1은 제조사의 female 8P 권장 PCB 배열로 수정됐고 signal pin을 transformer 쪽으로 향하게 한 PCB B면 후보임; 한쪽 극성만 layer/via를 바꾸던 crossover는 제거했으나 A-key/pin-1 mating view, front-fastened 패널 방향과 실물 체결은 DNP 차단 항목임
- KiCad 10 검사: 두 회로도 ERC 0, 두 PCB DRC 0, 미연결 pad 0, schematic–PCB parity 0
- `5055680571`의 key/pin view와 `MB12FBAFF08ST-3`의 corrected 8P geometry는 도면에 대조했지만, 두 부품 모두 1:1 출력과 실제 기구 체결은 미검증

`RS422_Cable_Assembly_Spec.pptx`는 별도 EM2 encoder용 10핀 케이블 문서이므로 이 핀맵의 근거로 사용하지 않는다.

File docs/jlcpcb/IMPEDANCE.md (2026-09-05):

# JLC04161H-7628 임피던스 계산과 CAD 반영

확인일 **2026-09-05**. 대상은 공통 `balun_eth_rj45`와 현재 수동 어댑터 3종이다. **공식 계산기에서 목표 50Ω/100Ω에 필요한 폭을 구하고, native CAD·project·DRC rule·생성 스크립트에 반영했다.** 주문 방법은 [화면별 가이드](README.md)를 따른다.

## 확정한 설계 치수

| 용도 | 신호층 / 기준면 | 목표 | 공식 계산기 출력 | 현재 CAD |
| --- | --- | --- | --- | --- |
| 공통 지그 SMA 측 | L1 / L2 | 50Ω single-ended | W 0.3566 mm | **W 0.357 mm** |
| 외층 차동 trunk | L1 / L2 | 100Ω differential | W 0.2342 / gap 0.2159 mm | **W 0.234 / gap 0.216 mm** |
| 외층 차동 trunk | L4 / L3 | 100Ω differential | W 0.2342 / gap 0.2159 mm | **W 0.234 / gap 0.216 mm** |

간격은 **edge-to-edge**다. CAD 중심 간격은 0.450 mm로 유지했다. 기존 0.23/0.22 mm에서 폭을 4 µm 늘리고 gap을 4 µm 줄였다. 50Ω 폭은 0.35→0.357 mm다. CAD는 1 µm 단위로 반올림했다. 이는 계산 모델에 따른 목표 치수 확정이며, 제조된 PCB가 정확히 100.000Ω이라는 뜻은 아니다.

현재 JLC UI는 목표 임피던스와 gap에서 폭을 구하는 **역산 계산기**다. 이전 폭을 넣어 실제 Z를 측정한 것도, 반올림한 CAD의 forward EM 해석을 수행한 것도 아니다. 2026-08-31 기록의 과거 forward 결과는 이번 최신 결과로 재현되지 않았으므로 현 주문의 정량 근거로 재사용하지 않는다.

## 재현 입력

- Board Type Rigid, 4 layers, thickness 1.6 mm, inner 0.5 oz, outer 1 oz, mm.
- Width/Spacing Complement **OFF**.
- Type: Single Ended (Non coplanar) 또는 Differential Pair (Non coplanar).
- 차동 입력: 100Ω, Trace Spacing **0.216 mm**. L1/Bottom Ref L2와 L4/Top Ref L3 각각 실행.
- 단일 입력: 50Ω, L1/Bottom Ref L2.
- 결과에서 반드시 **JLC04161H-7628 (Standard/Finished thickness 1.59 mm±10%)** 탭 선택.
- 결과의 numerical Impedance Tolerance를 **0.01%**로 정한 후 재계산. 이는 solver 수렴 설정이지 제조 보증 공차가 아니다. 실제 주문 공차는 100Ω ±10%, 50Ω ±5Ω다.

처음 기본 numerical tolerance 0.5%에서 단일 폭 0.3586 mm가 나왔고, 0.01%로 재계산하면 0.3566 mm였다. 이전 gap 0.220 mm 조건에서는 차동 폭 0.2365 mm가 표시됐다. 최종 선택에는 위 표의 결과만 사용한다. 입력 gap 0.216이 결과에 0.2159로 보이는 것은 UI의 단위/표시 정밀도 차이며 별도의 실제 가공 측정값이 아니다.

[당시 렌더링 결과 텍스트와 입력](calculator-observations.json)에 초기 탐색과 최종 결과를 구분해 보존했다. 아래 캡처는 실제 페이지이며 별도로 그린 계산 결과가 아니다.

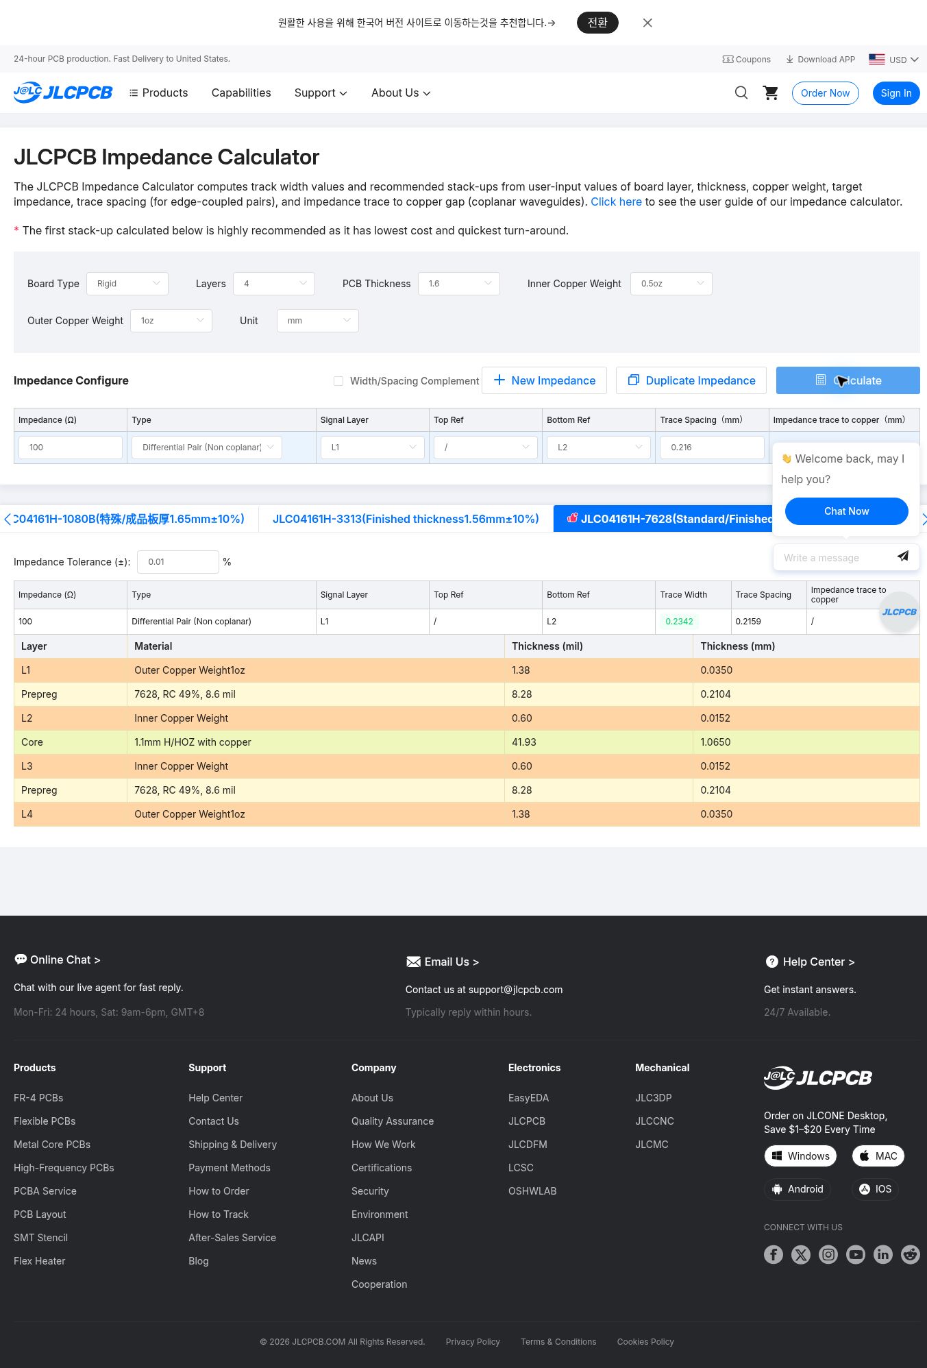
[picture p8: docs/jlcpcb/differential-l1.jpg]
100Ω L1 계산 입력과 결과


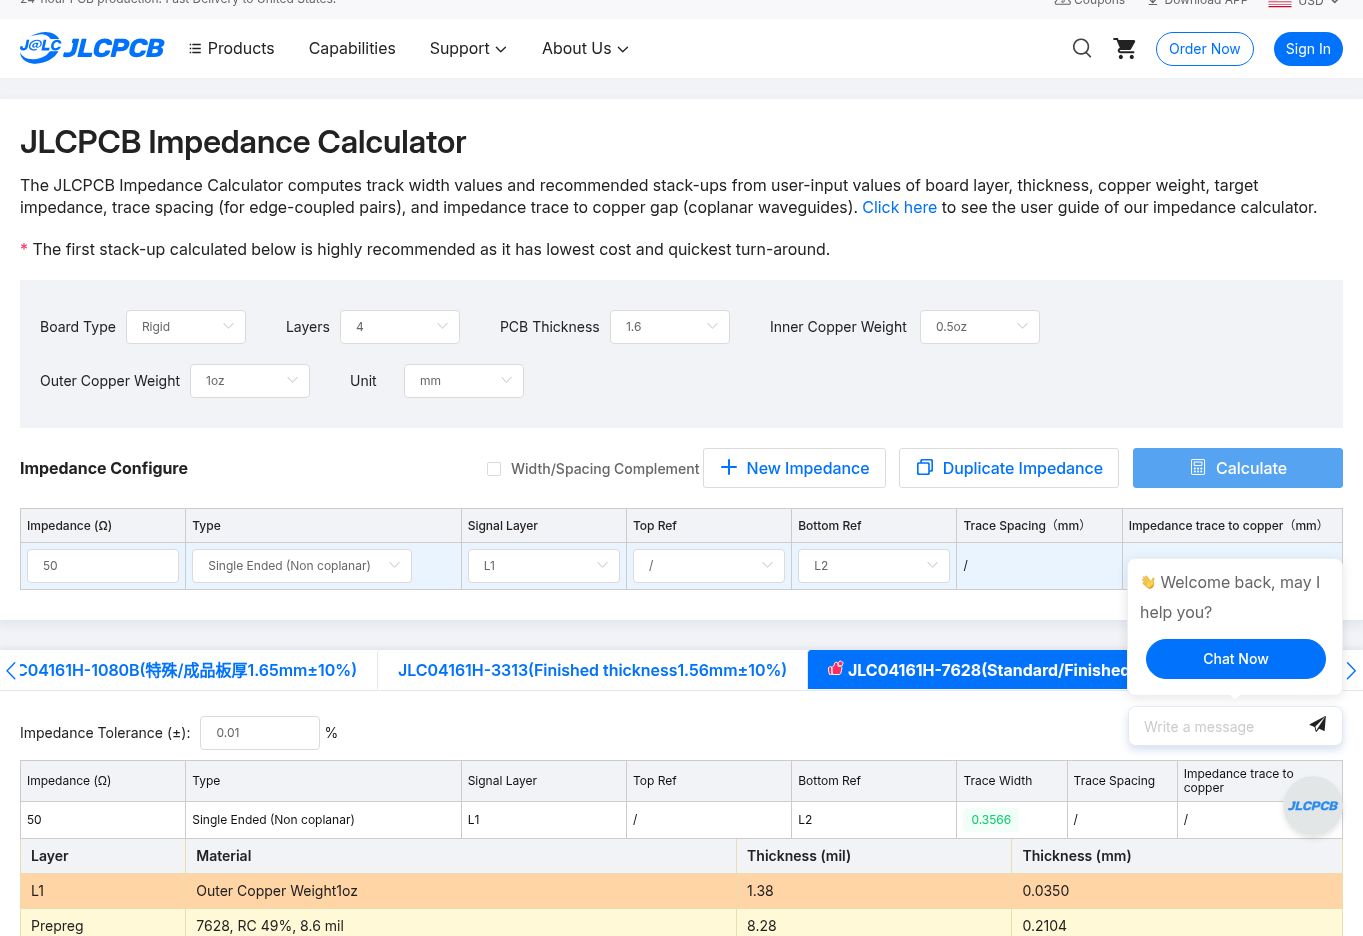
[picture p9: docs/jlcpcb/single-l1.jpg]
50Ω L1 계산 입력과 결과


[L4 결과 텍스트](differential-l4.txt)에도 0.2342 / 0.2159 mm를 확인했다. L4 결과는 텍스트로 보존했으며 별도의 L4 이미지가 있는 것으로 표시하지 않는다.

## 계산 모델과 적층

JLC [계산기 안내](https://jlcpcb.com/help/article/user-guide-to-the-jlcpcb-impedance-calculator)는 4–8층에 NP-155F를 가정한다. outer prepreg는 0.2104 mm / Dk 4.4, solder mask 포함 non-coplanar microstrip이다. 안내의 mask 두께는 base/between 1.2 mil, trace 위 0.6 mil, mask Er 3.8이며 도체 상단 폭은 하단보다 0.7 mil 작게 모델링한다. 외층 완성 동박 모델 1.6 mil(0.04064 mm)과 적층표의 base Cu 0.035 mm를 혼동하지 않는다. CAD 적층에 완성 동박을 중복 가산하지 않았다.

| 위에서 아래 | CAD / 공식 적층표 두께 |
| --- | ---: |
| L1 Cu | 0.0350 mm |
| Prepreg 7628 | 0.2104 mm |
| L2 Cu | 0.0152 mm |
| Core dielectric | 1.0650 mm |
| L3 Cu | 0.0152 mm |
| Prepreg 7628 | 0.2104 mm |
| L4 Cu | 0.0350 mm |

합계 1.5862 mm, 주문 메뉴 1.6 mm다. CAD의 core Dk 4.36은 기존 입력으로 남겼고 공급사 확정값으로 인증하지 않았다. 이번 외층 모델의 인접 기준면까지 dielectric은 7628 prepreg이며 core가 그 사이에 들어가지 않는다. 정확한 생산 재료/압착 조건은 CAM과 coupon으로 확인한다.

## CAD 변경과 검사

- 네 프로젝트의 ETH100 netclass 폭/간격, 실제 trunk, 사용자 DRC rule 및 생성 스크립트를 함께 수정했다. 공통 RF50도 0.357 mm로 변경했다.
- 이 임피던스 패치 당시 0.15 mm RJ45 escape는 유지했다. 이후 [Molex 탈출부 개선](../molex-routing/README.md)에서 Molex만 0.234 mm로 통일했다. pad/connector/balun fanout은 균일 100Ω 구간으로 표시하지 않는다.
- 폭 증가 후 M12 슬립링 pair B fanout에서 기존 0.20 mm clearance보다 작은 0.1983 mm 간격이 검출됐다. B+ trunk 끝 X를 **42.00→42.05 mm**로 연장해 해결했다. 규칙을 낮춰 통과시키지 않았다. 이로 인한 B+/B− 길이는 약 **33.169/33.167 mm**, skew 약 0.002 mm다.
- 기존 부품·핀맵·적층과 외형을 유지한다. 일반 trunk 중심선은 유지하며 위 국소 fanout 지점만 이동했다.
- 공통 지그: KiCad 10.0.6 zone refill 후 **DRC 0 / 미연결 0 / schematic parity 0**, [보고서](../../adapters/fixture_drc.json).
- 어댑터 3종: **DRC/ERC/parity 0**, 고정 pinmap/NC 검사 통과, [검사와 파일 SHA-256](../../adapters/verification.json).
- 별도 [geometry audit](geometry-audit.json): native 보드의 폭, 5 mm 이상 평행 결합 구간의 수직 중심 거리와 edge gap, 길이, pad 근접 비아를 확인했다. 사선 trunk의 저장 좌표 반올림으로 gap은 0.215999–0.216001 mm 범위다. 짧은 fanout을 이 검사로 인증하지 않는다.

재검사(읽기 전용, KiCad 10 pcbnew Python 필요):

```bash
python docs/jlcpcb/audit_geometry.py > /tmp/geometry-audit.json
```

공통 지그의 ERC는 이번 폭 변경 검증에서 재실행하지 않았다. 회로도 parity 및 DRC 결과와 구분한다. Python 보정 알고리즘은 이번 패치에서 바꾸지 않았다.

**남은 확인은 생산 CAM·coupon·부품 실물 및 RF 측정이다.** 이 계산과 DRC는 커넥터의 mode conversion, 손납땜부 기생성분, OSL 모델 오차를 보증하지 않는다. 일반 주문 두께 ±10%는 SMA의 1.60±0.05 mm 기구 요구보다 넓으므로 별도 제조 확인이 필요하다.

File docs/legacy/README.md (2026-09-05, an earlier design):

# 이전 설계·측정·구매 자료의 적용 범위

현재 설계 방향은 [설계 검토 인계](../../DESIGN_REVIEW_HANDOFF.md), 측정 절차는 [VNA_TEST_PLAN](../../VNA_TEST_PLAN.md), 수동 어댑터 제작 초안은 [JLCPCB_BUILD](../../adapters/JLCPCB_BUILD.md)를 따른다. 아래 자료는 추적 가능한 이력을 위해 원래 경로에 보존한다. 문서 본문의 “최신”, “최종”, “구매 확정”은 **작성 당시 구성**을 가리키며, 현재 기본안의 전체 발주 지시로 해석하지 않는다.

| 이력 자료 | 계속 참고할 수 있는 내용 | 현재 구성에 그대로 적용하지 않는 내용 |
| --- | --- | --- |
| [이전 VNA_TEST_PLAN](https://github.com/ckh7488/balun_test/blob/c9ee74f103a5f79e9ecf2f28fc48504b0bb64348/VNA_TEST_PLAN.md) | SMA 기준 REF 비교의 이전 의도 | 현재 최종 기준면과 보정 절차 |
| [balun_slipring](../../balun_slipring/README.md), [측정 문서](../../balun_slipring/MEASUREMENT.md) | 전용 balun CAD, 공개 PINMAP·풋프린트 근거 | 새 수동 어댑터의 회로/실장, 미사용 load 수, SMA-only 절차 |
| [balun_llc16](../../balun_llc16/README.md), [측정 문서](../../balun_llc16/MEASUREMENT.md) | 전용 balun CAD와 기존 fixture_spec 핀맵 | 새 수동 어댑터의 실장면·패널 기구·제작 수량 |
| [JLCPCB_ORDER_GUIDE](../../JLCPCB_ORDER_GUIDE.md), [JLCPCB_FINAL_BOM.csv](../../JLCPCB_FINAL_BOM.csv) | 당시 부품/조달 검토 기록 | 현재 공통 지그+어댑터 세트의 통합 BOM/수량 |
| [PCBA_PURCHASE_SCOPE_2026-09-03](../../PCBA_PURCHASE_SCOPE_2026-09-03.md) | 이전 PCBA 구성과 조립 variant | 현재 총수량과 “사용자 손납땜 없음” 전제 |
| [HAND_ASSEMBLY_PURCHASE_2026-09-03](../../HAND_ASSEMBLY_PURCHASE_2026-09-03.md), [PURCHASE_REQUEST_FORM_DRAFT_2026-09-03](../../PURCHASE_REQUEST_FORM_DRAFT_2026-09-03.md) | 당시 bare PCB/부품 구매 검토 | 예전 보드 구성·수량·M12 제외 여부를 새 어댑터에 자동 적용 |
| [RELEASE_EXPORT](../../RELEASE_EXPORT.md), [export_jlc_release.ps1](../../export_jlc_release.ps1) | 기존 export 대상과 실행 동작 | 새 `adapters/` 지원 또는 현재 전체 제조 release 완료 |
| [REVIEW_2026-08-31](../../REVIEW_2026-08-31.md), [SCHEMATIC_READABILITY_2026-09-03](../../SCHEMATIC_READABILITY_2026-09-03.md) | 당시 리뷰·회로도 가독성 변경 이력 | 현재 전체 프로젝트 검토 완료 |
| [JLCPCB_IMPEDANCE_VERIFICATION_2026-08-31](../../JLCPCB_IMPEDANCE_VERIFICATION_2026-08-31.md) | 기존 geometry/승인 상태의 기록 | 새 어댑터의 field-solver/coupon 확인 완료 |

공통 [balun_eth_rj45](../../balun_eth_rj45/README.md) Rev B 자체는 현재도 재사용한다. 그 [FAB_NOTES](../../balun_eth_rj45/JLCPCB_FAB_NOTES.md)의 nominal 적층과 land pattern은 유효한 설계 참고이며, 이력 구매 문서와 함께 모두 폐기한 것이 아니다. 다만 실제 제조사의 stack/solver, 조립 방식과 부품 안착은 현재 제작 건에 맞춰 확인한다.

과거 설계·구매 기록을 삭제하거나 주문을 취소한 것이 아니다. 새 구성의 통합 수량표, 표준 부품/PCB, 패널 도면과 어댑터 제조 export가 작성되면 해당 문서를 현재 기준으로 연결한다.

현재 제조 옵션 및 치수는 [2026-09-05 주문 화면 가이드](../jlcpcb/README.md)와 [임피던스 증거](../jlcpcb/IMPEDANCE.md)가 우선한다.

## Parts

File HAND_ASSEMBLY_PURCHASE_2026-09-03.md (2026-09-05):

# BALUN 지그 — DigiKey 부품 구매 + JLCPCB 미조립 제작

2026-09-03 갱신. 사용자 지시에 따라 **Mini-Circuits 직구와 LCSC 분산 구매를 빼고 DigiKey 한국으로 통합**한다. PCB는 JLCPCB에서 제작하고 사내 손납땜한다. HAKKO 인두팁 두 종류만 DigiKey 한국 주문 불가에 따른 국내 구매 예외다.

최신 상세 가격·전체 링크·SMA 치수 대조·구매요청서 문구는 [구매요청서 입력안](PURCHASE_REQUEST_FORM_DRAFT_2026-09-03.md)을 따른다. 이번 변경은 구매 문서 갱신이며 CAD/풋프린트/제조 BOM/생산 ZIP을 변경하거나 제조 승인한 작업이 아니다. 주문·결제·업체 문의는 실행하지 않았다.

## 1. 구성과 예산

| 구분 | 수량/구성 | 예상액, 부가세 별도 |
| --- | --- | ---: |
| JLCPCB | RJ45 5장 + Molex 5장 + LLC 5장 | 202,610원 |
| DigiKey | 아래 전자부품·RF 부속·플럭스·납흡입선 10품목 | 489,458원 |
| 국내 팁 | 900M-T-1.6D와 900M-T-2.4D 각 1개 | 16,640원 |
| 합계 | 운임·세금·별도 준비 항목 제외 | **708,708원** |

실사용은 **Molex 2 + RJ45 4 + LLC M12 수 측 2 = 8장**, 나머지 7장은 미조립 여분이다. 슬립링 M12 암 보드/암커넥터는 구매 제외하고 기존 케이블을 RJ45로 개조해 기존 RJ45 지그를 공유한다. LLC M12 수커넥터도 사내품을 사용한다. **PCB 삽입 적합성은 사용자 확인 완료**이며 필요한 2개 확보·전기적 핀맵·무전원 확인은 별도다. 사내품 품번은 임의로 특정하지 않는다.

무연 HASL, 4층/1.6mm/TG155/JLC04161H-7628, 임피던스 제어 유지. PCBA와 스텐실은 제외한다. 예산 환율은 사용자 지정 1USD=1,370원이며 DigiKey 원화 가격은 재환산하지 않는다.

사용자가 확인한 Mini-Circuits 장바구니 $215는 294,550원이다. 이를 발룬만의 가격으로 간주하지 않는다. DigiKey에서 발룬 26개+TE 종단기 6개+THRU 1개는 294,191원(배송/세금 별도)이므로, 사용자 지시대로 제조사 직구는 하지 않는다.

## 2. 부품별 주문 링크

수량에 이미 예비분이 포함돼 있다. 구형 구매표의 품번을 중복 구매하지 않는다. 2026-09-03 DigiKey 한국 표시가 기준이며 국내 팁은 앞선 같은 날 조회값이다.

| 품목 / 정확한 MPN | 구매수량 | 예상단가 | 예상금액 | 개별 구매 링크 |
| --- | ---: | ---: | ---: | --- |
| RF 발룬 / **ADT2-1T+** | 26 | 10,011원 | 260,286원 | [DigiKey](https://www.digikey.kr/ko/products/detail/mini-circuits/ADT2-1T/13927001) |
| SMA PCB 커넥터 / **SMA-J-P-H-ST-EM1** | 30 | 3,817원 | 114,510원 | [DigiKey](https://www.digikey.kr/ko/products/detail/samtec-inc/SMA-J-P-H-ST-EM1/2602450) |
| RJ45 커넥터 / **RJE591885401** | 5 | 8,052원 | 40,260원 | [DigiKey](https://www.digikey.kr/ko/products/detail/amphenol-icc-commercial-products/RJE591885401/6189327) |
| 테스트 포인트 / **5001** | 10 | 336.3원 | 3,363원 | [DigiKey](https://www.digikey.kr/ko/products/detail/keystone-electronics/5001/255327) |
| Molex 커넥터 / **5055680571** | 10 | 1,027원 | 10,270원 | [DigiKey](https://www.digikey.kr/ko/products/detail/molex/5055680571/7807019) |
| 0805 0Ω 저항 / **RC0805JR-070RL** | 10 | 24.5원 | 245원 | [DigiKey](https://www.digikey.kr/ko/products/detail/yageo/RC0805JR-070RL/728216) |
| SMA 50Ω 종단기 / **2467938-1** | 6 | 4,004원 | 24,024원 | [DigiKey](https://www.digikey.kr/ko/products/detail/te-connectivity-linx/2467938-1/22535225) |
| SMA THRU 어댑터 / **ADP-SMAF-SMAF-G** | 1 | 9,881원 | 9,881원 | [DigiKey](https://www.digikey.kr/ko/products/detail/te-connectivity-linx/ADP-SMAF-SMAF-G/9826669) |
| 전자용 플럭스 / **SMD291-10M** | 1 | 17,213원 | 17,213원 | [DigiKey](https://www.digikey.kr/ko/products/detail/chip-quik-inc/SMD291-10M/14636534) |
| 인두팁 1.6D / **900M-T-1.6D** | 1 | 8,140원 | 8,140원 | [엘레파츠](https://eleparts.co.kr/goods/view?no=5274) |
| 인두팁 2.4D / **900M-T-2.4D** | 1 | 8,500원 | 8,500원 | [디바이스마트](https://www.devicemart.co.kr/goods/view?no=2291) |
| 납흡입선 1.52mm / **80-2-5** | 1 | 9,406원 | 9,406원 | [DigiKey](https://www.digikey.kr/ko/products/detail/chemtronics/80-2-5/306981) |

### SMA 후보와 변경된 부품

- **Samtec SMA-J-P-H-ST-EM1**: 기존 에지마운트 패드와 대조한 DigiKey 후보. GND 다리 중심 간격 5.54mm vs 기존 패드 5.65mm, 다리 폭 0.81mm vs 패드 1.85mm, 신호 핀 1.27mm vs 패드 1.85mm로 명목 치수상 접점이 패드 안에 들어온다. **권장 PCB 두께 1.57mm와 현재 1.6mm 완성 두께/공차 및 HASL 안착은 별도 확인**해야 한다. 권장 패드가 완전히 동일하지 않으며 CAD는 아직 MyAntenna로 남아 있다. [Samtec 공식 도면](https://suddendocs.samtec.com/prints/sma-j-p-x-st-em1-mkt.pdf)
- Samtec 30개는 114,510원으로 기존 MyAntenna/LCSC 23,989원보다 90,521원 비싸다. DigiKey 통합 구매 예산에 반영했지만, 최종 치수·제조 정합 승인 없이 완전 호환/제조 가능으로 표시하지 않는다.
- 사용자가 제시한 TE **5-1814832-2**는 수직 THT로 이번 에지마운트 대체품이 아니다.
- ADT2-1T+, RJ45 RJE591885401, Keystone 5001, Molex 5055680571은 정확한 기존 제조사/품번을 유지하고 DigiKey에서 산다.
- 0Ω는 YAGEO **RC0805JR-070RL** 0805 점퍼로 대체하고 필요 2+예비 8=10개로 줄인다. RJ45 BONDED 두 장의 RSH1만 실장. FLOAT 두 장의 RSH1, 모든 RCT/CSH는 기존 DNP 조건을 유지.
- 전자부품 Cut Tape를 선택한다. 필요 없는 Digi-Reel 서비스 비용을 추가하지 않는다.

## 3. VNA 종단·THRU

**TE 2467938-1**은 SMA 수 50Ω 종단기(DC–18GHz, 2W, VSWR≤1.3)로 NEXT/FEXT의 미사용 포트를 종단한다. 기존 ANNE-50L+는 DigiKey 재고 0이어서 제외했다. TE 제품을 같은 정밀도/교정 등급이라고 취급하지 않는다. 사용 대역에서 각 종단기의 S11과 교체 반복성을 확인한다. [TE 공식 도면](https://www.te.com/commerce/DocumentDelivery/DDEController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)

**ADP-SMAF-SMAF-G**는 SMA 암–암 50Ω 연결 어댑터(DC–18GHz, VSWR≤1.2)다. 인증된 zero-delay 교정 표준이 아니며, VNA 교정 방식에 맞춰 유한 지연/모델을 처리한다. [TE 공식 도면](https://www.te.com/commerce/DocumentDelivery/DDEController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)

동봉 Open/Short/Load 각 1개는 VNA 두 포트에 순차 재사용한다. 추가 종단기 6개를 정밀 OSL 교정 표준으로 부르지 않는다. RJ45+RJ45는 6개, Molex+RJ45 및 LLC+RJ45는 4개를 사용하며 순차 측정에서 공용으로 사용한다. 동시에 여러 세트를 측정할 수량은 아니다.

## 4. 사진으로 확인한 인두·기존 페이스트

### 기존 goot BS-15는 이번 PCB에 사용하지 않는다

사용자 사진의 제품은 **goot BS-15**다. 뚜껑에 `Not applicable to PC boards` 및 약산성 표기가 있다. 제조사도 BS-10/15를 PCB에 사용하지 말라고 명시한다. **변색이나 오래된 상태 이전에 제품 용도가 맞지 않는다.** [goot 공식 설명](https://en.goot.jp/education/detail/bs_10)

사진에는 검게 오염된 부분과 사용 흔적도 보이지만, 색만으로 성능·성분 변화를 진단하지 않는다. 새 전자용 플럭스 용기에 기존 물질을 섞지 않고, 기존 페이스트에 담갔던 도구로 새 플럭스를 오염시키지 않는다. 기존 PCB에 이미 사용했다면 단순 IPA 세척만으로 잔류 문제가 해결된다고 가정하지 않는다.

### HAKKO 936 + 907은 본체부터 바꿀 필요는 없다

사진의 표기는 HAKKO 936 스테이션과 907 핸들이다. 정품 여부나 히터·센서·접지의 실제 상태까지 사진으로 확인할 수는 없다. 정상 동작한다면 이번 손납땜용으로 우선 활용할 수 있다. 사진의 팁은 작업면이 어둡고 오염돼 보이므로 세척 후 새 납이 작업면에 고르게 퍼지는지 확인하고, 복구되지 않거나 패인 경우 교체한다. [HAKKO 팁 상태 안내](https://www.hakko.com/japan/support/maintenance/detail.php?seq=88)

907 핸들은 기존 **900M-T-…**와 제조사가 호환을 명시한 T18 대체품을 사용할 수 있다. 이번에는 한국 DigiKey에서 T18-D16/T18-D24 주문이 불가하여 국내 900M-T 팁을 유지한다. 외형만 비슷한 다른 계열을 임의로 끼우지 않는다. [HAKKO 936/907 공식 호환 안내](https://www.hakko.com/japan/products/hakko_936_tips.html)

뾰족할수록 좋은 것은 아니다. 정상적인 평평한 D형 팁이 접촉 면적과 열 전달 측면에서 유리할 수 있다. 아래 크기는 이 작업을 위한 추천이며, 1.6 mm 팁으로 Molex 핀 여러 개를 동시에 누르라는 의미가 아니다. 작은 접점에는 팁 모서리를 사용하고 확대 관찰한다.

## 5. 플럭스와 최소 추가 소모품

| 품목 | 추천 수량 | 구매 링크 / 조회 가격 | 선택 이유·주의 |
| --- | ---: | --- | --- |
| **Chip Quik SMD291-10M** 전자용 tacky flux, 수동 주사기 10 cc/10 g | 1 | [DigiKey 한국](https://www.digikey.kr/ko/products/detail/chip-quik-inc/SMD291-10M/14636534), **₩17,213**, 재고 692개 표시 | 이번의 우선 추천 플럭스. no-clean, 수동 주사기 제품. 금속 분말이 든 solder paste가 아님 |
| HAKKO **900M-T-1.6D** | 1 | [엘레파츠](https://eleparts.co.kr/goods/view?no=5274), **₩8,954 VAT 포함**, 평균 발송 24시간 이내 표시 | SMT/일반 작업용. 표시된 평균 발송일은 실재고 예약·도착 보장이 아님 |
| HAKKO **900M-T-2.4D** | 1 | [디바이스마트](https://www.devicemart.co.kr/goods/view?no=2291), **₩9,350 VAT 포함**, 평균 준비 2–3일 표시 | SMA 접지 탭·큰 패드용. 실물 품번과 출고일 확인 |
| Chemtronics **80-2-5**, 1.52 mm 납흡입선 | 1 | [DigiKey 한국](https://www.digikey.kr/ko/products/detail/chemtronics/80-2-5/306981), **₩9,406**, 재고 6,406개 표시 | 브리지 제거용. 납이 굳은 상태에서 잡아당겨 패드를 뜯지 않음 |

인두팁은 판매자가 HAKKO로 표시한 제품을 연결했다. 저가 범용 호환 세트와 같은 것으로 취급하지 않는다. 수령 시 품번·포장을 확인한다. 제조사 규격 확인과 판매점의 유통/재고 표시는 구분한다.

- **SMD291-10M을 고른다. `SMD291AX` 같은 납 분말 포함 솔더페이스트와 혼동하지 않는다.** 인두+실납 작업에는 전자용 플럭스와 실납을 따로 사용한다.
- 기존 실납의 합금과 굵기를 확인한다. 회사의 무연 정책에 맞는 전자용 flux-cored 실납, 약 0.3–0.5 mm가 작은 SMT 작업에 다루기 편하다. 사진만으로 기존 실납 규격은 확인하지 못했다.
- 보드 고정대, 핀셋, 확대경/현미경, 멀티미터도 필요하다. 기존 장비가 있으면 중복 구매하지 않는다.
- 사진의 스펀지는 오염이 많아 보인다. 새 인두용 스펀지 또는 인두용 황동 클리너로 교체를 권한다. 팁 작업면을 줄로 갈아 모양을 바꾸지 않는다. 작업 후 팁에 새 납을 입혀 보관한다. [HAKKO 팁 관리](https://www.hakko.com/english/support/maintenance/detail.php?seq=183)
- no-clean이 무연기·무해하다는 뜻은 아니다. 국소 배기/환기를 확보하고 제조사의 SDS를 따른다. 뜨거운 인두 근처에서 가연성 세척제를 사용하지 않는다.
- RF 지그는 과도한 플럭스 잔류와 납 뭉침을 피한다. 세척은 플럭스 및 부품 제조사가 허용한 방법을 사용하며, 커넥터/변압기를 임의로 침수·초음파 세척하지 않는다.
- 새 플럭스는 제조일·유효기간을 확인한다. SMD291-10M 상품 자료는 제조 후 24개월 및 3–25 °C 보관을 안내한다. 실제 포장 지침이 우선한다.

### 손납땜 난이도에 대한 정정

손납땜 가능과 현재 오염된 팁 하나로 쉽게 끝난다는 것은 다르다. 다음은 현재 풋프린트와 부품 형태에 따른 작업 판단이다.

| 작업 | 판단 |
| --- | --- |
| 0805 저항, 테스트 포인트 | 비교적 쉬움 |
| RJ45/M12 신호 핀 | 핀이 맞고 작업 공간을 확보하면 가능. shell/고정 부위는 별도 열량·기구 고려 |
| ADT2-1T+ 발룬 | 손납땜 가능한 SMT이나 방향과 과열에 주의. 첫 보드로 연습하지 않음 |
| SMA | 미세 피치보다 접지부의 열 전달과 수평 고정이 관건. 발룬/패드까지 오래 가열하지 않음 |
| Molex 5055680571 | 이번 구성에서 정렬·브리지·플라스틱 손상에 특히 주의. 확대 관찰, 적절한 팁, 고정과 연습 필요 |

사용자가 이전에 Molex 작업에서 파손을 경험했으므로 '아무 준비 없이 전부 쉽다'고 판단하지 않는다. 새 팁과 전자용 플럭스로 연습 기판에서 먼저 젖음/브리지 제거를 확인한다. 접지부가 잘 가열되지 않으면 최고 온도로 오래 누르는 대신 열 전달·팁·작업 방법을 점검한다. 936 한 대만으로 모든 접지부의 납땜 품질을 보장하지 않는다.

## 6. 발주와 배송

1. **DigiKey:** 위 표 중 10품목을 한국 배송으로 한 번에 주문한다. 현 재고를 우선하고 재고 없는 품목의 제조 표준 리드타임을 실제 출하일과 혼동하지 않는다. 가격·세금·배송 조건은 최종 결제 화면과 [DigiKey 한국 배송 안내](https://www.digikey.kr/ko/help-support/delivery-information/delivery-time-and-cost)를 따른다.
2. **국내 팁:** HAKKO T18-D16/T18-D24의 DigiKey 한국 페이지는 주문 불가로 표시된다. 국내 900M-T 팁 두 개만 예외로 유지하며 같은 판매처에서 정확한 두 품번과 재고가 확보되면 합배송 가능하다. 출고일은 재확인한다.
3. **JLCPCB:** 미조립 PCB 3설계를 각 5장씩 별도 작업으로 주문. 부품 Pre-order와 PCBA는 사용하지 않는다. 이번 구매목록은 제조용 BOM/CPL이 아니다.
4. **M12:** 신규 구매 없음. 사내 수커넥터 PCB 삽입은 사용자 확인 완료. 전기적 핀맵/무전원 확인과 최신 생산파일 검증은 별개다.
5. **제조 승인:** Samtec SMA의 기판 두께/공차·제조파일 정합, Molex 체결, ERC/DRC/parity와 최신 생산 ZIP 검증은 완료 전이다. 과거 HOLD 파일 또는 MyAntenna가 적힌 CAD/BOM을 Samtec 승인 자료로 그대로 사용하지 않는다.

RJ45 개조 플러그 2개는 케이블 도체 굵기·연선·외경과 사내 재고 여부에 따라 정확한 품번을 확정해 링크와 가격을 추가한다. REF/bypass 하네스, 고정판/케이스·스페이서, 운임·세금 역시 별도 항목이다. VNA 연결 전 무전원·통전/단락·전원선 분리와 지그 baseline을 확인한다.

구매요청서 엑셀은 모든 품목 개별 기재, 품목별 전체 URL, 수량×단가 일치, 환율/미정 운임 처리 및 표시 검증을 적용했다. 제조사 도면 대조는 구매 후보 검토이며 실물 RF 성능 시험을 대신하지 않는다.

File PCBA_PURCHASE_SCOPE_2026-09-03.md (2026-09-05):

# BALUN 지그 PCBA 발주 범위 — 2026-09-03

> **2026-09-03 최신 구매 상태:** PCB는 JLCPCB에서 미조립 제작, 부품은 DigiKey 한국 중심(국내 인두팁만 예외)으로 구매한다. 실사용 Molex 2 + RJ45 4 + LLC 2 = 8장, 제작 예산 3종×5장=15장. 슬립링 M12 암 보드/암커넥터는 기존 케이블→RJ45 개조로 제외하며 LLC M12 수커넥터는 사내품 사용이다. **사내 수커넥터의 PCB 삽입은 사용자 확인 완료**이고 전기적 핀맵/수량 확인은 별도다. Samtec SMA는 구매 후보이며 현 CAD/MyAntenna와 최종 두께·공차/제조파일 정합 승인 전이다. 아래 이전 PCBA/구매 수량·품번은 발주에 사용하지 말고 [최신 구매요청서](PURCHASE_REQUEST_FORM_DRAFT_2026-09-03.md)를 따른다. 이번에 PCB/회로/풋프린트는 변경하지 않았다.

> **동일 날짜의 후속 결정으로 조립 방식 변경:** 사용자가 미조립 PCB + 별도 부품 구매 + 직접 손납땜을 선택했다. 최신 구매 경로·수량·링크는 [`HAND_ASSEMBLY_PURCHASE_2026-09-03.md`](HAND_ASSEMBLY_PURCHASE_2026-09-03.md)가 우선한다. 총 실사용 보드 10장과 전기적 FIT/DNP 조건, 커넥터·기구·제조 승인 HOLD는 유지한다. **이 문서 아래의 업체 PCBA/추가 손납땜 없는 납품 조건은 변경 전 기록이며 신규 발주 조건이 아니다.**

상태: **구매·조립 방식 결정 / 제조 승인 전 / 최종 견적 미확정**

현재 계획은 슬립링용 2세트 4장, RJ45용 2세트 4장에 LLC-13M-1 케이블용 M12 보드 2장을 추가한 **총 조립 보드 10장**을 JLCPCB PCBA로 제작하는 것이다. LLC 측정 때는 기존 RJ45 보드를 번갈아 공유한다. Molex를 포함한 PCB 부품의 실장·납땜은 업체에 맡긴다. 이 문서는 이전 8장 범위, 4장 합산 BOM 및 2026-09-01의 RJ45 2장 견적보다 최신인 발주 범위다. 실제 주문·결제 또는 업체의 조립 승인을 뜻하지 않는다. **LLC는 수커넥터 MB12MBAFF08ST-3를 선정하고 PCB DRAFT A의 배치·배선 및 ERC/DRC/parity 검증을 완료했다. JLC 조달·조립과 패널 기구 승인은 HOLD이며 제조 Gerber/BOM/CPL은 아직 없다.**

## 필요한 납품 수량

| 용도 | 구성 | 조립 보드 수량 |
| --- | --- | ---: |
| 슬립링 2세트 | Molex 측 2장 + M12 측 2장 | 4 |
| RJ45 2세트 | 양단용 동일 PCB 4장, 아래 두 조립 상태로 구분 | 4 |
| LLC-13M-1용 | 전용 M12 측 2장, 기존 RJ45 보드 공유 | 2 |
| 합계 | 기존 PCB 설계 3종 + LLC 신규 PCB 초안 1종 | 10 |

위 수량은 필요한 조립품 수량이다. 업체의 최소 PCB 제작 수량, 조립 작업별 최소 수량 및 부품 공정 여유분은 견적에서 별도로 확인한다. 여분의 미조립 기판을 조립 지그 수량에 포함하지 않는다.

LLC에도 전용 RJ45 보드 2장을 배정해 세 종류 DUT의 지그를 모두 독립된 두 세트씩 구성하려면 총 12장이다. 현재는 공유하는 10장 계획이며, 12장 구매로 임의 확대하지 않는다. LLC 도면 핀맵과 암수 확인 기록은 [`balun_llc16/README.md`](balun_llc16/README.md)를 따른다.

## 추가 손납땜 없는 PCB 납품 요청

현재 기준 회로의 CT-FLOAT 조건을 유지한다. 의도적인 DNP는 조립 누락이 아니다.

| 조립 구분 | 수량 | RSH1 | CSH1 | RCT |
| --- | ---: | --- | --- | --- |
| RJ45 SHIELD-BONDED | 2 | C17477 0 Ω FIT | DNP | 전부 DNP |
| RJ45 SHIELD-FLOAT | 2 | DNP | DNP | 전부 DNP |
| Molex endpoint | 2 | 해당 없음 | 해당 없음 | 전부 DNP |
| 슬립링 M12 endpoint | 2 | 해당 없음 | 해당 없음 | 전부 DNP |
| LLC M12 endpoint / 구동기 to RJ45 | 2 | 해당 없음 | 해당 없음 | 전부 DNP |

RJ45 한 세트에는 SHIELD-BONDED 보드 1장과 SHIELD-FLOAT 보드 1장을 조합한다. 입고 후 저항을 직접 붙이는 것을 기본 작업으로 남기지 않는다. 업체가 상태를 명확히 식별해 납품하도록 요청하고, 각 세트와 보드의 식별번호를 기록한다. VNA Port 번호를 바꾸어 연결해도 보드의 RSH1 조립 상태는 바뀌지 않는다.

RJ45 두 variant는 같은 PCB artwork를 사용하지만 FIT/DNP가 다르다. JLC가 한 작업 안에서 두 상태를 제조·표기할 수 있는지 확인한다. 지원되지 않으면 RJ45 조립 작업을 각 2장씩 나누는 견적을 받는다. 이 경우 총 조립 작업은 RJ45 2종 + Molex + 슬립링 M12 + LLC M12의 5개가 되며 setup 비용과 최소 제작 수량이 달라질 수 있다. 별도 승인 없이 사용자 손납땜으로 되돌리거나 RSH1을 네 장 모두 FIT/DNP로 통일하지 않는다.

M12 보드 실크는 슬립링용 `슬립링 / SLIPRING`, LLC용 `구동기 to RJ45`로 구분했다. 두 용도는 핀맵과 커넥터 암수가 다르므로 같은 보드를 라벨만 바꿔 납품하면 안 된다. LLC는 별도 수커넥터 풋프린트와 배선을 적용한 PCB 초안이며, 제조 승인 전에는 실장 발주하지 않는다.

### PCB 실장 부품 검산

| 부품 | 10장 계획 합계 | 비고 |
| --- | ---: | --- |
| ADT2-1T+ / C5223988 | 28 | 기존 24 + LLC 4, 모든 발룬 FIT |
| A-SMA-KE-16.5A / C22467617 | 28 | 기존 24 + LLC 4, 커넥터 접지부 포함 납땜, 공정 승인 필요 |
| RJE591885401 / C5386678 | 4 | RJ45 보드에 각 1개 |
| Keystone 5001 / C238122 | 8 | RJ45 보드에 각 2개, 완성 홀 적합성 검토 |
| Molex 5055680571 / C585386 | 2 | 체결·핀맵 검증 전 HOLD |
| Finecables MB12FBAFF08ST-3 / C22378785 | 2 | 슬립링용 female 후보만 해당, 조달·기구·핀맵 검증 전 HOLD |
| Finecables MB12MBAFF08ST-3 / LCSC TBD | 2 | LLC용 M12 A-coded 8핀 수, B면 필수 FIT. 제조사 male PCB layout 적용 및 CAD 검사 완료, JLC 조달·조립·패널 기구 승인 전 HOLD |
| 0805W8F0000T5E / C17477 | 2 | SHIELD-BONDED 두 장의 RSH1만 FIT |

이 표는 제조 미승인 설계를 포함한 검산용이며 업로드용 BOM/CPL이 아니다. 선택 시험용 RCT 및 CSH는 기본 실장 수량에 넣지 않는다. T4112012081-000은 DUT 케이블 측 부품번호이지 PCB 상대 커넥터의 구매 번호가 아니다. LLC PCB DRAFT A에서 위 수량 외 전기 부품을 추가하지 않았으며, 패널·고정 부품은 별도 기구 검토 후 확정한다. 최종 조립 승인 후 최신 PCB와 일치하는 생산 BOM/CPL이 필요하다.

## 공용 계측 부속과 별도 제작물

VNA 한 대로 한 세트씩 순차 측정한다는 기존 조건을 적용한다.

- 미사용 포트 종단기: ANNE-50L+ SMA male 50 Ω, 동일품 6개. RJ45 한 세트에는 6개, 슬립링 한 세트에는 2개, LLC M12 + RJ45 구성에는 4개를 사용하므로 번갈아 공유한다. LLC에서도 RJ45의 미사용 C/D SMA를 종단한다.
- 교정 연결용 THRU: SF-SF50+ SMA female-female, 1개.
- 동봉 Open/Short/Load: 각 1개를 두 VNA 포트에 순차 재사용한다. 미사용 포트 종단기와는 별도다.
- VNA 동축 케이블: 기존 2개를 검증해 사용한다. 교체 구매 여부는 별도 결정이다.
- 슬립링 REF/bypass 기준 케이블: PCB PCBA에 포함되지 않는다. 기존 검증 전 후보 사양을 유지하며, 커넥터·핀맵·길이·압착 적합성을 확인한 뒤 완성 하네스 조달/제작을 별도로 확정한다. 사용자가 작은 Molex 압착이나 납땜을 직접 할 것으로 가정하지 않는다.
- LLC용 REF 기준 하네스: 슬립링 REF와 별도다. 수 PCB 지그와 체결할 **암 M12 cable-end ↔ RJ45 plug**, M12 8→RJ45 1 / 2→2 / 3→3 / 4→6 배선의 짧은 100 Ω twisted-pair 완성 하네스 조달/제작을 검토한다. 정확한 부품·길이·차폐 및 완성품 사양은 별도로 확정한다.
- 케이스, 고정판, 비도전성 스페이서와 체결 부품은 PCBA와 별도다.

두 RJ45 측정 구성을 동시에 운용하려면 미사용 포트용 종단기는 총 12개가 필요하다. 보드를 예비로 보관하는 것만으로 종단기 수량을 늘리지는 않는다.

## 발주 전 해제해야 할 항목

1. 실제 슬립링과 Molex/M12의 체결, key, pin 1 및 Ethernet 4선 continuity 확인. M12의 정확한 부품 조달, PCB 실장 방향과 패널 기구 검토. 두 endpoint의 HOLD를 임의 해제하지 않는다.
2. SMA의 기판 두께/슬롯 fit, 기판 끝 안착, 방향과 업체의 납땜·고정 공정 승인. 기존 적층 및 임피던스 조건은 유지한다.
3. RJ45 두 조립 variant의 처리 방법, 수량과 식별 표기를 업체가 승인한 후 variant별 BOM/CPL 생성·검증. 기존 exporter는 RSH1이 빠진 공통 DNP 후보만 생성하므로 그대로는 SHIELD-BONDED 발주를 충족하지 않는다.
4. LLC 지그의 **수커넥터 필요는 확인 완료했고, 제공 도면의 8→1 / 2→2 / 3→3 / 4→6 핀맵을 PCB에 반영했다.** 전원 핀 1/5/6/7은 NC이며 기존 슬립링의 암 M12 부품/배선을 복사하지 않았다. MB12MBAFF08ST-3의 제조사 male land pattern을 적용했고 native ERC/DRC/parity는 모두 통과했다. JLC 조달·조립, 실제 mating/key, 패널 지지 및 제조 시점의 적층·임피던스/CAM 승인은 남아 있다. 실물 continuity는 최초 VNA 연결 전 검사로 분리하며 설계 착수 조건으로 요구하지 않는다.
5. 설계별 최신 ERC/DRC/parity, 생산파일, BOM/CPL 매칭과 배치 확인 후 제조 승인. 현재 exporter는 LLC PCB 초안을 포함하지 않으며 LLC용 제조파일은 생성하지 않는다.
6. PCB·부품·조립·공정비·운임을 합친 **10장 구성의 최종 견적** 확보. 이전 RJ45 2장 견적을 이번 금액으로 사용하거나 단순 배수로 계산하지 않는다.

PCBA 납품은 부품이 납땜된 보드 납품이다. VNA 교정, 지그 baseline/반복성 확인, RF 성능 검증 및 하네스·기구 조립까지 완료된 계측기 납품과는 구분한다.

LLC 케이블은 최초 VNA 연결 전 무전원·실물 핀맵·전원선 분리 및 shell/shield 관계를 확인한다. 설계자료 채택을 실물 측정 완료로 기록하지 않는다.

## 구매요청서용 품목 문구

> 이더넷 VNA 측정용 지그 PCBA 제작, 총 10장(슬립링용 2세트 4장 + RJ45용 2세트 4장 + LLC-13M-1 케이블용 M12 지그 2장, LLC 측정 시 기존 RJ45 지그 공유). PCB 제작, BOM 부품 조달, Molex·M12·RJ45·SMA 커넥터를 포함한 부품 실장·납땜 및 지정 RSH1 조립 상태를 포함한다. 사용자 추가 납땜 없이 납품하는 조건으로 설계 검증, 업체 승인 및 최종 견적 후 발주한다. 공용 SMA 50 Ω 종단기 6개와 교정 연결용 THRU 1개, 용도별 REF 하네스 및 기구물은 별도 항목으로 관리한다. LLC M12 지그는 제공 도면 핀맵으로 PCB 초안 및 CAD 검증을 완료했으며, JLC 커넥터 조달·조립과 패널 기구·생산파일 승인 후 발주하는 개발 시제품이다.

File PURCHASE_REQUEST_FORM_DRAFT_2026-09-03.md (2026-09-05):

# 구매요청서 양식 입력안 — DigiKey 우선 / 2026-09-03

부품 구매처를 **DigiKey 한국으로 통합**한다. PCB 제작은 JLCPCB, 한국 DigiKey에서 주문이 불가능한 HAKKO 인두팁 두 종류만 국내 구매 예외로 둔다. 사용자 지시에 따라 Mini-Circuits 직접 구매 및 LCSC 분산 구매는 이번 기본 주문안에서 제외했다. 상신·장바구니 추가·주문·결제는 실행하지 않았다.

작성용 예상환율은 **1 USD = 1,370원**이다. DigiKey 품목은 한국 페이지 원화 가격을 그대로 사용하고, JLCPCB USD 제작비만 환산한다. 조회 가격은 부가세 별도 예상액이며 공식 견적서가 아니다.

| 구분 | 예상액(원, 부가세 별도) |
| --- | ---: |
| JLCPCB — 3설계 × 5장 = 제작 15장 | 202,610 |
| DigiKey — 전자부품·RF 부속·플럭스·납흡입선 10품목 | 489,458 |
| 국내 — HAKKO 인두팁 2품목 | 16,640 |
| **작성 가능 예상 소계** | **708,708** |

운임·부대비, 세금, RJ45 개조 플러그, 추가 DFM, REF 하네스 및 기구물은 별도 미확정이다. 위 금액은 모든 추가 항목까지 포함한 최종 발주 총액이 아니다. 사내 손납땜이므로 PCBA·스텐실 비용은 포함하지 않는다.

**SMA는 Samtec 후보 가격을 반영한 예산이다.** 현재 CAD의 MyAntenna와 접점 위치는 명목 치수상 수용 가능하지만 권장 패드/PCB 두께까지 동일한 제품은 아니다. 완성 두께·공차 및 제조파일 정합 확인 후 확정한다. 이 문서는 PCB 또는 풋프린트 변경/제조 승인을 수행한 결과가 아니다.

## 사용자 확인 반영

- 실사용 8장: Molex 2 + RJ45 4(BONDED 2/FLOAT 2) + LLC M12 수 측 2. 제작 예산은 15장, 여분 7장은 미조립.
- 슬립링 M12 암측 PCB와 암커넥터는 제외. 기존 라이다–슬립링 케이블의 라이다측을 RJ45로 개조하여 RJ45 지그를 공유.
- LLC M12 수커넥터는 사내품으로 신규 구매하지 않음. **PCB에 잘 꽂히는 것은 사용자 확인 완료.** 필요한 2개 확보·전기적 핀맵·무전원 확인은 별도.
- 사용자 확인 Mini-Circuits 직구 장바구니 **$215 = 294,550원**. 포함 품목/세금 내역은 독립 확인하지 않았으며 발룬만의 가격으로 간주하지 않음.
- DigiKey에서 발룬 26 + TE 종단기 6 + THRU 1은 **294,191원(배송·세금 별도)**. 사용자 지시대로 직구 대신 DigiKey 선택.

## 상단 항목

| 항목 | 입력안 |
| --- | --- |
| 제목 | **[실제 과제명] 이더넷 VNA 측정 지그-PCB 및 부품 구매** |
| 과제명 / 적용과제 | 실제 회사 과제명 및 코드 확인. 화면에 선택된 기본값을 그대로 사용하지 않음 |
| 장비명(계약서 기준) | 회사 등록 장비명 확인. 해당 없으면 사내 작성 기준에 따라 처리 |
| 장비명(상세설계 기준) | 이더넷 VNA 측정 지그 — 작성안 |
| 적용 구분 | 사내 검증용이므로 **자체시험 추천**. 실제 개발/시험 분류는 회사 기준 확인 |
| 선진행 | 미진행이면 제외. 실제 선진행 승인 유무 확인 |
| 구매 목적 | 슬립링, RJ45 및 LLC-13M-1 케이블의 이더넷 전송 특성(S11~S22, NEXT/FEXT)을 VNA로 비교·검증하기 위한 측정 지그 PCB, 구성 부품 및 조립용 소모품 구매. |
| 거래처명 | 복수 거래처 (품목별 비고 참조) |
| 기존/신규 거래 | 회사 거래처 등록 이력 확인 후 선택 |
| 거래처 담당자/연락처 | 구매처별 실제 주문 담당자 확인. 온라인 주문은 해당 사실과 확인 가능한 연락처 기재 |
| 요청 납기일 | 희망 날짜 확인 필요. 최종 제조파일 승인 및 공급처 출고일 확인 후 확정 |
| 대금 결제 조건 | 협의 작성안. 해외 온라인 주문의 선결제 및 회사 결제 절차 확인 후 선택 |
| 이전문서번호 / 재제작 사유 | 신규 제작안. 이전 발주가 있었다면 해당 문서번호와 사유 보완 |
| 발주 유무 | **발주 요청** — 현재 미발주 |
| 통화 | **WON**, 부가세 별도. USD 항목은 사용자 지정 예상환율 **1,370원/USD**로 환산 |

## 개별 품목표 — 구매 링크 포함

금액 단위 원, 부가세 별도. 모든 제품을 개별 기재하며 “외 n종”으로 생략하지 않는다. 수량은 이미 예비분을 포함하므로 실사용 수량을 다시 더하지 않는다.

| 번호 | 한글품명 | 부품번호(업체품번) | 도면번호(제조사) | 수량 | 예상단가 | 예상금액 | 개별 구매 링크 |
| ---: | --- | --- | --- | ---: | ---: | ---: | --- |
| 1 | RJ45 측정 지그 PCB | balun_eth_rj45 | JLCPCB | 5 | 13,538.4 | 67,692 | [JLCPCB 구매/견적](https://cart.jlcpcb.com/quote) |
| 2 | 슬립링 Molex 측 PCB | balun_slipring_molex | JLCPCB | 5 | 13,491.8 | 67,459 | [JLCPCB 구매/견적](https://cart.jlcpcb.com/quote) |
| 3 | LLC M12 수 측 PCB | balun_llc16 | JLCPCB | 5 | 13,491.8 | 67,459 | [JLCPCB 구매/견적](https://cart.jlcpcb.com/quote) |
| 4 | RF 발룬 | ADT2-1T+ | Mini-Circuits | 26 | 10,011 | 260,286 | [DigiKey 구매/견적](https://www.digikey.kr/ko/products/detail/mini-circuits/ADT2-1T/13927001) |
| 5 | SMA PCB 커넥터 | SMA-J-P-H-ST-EM1 | Samtec | 30 | 3,817 | 114,510 | [DigiKey 구매/견적](https://www.digikey.kr/ko/products/detail/samtec-inc/SMA-J-P-H-ST-EM1/2602450) |
| 6 | RJ45 커넥터 | RJE591885401 | Amphenol | 5 | 8,052 | 40,260 | [DigiKey 구매/견적](https://www.digikey.kr/ko/products/detail/amphenol-icc-commercial-products/RJE591885401/6189327) |
| 7 | 테스트 포인트 | 5001 | Keystone | 10 | 336.3 | 3,363 | [DigiKey 구매/견적](https://www.digikey.kr/ko/products/detail/keystone-electronics/5001/255327) |
| 8 | Molex 커넥터 | 5055680571 | Molex | 10 | 1,027 | 10,270 | [DigiKey 구매/견적](https://www.digikey.kr/ko/products/detail/molex/5055680571/7807019) |
| 9 | 0805 0Ω 저항 | RC0805JR-070RL | YAGEO | 10 | 24.5 | 245 | [DigiKey 구매/견적](https://www.digikey.kr/ko/products/detail/yageo/RC0805JR-070RL/728216) |
| 10 | SMA 50Ω 종단기 | 2467938-1 | TE Connectivity | 6 | 4,004 | 24,024 | [DigiKey 구매/견적](https://www.digikey.kr/ko/products/detail/te-connectivity-linx/2467938-1/22535225) |
| 11 | SMA THRU 어댑터 | ADP-SMAF-SMAF-G | TE Connectivity / Linx | 1 | 9,881 | 9,881 | [DigiKey 구매/견적](https://www.digikey.kr/ko/products/detail/te-connectivity-linx/ADP-SMAF-SMAF-G/9826669) |
| 12 | 전자용 플럭스 | SMD291-10M | Chip Quik | 1 | 17,213 | 17,213 | [DigiKey 구매/견적](https://www.digikey.kr/ko/products/detail/chip-quik-inc/SMD291-10M/14636534) |
| 13 | 인두팁 1.6D | 900M-T-1.6D | HAKKO | 1 | 8,140 | 8,140 | [엘레파츠 구매/견적](https://eleparts.co.kr/goods/view?no=5274) |
| 14 | 인두팁 2.4D | 900M-T-2.4D | HAKKO | 1 | 8,500 | 8,500 | [디바이스마트 구매/견적](https://www.devicemart.co.kr/goods/view?no=2291) |
| 15 | 납흡입선 1.52mm | 80-2-5 | Chemtronics | 1 | 9,406 | 9,406 | [DigiKey 구매/견적](https://www.digikey.kr/ko/products/detail/chemtronics/80-2-5/306981) |
| 16 | 운임·부대비 | 견적 참조 | 해당 업체 | 1식 | 확인 필요 | 확인 필요 | 최종 결제/견적 기준 |

PCB는 기성품 상품 링크가 없으므로 공통 JLCPCB 주문창에서 설계별 승인 Gerber를 각각 사용한다. 1–3번을 한 종류로 묶어 주문하지 않는다. 원화 단가는 PCB 로트금액을 수량으로 나눠 소수 2자리로 표시했다.

- **실단가·실금액은 구매 전이므로 공란**으로 유지한다.
- 상위도번, 과제/장비명, 거래처 담당자·연락처, 납기, 결제 조건은 실제 회사 정보로 보완한다.
- 요청서류: 업체 견적/장바구니 가격내역, 거래명세, 결제증빙. 이 파일을 업체 발행 견적서라고 표시하지 않는다.
- 재고는 2026-09-03 공개 제품 페이지 표시값이며 예약이 아니다. 장바구니 수량별 단가와 한국 배송 가능 여부를 결제 전에 재확인한다.
- Cut Tape 부품은 불필요한 Digi-Reel 서비스 추가비를 선택하지 않는다.

## 구매 변경 및 호환성 근거

### SMA — 현재 패드와 비교한 DigiKey 후보

선택 후보는 [Samtec SMA-J-P-H-ST-EM1 / SAM8857-ND](https://www.digikey.kr/ko/products/detail/samtec-inc/SMA-J-P-H-ST-EM1/2602450)이다. 50Ω SMA jack 에지마운트이며 조회 재고 67,491개, 30개 구매 시 3,817원/개다.

| 비교 | 현재 MyAntenna 풋프린트 | Samtec 접점 도면 |
| --- | --- | --- |
| 양쪽 GND 중심 간격 | 5.65mm | 5.54mm |
| 각 GND 패드/다리 폭 | 패드 1.85mm | 다리 0.81mm |
| 신호 패드/핀 폭 | 패드 1.85mm | 핀 1.27mm |
| 보드 끝에서 패드/삽입 길이 | 패드 4.50mm | 다리 3.81mm |
| 기판 두께 | 현재 주문 1.6mm | 권장 1.57mm |

명목 치수상 Samtec 접점이 현 패드 영역 안에 들어오는 **장착 가능 후보**다. 제조사 권장 패드는 현재 패드와 완전히 같지 않으며, JLC 완성 기판 두께와 공차·HASL 높이·SMA 안착 및 RF launch 성능까지 검증 완료했다는 뜻은 아니다. 실물 fit 또는 제조사 허용 범위와 생산파일 정합 확인 전 일괄 발주/제조 승인하지 않는다. [Samtec 공식 도면](https://suddendocs.samtec.com/prints/sma-j-p-x-st-em1-mkt.pdf)

비교 비용: 기존 [MyAntenna/LCSC C22467617](https://www.lcsc.com/product-detail/C22467617.html) 30개 23,989원 대비 Samtec 114,510원으로 **90,521원 증가**한다. 기존 LCSC 가격은 같은 날 재확인한 할인 단가 $0.5838이며 재고 388개였다. 현재는 DigiKey 통합 예산에 Samtec을 반영했다. MyAntenna를 중복 주문하지 않는다.

사용자가 링크한 [TE 5-1814832-2](https://www.digikey.kr/ko/products/detail/te-connectivity-amp-connectors/5-1814832-2/11611208)는 수직 THT 제품이므로 이 에지마운트 풋프린트의 대체품으로는 사용하지 않는다.

### 그대로 유지하거나 대체한 부품

- 발룬 **ADT2-1T+**: 제조사/정확한 품번 유지, 구매처만 DigiKey로 확정. 26개 × 10,011원, 재고 831개. URL에는 `+`가 빠져 있어도 실제 제조사 품번은 `ADT2-1T+`로 확인한다.
- **RJE591885401 / 5001 / 5055680571**: 기존 정확한 품번 유지. 조회 재고 각각 2,308 / 376,735 / 21,435개.
- 0Ω는 **YAGEO RC0805JR-070RL / 311-0.0ARCT-ND**로 변경. 0805 0Ω 점퍼이며 필요 2 + 예비 8 = 10개. 기존 LCSC 최소수량 100개는 유지할 이유가 없어 줄였다. BONDED 두 보드의 RSH1만 실장; 다른 RSH/RCT/CSH의 DNP 지시는 유지한다.
- 종단기는 **TE 2467938-1**로 변경: SMA 수, 50Ω, DC–18GHz, 2W, VSWR 최대 1.3, 재고 2,572개. **ANNE-50L+는 DigiKey 현재 재고 0**으로 제외. 이는 범용 미사용 포트 종단기이며 ANNE와 같은 정밀도 또는 교정 등급을 보장하지 않는다. 사용할 주파수에서 각 종단기의 S11과 교체 반복성을 먼저 확인한다. [TE 공식 도면](https://www.te.com/commerce/DocumentDelivery/DDEController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)
- THRU는 **TE/Linx ADP-SMAF-SMAF-G**로 변경: SMA 암–암, 50Ω, DC–18GHz, VSWR 최대 1.2, 재고 8,533개. 연결 어댑터이며 인증된 zero-delay 교정 표준이 아니다. VNA의 교정 방식에 맞춰 유한 지연을 처리한다. [TE 공식 도면](https://www.te.com/commerce/DocumentDelivery/DDEController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)
- 플럭스 **SMD291-10M**과 납흡입선 **80-2-5**는 기존 선택 유지. 재고 692 / 6,406개, 조회가격 17,213 / 9,406원.
- 인두팁만 국내 구매: HAKKO 대체 T18-D16/T18-D24의 [DigiKey 한국 1.6D 페이지](https://www.digikey.kr/ko/products/detail/american-hakko-products-inc/T18-D16/6228930), [2.4D 페이지](https://www.digikey.kr/ko/products/detail/american-hakko-products-inc/T18-D24/6228931)는 주문 불가 표시다. 미국 재고를 한국 주문 가능 재고로 간주하지 않았다. 국내 900M-T 팁 공급가 8,140 / 8,500원은 앞선 같은 날 조회값으로 출고일 재확인이 필요하다.

## PCB 제작 예상단가 근거

2026-09-03 JLCPCB 웹 계산기, 설계별 5장 독립 작업 기준이다. **4층 / 1.6mm / FR-4 TG155 / JLC04161H-7628 / 외층 1oz·내층 0.5oz / Green / 무연 HASL / 임피던스 ±10% / 생산파일 확인 Yes**를 적용했다. 기존 Nan Ya NP-155F 소재 요구는 최종 CAM 승인 시 제조사와 별도로 확인한다.

| 설계 | 무연 HASL 5장 제작비 | ENIG 5장 비교가격 |
| --- | ---: | ---: |
| balun_eth_rj45 | $49.41 / 67,692원 | $61.41 / 84,132원 |
| balun_slipring_molex | $49.24 / 67,459원 | $61.04 / 83,625원 |
| balun_llc16 | $49.24 / 67,459원 | $61.04 / 83,625원 |
| 제작 15장 합계 | **202,610원** | **251,382원** |

무연 HASL 선택 시 **48,772원 절감**한다. ENIG는 패드 평탄도·보관 중 산화 저항에 유리하지만 이번 손납땜 지그의 필수 조건으로 보지는 않았다. 표면처리는 사용자 승인으로 변경했다. SMA 가장자리 패드의 납 두께·커넥터 안착과 접합 품질은 확인한다. [JLCPCB 표면처리 설명](https://jlcpcb.com/help/article/jlcpcb-surface-finish)

RJ45 무연 HASL 가격 내역은 $7.00 기본 + $5.10 표면처리 + $3.43 TG155 + $32.84 임피던스 제어 + $1.04 생산파일 확인이다. 68×44mm 설계는 $7.00 + $5.00 + $3.36 + $32.84 + $1.04다. [조회한 JLCPCB 견적 화면](https://cart.jlcpcb.com/quote)

Gerber 업로드·장바구니 저장·결제를 하지 않은 사양 입력 예상가다. 운임·세금·PCBA·스텐실은 제외하고 쿠폰/데스크톱 할인도 적용하지 않았다. 수량이나 사양을 바꾸면 다시 견적을 계산한다. 기존 동일 치수·사양의 68×44mm 계산값을 남은 Molex와 LLC 설계에 각각 적용했으며 합판 1작업 견적이 아니다.

## 특이사항 — 전자결재 복사용

1. 미조립 PCB는 JLCPCB, 전자부품·RF 부속·플럭스·납흡입선은 DigiKey 한국에서 구매합니다. HAKKO 인두팁 두 종류만 국내 판매처 구매입니다. Mini-Circuits 직접 구매와 LCSC 구매는 기본 주문에서 제외합니다.
2. PCB 3종을 각각 5장씩 총 15장 제작하며, Molex 2장 + RJ45 4장 + LLC M12 수 측 2장 = 총 8장을 사내 손납땜으로 조립합니다. PCBA·스텐실 비용은 포함하지 않습니다.
3. 발룬 26개(필요 24+예비 2), SMA 30개(필요 24+예비 6), 종단기 6개와 THRU 1개를 구매합니다. 0Ω 저항은 필요 2+예비 8=10개입니다.
4. 슬립링 M12 암 보드·암커넥터는 제외하고 기존 케이블을 RJ45로 개조합니다. LLC M12 수커넥터는 사내품으로 구매하지 않으며 PCB 삽입은 사용자 확인 완료입니다.
5. Samtec SMA는 현재 접점 패드와 도면 대조한 후보로 예산 반영했습니다. 권장 1.57mm와 완성 기판 두께·공차 및 CAD/제조파일 정합 확인 후 확정합니다. PCB 표면처리는 무연 HASL, 임피던스 제어는 유지합니다.
6. 미사용 SMA 포트의 50Ω 종단기는 NEXT/FEXT 측정에 공용 사용합니다. RJ45+RJ45 구성은 6개, Molex+RJ45 및 LLC+RJ45 구성은 4개 사용합니다. 기존 VNA 동봉 OSL 각 1개는 두 포트에 순차 재사용합니다. 추가 종단기는 정밀 OSL 표준이 아닙니다.
7. 작성 가능 예상 소계는 708,708원(부가세 별도)입니다. JLC 제작 202,610원 + DigiKey 489,458원 + 국내 팁 16,640원입니다. 운임·세금·RJ45 개조 플러그·추가 DFM·REF 하네스·기구물은 별도입니다.
8. 위 개별 품목표의 구매 링크를 모두 함께 첨부합니다. 실단가·실금액은 구매 후 반영합니다. 사용 전 무전원·통전·단락·전원선 분리 및 지그 baseline을 확인합니다.

## 제출 전 남은 정보

실제 회사 과제/장비명·상위도번·희망 납기·담당자/연락처·거래처 등록·결제 조건, 사내 M12 수량 2개와 전기적 핀맵, SMA 두께/제조 정합, 최종 Gerber/DFM 가격, 운임·부대비, RJ45 개조 플러그 2개의 케이블 적합 품번과 사내 재고 여부를 보완한다. 미정 가격을 0원으로 넣어 최종 총액을 확정하지 않는다.

배송/세금/특수 배송 예외는 [DigiKey 한국 공식 배송 안내](https://www.digikey.kr/ko/help-support/delivery-information/delivery-time-and-cost)와 최종 결제 화면을 따른다. 표시 재고를 확보한 주문이나 확정 납품일로 표현하지 않는다.

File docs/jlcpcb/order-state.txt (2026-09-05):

- paragraph: 원활한 사용을 위해 한국어 버전 사이트로 이동하는것을 추천합니다.→
- button "전환":
  - generic: 전환
- navigation:
  - link:
    - /url: https://jlcpcb.com
  - generic: 
  - generic: 
  - link "":
    - /url: /shopcart/cart/
    - generic: 
  - superscript: "0"
  - text:    
  - text: USD
  - generic: 
  - generic: Sign In
- main:
  - main:
    - paragraph: Select Product
    - img "standard-pcb-pcba"
    - paragraph: Standard PCB/PCBA
    - generic: 
    - img "advanced-pcb-pcba"
    - paragraph: Advanced PCB/PCBA
    - img "smt-stencil"
    - paragraph: SMT Stencil
    - img "flexible-heater"
    - paragraph: Flex Heater
    - img "mechatronic-parts"
    - paragraph: Mechatronic Parts
    - img "3d-printing"
    - paragraph: 3D Printing
    - img "cnc-machining"
    - paragraph: CNC Machining
    - img "pcb-layout"
    - paragraph: PCB Layout
    - img "sheet-metal"
    - paragraph: Sheet Metal
    - text: 
    - button "Next slide":
      - generic: 
    - heading "Online PCB Quote" [level=1]
    - link "Instructions For Ordering>":
      - /url: https://jlcpcb.com/help/article/Instructions-for-ordering
    - text: Upload History
    - generic: 
    - text: Add gerber file
    - text: Only accept zip or rar, Max 100 MB,
    - link "View example >":
      - /url: https://jlcpcb.com/help/catalog/180-PCB-Files-Preparation
    - generic: All uploads are secure and confidential.
    - text: Base Material
    - generic: 
    - button "FR-4 FR-4":
      - img "FR-4"
      - text: FR-4
    - button "FR-4 Flex":
      - img "FR-4"
      - text: Flex
    - button "FR-4 Aluminum":
      - img "FR-4"
      - text: Aluminum
    - button "FR-4 Copper Core":
      - img "FR-4"
      - text: Copper Core
    - button "FR-4 Rogers":
      - img "FR-4"
      - text: Rogers
    - button "FR-4 PTFE Teflon":
      - img "FR-4"
      - text: PTFE Teflon
    - text: Layers
    - generic: 
    - button "1"
    - button "2"
    - button "4"
    - generic: High Precision PCB
    - button "6":
      - text: "6"
    - button "8"
    - button "10"
    - button "12"
    - button "14"
    - button "16"
    - textbox "Select": More
    - text: Dimensions
    - generic: 
    - textbox "X": "80"
    - text: "*"
    - textbox "Y": "74"
    - textbox "Select": mm
    - text: PCB Qty
    - generic: 
    - text: "5"
    - text: Product Type
    - generic: 
    - button "Industrial/Consumer electronics"
    - button "Aerospace"
    - button "Medical"
    - heading "PCB Specifications" [level=2]
    - generic: 
    - text: Different Design
    - generic: 
    - button "1"
    - button "2"
    - button "3"
    - button "4"
    - textbox
    - text: Delivery Format
    - generic: 
    - button "Single PCB"
    - button "Panel by Customer"
    - button "Panel by JLCPCB"
    - text: PCB Thickness
    - generic: 
    - button "0.4mm" [disabled]
    - button "0.6mm"
    - button "0.8mm"
    - button "1.0mm"
    - button "1.2mm"
    - button "1.6mm"
    - button "2.0mm"
    - text: PCB Color
    - generic: 
    - button "Green":
      - generic: Green
    - button "Purple":
      - generic: Purple
    - button "Red":
      - generic: Red
    - button "Yellow":
      - generic: Yellow
    - button "Blue":
      - generic: Blue
    - button "White":
      - generic: White
    - button "Black":
      - generic: Black
    - text: Silkscreen
    - generic: 
    - button "White": White
    - text: Material Type
    - generic: 
    - button "FR4 TG135"
    - button "FR4 TG155"
    - button "Nan Ya NP-140F"
    - button "KB6164 - TG135"
    - button "Nan Ya NP-155F"
    - button "KB-6165 - TG155"
    - button "S1141 TG140"
    - button "S1000H TG155"
    - text: Surface Finish
    - generic: 
    - button "OSP"
    - button "HASL(with lead)"
    - button "LeadFree HASL"
    - button "ENIG"
    - text: Gold Thickness
    - generic: 
    - button "1 U\""
    - button "2 U\""
    - heading "High-spec Options" [level=2]
    - generic: 
    - text: Outer Copper Weight
    - generic: 
    - button "1 oz"
    - button "2 oz"
    - text: Inner Copper Weight
    - generic: 
    - button "0.5 oz"
    - button "1 oz"
    - button "2 oz"
    - text: Specify Stackup
    - generic: 
    - button "No"
    - button "Yes"
    - link "Impedance calculator >":
      - /url: https://jlcpcb.com/pcb-impedance-calculator
    - text: Layer Stackup
    - generic: 
    - button "No requirement" [disabled]
    - button "JLC04161H-7628"
    - button "JLC04161H-3313"
    - button "JLC04161H-1080"
    - button "JLC04161H-7628A"
    - button "JLC04161H-3313A"
    - button "JLC04161H-1080A"
    - button "JLC04161H-7628B"
    - button "JLC04161H-2116A"
    - button "JLC04161H-2116B"
    - button "JLC04161H-2116C"
    - button "JLC04161H-7628G"
    - button "JLC04161H-2116"
    - button "JLC04161H-7628E"
    - button "JLC04161H-2116D"
    - button "JLC04161H-7628F"
    - button "JLC04161H-2116E"
    - button "JLC04161H-7628C"
    - button "View Stackup":
      - generic: View Stackup
    - generic: Impedance Control
    - button "No requirement"
    - button "±10% (±5Ω if value≤50Ω)"
    - text:      
    - text: Via Covering
    - generic: 
    - button "Plugged"
    - button "Untented"
    - button "Epoxy Filled & Capped"
    - button "Copper paste Filled & Capped"
    - button "Tented" [disabled]
    - generic: Via Plating Method
    - generic: 
    - button "Not Specified"
    - button "Conductive Adhesive"
    - button "Horizontal Electroless Copper Plating"
    - text: Min via hole size/diameter
    - generic: 
    - button "0.3mm/(0.4/0.45mm)"
    - button "0.25mm/(0.35/0.4mm)"
    - button "0.2mm/(0.3/0.35mm)"
    - button "0.15mm/(0.25/0.3mm)"
    - button "0.1mm/(0.2/0.25mm)" [disabled]
    - text: Board Outline Tolerance
    - generic: 
    - button "±0.2mm(Regular)"
    - button "±0.1mm(Precision)"
    - generic: Confirm Production file
    - generic: 
    - button "No"
    - button "Yes"
    - text: Mark on PCB
    - generic: 
    - button "Remove Mark"
    - button "2D barcode (Serial Number)"
    - text: Electrical Test
    - generic: 
    - button "Flying Probe Fully Test"
    - text: Gold Fingers
    - generic: 
    - button "No"
    - button "Yes"
    - text: Castellated Holes
    - generic: 
    - button "No"
    - button "Yes"
    - text: Press-Fit Hole
    - generic: 
    - button "No"
    - button "Yes (Tolerance +/-0.05mm)"
    - generic: Edge Plating
    - generic: 
    - button "No"
    - button "Yes"
    - generic: Blind Slots
    - generic: 
    - button "No"
    - button "Yes"
    - generic: UL Marking
    - generic: 
    - button "No"
    - button "Yes (Any Position)"
    - button "Yes (Specify Position)" [disabled]
    - generic: Backdrill
    - generic: 
    - button "No"
    - button "Yes" [disabled]
    - generic: Humidity Indicator Card
    - generic: 
    - button "No"
    - button "Yes"
    - heading "Advanced Options" [level=2]
    - generic: 
    - paragraph: 4-Wire Kelvin Test
    - generic: 
    - button "No"
    - button "Yes"
    - paragraph: Paper between PCBs
    - generic: 
    - button "No"
    - button "Yes"
    - paragraph: Appearance Quality
    - generic: 
    - button "IPC Class 2 Standard"
    - button "Superb Quality" [disabled]
    - text: Silkscreen Technology
    - generic: 
    - button "Ink-jet Printing Silkscreen"
    - button "High-precision Printing Silkscreen"
    - button "EasyEDA multi-color silkscreen" [disabled]
    - button "High-definition Exposure Silkscreen" [disabled]
    - paragraph: Package Box
    - generic: 
    - button "With JLCPCB logo"
    - button "Blank box"
    - paragraph: Inspection Report
    - generic: 
    - button "No"
    - button "Final Inspection Report"
    - button "Electrical Test Report"
    - button "ROHS Test Report"
    - text: PCB Remark
    - heading "PCB Assembly" [level=2]
    - link "Assembly cost starting from $0 with coupon>":
      - /url: https://jlcpcb.com/news/free-assembly-1-6-layer-pcb-discount-8-20-layer-pcba
      - text: Assembly cost starting from $0 with coupon>
    - heading "Stencil" [level=2]
    - link "Stencil Order Guide>":
      - /url: https://jlcpcb.com/help/article/instructions-for-stencil-order
    - generic: Order together with PCB
    - list:
      - generic: Charge Details
      - generic: 
      - text: Special Offer
      - generic: $7.00
      - text: Via Covering
      - generic: $0.00
      - text: Surface Finish
      - generic: $17.10
      - text: Material Type
      - generic: $6.96
      - text: Impedance Control
      - generic: $32.84
      - text: Confirm Production file
      - generic: $1.04
      - strong: PCB Build Time
      - generic: 
      - generic: 3-4 days
      - generic: $0.00
      - text: 3 days
      - generic: PCBA Only
      - generic: $0.00
    - separator
    - heading "Calculated Price" [level=2]
    - strong: $64.94
    - paragraph:
      - text: Additional charges may apply for
      - link "special cases":
        - /url: https://jlcpcb.com/help/article/In-what-cases-will-there-be-charged-extra?
    - 'link "Order on JLCONE Desktop: Save $1–$20 Per Order "':
      - /url: https://jlcone.com/download
      - generic: "Order on JLCONE Desktop: Save $1–$20 Per Order"
      - generic: 
    - button "SAVE TO CART" [disabled]:
      - generic: SAVE TO CART
    - heading "Shipping Estimate" [level=2]
    - generic: $27.45
    - generic: 
    - generic "DHL Express (DDP)"
    - generic "2-4 business days"
    - text: Weight
    - generic: 
    - generic: 0.22kg
    - text: Coupons
    - generic: 
    - generic: Save $30.00
    - generic: Save $20.00
    - generic: 
- contentinfo:
  - generic: 
  - text: Online Chat >
  - generic: Chat with our live agent for fast reply.
  - generic: "Mon-Fri: 24 hours, Sat: 9am-6pm, GMT+8"
  - link " Email Us >":
    - /url: https://jlcpcb.com/help/contact
    - generic: 
    - text: Email Us >
  - text: Contact us at support
  - generic: 
  - text: jlcpcb.com
  - generic: Typically reply within hours.
  - link " Help Center >":
    - /url: https://jlcpcb.com/help
    - generic: 
    - text: Help Center >
  - generic: Get instant answers.
  - generic: 24/7 Available.
  - generic: PCB Service
  - link "FR-4 PCBs":
    - /url: https://jlcpcb.com/pcb-fabrication/fr4-pcb
  - link "Flexible PCBs":
    - /url: https://jlcpcb.com/pcb-fabrication/flexible-pcb
  - link "Metal Core PCBs":
    - /url: https://jlcpcb.com/pcb-fabrication/metal-core-pcb
  - link "High-Frequency PCBs":
    - /url: https://jlcpcb.com/pcb-fabrication/high-frequency-pcb
  - link "PCBA Service":
    - /url: https://jlcpcb.com/pcb-assembly
  - link "PCB Layout":
    - /url: https://design.jlcpcb.com
  - link "SMT Stencil":
    - /url: https://jlcpcb.com/pcb-stencil
  - link "Flex Heater":
    - /url: https://flexheater.jlcpcb.com
  - generic: Support
  - link "Help Center":
    - /url: https://jlcpcb.com/help
  - link "Contact Us":
    - /url: https://jlcpcb.com/help/contact
  - link "Shipping Guide":
    - /url: https://jlcpcb.com/shipping
  - link "Payment Methods":
    - /url: https://jlcpcb.com/payments
  - link "How to Order":
    - /url: https://jlcpcb.com/help/catalog/11-How-To-Order
  - link "How to Track":
    - /url: https://jlcpcb.com/help/article/51-How-to-Track-My-Order
  - link "After-Sales Service":
    - /url: https://jlcpcb.com/help/article/How-to-Make-a-Quality-Complaint
  - link "Blog":
    - /url: https://jlcpcb.com/blog
  - generic: Company
  - link "About Us":
    - /url: https://jlcpcb.com/about-us
  - link "Quality Assurance":
    - /url: https://jlcpcb.com/about-us/quality-control
  - link "How We Work":
    - /url: https://jlcpcb.com/about-us/how-it-works
  - link "Certifications":
    - /url: https://jlcpcb.com/certifications
  - link "Security":
    - /url: https://jlcpcb.com/privacy-security
  - link "Environment":
    - /url: https://jlcpcb.com/green-manufacturing
  - link "JLCAPI":
    - /url: https://api.jlcpcb.com/
  - link "News":
    - /url: https://jlcpcb.com/news
  - link "Cooperation":
    - /url: https://jlcpcb.com/cooperation
  - generic: Electronics
  - link "EasyEDA":
    - /url: https://easyeda.com
  - link "JLCPCB":
    - /url: https://jlcpcb.com
  - link "JLCDFM":
    - /url: https://jlcdfm.com
  - link "LCSC":
    - /url: https://www.lcsc.com
  - link "OSHWLAB":
    - /url: https://oshwlab.com/
  - generic: Mechanical
  - link "JLC3DP":
    - /url: https://jlc3dp.com
  - link "JLCCNC":
    - /url: https://jlccnc.com
  - link "JLCMC":
    - /url: https://jlcmc.com
  - generic: 
  - generic: Order on JLCONE Desktop, Save $1–$20 Every Time
  - link " Windows":
    - /url: https://jlcone.com/download
    - generic: 
    - generic: Windows
  - link " MAC":
    - /url: https://jlcone.com/download
    - generic: 
    - generic: MAC
  - link " Android":
    - /url: https://jlcone.com/download#mobile-app
    - generic: 
    - generic: Android
  - link " IOS":
    - /url: https://jlcone.com/download#mobile-app
    - generic: 
    - generic: IOS
  - generic: CONNECT WITH US
  - link "":
    - /url: https://www.facebook.com/jlcpcb
    - generic: 
  - link "":
    - /url: https://twitter.com/jlcpcb
    - generic: 
  - link "":
    - /url: https://www.instagram.com/jlcpcb
    - generic: 
  - link "":
    - /url: https://www.youtube.com/JLCPCB
    - generic: 
  - link "":
    - /url: https://www.linkedin.com/company/jlcpcb
    - generic: 
  - link "":
    - /url: https://www.reddit.com/r/JLCPCBLab/
    - generic: 
  - generic: © 2026 JLCPCB.COM All Rights Reserved.
  - link "Privacy Policy":
    - /url: https://jlcpcb.com/help/article/Privacy-Policy
  - link "Terms & Conditions":
    - /url: https://jlcpcb.com/help/article/Terms-%26-Conditions
  - link "Cookies Policy":
    - /url: https://jlcpcb.com/help/article/JLCPCB-Cookie-Notice
- iframe

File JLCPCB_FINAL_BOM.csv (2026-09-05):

Category | Design | Reference | Description | Manufacturer | MPN | JLCPCB/LCSC Part # | Required Qty | Buy/Reserve Qty | Assembly route | Procurement status | Stock snapshot (2026-08-13 KST) | Notes | Source
PCBA | all four fixture boards | T1-T4 / T1-T2 | 1:2 impedance-ratio RF transformer; 50 ohm unbalanced to nominal 100 ohm balanced | Mini-Circuits | ADT2-1T+ | C5223988 | 12 | 12 plus JLC quote attrition | JLC SMT; Extended | ORDERABLE | JLC 159 | RJ45 boards need 8 and slip-ring endpoint boards need 4; do not substitute a different turns ratio or footprint | https://jlcpcb.com/partdetail/MiniCircuits-ADT2_1T/C5223988
PCBA | balun_eth_rj45 x2 | J1 | CAT6 shielded RJ45 jack without LEDs or magnetics | Amphenol Communications Solutions | RJE591885401 | C5386678 | 2 | 2 plus JLC quote attrition | JLC THT wave solder; fixture charge may apply | ORDERABLE | JLC 11 | Use only the no-magnetics part; this stock snapshot is sufficient for two boards but must be rechecked at checkout | https://jlcpcb.com/partdetail/AmphenolICC-RJE591885401/C5386678
PCBA | balun_eth_rj45 x2 | TP1,TP2 | Loop test point; 1.02 mm recommended hole | Keystone Electronics | 5001 | C238122 | 4 | 4 plus JLC quote attrition | JLC THT wave solder; fixture charge may apply | ORDERABLE_WITH_HOLE_REVIEW | JLC 3043 | Vendor nominal mounting hole is 1.02 mm while the local standard footprint drill is 1.00 mm; confirm finished-hole tolerance and retention or trial-fit a sample before approving assembly | https://jlcpcb.com/partdetail/Keystone-5001/C238122
MANUAL | balun_eth_rj45 x2 and all CT options | RSH1 plus optional RCT1-RCT4 / RCT1-RCT2 | 0 ohm 0805 jumper, 125 mW | UNI-ROYAL | 0805W8F0000T5E | C17477 | 1 fitted for baseline; 12 optional for CT-GND | 100 loose pieces or current seller pack/MOQ | Hand solder after board identity is fixed | ORDERABLE | JLC 7971216 | All PCBA jobs leave RSH/RCT empty for the CT-FLOAT baseline; hand-fit one RSH1 only on the RJ45 Port-1 board. The same pack supplies all 12 RCT positions for an optional all-at-once CT-GND experiment | https://jlcpcb.com/partdetail/0805W8F0000T5E/C17477
PCBA | all four fixture boards | J2-J5 / J2,J3 | 50 ohm SMA jack edge mount, DC to 6 GHz; 1.6 mm PCB recommendation | MyAntenna | A-SMA-KE-16.5A | C22467617 | 12 | 12 plus JLC quote attrition | JLC Standard PCBA wave solder; high assembly difficulty/fixture review | ORDERABLE_WITH_PCBA_REVIEW | JLC 491 | One exact SMA type across every board. Confirm checked-in land pattern, board-edge seating, connector orientation and JLC fixture/engineering remarks in all three PCBA jobs; no automatic substitution | https://jlcpcb.com/partdetail/MyAntenna-A_SMA_KE_165A/C22467617
PCBA | balun_slipring/molex_end x1 | J1 | Micro-Lock Plus 1.25 mm vertical 5-pin PCB header candidate | Molex | 5055680571 | C585386 | 1 | Buy 1-3 loose validation samples now; reserve PCBA quantity only after validation | JLC SMT; Extended | HOLD_PCBA_VALIDATE_SAMPLE | JLC 653 | Molex officially identifies this header as mating with the 505565 series, but applying slide-15 housing 5055650501 to the slide-14 REV-504 pin map is a cross-slide inference. Verify actual mating, key, pin 1 and 1:1 land pattern first | https://jlcpcb.com/partdetail/MOLEX-5055680571/C585386
PCBA | balun_slipring/m12_end x1 | J1 | M12 A-coded 8-pin female PCB connector candidate | Finecables | MB12FBAFF08ST-3 | C22378785 | 1 | Source one loose validation sample/preorder after drawing-level mechanical review; PCBA quantity remains HOLD | JLC THT wave solder after approval | HOLD_PCBA_VALIDATE_SAMPLE | JLC 0 | Manufacturer female 8P PCB geometry is corrected in CAD. Verify suffix, mating-face pin view, A-key/pin 1, PCB B-side placement versus front-fastened panel/nut access, cable direction and 1:1 fit before PCBA | https://jlcpcb.com/partdetail/FINECABLES-MB12FBAFF08ST3/C22378785
ALT_SAMPLE | balun_slipring/m12_end redesign only | J1 alternative | M12 A-coded 8-pin female straight PCB connector; non-drop-in redesign candidate | CAZN | M12-S8A-GPB M12 | C19108981 | 0 in current design | 0 now; optionally buy 1 loose sample after the mechanical direction is chosen | Never substitute into current BOM/CPL; new footprint and routing required | HOLD_REDESIGN_CANDIDATE | JLC 31; LCSC 30 | Front-mount M12x1/D-cut/ring mechanics differ from the Finecables PG9/front-fastened panel plus PCB B-side candidate and supported PCB thickness is not specified. A sample can inform a redesign only | https://jlcpcb.com/partdetail/CAZN-M12_S8A_GPBM12/C19108981
DNP | all four fixture boards | all RCT | Optional center-tap-to-GND links | UNI-ROYAL | 0805W8F0000T5E | C17477 | 0 fitted baseline; 12 board positions | 0 additional; use the loose pack above only if CT-GND is intentionally tested | DNP on every PCBA job | DNP_NO_BUY | JLC 7971216 | CT-FLOAT is the measurement baseline. Never populate only one end or one pair; CT-GND requires all relevant RCT positions on both fixtures at once and a new REF baseline | https://jlcpcb.com/partdetail/0805W8F0000T5E/C17477
DNP | balun_eth_rj45 x2 | CSH1 | Optional 1 nF / 2 kV AC shield bond |  |  |  | 0 fitted baseline; 2 board positions | 0 | DNP | DNP_NO_BUY | not selected | No component is selected for the base order. If this experiment is added later, remove RSH1 on that board first and separately qualify voltage rating, package creepage and availability
MECHANICAL | all four fixture boards | H1-H4 | M3 non-conductive supports and fasteners |  |  |  | 16 support positions | TBD after fixture-plate and standoff-height decision | External mechanical hardware; not PCBA | HOLD | not selected | CAD references are H1-H4 on each board. Mounting holes are non-plated; avoid an uncontrolled chassis path and select nylon or another non-conductive system after fixture geometry is known
REF_HARNESS | balun_slipring REF/bypass | cable-end housing | Micro-Lock Plus 1.25 mm 5-circuit receptacle housing candidate | Molex | 5055650501 | C564750 | 1 | Buy 5 at current LCSC MOQ only after or alongside loose mating validation | External harness; hand assembly | HOLD_CROSS_SLIDE_PIN_VERIFY | LCSC 9310; MOQ 5 | The exact MPN appears on slide 15 for a separate fourth-generation cable, not directly on the slide-14 REV-504 map. Use four populated circuits and leave cavity 5 empty only after actual housing/key/pin-1 verification | https://www.lcsc.com/product-detail/C564750.html
REF_HARNESS | balun_slipring REF/bypass | housing contacts 1-4 | Micro-Lock Plus female crimp terminal, matte tin, 30-26 AWG | Molex | 5054311000 | C385112 | 4 fitted plus validation/rework | Buy 100 at current LCSC MOQ; allocate at least 8-12 contacts | Qualified hand crimp and pull test | HOLD_SAMPLE_CRIMP | LCSC 208000; MOQ 100 | Terminal insulation range is 0.78-1.02 mm. Use at least four contacts for sample crimp/pull inspection, four for the final harness and keep rework spares; verify crimp height, retention and continuity before assembly | https://www.lcsc.com/product-detail/C385112.html
REF_HARNESS | balun_slipring REF/bypass | M12 cable end | M12 A-coded 8-position male field-installable plug, 4-6 mm gland | NorComp | 858FA08-103RAU1 | 37-858FA08-103RAU1-ND | 1 | Buy 1 plus optional spare | External harness; screw termination | HOLD_MATING_VERIFY | DigiKey 33 | The plug is electrically suitable for the selected cable. Verify mating key, pin-1 view and continuity against the actual M12 endpoint before final assembly | https://www.digikey.com/en/products/detail/norcomp-inc/858FA08-103RAU1/16633408
REF_HARNESS | balun_slipring REF/bypass | two-pair cable | Flexible Cat.5e SF/UTP cable, 2 pairs, 26 AWG stranded, nominal 100 ohm | LAPP | 2170284 | 2181-2170284-ND | cut to measured DUT connector-to-connector length | Buy 1 m or 3 ft minimum plus termination allowance | External harness; cut after DUT measurement | HOLD_LENGTH_AND_CRIMP | DigiKey cut-length stock 3945 ft | Cable OD 5.6 +/-0.3 mm fits the 4-6 mm M12 gland. Core OD can reach 1.04 mm versus the Molex terminal 1.02 mm limit, so sample-crimp acceptance is mandatory. Keep pair twists to the terminals and leave the overall shield insulated at both ends | https://www.lapp.com/en_US/us/etherline-cat-5e-flex/p/2170284
EXTERNAL | shared measurement kit | six unused SMA ports maximum | 50 ohm SMA male termination, DC to 18 GHz, 1 W | Mini-Circuits | ANNE-50+ | C6125302 | 6 identical | Buy 6; buy 5 only if the existing unit is confirmed genuine ANNE-50+ and passes inspection | External screw-on accessory; not PCBA | EXTERNAL_ORDER | Mini-Circuits more than 1000; LCSC 0 | RJ45 measurement exposes eight SMA ports and a 2-port VNA uses two, so six loads are required for IL/RL, NEXT and FEXT. The slip-ring fixture needs two and shares this same six-piece set. Do not mix an unknown existing load into the matched set | https://www.minicircuits.com/WebStore/dashboard.html?model=ANNE-50%2B
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

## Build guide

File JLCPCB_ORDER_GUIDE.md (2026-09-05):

# JLCPCB/LCSC 최종 구매·조립 가이드

> **현재 주문 기준은 [2026-09-05 화면별 주문 가이드](docs/jlcpcb/README.md)와 [새 임피던스 검증](docs/jlcpcb/IMPEDANCE.md)이다.** 아래는 이전 구매 기록이며 현 CAD의 폭/간격·옵션·총수량에 사용하지 않는다.

> **2026-09-05 적용 범위 변경:** 아래의 구매·조립 조건과 날짜별 “최신” 안내는 이전 전용 balun 구성의 기록이다. 현재 설계는 [설계 검토 인계](DESIGN_REVIEW_HANDOFF.md), 새 어댑터 제작 조건은 [adapters/JLCPCB_BUILD](adapters/JLCPCB_BUILD.md)를 따른다. 이번 구성의 통합 발주 수량표/BOM은 아직 갱신하지 않았으며, 아래 수량을 그대로 합산하거나 발주에 사용하지 않는다. 기존 구매의 집행·취소 여부는 이 문서 변경으로 판단하지 않는다.

> **2026-09-03 최신 구매 상태:** PCB는 JLCPCB에서 미조립 제작, 부품은 DigiKey 한국 중심(국내 인두팁만 예외)으로 구매한다. 실사용 Molex 2 + RJ45 4 + LLC 2 = 8장, 제작 예산 3종×5장=15장. 슬립링 M12 암 보드/암커넥터는 기존 케이블→RJ45 개조로 제외하며 LLC M12 수커넥터는 사내품 사용이다. **사내 수커넥터의 PCB 삽입은 사용자 확인 완료**이고 전기적 핀맵/수량 확인은 별도다. Samtec SMA는 구매 후보이며 현 CAD/MyAntenna와 최종 두께·공차/제조파일 정합 승인 전이다. 아래 이전 PCBA/구매 수량·품번은 발주에 사용하지 말고 [최신 구매요청서](PURCHASE_REQUEST_FORM_DRAFT_2026-09-03.md)를 따른다. 이번에 PCB/회로/풋프린트는 변경하지 않았다.

> **최신 조립 방식: 사내 손납땜.** 아래 PCBA 구매 계획은 변경 전 기록이다. 미조립 PCB, 개별 부품 구매 링크, 사진으로 확인한 HAKKO 936/907용 팁 및 기존 goot BS-15의 PCB 사용 금지 사항은 [`HAND_ASSEMBLY_PURCHASE_2026-09-03.md`](HAND_ASSEMBLY_PURCHASE_2026-09-03.md)를 따른다. JLC 부품 Pre-order는 한국으로 받을 손납땜용 부품 구매 경로가 아니다. 기존 제조 HOLD는 그대로 유지한다.

> **2026-09-03 발주 범위 변경:** 최신 계획은 슬립링 2세트 4장 + RJ45 2세트 4장 + LLC 전용 M12 2장, 총 PCBA 10장이다. LLC 측정에는 기존 RJ45 보드를 공유한다. 부품 납땜은 업체에 맡기며 RSH1도 지정 상태로 조립해 납품하도록 요청한다. 현재 수량·조립 variant·승인 조건은 [`PCBA_PURCHASE_SCOPE_2026-09-03.md`](PCBA_PURCHASE_SCOPE_2026-09-03.md)가 우선한다. [LLC PCB DRAFT A](balun_llc16/README.md)는 수커넥터 선정, 배치·배선 및 ERC/DRC/parity 검증을 완료했지만 JLC 조달·조립과 패널 기구 승인은 HOLD이며 제조 Gerber/BOM/CPL은 아직 없다. 이 문서 아래의 4장 검산값과 수동 RSH1 작업 방식, 기존 합산 CSV 및 2026-09-01 RJ45 2장 견적은 신규 발주 자료가 아니다. 기존 Gerber/BOM/CPL을 무검토 재사용하지 않는다.

아래는 기존 4장 비교 구성의 기술·조달 참고 기록이다. [`JLCPCB_FINAL_BOM.csv`](JLCPCB_FINAL_BOM.csv)도 다음 4장 구성을 기준으로 한다.

PCB 적층, 실제 선폭/간격, JLC 공식 field-solver 결과와 주문 production-file 승인 기준은 [`JLCPCB_IMPEDANCE_VERIFICATION_2026-08-31.md`](JLCPCB_IMPEDANCE_VERIFICATION_2026-08-31.md)를 함께 따른다.

- `balun_eth_rj45` 2장
- `balun_slipring/molex_end` 1장
- `balun_slipring/m12_end` 1장
- 두 프로젝트가 공유하는 동일한 외부 50 Ω SMA 종단기 6개
- 두 VNA cable end를 잇는 SMA female-female calibration thru 1개

루트 CSV는 전체 구매 수량을 합친 표이지 **JLCPCB 업로드용 BOM이 아니다**. 세 PCB 설계는 Gerber, 좌표와 connector reference가 서로 다르므로 다음 세 PCBA 작업으로 나눠야 한다.

1. `balun_eth_rj45`: 동일 artwork 2장
2. `balun_slipring/molex_end`: 1장
3. `balun_slipring/m12_end`: 1장

각 작업에서 해당 설계의 Gerber, BOM, CPL을 따로 생성하고 검토한다. JLC BOM에는 최소한 Comment, Designator, Footprint, JLCPCB/LCSC part number가, CPL에는 Designator, X/Y, Rotation, Layer가 필요하다. 루트의 합산 CSV를 세 작업 중 어느 하나의 BOM으로 업로드하지 않는다.

재현 가능한 산출물은 [`export_jlc_release.ps1`](export_jlc_release.ps1)로 만든다. 기본 실행은 세 프로젝트의 staged ERC/DRC/parity를 모두 검사하되 RJ45 release candidate만 Gerber ZIP과 DNP-excluded JLC-format BOM/CPL을 생성하며, 두 slip-ring 프로젝트는 HOLD notice만 만든다. 자세한 사용법은 [`RELEASE_EXPORT.md`](RELEASE_EXPORT.md)를 따른다.

아래는 JLC 견적에서 더해질 attrition이나 최소 작업 수량을 제외한 1세트 검산값이다.

| 선정 부품 | 1세트 필요 수량 |
| --- | ---: |
| `ADT2-1T+` | 12 |
| `A-SMA-KE-16.5A` | 12 |
| `RJE591885401` RJ45 | 2 |
| Keystone `5001` test point | 4 |
| Molex `5055680571` 후보 | 1, HOLD |
| Finecables `MB12FBAFF08ST-3` 후보 | 1, HOLD |
| `C17477` 0 Ω | baseline RSH용 1; 선택형 RCT 위치 12 |
| REF Molex `5055650501` / `5054311000` | housing 1, contact 4; 각 판매 MOQ 5/100 |
| REF M12 male `858FA08-103RAU1` | 1, mating/pin-1 HOLD |
| REF cable LAPP `2170284` | 실측 완성 길이 + 종단 여유 |
| M3 비도전성 지지점 | 16, 높이/구조 TBD |
| 외부 `ANNE-50+` 종단기 | 동일품 6 |
| `SF-SF50+` calibration thru | 1 |

위 보드 수량은 지그에 실제 필요한 수량이다. JLC 주문 화면에서 더 큰 제작·조립 수량을 요구하면 설계별 FIT/DNP 기준은 그대로 유지하고, 추가 PCB와 부품 attrition 수량을 최종 견적에 명시해 확인한다.

## 현재 발주 판단

이 저장소 전체는 아직 **그대로 결제 가능한 turnkey package가 아니다**. `ORDERABLE` 부품은 정확한 MPN과 JLC/LCSC 번호가 선정되었다는 뜻이고, 아래의 실물·기구 차단 항목까지 해제되었다는 뜻은 아니다. `HOLD` 행은 full PCBA 수량에 투입하지 않는다.

기본 조립 상태는 `CT-FLOAT`다.

- 네 보드의 모든 RCT를 DNP로 둔다.
- RJ45 두 보드의 `CSH1`을 모두 DNP로 둔다.
- 동일 artwork로 발주하는 RJ45 두 보드의 `RSH1`도 PCBA에서는 모두 DNP로 둔다. 입고 후 Port-1 보드를 식별·표기하고 그 보드의 `RSH1` 한 곳만 `C17477` 0 Ω로 수동 장착한다.
- 한 보드에서 `RSH1`과 `CSH1`을 동시에 장착하지 않는다.
- `ADT2-1T+`는 총 12개 모두 FIT한다.
- HOLD connector는 해당 검증이 끝난 뒤에만 정확한 MPN으로 FIT한다.

Transformer는 반드시 RoHS `ADT2-1T+`와 JLC `C5223988` 조합으로 확인한다. Mini-Circuits의 `+` 없는 `ADT2-1T`는 2025 EOL 공지에서 `ADT2-1T+`로 교체된 모델이며, `ADT2-1T+` 자체는 2026-08-31 공식 페이지에서 current stock 1,000개 초과로 표시됐다. URL이나 BOM에서 `+`가 빠진 비RoHS 구형 모델과 혼동하지 않는다.

RSH1을 공통 PCBA BOM에서 제외하면 동일한 RJ45 artwork 두 장에 서로 다른 assembly variant를 억지로 섞지 않아도 된다. 나중에 `CT-GND`를 별도로 시험하려면 양 끝의 관련 RCT를 전부 동시에 장착하고 REF/bypass baseline부터 다시 측정하며, 결과를 다른 공통모드 경계조건으로 표시한다.

## 외부 50 Ω 종단기와 케이블

Mini-Circuits `ANNE-50+` SMA-male 종단기 동일품 6개를 사용한다. RJ45 지그 두 장에는 SMA jack이 총 8개이고 2-port VNA가 2개를 사용하므로 IL/RL, NEXT, FEXT 측정에서 나머지 6개를 모두 종단해야 한다. 슬립링 endpoint 두 장에는 SMA가 총 4개라 두 개만 필요하므로 동일한 6개 세트를 공유한다.

가장 안전한 구매 수량은 신규 동일품 6개다. 기존 종단기가 정품 `ANNE-50+`로 명확히 식별되고 손상 없이 측정 세트에 사용할 수 있다고 확인된 경우에만 신규 5개를 산다. 그 외에는 기존 미확인품을 예비품으로 두고 crosstalk 측정 세트에 섞지 않는다. 조회 시 LCSC `C6125302`는 재고 0이었고 Mini-Circuits direct는 1,000개 초과 재고를 표시했다.

검증된 coax 2개가 없다면 Mini-Circuits `CBL-2FT-SMSM+` 동일품 2개를 추가한다. 이는 PCB 부품이 아닌 선택형 계측 액세서리다. 조회 시 LCSC `C18117095`는 재고 0, Mini-Circuits direct는 100개 초과였다. NEXT/FEXT에서는 cable-to-cable leakage가 측정 바닥값이 될 수 있으므로 두 케이블의 배치, 간격, 굽힘과 connector torque를 REF/DUT 사이에 고정한다.

동봉된 Open/Short/50 Ω Load는 각각 하나씩이어도 Port 1과 Port 2에 순차 재사용할 수 있다. 그러나 두 SMA-male cable end의 thru 측정이 빠지면 full 2-port SOLT가 아니므로 Mini-Circuits `SF-SF50+` 같은 SMA female-female thru 1개를 추가한다. LibreVNA에서는 `SOLT_12`를 활성화한다. 측정 중 unused balanced port는 각 balun을 통해 SMA 쪽 50 Ω load가 nominal 100 Ω differential termination으로 보이므로 별도 100 Ω 종단기를 자작할 필요가 없다.

## 해제해야 할 차단 항목

### 선정 SMA의 PCBA 검토

모든 보드의 SMA 12개는 MyAntenna `A-SMA-KE-16.5A`, JLC/LCSC `C22467617`로 통일한다. 권장 PCB 두께 `1.6 ±0.05 mm`는 nominal 1.5862 mm 적층과는 맞지만, JLCPCB의 일반 1.6 mm 완성 두께 공차 `±10%`(약 1.44–1.76 mm)는 connector 권장 범위보다 훨씬 넓다. 따라서 nominal 일치만으로 slot fit을 승인하지 말고 첫 소량 bare PCB와 loose SMA를 sample-fit하며, 필요하면 JLC engineering에 tighter thickness control 가능 여부를 확인한다. catalog 정격은 50 Ω / DC–6 GHz다. JLC에는 Standard-PCBA-only, wave solder, assembly difficulty High로 등록되어 있으며 조회 재고는 491개였다.

세 PCBA 작업에서 checked-in footprint/launch가 제조사 land pattern과 같은지, body가 routed board edge에 제대로 안착하는지, connector가 모두 바깥쪽을 향하는지, JLC가 wave-solder fixture/engineering 비고를 승인하는지 확인한다. 자동 대체품은 승인하지 않는다. 기존 Amphenol `132289` / `C3172723`은 PCB 두께 상한 1.57 mm가 선정 적층보다 작으므로 최종 BOM에서 제외한 legacy 부품이다.

### 슬립링 connector와 핀맵

Molex `5055680571` / `C585386`은 catalog와 footprint가 정의된 5핀 header이고 제조사 도면은 `505565` series와의 mating을 명시한다. 다만 `5055650501`이라는 정확한 housing MPN은 2세대 핀맵 슬라이드 14가 아니라 별도 4세대 표인 슬라이드 15에서 확인되므로, 이를 `REV-504`에 적용한 것은 **교차 슬라이드 추론**이다. endpoint PCBA 전에 loose sample로 실제 REV-504와의 체결, key 방향, pin 1, pad numbering과 1:1 footprint 출력을 확인한다.

Finecables `MB12FBAFF08ST-3` / `C22378785`는 조회 시 JLC 재고 0이라 global sourcing 또는 preorder가 필요하다. 제조사 female 8P 권장 PCB 배열은 로컬 footprint에 반영했지만, 조달 전에 정확한 suffix, mating-face view, A-key와 pin 1, PCB B면 배치와 제조사의 front-fastened panel/nut 접근, cable exit를 실물 DUT에 대조한다. `balun_slipring/PINMAP.md`의 Ethernet 4선 continuity 측정도 완료한다. 따라서 transformer와 SMA를 조달할 수 있더라도 이 두 검증 전에는 슬립링 PCBA 두 작업 모두 HOLD다.

REF/bypass harness는 Molex `5055650501` housing, `5054311000` contact 4개, NorComp `858FA08-103RAU1` M12 A-code male plug과 LAPP `2170284` 2-pair 100 Ω Cat.5e cable로 선정했다. Cable OD 5.6 ±0.3 mm는 M12 plug의 4–6 mm gland에 들어가지만, cable core 최대 Ø1.04 mm가 Molex terminal 상한 Ø1.02 mm보다 0.02 mm 큰 최악 공차가 있다. 따라서 최소 4개 contact는 sample crimp/pull/단면 또는 치수 검증에 쓰고, 최종 harness 4개와 재작업 spare를 별도로 확보한다(권장 사용계획 8–12개; 판매 MOQ 100개면 수량상 충족). 완성 cable 길이는 DUT의 connector-to-connector 실측 후 정하고, 전체 shield/drain은 CT-FLOAT baseline에서 양단 모두 절연한다.

재고가 있는 CAZN `M12-S8A-GPB M12` / `C19108981`은 drop-in 대안이 아니다. 조회 재고는 JLC 31개/LCSC 30개였지만, 이 부품은 straight PCB front-mount M12x1/D-cut/ring 구조이고 현재 Finecables 후보의 PG9/front-fastened panel 및 PCB B면 후보 기구와 footprint가 다르며 지원 PCB 두께도 명시되지 않았다. 기구 방향을 먼저 결정한 뒤 필요하면 loose sample 1개만 구매해 **재설계 후보**로 평가한다. 현재 BOM/CPL에서 Finecables 부품 대신 자동 매칭하거나 실장하지 않는다.

### Controlled impedance와 최종 DFM

상세 근거와 계산값은 [`JLCPCB_IMPEDANCE_VERIFICATION_2026-08-31.md`](JLCPCB_IMPEDANCE_VERIFICATION_2026-08-31.md)를 따른다. 각 제작 작업의 JLC 주문 화면에는 아래 값을 고정한다.

| 항목 | 주문값 |
| --- | --- |
| Layers / PCB Thickness | `4 / 1.6 mm` |
| FR-4 material | `Nan Ya NP-155F` |
| Outer / Inner Copper | `1 oz / 0.5 oz` |
| Surface Finish | `ENIG` |
| Specify Stackup | `Yes` |
| Stackup | `JLC04161H-7628 (Standard)` |
| Controlled impedance | `Impedance Control = ±10% (±5Ω if value≤50Ω)`; `Specify Stackup = Yes`와 아래 Remark도 함께 유지 |
| Via Covering | released Gerber는 via mask coverage의 최종 권위. 2026-09-01 quote UI에서 `Tented`가 disabled이고 `Plugged`가 자동 선택되므로, 그 상태에서는 `Plugged`를 유지하되 `Confirm Production File`에서 모든 stitching via가 solder-mask covered인지 확인. `Plugged`는 tented + solder-mask ink-filled 공정이며 이 보드의 RF 기능 변경 사유가 아님 |
| Electrical Test | `Flying Probe Fully Test` |
| Confirm Production File | `Yes` |
| Gold Fingers / Castellated / Edge Plating | 모두 `No` |

공개 JLC guide의 solder-mask 조건에서는 50 Ω `W=0.35 mm`가 `49.9328 Ω`, 100 Ω 차동 `W/S=0.23/0.22 mm`가 `100.1103 Ω`다. 2026-08-31 live API의 다른 mask snapshot에서도 각각 `49.9955 Ω`, `100.2795 Ω`로 사실상 같은 결론이다. 다만 실제 주문 시점 live calculator와 승인된 stack snapshot이 최종 authority이므로 결과 화면/PDF와 stack revision을 release 자료에 보관한다.

저장된 중앙 core Dk 4.36은 공식 공개 guide 4.43 및 당시 live template API 4.38과 서로 다르다. 현재 외층 전송선 계산에는 중앙 core가 직접 들어가지 않고 공식 값끼리도 일치하지 않으므로 CAD를 임의 수정하지 않는다. 다른 stack으로의 자동 대체, controlled 선폭 변경, stack 이름이 없는 production file은 승인하지 않는다.

PCB Remark에는 세 작업 모두 아래 문장을 그대로 입력한다. Gerber ZIP 내부 메모만으로 대신하지 않는다.

```text
Controlled impedance: 50 ohm single-ended W=0.35 mm and 100 ohm differential W/S=0.23/0.22 mm on L1/L4 referenced to L2/L3. Use JLC04161H-7628 only. Do not substitute stackup or modify controlled trace widths. Edge-launch SMA pads intentionally reach the routed board edge; do not pull back, trim, or move these pads. Please provide the production file for approval before fabrication.
```

Gerber는 모든 작업에서 zone refill을 강제하는 `--check-zones` 옵션으로 생성하고, In1/In2 Gerber에 실제 GND region polygon이 있는지 CAM에서 확인한다. DRC 보고서가 0이어도 미충전 zone outline만 저장된 PCB에서 옵션 없이 Gerber를 내보내면 plane 없는 파일이 성공 코드로 생성될 수 있다.

모든 SMA launch pad는 connector가 routed edge에 끼워지도록 의도적으로 Edge.Cuts까지 닿는다. 일반 copper-to-edge cleanup으로 pull-back/trim하면 안 된다. `Confirm Production File = Yes`로 받은 CAM에서 edge pad, outline, GND plane, drill과 controlled widths를 확대 대조하고, 차이가 있으면 승인하지 않는다.

RJ45, M12, SMA와 test point는 wave solder/fixture 비용이 생길 수 있다. JLC 3D/placement viewer에서 side와 rotation을 직접 검토하고 모든 part match를 수동 확인한다. catalog 재고가 있다는 사실만으로 local footprint, 실장면과 방향이 승인되는 것은 아니다.

네 보드에는 각각 NPTH M3 hole이 4개 있지만 fixture plate와 필요한 standoff 높이가 정해지지 않았다. 따라서 나사·spacer는 전기 BOM에서 임의 선정하지 않고 mechanical HOLD로 남긴다. 기구가 확정되면 nylon 등 비도전성 부품을 우선 사용해 의도하지 않은 chassis/ground 경로가 생기지 않도록 한다.

## 권장 주문 순서

1. `ANNE-50+` 6개와 `SF-SF50+` thru 1개를 주문한다. 기존 종단기가 위의 exact-part 예외를 만족할 때만 신규 load를 5개로 줄인다. 필요하면 `CBL-2FT-SMSM+` 2개도 주문한다.
2. `A-SMA-KE-16.5A` 12개와 JLC 견적이 계산한 attrition을 reserve하고 Standard PCBA의 wave 방향·fixture 비고를 명시적으로 검토한다.
3. RJ45 작업의 stack, impedance, design-specific BOM/CPL을 확인하고 RCT/CSH/RSH는 모두 PCBA DNP로 둔다. 위 PCB Remark를 입력하고 `Confirm Production File = Yes`를 선택한다.
4. Molex `5055680571`은 1–3개 loose validation sample을 확보하고, Finecables M12는 기구 도면 검토 뒤 최소 1개 sample/preorder를 확보해 REV-504/M12 continuity와 기구 검증을 완료한다. 완료 전에는 PCBA 수량이나 대체품을 확정하지 않는다.
5. REF harness의 contact/cable sample crimp 4개 이상과 M12 mating/pin-1을 통과시킨 뒤 DUT 실측 길이로 제작한다.
6. 각 HOLD를 해제한 뒤 해당 설계의 Gerber/BOM/CPL을 다시 생성하고 ERC, DRC, schematic–PCB parity와 JLC placement/DFM을 결제 전에 재확인한다. JLC production file에서 `JLC04161H-7628`, 선폭/간격, SMA edge pad와 plane을 확인하고 자동 대체 또는 CAM 수정을 승인하지 않는다.
7. 첫 소량 bare PCB에서 완성 두께를 측정하고 `A-SMA-KE-16.5A`를 sample-fit한다. fit 또는 edge launch가 불안정하면 full PCBA 전에 JLC engineering 및 connector 대안을 검토한다.
8. 입고 후 첫 조립품을 continuity 검사하고, 표시한 RJ45 Port-1 지그에만 `RSH1`을 수동 장착한 뒤 `CT-FLOAT` REF baseline을 만든다.

CSV의 재고는 **2026-08-13 KST** 조회 스냅샷이다. 주문 직전 다시 확인해야 하며, JLC가 실제 FIT 수량에 component attrition을 더할 수 있다.

## 선정 부품과 발주 자료

- [JLCPCB 적층·임피던스 제조 검증 — 2026-08-31](JLCPCB_IMPEDANCE_VERIFICATION_2026-08-31.md)
- [JLCPCB PCB Impedance Calculator](https://jlcpcb.com/pcb-impedance-calculator/)
- [JLCPCB Impedance Calculator Guide](https://jlcpcb.com/help/article/user-guide-to-the-jlcpcb-impedance-calculator)
- [JLCPCB Impedance Stackup](https://jlcpcb.com/impedance)
- [JLCPCB PCB Capabilities](https://jlcpcb.com/capabilities/pcb-capabilities)
- [JLCPCB KiCad BOM/CPL format](https://jlcpcb.com/help/article/how-to-generate-the-bom-and-centroid-file-from-kicad)
- [JLCPCB component matching rules](https://jlcpcb.com/help/article/component-matching-guidelines-for-pcba-orders)
- [JLCPCB assembly fixtures](https://jlcpcb.com/help/article/pcb-assembly-fixtures)
- [Mini-Circuits ADT2-1T+ / C5223988](https://jlcpcb.com/partdetail/MiniCircuits-ADT2_1T/C5223988)
- [Amphenol RJE591885401 / C5386678](https://jlcpcb.com/partdetail/AmphenolICC-RJE591885401/C5386678)
- [Keystone 5001 / C238122](https://jlcpcb.com/partdetail/Keystone-5001/C238122)
- [UNI-ROYAL 0805W8F0000T5E / C17477](https://jlcpcb.com/partdetail/0805W8F0000T5E/C17477)
- [MyAntenna A-SMA-KE-16.5A / C22467617](https://jlcpcb.com/partdetail/MyAntenna-A_SMA_KE_165A/C22467617)
- [Molex 5055680571 / C585386](https://jlcpcb.com/partdetail/MOLEX-5055680571/C585386)
- [Finecables MB12FBAFF08ST-3 / C22378785](https://jlcpcb.com/partdetail/FINECABLES-MB12FBAFF08ST3/C22378785)
- [CAZN M12-S8A-GPB M12 / C19108981 — 재설계 후보만](https://jlcpcb.com/partdetail/CAZN-M12_S8A_GPBM12/C19108981)
- [Molex 5055650501 housing / C564750](https://www.lcsc.com/product-detail/C564750.html)
- [Molex 5054311000 terminal / C385112](https://www.lcsc.com/product-detail/C385112.html)
- [NorComp 858FA08-103RAU1 M12 male cable plug](https://www.digikey.com/en/products/detail/norcomp-inc/858FA08-103RAU1/16633408)
- [LAPP 2170284 2-pair Cat.5e cable](https://www.lapp.com/en_US/us/etherline-cat-5e-flex/p/2170284)
- [Mini-Circuits ANNE-50+ datasheet](https://www.minicircuits.com/pdfs/ANNE-50%2B.pdf) / [구매 페이지](https://www.minicircuits.com/WebStore/dashboard.html?model=ANNE-50%2B)
- [Mini-Circuits CBL-2FT-SMSM+ 구매 페이지](https://www.minicircuits.com/WebStore/dashboard.html?model=CBL-2FT-SMSM%2B)
- [Mini-Circuits SF-SF50+ SMA female-female thru](https://www.minicircuits.com/WebStore/dashboard.html?model=SF-SF50%2B)

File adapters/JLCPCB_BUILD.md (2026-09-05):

# JLCPCB 제작·조립 기준

현재 수동 어댑터 3종에 대한 제작 초안이다. [설계 검토 인계](../DESIGN_REVIEW_HANDOFF.md)에 전체 범위와 미완료 항목이 정리되어 있다. 과거 루트 구매 문서의 총수량은 이 구성에 자동 적용하지 않는다. **기존 `export_jlc_release.ps1`는 새 어댑터를 처리하지 않으며**, 이 문서가 새 Gerber/BOM/CPL 패키지의 생성 완료를 의미하지 않는다.

세 어댑터는 기존 RJ45 지그와 같은 stack-up을 사용한다. **임피던스 제어를 선택하는 편이 맞다.** 이로써 일정한 pair 구간의 제조 편차를 관리한다. 커넥터 접점, pad fanout, 표준의 기생성분은 별도 문제다.

## 주문 입력

| 항목 | 요청값 |
| --- | --- |
| board 종류 | 세 종류를 각각 식별하여 주문; universal M12로 합치지 않음 |
| 층 / 외형 | 4 layers / 각 66 × 40 mm |
| 두께 | 1.6 mm |
| stack-up | JLC04161H-7628 |
| 동박 | outer 1 oz / inner 0.5 oz |
| 재료 | **Nan Ya NP-155F 버튼 선택**; 변경 시 재계산 |
| mask / finish | green / ENIG |
| impedance control | Yes, differential 100 Ω, L1→L2 및 L4→L3 |
| pair 구조 | outer edge-coupled microstrip; 외층 blanket ground pour 없음 |
| 계산 반영 geometry | W 0.234 mm / edge gap 0.216 mm |
| impedance 검사 | 가능한 coupon 측정·성적서와 공차를 견적에 포함 |
| plate/drill | 신호 via 0.60/0.30 mm, M12 pin PTH 1.80/1.00 mm, RJ45 signal PTH 1.30/0.90 mm |

JLC의 [공개 stack-up](https://jlcpcb.com/impedance)과 [계산기 안내](https://jlcpcb.com/help/article/user-guide-to-the-jlcpcb-impedance-calculator)를 확인했다. 해당 적층의 outer dielectric 0.2104 mm, inner Cu 0.0152 mm, core 1.065 mm를 CAD에 넣었다. **0.234/0.216 mm는 2026-09-05 공식 계산기의 100Ω 목표 결과를 반올림해 적용한 치수다.** [실제 계산 화면·CAD 검증](../docs/jlcpcb/IMPEDANCE.md)과 [주문 옵션 전체/이유](../docs/jlcpcb/README.md)를 따른다. 100Ω 제조 공차는 현재 화면의 ±10% 옵션을 선택하고 CAM 및 coupon/성적서 제공을 확인한다.

다른 stack-up을 선택하면서 선폭/간격을 그대로 쓰지 않는다. M12의 0.15 mm RJ45 escape(Molex는 후속 개선으로 전 구간 0.234 mm), 커넥터 pin field와 넓은 fanout은 일정한 controlled trunk로 표시하지 않는다. coupon의 100 Ω 결과가 커넥터 전체의 100 Ω이나 RF 합격을 의미하지 않는다.

## 어댑터 한 장당 BOM

| Ref | 공통/종류 | 부품 | 수량 | 조립 |
| --- | --- | --- | ---: | --- |
| J1 | 세 종류 공통 | Amphenol RJE591885401, magnetics 없는 shielded RJ45 | 1 | THT |
| J2 | m12_slipring | Finecables MB12FBAFF08ST-3 | 1 | THT, 수동 또는 업체 삽입·납땜 |
| J2 | m12_llc | Finecables MB12MBAFF08ST-3 | 1 | THT, 수동 또는 업체 삽입·납땜 |
| J2 | molex_slipring | Molex 5055680571 | 1 | SMT, reflow 권장 |
| TP1 | M12 두 종류 | shield solder point | — | PCB 동박/홀, 별도 부품 없음; Molex에는 없음 |
| H1–H4 | 공통 | Ø3.2 mm mounting hole | — | 별도 브래킷/standoff |

J2는 해당 보드의 한 행만 사용한다. JLC 공급 가능 여부/재고는 확인 완료 상태가 아니다. M12를 직접 조달해 bare PCB에 손납땜하거나, JLC의 해당 부품 조달/위탁 지원을 확인한다. Molex까지 포함한 PCBA는 SMT+THT 혼합 조립 조건으로 견적을 받는다. 승인 없이 같은 외관의 다른 부품으로 대체하지 않는다.

공통 balun 보드의 ADT2-1T+와 SMA 조립은 [기존 BOM/제작 조건](../balun_eth_rj45/JLCPCB_FAB_NOTES.md)을 따른다. 어댑터에는 balun, 50 Ω 종단 또는 100 Ω Load 표준 저항을 실장하지 않는다. 외부 미사용 SMA load와 커넥터 끝 표준은 별도 준비물이다.

## 제작 전 확인할 실제 항목

1. 커넥터 샘플 또는 제조사 치수도로 정확한 suffix, 성별, component-side pin 번호, finished hole과 핀 길이를 확인한다. 사내 DUT에 실제 체결하고 continuity를 확인한다.
2. M12는 F면 수직 장착 + PG9 패널 고정이다. 패널 두께/홀 형상, connector seating 높이와 nut 공간, PCB standoff 높이는 실제 부품 도면으로 결정한다. PCB 4개 장착홀만으로 mating 토크를 신호 핀에 가하지 않는다.
3. M12는 shield patch cable과 TP1↔M12 body/패널 접속 여부를 결정하고 OSL/thru/DUT에서 동일하게 유지한다. Molex는 RJ45 SH와 내층 plane까지만 연결하고 DUT 측 shield bond는 두지 않는다.
4. 현재 공식 계산기 결과는 CAD에 반영했고 DRC/ERC/parity를 통과했다. 주문 CAM이 적층·geometry 변경을 제안하면 재계산하고 CAD 검사도 다시 수행한다.
5. KiCad에서 zone을 refill/save한 후 Gerber와 PTH/NPTH drill을 export한다. F.Cu/In1.Cu/In2.Cu/B.Cu, mask, silk, Edge.Cuts를 포함하고 내층 plane fill과 drill map을 CAM에서 확인한다.
6. JLC DFM/placement 화면에서 RJ45 방향, M12 성별·key, Molex pin 1을 확인한다. 첫 샘플은 continuity 및 보정 검증 뒤 평가용으로 사용한다.

현재 저장소는 이 확인에 사용할 **배선된 KiCad 설계와 검사 자료**를 제공한다. 실물 도면으로 확정되지 않은 패널 치수나 임피던스 성적서를 만들어내지 않았으며, 미확정 상태를 제작 완료로 표시하지 않는다.

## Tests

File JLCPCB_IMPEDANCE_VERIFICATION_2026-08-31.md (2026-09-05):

# JLCPCB 적층·임피던스 제조 검증 — 2026-08-31

> **과거 기록:** 이 문서의 0.35 및 0.23/0.22 mm 계산은 현 주문 기준에서 대체됐다. [2026-09-05 공식 계산기 화면·현재 CAD 검증](docs/jlcpcb/IMPEDANCE.md)을 우선한다. 과거 정량 결과를 이번 재검증 결과로 해석하지 않는다.

이 문서는 `balun_eth_rj45`, `balun_slipring/molex_end`, `balun_slipring/m12_end` 세 PCB의 JLCPCB 4층 제작 조건과 controlled-impedance geometry를 **2026-08-31 주문 화면 및 공식 계산 자료**에 맞춰 검증한 기록이다. 결론은 다음과 같다.

- 세 PCB의 주 전송선 geometry는 지정 적층에서 50 Ω / 100 Ω 목표와 잘 맞는다.
- 반드시 `JLC04161H-7628 (Standard)`를 명시하고, 다른 적층 또는 선폭으로 자동 변경된 production file은 승인하지 않는다.
- JLCPCB가 공표하는 controlled-impedance 생산 허용차는 ±10%다. 아래 계산값이 목표에 매우 가깝다는 사실은 완성 보드가 그보다 좁은 공차로 보증된다는 뜻이 아니다.
- RJ45 pad 앞의 0.15 mm neckdown, edge-launch SMA pad의 routed edge 접촉, SMA가 요구하는 보드 두께 공차는 별도의 release 위험이다. 아래 승인 절차를 생략하면 안 된다.

## 적용 범위와 authority

| 항목 | 적용 파일 |
| --- | --- |
| RJ45 지그 | `balun_eth_rj45/balun_eth_rj45.kicad_pcb`, `.kicad_pro`, `.kicad_dru` |
| Slip-ring Molex endpoint | `balun_slipring/molex_end/balun_slipring_molex.kicad_pcb`, `.kicad_pro`, `.kicad_dru` |
| Slip-ring M12 endpoint | `balun_slipring/m12_end/balun_slipring_m12.kicad_pcb`, `.kicad_pro`, `.kicad_dru` |

이 문서는 주문 설정의 release 기준이지만, 유전체와 solder-mask 입력값은 JLCPCB가 바꿀 수 있다. 따라서 **실제 주문 시점의 JLCPCB live calculator 결과, 선택된 stackup, production file이 최종 authority**다. 주문 직전에 계산 결과 화면 또는 PDF와 stack revision을 저장하고 이 문서와 대조한다.

## 지정 적층: JLC04161H-7628 (Standard)

세 `.kicad_pcb`에 저장된 적층은 서로 같고, JLCPCB 공식 `JLC04161H-7628` 치수와 일치한다.

| 위에서 아래로 | 재료/동박 | CAD 두께 | 주문 해석 |
| --- | --- | ---: | --- |
| F.Cu | Cu | 0.0350 mm | 외층 base copper 1 oz; impedance solver의 도금 후 외층 모델은 별도 |
| dielectric 1 | Nan Ya NP-155F, 7628 prepreg | 0.2104 mm | L1→L2 기준 높이, nominal Dk 4.40 |
| In1.Cu | Cu | 0.0152 mm | 내층 0.5 oz, 연속 GND reference |
| dielectric 2 | Nan Ya NP-155F core | 1.0650 mm | 중앙 core |
| In2.Cu | Cu | 0.0152 mm | 내층 0.5 oz, 연속 GND reference |
| dielectric 3 | Nan Ya NP-155F, 7628 prepreg | 0.2104 mm | L4→L3 기준 높이, nominal Dk 4.40 |
| B.Cu | Cu | 0.0350 mm | 외층 base copper 1 oz; impedance solver의 도금 후 외층 모델은 별도 |

동박과 dielectric 합은 CAD의 전체 두께 `1.5862 mm`다. JLC 주문값은 `1.6 mm`이며, JLC 공식 일반 두께 공차 ±10%를 적용하면 완성 두께 허용 범위는 약 `1.44–1.76 mm`다.

### 중앙 core Dk 불일치 — CAD를 자동 수정하지 말 것

현재 CAD의 1.065 mm core Dk는 `4.36`이다. 그런데 JLCPCB 공식 공개 calculator guide의 NP-155F core 표는 0.70 mm 초과 core에 `4.43`을 제시하고, 2026-08-31 live template API snapshot은 같은 template에 `4.38`을 제시했다. 서로 다른 공식 값이므로 `4.36`을 단순 오기로 단정할 수 없다.

현재 controlled traces는 L1/L4에서 바로 인접한 L2/L3 plane을 참조하므로 중앙 core Dk는 아래 외층 microstrip 계산에 직접 들어가지 않는다. **CAD는 현 상태로 유지**하고, 향후 내층 signal을 추가하거나 broadside coupling을 평가할 때 JLC의 그 주문 시점 stack data를 받아 다시 모델링한다.

## 공식 field-solver 재계산

계산 topology는 L1/L4의 `coated microstrip, non-coplanar`다. 인접 plane까지 `H = 0.2104 mm`, 7628 prepreg `Er = 4.40`, 외층 finished copper `T = 1.6 mil`을 사용했으며, etching compensation은 공식 guide대로 `W2 = W1 - 0.7 mil`을 사용했다. Ground pour와 via fence는 reference plane을 대신하는 coplanar side ground로 계산하지 않았다.

JLCPCB의 공식 자료 두 곳은 solder-mask 두께 입력이 서로 다르다. 두 조건을 각각 계산한 결과는 다음과 같다.

| 공식 snapshot | mask C1/C2/C3 | 50 Ω geometry 결과 | 100 Ω differential geometry 결과 |
| --- | --- | ---: | ---: |
| 공개 calculator guide, 2026-06-15 | 1.2 / 0.6 / 1.2 mil, Er 3.8 | `W=0.35 mm → 49.9328 Ω` | `W/S=0.23/0.22 mm → 100.1103 Ω` |
| live impedance API, 2026-08-31 | 1.0 / 0.6 / 1.0 mil, Er 3.8 | `W=0.35 mm → 49.9955 Ω` | `W/S=0.23/0.22 mm → 100.2795 Ω` |

두 공식 조건의 차이는 50 Ω 선로에서 약 0.063 Ω, 차동 선로에서 약 0.169 Ω로 매우 작다. 설계 결론은 변하지 않지만, live 설정이 변경될 수 있으므로 발주 당시 snapshot을 production release에 첨부한다.

JLCPCB가 공표하는 controlled-impedance tolerance ±10%를 적용하면 acceptance band는 50 Ω 선로 `45–55 Ω`, 100 Ω 차동 선로 `90–110 Ω`다. 이는 일반 선폭 공차가 아니라 JLC controlled-impedance service의 완성 임피던스 공차다.

## 실제 CAD geometry와 규칙 검증

| 검사항목 | 실제 값 | 판정/주의 |
| --- | --- | --- |
| RF50 main trace | 세 설계 모두 0.35 mm, L1/L4 | 계산 목표와 일치 |
| ETH100 main pair | 세 설계 모두 W/S 0.23/0.22 mm | 계산 목표와 일치 |
| signal reference | In1/In2 signal routing 금지, GND zone 사용 | 외층 microstrip 전제와 일치. Gerber에서 실제 plane polygon을 재확인해야 함 |
| Slip-ring RF launch | transformer courtyard의 0.55 mm flare 1.5 mm, 이후 W=0.35 mm 직선 1.0 mm와 2.54×2.54 mm jog; SMA까지 centerline 26.762102 mm | A/B가 22 mm 평행이동으로 동일하고 SMA에 직선 진입; production file에서 폭/경로를 임의 조정하지 않음 |
| Slip-ring RF trace–M3 | RF 긴 직선과 H3/H4 중심 6.0 mm; trace edge–In1 plane void edge 약 3.9745 mm | 금속 head/washer의 실제 외경·장착 면은 별도 기구 승인 필요 |
| RJ45 pair-B layer change | 0.60/0.30 mm signal via 2개 | JLC 일반 via 능력 안쪽이지만 via discontinuity는 REF fixture baseline에 포함됨 |
| 나머지 signal via | 없음 | 양호 |
| GND stitching via | 0.60/0.30 mm | JLC 능력 안쪽 |
| RJ45 PTH pad | pad 1.30 / drill 0.90 mm, annular ring 0.20 mm | JLC 4층 1 oz 권장치와 같음; 여유를 더 줄이면 안 됨 |
| RJ45 PTH-to-escape trace | 최소 약 0.295 mm | JLC 최소 0.28 mm보다 0.015 mm 큼. 권장 0.35 mm에는 못 미쳐 CAM 변경 금지 |
| board outline | RJ45 80×74 mm; slip-ring 약 68×44 mm | 일반 outline tolerance 사용 가능. slip-ring 44 mm 변 때문에 JLC precision-outline 최소 조건을 주문 시 재확인 |

세 `.kicad_pro`의 net class는 `RF50 = 0.35 mm`, `ETH100 = 0.23 mm / gap 0.22 mm`이고 `.kicad_dru`가 이를 좁은 범위로 고정한다. Gerber가 아직 authority가 아니므로, release 때 반드시 zone refill 후 DRC와 CAM 측정을 다시 수행한다.

### RJ45 0.15 mm neckdown — 확정된 국부 discontinuity

RJ45 J1 PTH 탈출부에는 각 conductor마다 폭 `0.15 mm` neckdown이 있다. 길이는 한쪽이 약 `3.04 mm`, 다른 쪽이 약 `5.07 mm`라 pair 내에서도 대칭이 아니다. A/C/D의 neckdown 구간 gap은 약 `0.87 mm`, layer-change가 있는 B pair의 분리 구간은 약 `2.91 mm`다.

동일한 JLC outer-layer 조건으로 0.15 mm 폭을 계산하면 대략 다음과 같다.

- W/S `0.15/0.87 mm`: 약 `140.94 Ω differential`
- W/S `0.15/2.91 mm`: 약 `144.42 Ω differential`

따라서 이것은 100 Ω controlled section이 아니다. 다만 3.04/5.07 mm는 1–200 MHz에서 전기적으로 매우 짧다. `Er_eff≈3`, 100 Ω 선로 안에 141 Ω section 하나만 있다고 단순화한 계산에서는 그 section 자체의 return loss가 약 100 MHz `48/44 dB`, 200 MHz `42/38 dB`이므로, 이 숫자만으로 RJ45 보드를 폐기할 정도의 결함이라고 판단하지 않는다. 실제 connector pad, 두 conductor의 전이 위치 차이와 pair-to-pair coupling은 이 단순 모델에 없으므로 mode conversion과 NEXT/FEXT floor는 여전히 REF 반복측정으로 확인해야 한다.

현재 2-port balun 구성은 `Sdc/Scd`를 직접 측정할 수 없다. 첫 PCB에서는 golden RJ45 REF를 사용한 S11/S22/S21/S12 반복성, 방향 비대칭과 crosstalk floor를 확인하고, 4-port mixed-mode 장비가 나중에 확보된 경우에만 gated `Sdd/Sdc/Scd/Scc`를 추가한다. PTH clearance를 침범하면서 단순히 0.23 mm로 굵히면 안 되므로 이 문서에서는 CAD 자동 수정 대상으로 보지 않는다.

### Edge-launch SMA pad — 일반 edge clearance 예외

SMA center/ground launch pad는 connector가 routed board edge에 물리도록 의도적으로 Edge.Cuts까지 닿는다. JLC의 일반 routed-edge copper clearance 권고와 충돌하므로 CAM이 copper를 pull-back, trim 또는 재배치하면 RF launch와 납땜 형상이 망가진다.

- 주문 Remark에 이 예외를 명시한다.
- `Confirm Production File = Yes`를 선택한다.
- production file에서 모든 SMA pad가 원본처럼 board edge까지 도달하는지 확대 확인한다.
- `Gold Fingers = No`, `Castellated Holes = No`, `Edge Plating = No`로 주문한다.
- 승인되지 않은 pad/outline/trace 변경이 있으면 결제 후라도 생산 승인을 거절하고 engineering clarification을 요청한다.

### SMA slot과 완성 PCB 두께 — sample-fit 필요

선정 `A-SMA-KE-16.5A`의 권장 PCB 두께는 `1.6 ±0.05 mm`지만, JLCPCB의 일반 1.6 mm board thickness 허용 범위는 ±10%, 즉 약 `1.44–1.76 mm`다. nominal만 일치할 뿐 connector 권장 범위를 제조 공차 전체에서 만족한다고 보장할 수 없다.

첫 소량 주문에서 bare PCB와 loose SMA를 양쪽 thickness extreme 관점으로 sample-fit하고, 필요하면 JLC engineering에 완성 두께 tighter control 가능 여부를 서면 확인한다. 이 확인 전에는 대량 PCBA를 release하지 않는다.

## JLCPCB 주문 화면에 넣을 정확한 값

세 설계를 **각각 별도 PCB/PCBA 작업**으로 주문한다.

| 주문 항목 | 선택값 |
| --- | --- |
| Base Material | `FR-4` |
| Layers | `4` |
| Product Type | `Industrial/Consumer electronics` |
| Different Design | `1` |
| Delivery Format | `Single PCB` |
| PCB Thickness | `1.6 mm` |
| PCB Color / Silkscreen | `Green / White` |
| FR-4 material | `Nan Ya NP-155F` |
| Surface Finish | `ENIG` |
| Outer Copper Weight | `1 oz` |
| Inner Copper Weight | `0.5 oz` |
| Specify Stackup | `Yes` |
| Stackup | `JLC04161H-7628 (Standard)` |
| Controlled impedance | 2026-08-31 4층 quote UI에는 별도 label이 보이지 않았으므로 `Specify Stackup = Yes`와 Remark로 지정. 주문 시 별도 toggle이 표시되면 `Yes`; 50 Ω single-ended / 100 Ω differential, standard `±10%` |
| Min Via Hole/Size tier | `0.3 mm / (0.4/0.45 mm)` tier; 실제 via는 0.30/0.60 mm |
| Via Covering | `Tented` |
| Via Plating Method | `Not Specified` |
| Board Outline Tolerance | `Regular ±0.2 mm`; SMA fit은 first-article sample로 검증 |
| Gold Fingers / Castellated / Edge Plating | 모두 `No` |
| Blind Slots / Backdrill / Press-fit | 모두 `No` |
| Electrical Test | `Flying Probe Fully Test` |
| Confirm Production File | `Yes` |
| Mark on PCB | `Remove Mark` |

주문 화면의 표현이 바뀌면 같은 의미의 현행 항목을 선택하고 screenshot을 release 기록에 보관한다. `Specify Stackup = No`, JLC 추천 대체 stack, 임의 선폭 보정은 허용하지 않는다.

PCB Remark에는 세 작업 모두 아래 문장을 그대로 넣는다.

```text
Controlled impedance: 50 ohm single-ended W=0.35 mm and 100 ohm differential W/S=0.23/0.22 mm on L1/L4 referenced to L2/L3. Use JLC04161H-7628 only. Do not substitute stackup or modify controlled trace widths. Edge-launch SMA pads intentionally reach the routed board edge; do not pull back, trim, or move these pads. Please provide the production file for approval before fabrication.
```

Gerber ZIP 안의 README나 메모는 주문 지시로 취급되지 않을 수 있으므로 이 문장은 반드시 order Remark field에도 입력한다.

## Production release gate

1. KiCad에서 모든 zone을 refill하고 ERC/DRC를 통과시킨다.
2. `--check-zones`를 사용해 Gerber를 생성하고, In1/In2 Gerber에 실제 연속 GND polygon이 있는지 CAM에서 확인한다.
3. Gerber의 main width/gap `0.35`, `0.23/0.22 mm`, RJ45 neckdown `0.15 mm`, edge-launch SMA pad/outline 접촉을 측정한다.
4. 주문 시점 live calculator와 선택 stack 화면을 PDF 또는 screenshot으로 보관한다.
5. 주문 Remark를 입력하고 `Confirm Production File = Yes`를 선택한다.
6. JLC production file에서 stack 이름/층 두께/동박, outline, drill, SMA edge pad, neckdown, GND planes를 원본과 대조한다.
7. stack substitution, controlled width 변경, edge-pad pull-back가 하나라도 있으면 승인하지 않는다.
8. first article에서 PCB thickness를 여러 지점 측정하고 SMA sample-fit, continuity, 2-port golden-REF 반복성/fixture-floor 검사를 통과시킨 뒤 full build를 release한다. 4-port mixed-mode/TDR은 장비가 있을 때 추가 검증으로 수행한다.

## JLCPCB 공식 근거

- [JLCPCB PCB Impedance Calculator](https://jlcpcb.com/pcb-impedance-calculator/)
- [User Guide to the JLCPCB Impedance Calculator — 2026-06-15](https://jlcpcb.com/help/article/user-guide-to-the-jlcpcb-impedance-calculator)
- [JLCPCB Impedance Stackup](https://jlcpcb.com/impedance)
- [JLCPCB PCB Capabilities](https://jlcpcb.com/capabilities/pcb-capabilities)
- [JLCPCB PCB Thickness](https://jlcpcb.com/resources/pcb-thickness)
- [Gerber Files Preparation](https://jlcpcb.com/help/article/gerber-files-preparation)
- [How to Generate Gerber and Drill Files in KiCad](https://jlcpcb.com/help/article/how-to-generate-gerber-and-drill-files-in-kicad-6)
- [Instructions for Ordering](https://jlcpcb.com/help/article/instructions-for-ordering)
- [JLCPCB Instant Quote / live order form](https://cart.jlcpcb.com/quote)

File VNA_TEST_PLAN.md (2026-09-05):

# 산업용 100BASE-TX 정적 평가와 커넥터 끝 보정

설계 변경의 이유, 구현 범위와 다른 검토자에게 요청할 질문은 [설계 검토 인계](DESIGN_REVIEW_HANDOFF.md)를 참고한다. 이 문서는 현재 측정 절차이며, 과거 전용 지그의 `MEASUREMENT.md`보다 우선한다.

상태: **구현 및 합성 검증 단계 / 실제 지그·표준 정확도 검증 전**. 우선 목적은 정상 케이블과 사내 커넥터·슬립링 조립체의 정적 전송 품질을 확인하는 것이다. 산업현장 사용 가능성의 1차 평가이며, 정식 인증이나 동적 신뢰성 시험을 대신하지 않는다.

## 1. 기준면과 구성

공통 `SMA–ADT2-1T+–RJ45` PCB 두 장을 사용한다. DUT 종류에 맞춰 RJ45–M12/Molex 어댑터를 교체한다. PCB 어댑터의 RJ45 jack까지 잇는 짧은 공장제 patch cable도 고정 fixture에 포함된다.

| 단계 | 포함되는 것 | 기준면 |
| --- | --- | --- |
| LibreVNA full 2-port SOLT | VNA와 두 coax 오차 보정 | 50 Ω coax 끝 |
| M12 등에서 표준 측정 | balun PCB, RJ45 연결, 어댑터를 통과한 O/S/L/T 데이터 | 아직 SMA 기준 데이터 |
| Python UnknownThru 적용 | 고정된 두 fixture의 오차를 표준 모델로 추정·제거 | 어댑터 뒤 DUT 접속면 |
| 최종 출력 | 그 사이 DUT의 유효 차동 two-port | 100 Ω balanced |

양끝이 서로 다른 커넥터여도 된다. 일반 RJ45 케이블은 RJ45 접속면에서 표준을 측정한다. **커넥터별 표준을 바꾸지 않고 어댑터만 교체해 같은 보정값을 쓰면 안 된다.**

측정하려는 커넥터가 보정 기준면보다 fixture 쪽에 있으면 그 특성도 보정에 흡수된다. 특정 커넥터 자체를 평가하려면 DUT 안에 그 커넥터/체결부를 포함하고, 기준면은 그 바깥에 둔다. 체결 접점의 fixture/DUT 경계는 표준 정의와 함께 기록한다. 케이블 포함 조립체 측정과 커넥터 단품 손실 분리를 혼동하지 않는다.

## 2. O/S/L과 자작 thru

O/S/L은 한 **차동 pair의 두 선 사이** 표준이다. SMA 외부 50 Ω load와 용도가 다르다.

| 표준 | M12 암 어댑터의 예 | 모델/제작에서 중요한 것 |
| --- | --- | --- |
| O | 어댑터를 비워 둔 상태 | 개방단 C와 주변 금속/손/다른 핀; 덮개·배치 고정 |
| S | mating 수 커넥터의 해당 pair를 최대한 짧게 연결 | 핀 길이, loop 면적, 직렬 L/R, 기준면에서의 지연 |
| L | 같은 pair 사이에 100 Ω 저항 | 짧은 SMD 저항 접속, 실측 저항값, lead/pad의 L/C |
| T | 양 어댑터에 맞는 mating 커넥터를 짧은 pair로 연결 | reciprocal, 충분한 전달, P/N 극성과 대략적인 편도 지연 |

Short나 Load를 shell/GND로 연결하지 않는다. 사용하지 않는 신호·전원 핀은 DUT 핀맵에 맞게 분리한다. 전원이 포함된 사내 케이블은 전원·활성 장비를 분리하고 무전압을 확인한 수동 상태에서 측정한다.

Open은 별도 부품 없이 가능하다. 다만 빈 암 Open과 수 플러그 끝에서 만든 S/L은 전기적 길이가 다를 수 있다. 이를 모델의 offset/기생성분에 반영한다. OSL 자체의 오차는 그 OSL을 사용한 보정으로 사라지지 않는다.

자작 thru의 전체 S-parameter를 미리 알아야 하는 일반 SOLT 대신 **UnknownThru/SOLR**를 사용한다. reciprocal 특성과 대략적인 위상/극성으로 전달 부호를 정한다. 180°로 떨어진 두 해를 구분할 수 있도록 예상 위상 오차를 90°보다 충분히 작게 유지한다. 모델 입력은 [analysis/README.md](analysis/README.md)를 따른다.

### 표준 오차의 크기 감각

다음은 100 Ω 기준의 단순 예시이며 실제 M12 기생성분 측정값이 아니다.

| 가정 | 100 MHz에서 표준 자체의 영향 |
| --- | --- |
| Load가 실제 101 Ω 순저항 | reflection 약 0.005, RL 약 46 dB |
| 100 Ω Load에 직렬 10 nH | 표준 RL 약 30 dB |
| Short에 직렬 10 nH | 이상적 Short와 반사 위상 약 7.2° 차이 |
| Open에 병렬 1 pF | 이상적 Open과 반사 위상 약 7.2° 차이 |

이 수치를 최종 DUT의 오차 막대와 동일시하지 않는다. 모델을 달리했을 때의 DUT 변화와 독립 검증 표준으로 신뢰 범위를 판단한다.

## 3. 어댑터 2 cm untwist는 보정되는가

항상 같은 형상의 선형·안정된 two-port로 보이는 반사, 지연과 손실은 커넥터 끝 보정에 포함될 수 있다. 3–4 cm 커넥터 몸체나 2 cm untwist만으로 불가능하다고 판단하지 않는다. 그러나 다음은 별개다.

- 움직이거나 다시 체결해 형상이 달라진 부분은 저장된 보정과 달라진다.
- 손실이 크면 보정 후에도 signal-to-noise와 dynamic range가 복구되지 않는다.
- pair 간 누설과 differential↔common-mode 변환은 단순 두 error box에서 완전히 제거되지 않는다.

양선 간격·길이 대칭, 작은 loop, strain relief와 기계 고정이 중요하다. 반복 측정용으로는 **PCB 어댑터를 우선** 검토한다. 임피던스 제어는 일정한 pair 구간을 개선하며 커넥터 pin field나 solder fillet까지 정확히 100 Ω으로 만들지는 않는다.

## 4. 실제 데이터 취득 순서

1. warm-up 뒤 실제 측정할 두 coax 끝에서 O/S/L과 알려진 SMA thru로 full 2-port SOLT를 수행한다. LibreVNA에서는 `SOLT_12` 등 실제 활성화된 양방향 보정을 확인한다. 포트별 SOL 두 개로 대체하지 않는다.
2. 두 포트에서 독립 50 Ω load/짧은 thru를 확인하고 VNA 설정·calibration 파일을 보관한다.
3. balun PCB와 patch cable, 어댑터, 미사용 SMA 50 Ω load, CT/shield 상태를 고정한다.
4. Port 1 O/S/L 3개, Port 2 O/S/L 3개, 자작 thru 1개를 complex Touchstone으로 저장한다. 한 O/S/L 세트를 순차 재사용해도 각 포트 측정 파일은 따로 필요하다.
5. Python으로 **7개 입력만** 사용해 `cal.npz`를 만든다.
6. 같은 full SMA SOLT를 켠 채 DUT를 연결해 `.s2p`를 저장한다. Python으로 `cal.npz`를 적용한다.
7. DUT를 바꿀 때마다 6번을 반복한다. 초기 검증 후에도 독립 check standard를 재측정한다.

모든 취득은 같은 frequency grid를 사용한다. 지그/adapter/coax 접속·배치·포트/pair·CT/shield·부하 상태 변경, SMA 재보정 또는 유의한 drift가 있으면 해당 구성의 표준 측정을 다시 한다. DUT 교체만 했어도 접속 반복성이 허용범위인지 확인한다.

## 5. 권장 초기 sweep

| 항목 | 시작값 |
| --- | --- |
| 주 평가 대역 | 1–100 MHz |
| 확장 관찰 | 100–200 MHz; 같은 sweep에서 분리 해석 가능 |
| points | 1001 또는 1601; 세션 전체 동일 |
| source | −10 dBm; 최초 −20 dBm과 비교하여 선형성 확인 |
| IFBW / 평균 | IL/RL 100 Hz / 8; 누설은 필요 시 더 좁은 IFBW와 반복 |
| CT / shield | CT-FLOAT 기본, 선택한 shield 경계를 표준·DUT 모두 동일하게 유지 |

이는 시험 시작 조건이며 Ethernet 표준 합격선을 정의하지 않는다. ADT2-1T+ 대역과 실제 fixture 특성을 함께 확인한다.

## 6. 정적 평가 항목

| 항목 | 보는 문제 / 결과 |
| --- | --- |
| continuity, 각 선 DC 저항과 pair 불균형 | 핀맵 오류, 납땜/접촉 불량; VNA 전에 확인 |
| pair A/B 각각 S11/S22 | 양쪽 반사, 임피던스 불연속 |
| S21/S12 | 삽입손실, notch, 방향 대칭성 |
| 전달 위상/group delay | 이상 지연·분산; 기준면과 thru 부호 모델에 의존 |
| 반복 체결·고정 재측정 | fixture와 커넥터 반복성 |
| 실제 전체 길이 조립체 | 사용 길이의 손실·반사 누적 |
| 필요 시 정지 각도별 반복 | 슬립링 접촉 상태의 각도 의존성 |
| NEXT/FEXT | 두 pair 사이 결합; 별도 연결과 누설 검증 |

적용할 커넥터/케이블/채널 규격, 길이, 주파수별 limit와 불확도를 정한 후 판단한다. 단일 `RL > 20 dB` 같은 임의 기준을 산업용 합격선으로 쓰지 않는다. 정상 REF 비교는 유용하지만 REF 차이를 dB로 빼는 것이 RL de-embedding은 아니다.

### NEXT/FEXT 연결과 제한

2-pair의 네 logical port `A_L, B_L, A_R, B_R`에 대해 아래 여섯 연결을 사용한다. S12를 얻으려고 같은 연결을 물리적으로 뒤집을 필요는 없다.

| 연결 | Port 1 | Port 2 |
| --- | --- | --- |
| A transmission | A_L | A_R |
| B transmission | B_L | B_R |
| NEXT_L | A_L | B_L |
| NEXT_R | A_R | B_R |
| FEXT_1 | A_L | B_R |
| FEXT_2 | B_L | A_R |

공통 4-pair RJ45 PCB 두 장은 VNA가 SMA 2개를 쓰고 나머지 **6개**에 외부 50 Ω load가 필요하다. 이 load는 nominally 100 Ω balanced 종단을 제공하는 용도이며 **DUT 접속면 OSL의 100 Ω Load 표준을 대체하지 않는다.**

각 연결의 error box 조합이 달라지므로 IL/RL pair A용 `cal.npz`를 NEXT/FEXT에 그대로 적용하지 않는다. 각 연결별 OSL/전달 경로 보정과 fixture floor를 확보한다. 다른 pair와 common mode가 강하게 결합하면 2-port 모델로 부족하다. 현재 Python 도구는 한 연결의 correction을 제공하며 전체 crosstalk matrix나 규격 판정을 자동화하지 않는다.

4-pair 케이블은 through 4개와 pair 조합 6개 × NEXT/FEXT 4개 = 총 28개 연결이다. 모든 미사용 포트가 nominally matched라는 조건에서의 pairwise 취득이다.

누설은 complex vector로 상쇄될 수 있다. fixture+REF floor와 가까운 결과에는 수치 합격을 부여하지 말고 floor-limited로 기록한다. floor보다 DUT 결합이 10–20 dB 큰 것은 실무상 유용한 여유지만 엄밀한 불확도 계산이나 보장된 upper bound를 대신하지 않는다.

## 7. 보정 후 확인

- 독립적으로 만든 다른 저항/선로를 확인한다. 보정에 쓴 O/S/L을 다시 이상적으로 만드는 것만으로 정확도를 입증하지 않는다.
- 자작 thru와 DUT의 방향/극성, 유효 대역 reciprocity와 passivity를 확인한다.
- 반복 탈착 분산, drift, 표준 모델 민감도를 기록한다.
- SMA 원본과 보정 후 결과를 함께 보존한다. 기준면과 출력 100 Ω reference를 확인한다.

balun 기반 two-port는 full mixed-mode Sdd/Sdc/Scd/Scc나 TCL/ELTCTL을 독립 측정하지 못한다. 이는 산업 EMI 관점에서 남는 항목이다. 정적 결과 이후 실제 PHY 트래픽·오류율, 회전 중 순간단선, 온도/진동/EMC 시험으로 연결한다. swept VNA가 짧은 dropout을 모두 검출한다고 가정하지 않는다.

## 근거와 이력

- [Mini-Circuits ADT2-1T+](https://www.minicircuits.com/pdfs/ADT2-1T%2B.pdf)
- [scikit-rf UnknownThru](https://scikit-rf.readthedocs.io/en/latest/api/calibration/generated/skrf.calibration.calibration.UnknownThru.html)
- [Keysight standard 모델](https://helpfiles.keysight.com/csg/e5080a/s3_cals/calibration_standards.htm)
- [JLCPCB impedance stack-up](https://jlcpcb.com/impedance)
- 종전 SMA-only 비교 문서는 [legacy 기록](docs/legacy/README.md)에 보존했다.

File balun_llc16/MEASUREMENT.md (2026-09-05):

# LLC-13M-1 비교 측정 초안

> **2026-09-05 이전 절차:** 이 문서는 LLC 전용 balun 보드와 SMA 기준 REF 비교 구성의 이력이다. 현재 공통 RJ45 지그 + 어댑터 구성은 [VNA_TEST_PLAN](../VNA_TEST_PLAN.md)의 adapter-end O/S/L + UnknownThru 절차를 따른다. 미사용 SMA 수, 기준면, 표준과 조달 지시는 새 구성에 그대로 적용하지 않는다. 변경 이유는 [설계 검토 인계](../DESIGN_REVIEW_HANDOFF.md)에 있다.

상태: **핀맵 문서 기반 계획 / 커넥터 및 PCB 검증 전 / 측정 실행 승인 아님**

LLC 케이블 측 암 / PCB 지그 측 수 방향은 2026-09-03 실물 사진과 사용자 확인으로 확정했다. 이는 아래 continuity와 전원 분리 검사를 대체하지 않는다.

아래 실물 검사는 **최초 VNA 연결 전** 절차이며 PCB 설계 시작의 선행 조건은 아니다. 설계는 제공된 PDF의 숫자 핀 번호와 배선선을 기준으로 진행한다.

## 안전과 입고 확인

- 구동기, 제어반, Ethernet 활성 장비, PoE 및 전원 꼬리선을 모두 분리한다. 전원 꼬리선은 한 가닥씩 절연해 서로 또는 금속물에 닿지 않게 고정한다.
- M12 1/7은 P24, 5/6은 N24다. 네 핀 모두 VNA 지그에서는 NC로 남긴다. N24를 VNA GND나 shell에 임의 접속하지 않는다.
- VNA 연결 전 전원과 잔류 전압이 없음을 확인한 뒤 아래 continuity/절연 관계를 검증한다. 발룬의 DC 절연을 전원 오접속 보호회로로 간주하지 않는다.
- 원본 도면의 500 VDC 절연 시험은 케이블 단독 검사 항목이며 VNA 측정이 아니다. VNA와 발룬 지그를 연결한 상태에서 절연저항계/내전압 시험을 하지 않는다.

| 검사 | 도면 예상 | 실측 기록 |
| --- | --- | --- |
| M12 8 | RJ45 1에 연결 | TBD |
| M12 2 | RJ45 2에 연결 | TBD |
| M12 3 | RJ45 3에 연결 | TBD |
| M12 4 | RJ45 6에 연결 | TBD |
| M12 1 / 7 | 각 P24 전원 꼬리선, Ethernet과 분리 | TBD |
| M12 5 / 6 | 각 N24 전원 꼬리선, Ethernet과 분리 | TBD |
| RJ45 4 / 5 / 7 / 8 | 도면상 신호 배선 없음 | TBD |
| M12 shell ↔ RJ45 shield ↔ 전원선 | 도면만으로 확정하지 않음 | TBD |

실제 핀 번호와 key를 사진에 함께 표시한다. 예상과 다른 회로를 기존 지그에 맞춰 억지로 연결하지 않는다.

## RJ45 공유와 기준면

한 번에 LLC M12 지그 1장과 기존 RJ45 지그 1장을 사용한다. RJ45의 A(J2, 핀 1/2)와 B(J3, 핀 3/6)가 측정 채널이다. C(J4)와 D(J5)는 DUT에서 사용하지 않지만 지그 측 SMA는 매번 50 Ω으로 종단한다.

기본 RCT는 양쪽 모두 DNP이며 RJ45의 사용하지 않는 C/D RCT도 DNP를 유지한다. RJ45 SHIELD-BONDED 또는 SHIELD-FLOAT 중 사용할 보드를 식별하고 REF/DUT 사이에 바꾸지 않는다. 실제 shell/shield continuity와 새 M12 기구의 접지 경로를 확인한 뒤 사용할 shield 상태를 고정한다. 두 기존 RJ45 assembly variant를 공유하므로 기본적으로 추가 저항 손납땜이 필요하지 않다.

동봉 O/S/L을 두 coax cable end에서 순차 재사용하고 F-F THRU로 full two-port SOLT를 수행한다. 이 교정은 M12와 RJ45 접점까지 기준면을 옮기지 않으며 발룬/PCB/커넥터 특성은 결과에 남는다.

LLC용 REF는 같은 M12/RJ45 커넥터 조합과 8→1, 2→2, 3→3, 4→6 결선의 알려진 짧은 100 Ω twisted-pair 하네스가 필요하다. 슬립링 Molex↔M12 REF와는 다르다. 완성 하네스 외주/조달을 별도로 검토하고 사용자 소형 커넥터 손작업을 가정하지 않는다. 짧은 REF 대비 13 m급 케이블 손실 증가는 길이 차이도 포함하므로 이를 결함으로 단정하지 않는다.

## S-parameter / NEXT / FEXT 연결표

`M_A/M_B`는 LLC M12 지그 J2/J3, `R_A/R_B/R_C/R_D`는 RJ45 지그 J2/J3/J4/J5다. 각 행에서 S11/S21/S12/S22를 함께 저장한다.

| 측정 | VNA Port 1 | VNA Port 2 | 50 Ω으로 종단할 SMA |
| --- | --- | --- | --- |
| A pair 전송·반사 | M_A | R_A | M_B, R_B, R_C, R_D |
| B pair 전송·반사 | M_B | R_B | M_A, R_A, R_C, R_D |
| M12 측 NEXT | M_A | M_B | R_A, R_B, R_C, R_D |
| RJ45 측 NEXT | R_A | R_B | M_A, M_B, R_C, R_D |
| FEXT 대각 1 | M_A | R_B | M_B, R_A, R_C, R_D |
| FEXT 대각 2 | M_B | R_A | M_A, R_B, R_C, R_D |

6개 coax 중 VNA가 2개를 사용하므로 **LLC 측정은 외부 load 4개**가 필요하다. 기존 공용 load 6개와 THRU 1개로 충분하며, 지그를 2개 보유한다는 이유만으로 종단·교정 부속을 배수 구매하지 않는다. 한 VNA로 순차 측정하는 조건이다.

## 측정 해석

- 기존 비교 설정의 1–200 MHz sweep부터 시작하고 sweep/IFBW/power/평균 횟수는 REF와 DUT에서 동일하게 유지한다. 주파수 상한을 늘리면 지그 자체 응답과 누설 바닥값부터 다시 확인한다.
- S11/S22의 반사, S21/S12의 전송·삽입손실, 필요 시 phase/group delay, 양단 NEXT/FEXT를 비교한다. 동축 케이블의 위치·굽힘·토크와 전원 꼬리선의 배치를 기록한다.
- 케이블 길이(도면의 13,000/13,500 mm 치수), 커넥터, 두 발룬과 두 PCB의 영향을 포함한 비교 측정이다. 혼합 M12+RJ45 지그의 응답을 기존 RJ45+RJ45 기준으로 단순 대체하지 않는다.
- 두 LLC 지그는 각자 동일 REF로 baseline을 확보해 지그 편차와 DUT 편차를 구분한다.
- 결과는 full mixed-mode Sdd/Sdc/Scd/Scc 또는 정식 Ethernet 인증 결과가 아니다. 정확한 기준면 이동에는 별도 fixture characterization/de-embedding이 필요하다.
- 판정 대역, insertion/return-loss 및 NEXT/FEXT 한계, 반복성 허용차와 noise-floor margin이 정해지기 전에는 PASS/FAIL로 표기하지 않는다.

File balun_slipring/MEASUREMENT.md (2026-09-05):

# Slip-ring comparison measurement worksheet

> **2026-09-05 이전 절차:** 이 문서는 전용 balun endpoint와 SMA 기준 REF 비교 구성의 이력이다. 현재 공통 RJ45 지그 + 어댑터 구성은 [VNA_TEST_PLAN](../VNA_TEST_PLAN.md)의 adapter-end O/S/L + UnknownThru 절차를 따른다. 미사용 SMA 수, 기준면, 표준과 조달 지시는 새 구성에 그대로 적용하지 않는다. 변경 이유는 [설계 검토 인계](../DESIGN_REVIEW_HANDOFF.md)에 있다.

상태: `DRAFT` — 문서 핀맵과 SMA land pattern은 반영했지만 REV-504 continuity, endpoint connector 기구, M12 실장 방향과 JLC wave-solder 승인이 미검증이므로 아직 제작하거나 측정에 사용하지 않는다.

## DUT와 안전 조건

- 대상: PALA720 2세대 `SRS1202-12CZ`, 100BASE-TX 2페어
- Pair A (`PAIR_TX`): TX+/- = Molex 1/2 ↔ M12 4/3
- Pair B (`PAIR_RX`): RX+/- = Molex 3/4 ↔ M12 2/1
- M12 5=GPS RS232_RX, 6=GPS 1PPS, 7=24VDC, 8=24VDC GND이며 지그에서는 모두 NC
- continuity와 VNA 측정 전 DUT를 24VDC, PoE 및 모든 활성 장비에서 분리

SRS1202 일반 자료의 정격은 100 rpm, 회로당 2 A, 동적 noise 50 mΩ max @ 100 rpm이다. 출하검사성적서의 절연 1.2 GΩ, 접촉회로 저항 241/248 mΩ 및 순간단선 양호는 외관·치수·DC 검사 범위이며 RF/Ethernet 합격 근거가 아니다.

## 기준면과 비교 방식

- LibreVNA의 coax cable 끝에서 각 포트의 SOLT를 수행한다.
- 이 SOLT로 기준면이 Molex/M12 접점까지 이동하지 않는다. 두 balun 보드, 커넥터와 fan-out은 fixture로 남는다.
- 먼저 두 지그 사이에 `REF/bypass`를 연결해 기준값을 저장하고, 같은 지그·케이블·설정에서 이를 슬립링으로 교체한다.
- 절대 differential S-parameter가 필요하면 별도로 검증한 2×thru/de-embedding 절차가 필요하다.

이 2-port 구성은 두 balun을 포함한 single-ended 비교 proxy이며 mixed-mode `Sdd/Sdc/Scd/Scc`를 각각 측정하지 못한다. 따라서 center tap 접지로 공통모드 escape path가 달라진 결과를 슬립링의 순수 differential 성능 변화로 해석하지 않는다. 절대 mixed-mode 분석에는 검증된 4-port 측정 또는 그에 맞는 fixture characterization/de-embedding이 필요하다.

## REF/bypass 확정표

| 항목 | 값 |
| --- | --- |
| REV-504 Ethernet housing | Molex `5055650501` 교차 슬라이드 추론 후보(정확한 MPN은 슬라이드 15의 별도 4세대 표); 2세대 실물 확인 TBD |
| Molex PCB mate | `5055680571`; 제조사상 `505565` series mate이나 실제 REV-504 체결 확인 TBD |
| M12 female | Finecables `MB12FBAFF08ST-3`; manufacturer female 8P PCB 배열을 적용한 PCB B면 후보이며 front-fastened 패널 기구, suffix, mating view와 A-key/pin-1 확인 TBD |
| REF Molex cable housing / contact | Molex `5055650501` (`C564750`) 1개 + matte-tin `5054311000` (`C385112`) 4개; 전용 압착 후 pull/continuity 검사 |
| REF M12 cable plug | NorComp `858FA08-103RAU1`, A-code 8-pin male, 4–6 mm cable gland; 실물 pin-1/key mating 확인 전 HOLD |
| REF cable | LAPP `2170284`, 2×2×AWG26/7, nominal 100 Ω Cat.5e SF/UTP; 완성 길이는 DUT connector-to-connector 실측 후 확정 |
| conductor/crimp 적합성 | cable core Ø 약 0.95 mm(최신 자료 max 1.04 mm), terminal 허용 Ø0.78–1.02 mm이므로 양산 전 실선 4가닥 압착·pull test 필수 |
| Pair A / Pair B | cable의 두 twisted pair를 각각 하나의 pair로 사용; connector 앞에서 필요한 최소 길이만 untwist |
| shield/drain 처리 | `CT-FLOAT` baseline에서 양단 모두 미접속·절연; 임의 chassis 연결 금지 |
| 제작물 식별번호 | TBD |

REF는 슬립링과 같은 양끝 커넥터 조합을 사용하고, 가운데는 알려진 짧은 100 Ω twisted pair로 직접 연결한다. 커넥터와 pin view를 실물로 확인하기 전에는 REF도 제작하지 않는다.

## LibreVNA 공통 설정

| 항목 | 값 |
| --- | --- |
| 주파수 시작/끝 | 기본 characterization `1–200 MHz`; `200–450 MHz`는 exploratory 별도 sweep |
| point 수 | 기본 `1001` 또는 `1601`; qualification 고정값 TBD |
| IFBW | IL/RL `100 Hz`, NEXT/FEXT `10–30 Hz`; qualification 고정값 TBD |
| source power | 기본 `−10 dBm`; `−20 dBm` 반복으로 선형성 확인; qualification 고정값 TBD |
| averaging | IL/RL `8`, NEXT/FEXT `16–64`; qualification 고정값 TBD |
| calibration kit / calibration 파일 | 두 cable end에서 O/S/L을 순차 재사용하고 SMA F-F thru를 측정한 LibreVNA `SOLT_12`; kit/thru ID와 calibration 파일명 TBD |
| coax cable 식별번호 | Mini-Circuits `CBL-2FT-SMSM+` 2개 또는 동급으로 검증된 동일 케이블 2개; 개별 ID TBD |
| 외부 50 Ω terminator 식별번호 | Mini-Circuits `ANNE-50+` 동일품 6개 공용 세트; LOAD-01–LOAD-06 실물 ID 부여 |

한 번 정한 설정은 REF, 정지 위치별 DUT와 회전 중 DUT 측정에 동일하게 적용한다.

ADT2-1T+ catalog의 사용 범위는 0.4–450 MHz이지만 1 dB transformer band는 1–200 MHz다. 따라서 목적이 상대 characterization이면 1–200 MHz를 우선 기본 대역 후보로 검토하고, 200–450 MHz는 REF fixture의 return-loss/crosstalk floor와 반복성을 먼저 측정한 뒤 exploratory 구간으로 분리한다. 정식 100BASE-TX 적합 판정이 목적이면 적용할 표준·limit와 fixture 제거 방법을 별도로 정해야 하며, 위 설정과 아래 합격선이 `TBD`인 동안 결과를 `PASS/FAIL`로 표시하지 않는다.

## 사용 전 확정할 판정 기준

| 항목 | 판정값 |
| --- | --- |
| REF 대비 insertion-loss 증가 허용치와 평가 대역 | TBD dB / TBD MHz |
| return-loss 최소치 또는 REF 대비 열화 허용치 | TBD dB |
| NEXT/FEXT 최대치와 fixture noise-floor margin | TBD dB |
| 0°/90°/180°/270° 간 최대 변동 | TBD dB / TBD ps |
| 회전 중 허용 dropout·접촉 변동과 검출 bandwidth | TBD |
| 반복 탈착/재측정 허용 편차와 반복 횟수 | TBD |

이 표를 채우기 전 절차는 비교 데이터 취득용 worksheet이지 재현 가능한 qualification 규격이 아니다.

RJ45 두 보드는 총 SMA 8개 중 VNA가 2개를 쓰므로 미사용 포트 종단용 `ANNE-50+`가 6개 필요하다. 슬립링 두 endpoint는 총 SMA 4개 중 2개만 미사용하므로 같은 6개 세트를 공유한다. 기존 종단기가 정확히 같은 정품 `ANNE-50+`로 확인되고 손상 없이 검증된 경우에만 신규 5개를 사고, 그 외에는 신규 동일품 6개를 구매해 미확인품을 측정 세트에 섞지 않는다.

NEXT/FEXT에서는 두 coax의 상호 결합이 측정 바닥값처럼 보일 수 있다. 두 케이블의 간격, 굽힘, 고정 위치와 connector torque를 REF/DUT 사이에 바꾸지 않는다. 구매 수량과 최신 조달 상태는 [`../JLCPCB_FINAL_BOM.csv`](../JLCPCB_FINAL_BOM.csv)를 따른다.

## Center-tap 조립 상태

| 상태 | Molex측 RCT1/RCT2 | M12측 RCT1/RCT2 | 용도 |
| --- | --- | --- | --- |
| `CT-FLOAT` | 모두 DNP | 모두 DNP | 기본 REF/DUT 비교 |
| `CT-GND` | 모두 0 Ω FIT | 모두 0 Ω FIT | 공통모드 민감도 확인용 별도 진단 |

기본 측정은 양단 네 개 RCT를 모두 비운 `CT-FLOAT`로 수행한다. `CT-GND`는 네 개를 동시에 장착한 별도 sweep으로만 수행한다. 양끝, TX/RX 또는 측정/미측정 pair 사이에 FIT/DNP 상태를 섞지 않는다. 미측정 pair의 SMA를 50 Ω로 종단해도 해당 pair의 RCT 상태는 다른 세 RCT와 같아야 한다.

`CT-GND`에서는 두 center tap이 LibreVNA의 공통 coax/chassis GND를 통해 연결된다. 실제 pair 불균형이나 mode conversion에서 발생한 공통모드 전류가 이 경로로 빠지면 일부 trace가 `CT-FLOAT`보다 좋아 보일 수 있으나, 이는 DUT 개선이 아니라 다른 공통모드 경계조건일 수 있다. REF와 DUT를 서로 다른 CT 상태로 비교하지 않는다.

## 2-port 전체 6개 연결표

`M`은 Molex endpoint, `C`는 M12 endpoint, Pair A는 TX, Pair B는 RX다. 각 연결에서 LibreVNA가 source 방향을 전환하므로 `S11`, `S21`, `S12`, `S22` 네 complex trace를 모두 `.s2p`로 저장한다. S12를 얻기 위해 cable을 물리적으로 뒤집지 않는다.

| ID | VNA Port 1 | VNA Port 2 | 사용하지 않는 SMA | 주요 결과 |
| --- | --- | --- | --- | --- |
| `A_THRU` | Molex Pair A (`A_M`) | M12 Pair A (`A_C`) | `B_M`, `B_C` 50 Ω | A의 S11/S22/S21/S12, phase/group delay |
| `B_THRU` | Molex Pair B (`B_M`) | M12 Pair B (`B_C`) | `A_M`, `A_C` 50 Ω | B의 S11/S22/S21/S12, phase/group delay |
| `NEXT_M` | `A_M` | `B_M` | `A_C`, `B_C` 50 Ω | Molex 쪽 NEXT; S21=A→B, S12=B→A |
| `NEXT_C` | `A_C` | `B_C` | `A_M`, `B_M` 50 Ω | M12 쪽 NEXT; S21=A→B, S12=B→A |
| `FEXT_ACROSS_1` | `A_M` | `B_C` | `A_C`, `B_M` 50 Ω | A_M→B_C와 reverse diagonal FEXT |
| `FEXT_ACROSS_2` | `B_M` | `A_C` | `B_C`, `A_M` 50 Ω | B_M→A_C와 reverse diagonal FEXT |

네 logical port의 모든 unordered port-pair는 `C(4,2)=6`개이므로 위 표가 전체 연결이다. 한 조합은 SMA 두 곳을 사용하며 외부 50 Ω 종단이 필요한 미사용 SMA는 **나머지 두 곳**이다. ADT2-1T+의 nominal 1:2 impedance ratio 때문에 SMA의 50 Ω load는 balanced 쪽에서 이상적으로 100 Ω differential termination으로 보이며 별도 100 Ω 종단 자작은 필요하지 않다.

전체 계산식, RJ45 28개 연결 체계, fixture-floor 판정과 권장 설정의 근거는 [`../VNA_TEST_PLAN.md`](../VNA_TEST_PLAN.md)를 따른다. DUT crosstalk가 fixture+REF floor보다 최소 10 dB, 가능하면 20 dB 이상 크지 않으면 정량 결과로 승인하지 않는다. 10 dB 미만은 `measurement-floor limited`, 6 dB 이내는 upper bound로 기록한다.

## 위치와 파일 이름

```text
YYYYMMDD_<REF|DUT>_<CTFLOAT|CTGND>_<A|B|AtoB|BtoA>_<ILRL|NEXT|FEXT>_<000|090|180|270|ROT>deg_<run>.s2p
```

각 측정 세트에 다음을 기록한다.

- REF/bypass와 DUT 식별번호
- DUT 0°, 90°, 180°, 270° 정지 상태와 가능한 경우 저속 회전 중 반복 sweep
- `CT-FLOAT` 또는 `CT-GND` 상태와 양쪽 보드 네 RCT의 육안/continuity 확인 결과
- 미사용 SMA 두 곳의 50 Ω 종단 상태
- M12 체결 상태와 회전 속도
- 이상이 나타난 각도와 반복 가능 여부

## 완료 조건

- [`PINMAP.md`](PINMAP.md)의 문서 예상값과 별도로 continuity 및 회전 접촉표 완료
- 두 커넥터의 실제 MPN, key/pin view와 기구 체결 확인
- REF의 실제 MPN·길이·배선·사진 기록
- 양 endpoint의 M3 head/washer 외경·재질·장착 면을 기록하고 RF trace/solder mask 비접촉 확인
- 각 측정에서 미사용 SMA 두 곳을 50 Ω로 종단
- `ANNE-50+` LOAD ID와 사용 포트를 기록하고 REF/DUT 사이에 같은 종단 배치를 유지
- calibration과 sweep 설정 저장, REF와 DUT에 동일 설정 적용
- 원본 Touchstone 파일을 수정하지 않고 별도 분석본 생성

`RS422_Cable_Assembly_Spec.pptx`의 10핀 encoder 케이블 핀맵과 길이는 본 측정 구성에 적용하지 않는다.

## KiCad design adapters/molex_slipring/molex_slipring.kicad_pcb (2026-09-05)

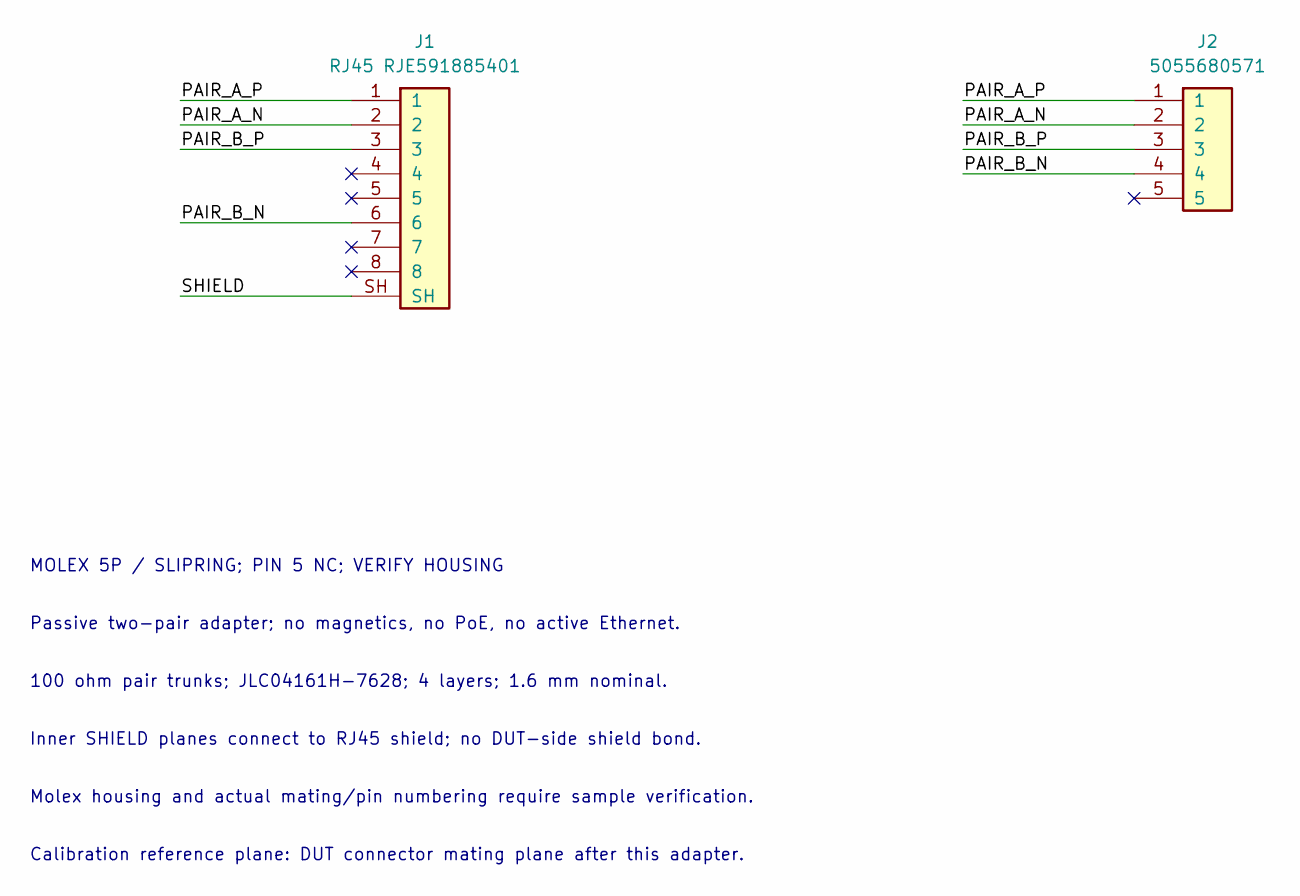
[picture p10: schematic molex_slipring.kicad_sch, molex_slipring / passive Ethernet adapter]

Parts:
J1: RJ45 RJE591885401; RJ45_Amphenol_RJE59-188-5401
J2: 5055680571; Molex_5055680571

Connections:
/PAIR_A_N: J1.2, J2.2
/PAIR_A_P: J1.1, J2.1
/PAIR_B_N: J1.6, J2.4
/PAIR_B_P: J1.3, J2.3
/SHIELD: J1.SH

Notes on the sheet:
MOLEX 5P / SLIPRING; PIN 5 NC; VERIFY HOUSING
Passive two-pair adapter; no magnetics, no PoE, no active Ethernet.
100 ohm pair trunks; JLC04161H-7628; 4 layers; 1.6 mm nominal.
Inner SHIELD planes connect to RJ45 shield; no DUT-side shield bond.
Molex housing and actual mating/pin numbering require sample verification.
Calibration reference plane: DUT connector mating plane after this adapter.

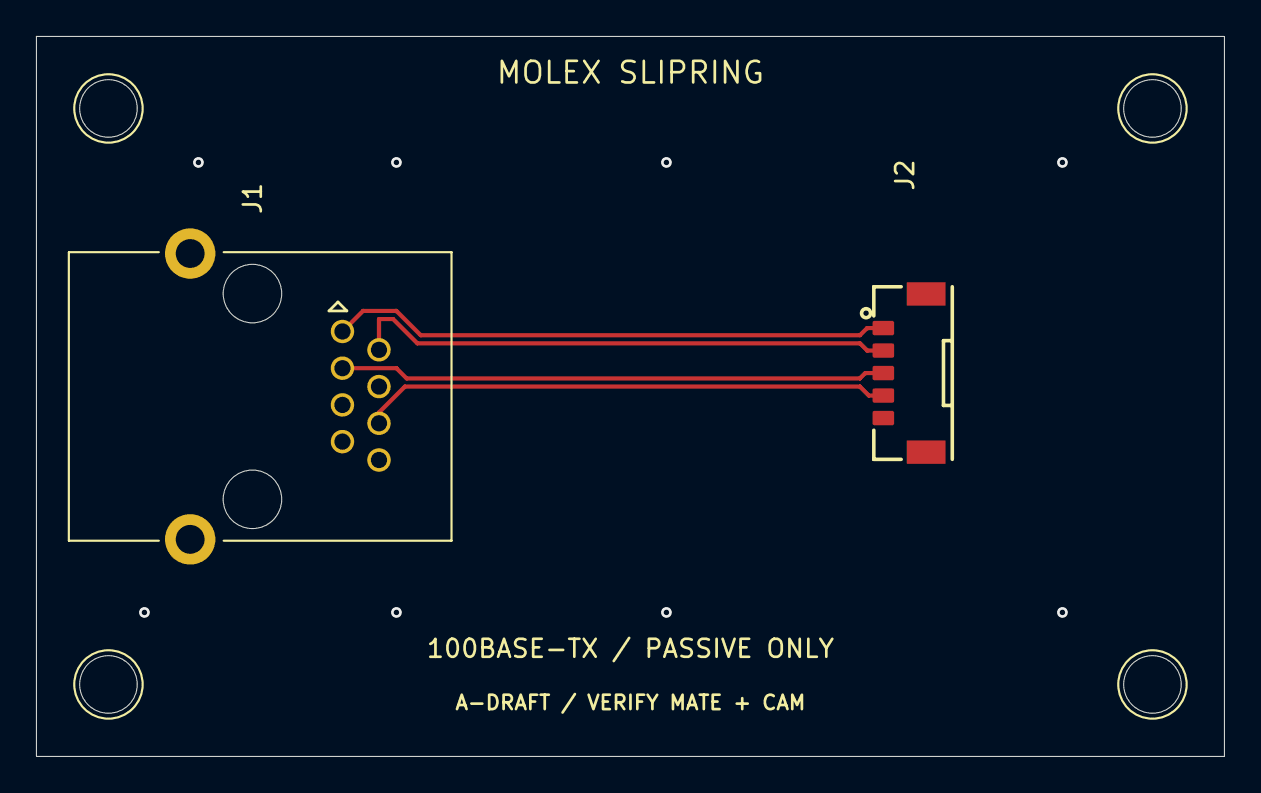
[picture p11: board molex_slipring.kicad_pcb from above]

Board: 4 copper layers, 66.0 x 40.0 mm, 6 parts (0 on the bottom side), 4 nets.

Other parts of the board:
H1, H2, H3, H4: (no value)

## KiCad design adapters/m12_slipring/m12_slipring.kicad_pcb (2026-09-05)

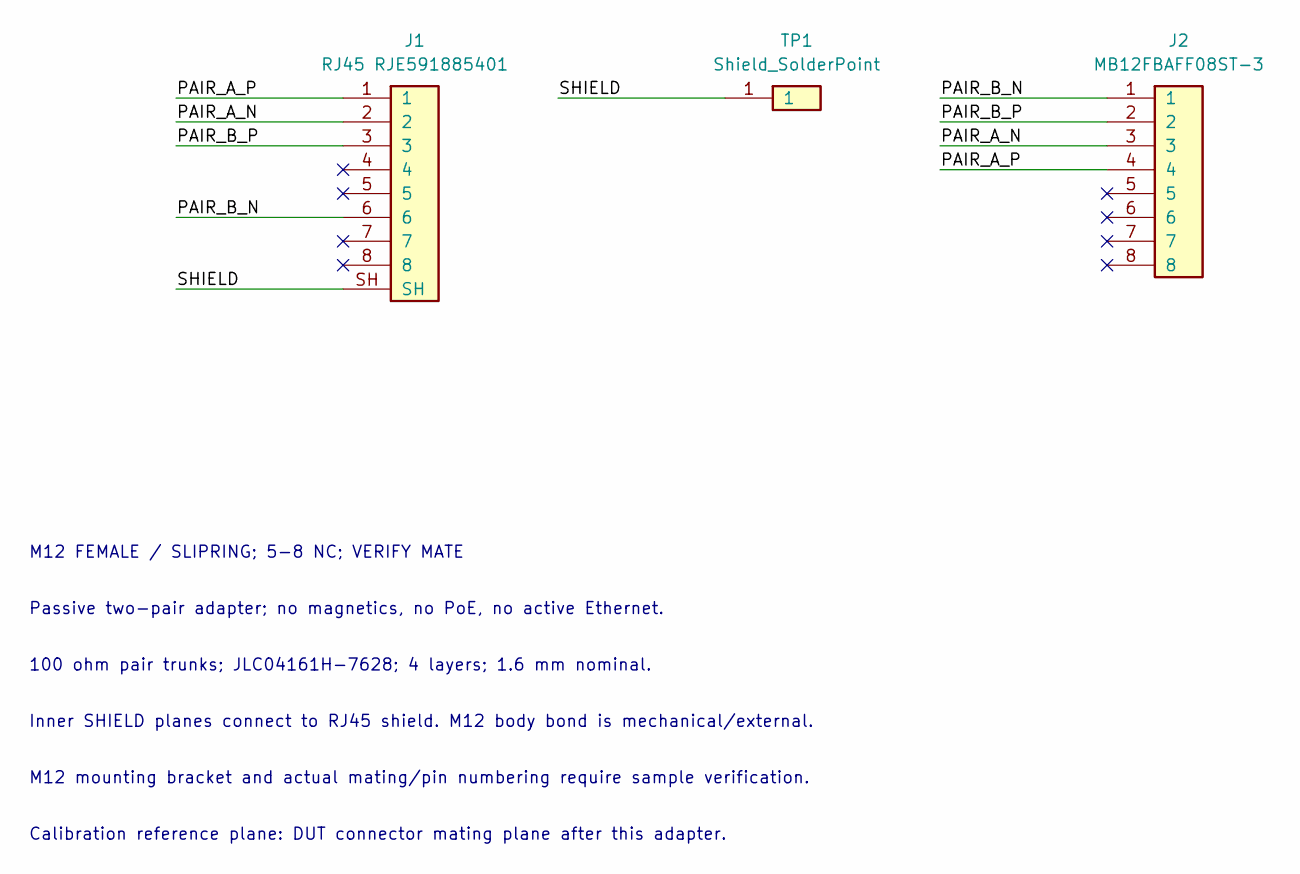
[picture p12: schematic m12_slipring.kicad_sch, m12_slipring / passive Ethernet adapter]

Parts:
J1: RJ45 RJE591885401; RJ45_Amphenol_RJE59-188-5401
J2: MB12FBAFF08ST-3; Finecables_MB12FBAFF08ST-3
TP1: Shield_SolderPoint

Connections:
/PAIR_A_N: J1.2, J2.3
/PAIR_A_P: J1.1, J2.4
/PAIR_B_N: J1.6, J2.1
/PAIR_B_P: J1.3, J2.2
/SHIELD: J1.SH, TP1.1

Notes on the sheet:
M12 FEMALE / SLIPRING; 5-8 NC; VERIFY MATE
Passive two-pair adapter; no magnetics, no PoE, no active Ethernet.
100 ohm pair trunks; JLC04161H-7628; 4 layers; 1.6 mm nominal.
Inner SHIELD planes connect to RJ45 shield. M12 body bond is mechanical/external.
M12 mounting bracket and actual mating/pin numbering require sample verification.
Calibration reference plane: DUT connector mating plane after this adapter.

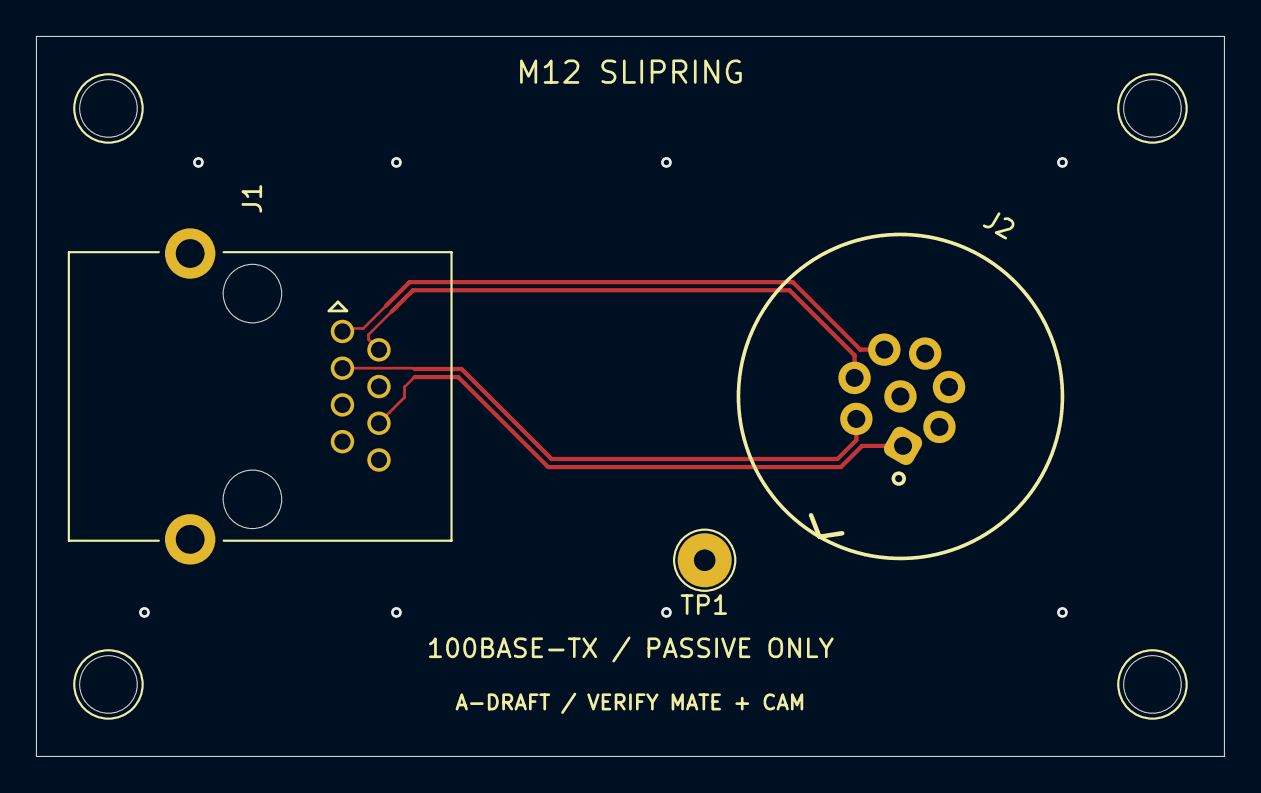
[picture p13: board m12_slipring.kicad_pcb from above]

Board: 4 copper layers, 66.0 x 40.0 mm, 7 parts (0 on the bottom side), 5 nets.

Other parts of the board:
H1, H2, H3, H4: (no value)

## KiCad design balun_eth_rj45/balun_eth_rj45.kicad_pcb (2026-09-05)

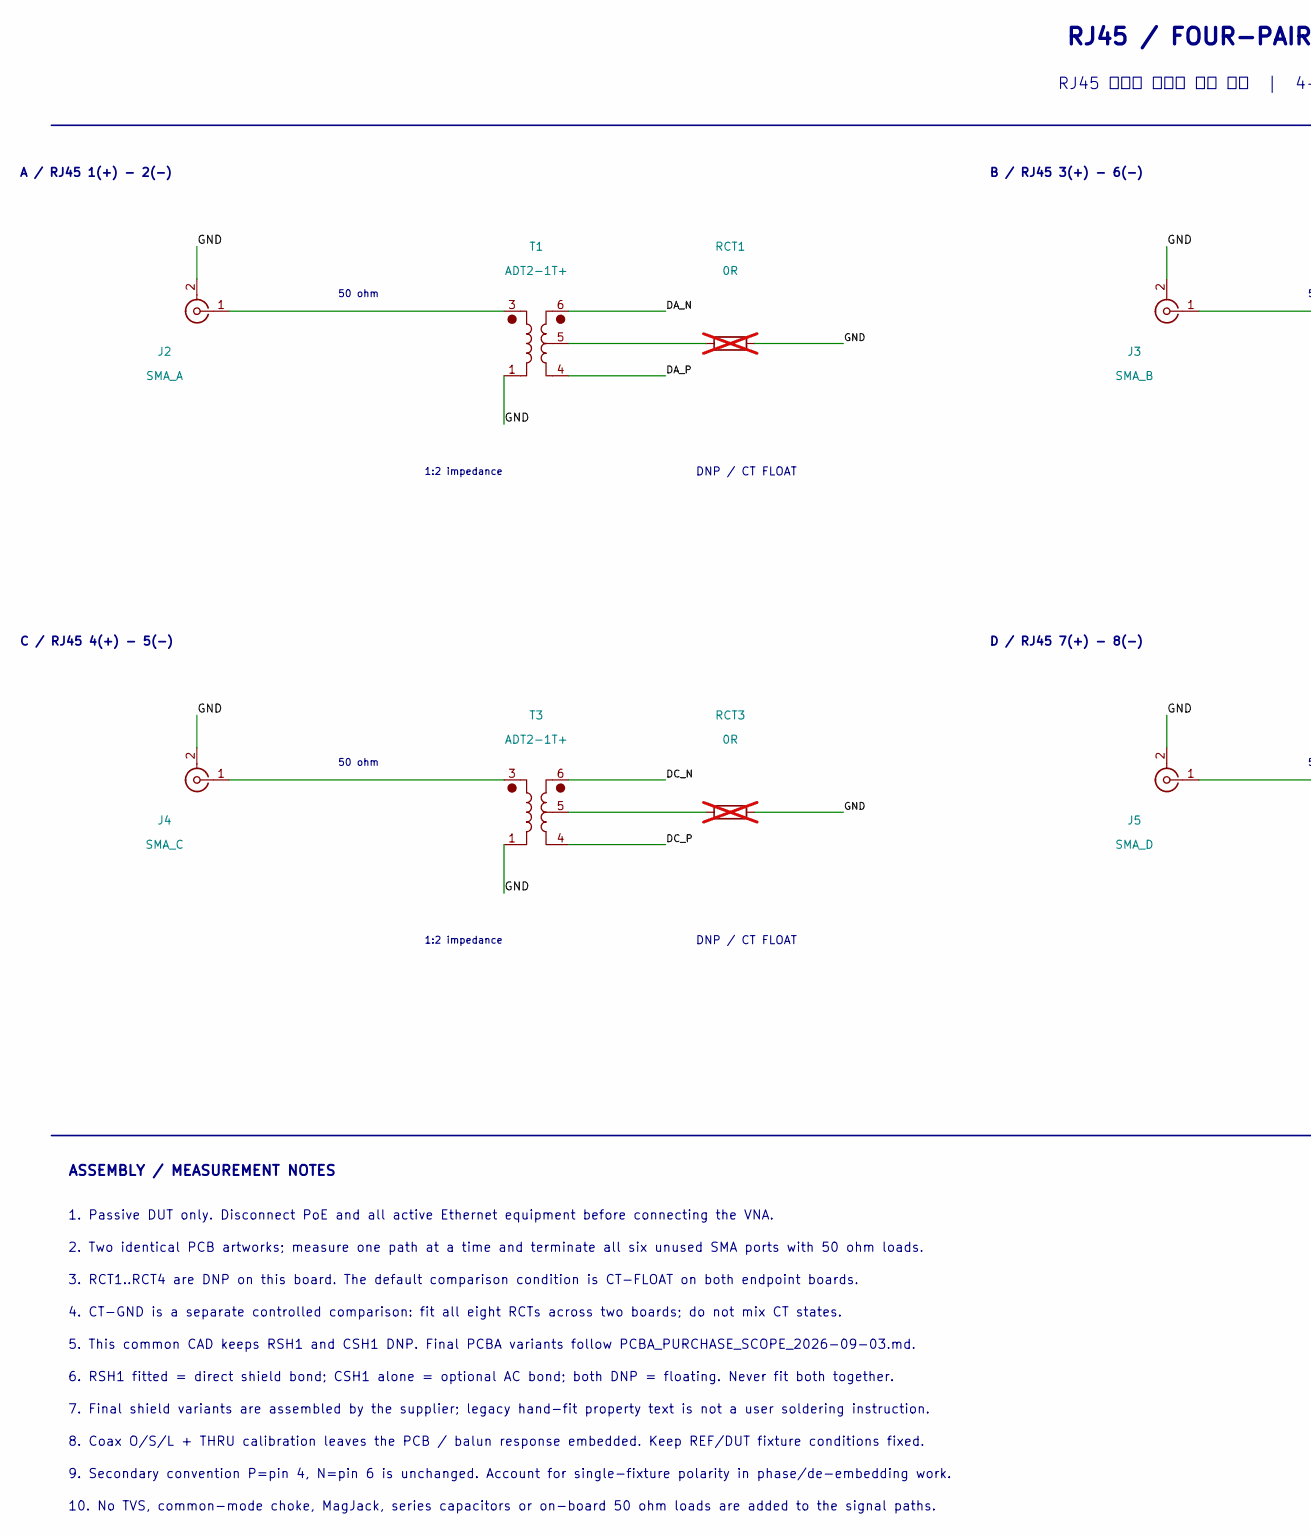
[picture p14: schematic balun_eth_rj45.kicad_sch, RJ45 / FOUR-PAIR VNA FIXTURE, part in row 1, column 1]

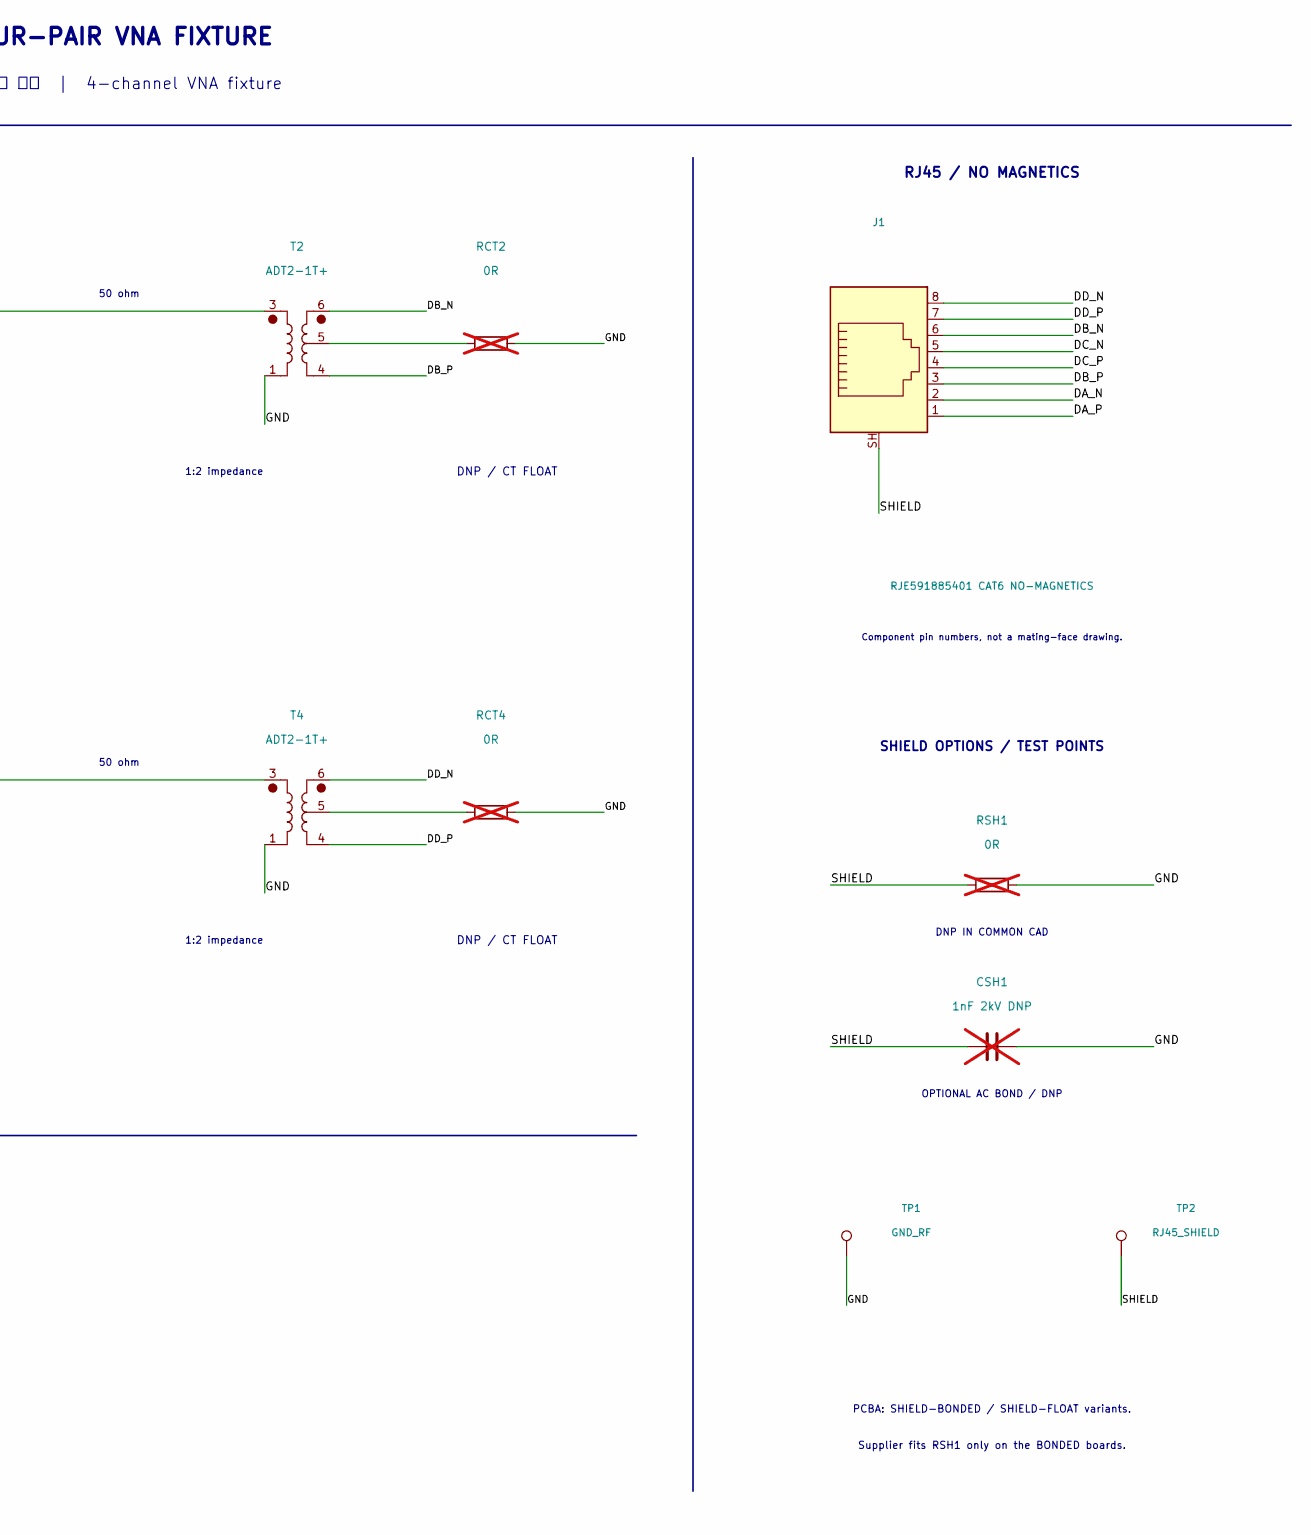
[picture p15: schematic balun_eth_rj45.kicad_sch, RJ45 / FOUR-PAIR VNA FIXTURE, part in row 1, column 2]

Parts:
CSH1: 1nF 2kV DNP; C_1206_3216Metric_Pad1.33x1.80mm_HandSolder; not fitted
J1: RJE591885401 CAT6 NO-MAGNETICS; RJ45_Amphenol_RJE59-188-5401; MPN RJE591885401; LCSC Part # C5386678
J2: SMA_A; SMA_MyAntenna_A-SMA-KE-16.5A_EdgeMount; MPN A-SMA-KE-16.5A; LCSC Part # C22467617
J3: SMA_B; SMA_MyAntenna_A-SMA-KE-16.5A_EdgeMount; MPN A-SMA-KE-16.5A; LCSC Part # C22467617
J4: SMA_C; SMA_MyAntenna_A-SMA-KE-16.5A_EdgeMount; MPN A-SMA-KE-16.5A; LCSC Part # C22467617
J5: SMA_D; SMA_MyAntenna_A-SMA-KE-16.5A_EdgeMount; MPN A-SMA-KE-16.5A; LCSC Part # C22467617
RCT1, RCT2, RCT3, RCT4: 0R; R_0805_2012Metric_Pad1.20x1.40mm_HandSolder; MPN 0805W8F0000T5E; LCSC Part # C17477; not fitted
RSH1: 0R; R_0805_2012Metric_Pad1.20x1.40mm_HandSolder; MPN 0805W8F0000T5E; LCSC Part # C17477; not fitted
T1, T2, T3, T4: ADT2-1T+; Mini-Circuits_CD542_H2.84mm; MPN ADT2-1T+; LCSC Part # C5223988
TP1: GND_RF; TestPoint_Loop_D2.50mm_Drill1.0mm; MPN 5001; LCSC Part # C238122
TP2: RJ45_SHIELD; TestPoint_Loop_D2.50mm_Drill1.0mm; MPN 5001; LCSC Part # C238122

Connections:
/DA_N: J1.2, T1.6
/DA_P: J1.1, T1.4
/DB_N: J1.6, T2.6
/DB_P: J1.3, T2.4
/DC_N: J1.5, T3.6
/DC_P: J1.4, T3.4
/DD_N: J1.8, T4.6
/DD_P: J1.7, T4.4
/GND: CSH1.1, J2.2 (Ext), J3.2 (Ext), J4.2 (Ext), J5.2 (Ext), RCT1.1, RCT2.1, RCT3.1, RCT4.1, RSH1.1, T1.1, T2.1, T3.1, T4.1, TP1.1
/SHIELD: CSH1.2, J1.SH, RSH1.2, TP2.1
unnamed: J2.1 (In), T1.3
unnamed: J3.1 (In), T2.3
unnamed: J4.1 (In), T3.3
unnamed: J5.1 (In), T4.3
unnamed: RCT1.2, T1.5
unnamed: RCT2.2, T2.5
unnamed: RCT3.2, T3.5
unnamed: RCT4.2, T4.5

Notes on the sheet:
RJ45 / FOUR-PAIR VNA FIXTURE
RJ45 이더넷 케이블 측정 지그 | 4-channel VNA fixture
A / RJ45 1(+) - 2(-)
50 ohm
DNP / CT FLOAT
1:2 impedance
B / RJ45 3(+) - 6(-)
C / RJ45 4(+) - 5(-)
D / RJ45 7(+) - 8(-)
RJ45 / NO MAGNETICS
Component pin numbers, not a mating-face drawing.
SHIELD OPTIONS / TEST POINTS
DNP IN COMMON CAD
OPTIONAL AC BOND / DNP
PCBA: SHIELD-BONDED / SHIELD-FLOAT variants.
Supplier fits RSH1 only on the BONDED boards.
ASSEMBLY / MEASUREMENT NOTES
1. Passive DUT only. Disconnect PoE and all active Ethernet equipment before connecting the VNA.
2. Two identical PCB artworks; measure one path at a time and terminate all six unused SMA ports with 50 ohm loads.
3. RCT1..RCT4 are DNP on this board. The default comparison condition is CT-FLOAT on both endpoint boards.
4. CT-GND is a separate controlled comparison: fit all eight RCTs across two boards; do not mix CT states.
5. This common CAD keeps RSH1 and CSH1 DNP. Final PCBA variants follow PCBA_PURCHASE_SCOPE_2026-09-03.md.
6. RSH1 fitted = direct shield bond; CSH1 alone = optional AC bond; both DNP = floating. Never fit both together.
7. Final shield variants are assembled by the supplier; legacy hand-fit property text is not a user soldering instruction.
8. Coax O/S/L + THRU calibration leaves the PCB / balun response embedded. Keep REF/DUT fixture conditions fixed.
9. Secondary convention P=pin 4, N=pin 6 is unchanged. Account for single-fixture polarity in phase/de-embedding work.
10. No TVS, common-mode choke, MagJack, series capacitors or on-board 50 ohm loads are added to the signal paths.

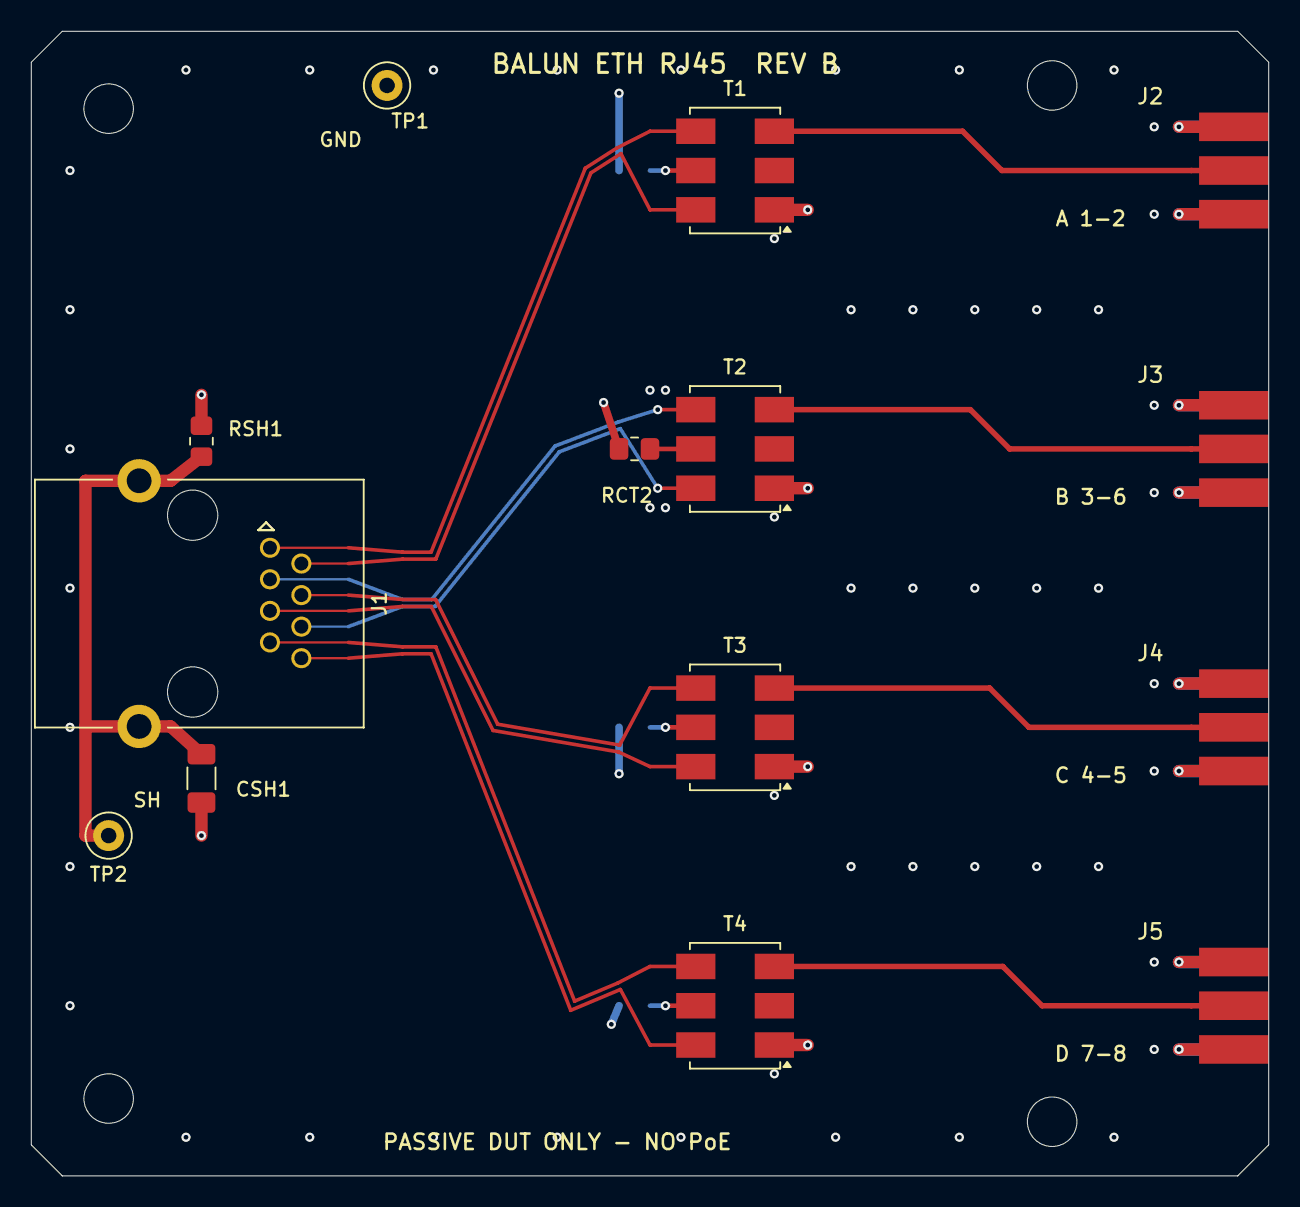
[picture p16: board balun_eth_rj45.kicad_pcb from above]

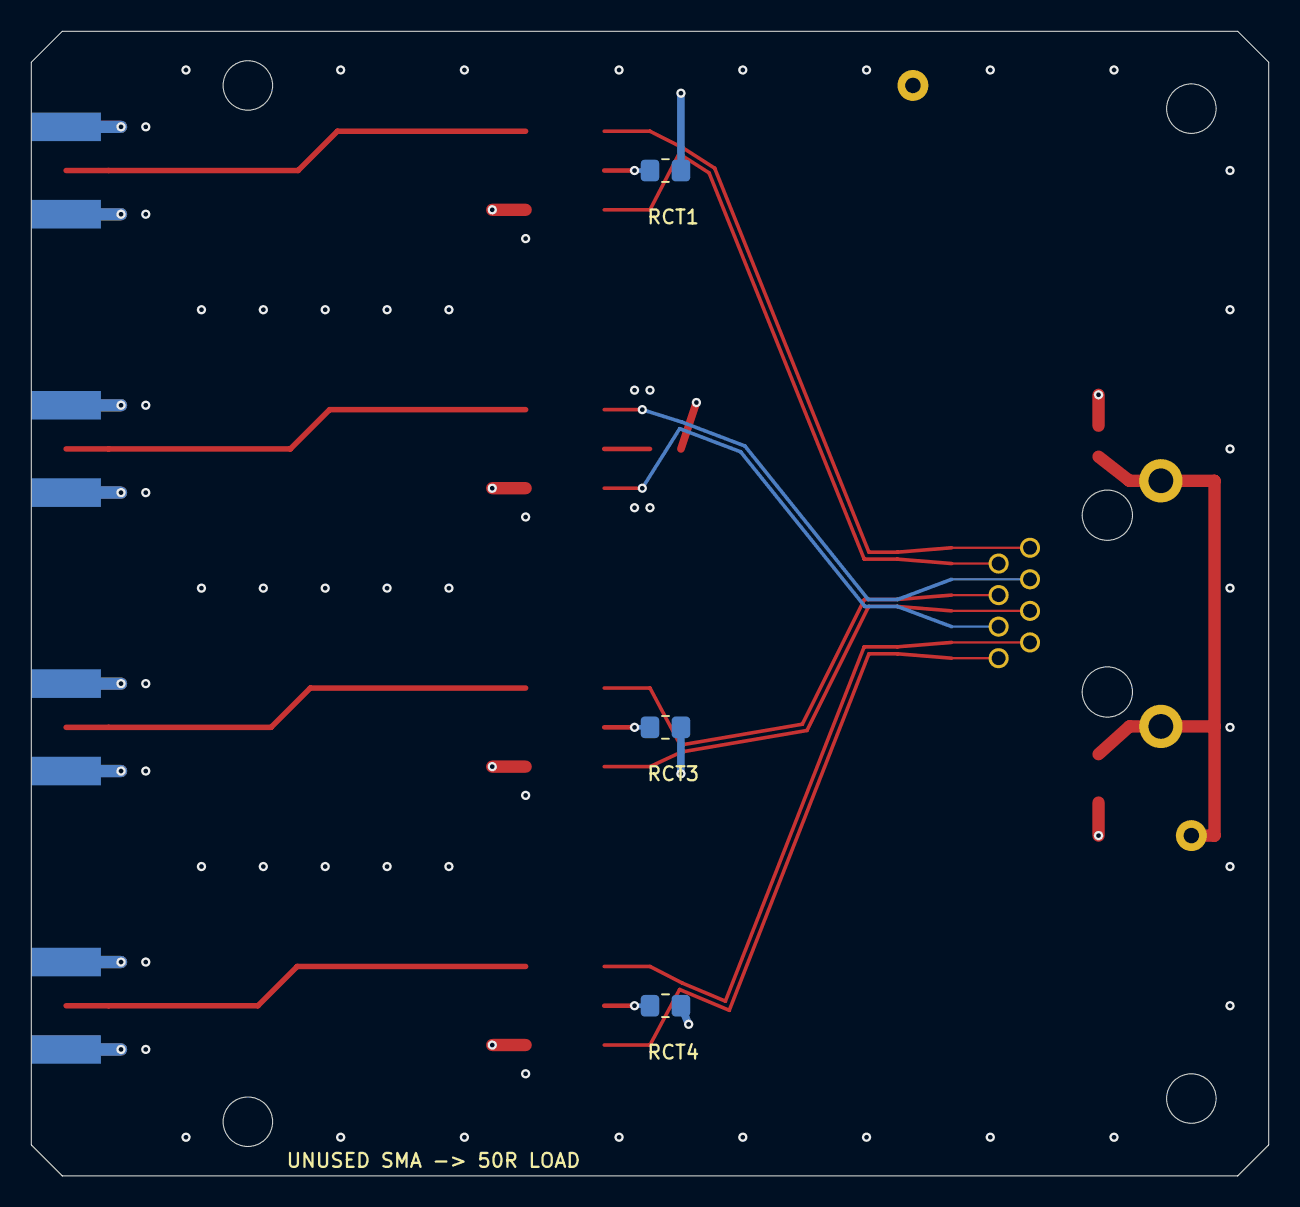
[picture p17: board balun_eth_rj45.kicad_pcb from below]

Board: 4 copper layers, 80.0 x 74.0 mm, 21 parts (3 on the bottom side), 18 nets.

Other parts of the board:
H1, H2, H3, H4: M3; MountingHole_3.2mm_M3

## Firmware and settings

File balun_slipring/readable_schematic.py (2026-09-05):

"""Presentation-only layouts for the three existing BALUN schematic designs.

Retain symbol/pin UUIDs, library definitions, component properties and net names.
Anonymous primary/CT nets stay wired directly; no new electrical labels are added.
"""

from __future__ import annotations

import re
import generate_pinmap_tbd_drafts as core


def quote(value: str) -> str:
    return value.replace("\\", "\\\\").replace('"', '\\"').replace("\n", "\\n")


class Sheet:
    def __init__(self, source: str, project: str):
        self.source, self.project = source, project
        self.root = re.search(r'\(uuid\s+"([^"]+)"', source).group(1)
        self.instances = core.find_symbol_instances(source)
        lib_start = source.index("\t(lib_symbols") + 1
        self.library, _ = core.balanced_expression(source, lib_start)
        self.drawing: list[str] = []
        self.placed: dict[str, str] = {}

    def uid(self, key: str) -> str:
        return core.stable_uuid(self.project, "readable:" + key)

    def text(self, key: str, value: str, x: float, y: float, size: float = 1.27,
             *, left: bool = False, bold: bool = False, korean: bool = False):
        font = '(face "Malgun Gothic")' if korean else ""
        weight = "(bold yes)" if bold else ""
        justify = "(justify left)" if left else ""
        self.drawing.append(f'''\t(text "{quote(value)}" (exclude_from_sim no)
            (at {x:g} {y:g} 0)
            (effects (font {font} (size {size:g} {size:g}) {weight}) {justify})
            (uuid "{self.uid(key)}"))''')

    def line(self, key: str, x1: float, y1: float, x2: float, y2: float):
        self.drawing.append(f'''\t(polyline (pts (xy {x1:g} {y1:g}) (xy {x2:g} {y2:g}))
            (stroke (width 0.254) (type default)) (fill (type none))
            (uuid "{self.uid(key)}"))''')

    def wire(self, key: str, x1: float, y1: float, x2: float, y2: float):
        self.drawing.append(core.schematic_wire(self.project, "readable:" + key, x1, y1, x2, y2))

    def label(self, key: str, name: str, x: float, y: float, size: float = 1.27):
        self.drawing.append(f'''\t(label "{quote(name)}" (at {x:g} {y:g} 0)
            (effects (font (size {size:g} {size:g})) (justify left bottom))
            (uuid "{self.uid(key)}"))''')

    def nc(self, key: str, x: float, y: float):
        self.drawing.append(core.schematic_no_connect(self.project, "readable:" + key, x, y))

    @staticmethod
    def field(block: str, name: str, x: float, y: float, rotation: int, size: float) -> str:
        match = re.search(rf'\(property "{re.escape(name)}" "((?:[^"\\]|\\.)*)"', block)
        original, _ = core.balanced_expression(block, match.start())
        angle = 90 if rotation % 180 == 90 else 0
        new = f'''(property "{name}" "{match.group(1)}" (at {x:g} {y:g} {angle})
            (show_name no) (do_not_autoplace no)
            (effects (font (size {size:g} {size:g}))))'''
        return block.replace(original, new, 1)

    def place(self, ref: str, x: float, y: float, reference: tuple[float, float],
              value: tuple[float, float], *, rotation: int | None = None, size: float = 1.27):
        assert ref not in self.placed, ref
        block = self.instances[ref]
        old = re.search(r'\(at [-\d.]+ [-\d.]+ ([-\d.]+)\)', block)
        rotation = int(float(old.group(1))) if rotation is None else rotation
        block = re.sub(r'\(at [-\d.]+ [-\d.]+ [-\d.]+\)',
                       f"(at {x:g} {y:g} {rotation})", block, count=1)
        block = self.field(block, "Reference", *reference, rotation, size)
        block = self.field(block, "Value", *value, rotation, size)
        self.placed[ref] = block

    def channel(self, number: int, x: float, y: float, positive: str, negative: str,
                *, rf_label: str | None, heading: str, heading_y: float):
        """SMA -> primary; secondary -> existing pair labels; CT -> RCT.2 directly."""
        jref, tref, rref = f"J{number + 1}", f"T{number}", f"RCT{number}"
        self.text(f"{tref}:heading", heading, x - 81.28, heading_y, 1.35, left=True, bold=True)
        self.place(jref, x - 53.34, y - 5.08, (x - 58.42, y + 1.27), (x - 58.42, y + 5.08))
        self.place(tref, x, y, (x, y - 15.24), (x, y - 11.43))
        # Rotating a nonpolar resistor changes only drawing orientation.
        # At 270 degrees its left pad is pin 2 (CT) and right pad is pin 1 (GND).
        self.place(rref, x + 30.48, y, (x + 30.48, y - 15.24), (x + 30.48, y - 11.43), rotation=270)
        self.wire(f"{jref}:rf", x - 48.26, y - 5.08, x - 5.08, y - 5.08)
        if rf_label:
            self.label(f"{jref}:rf-name", rf_label, x - 35.56, y - 5.08)
        else:
            self.text(f"{jref}:rf-note", "50 ohm", x - 27.94, y - 7.62, 1.1)
        self.wire(f"{jref}:gnd", x - 53.34, y - 10.16, x - 53.34, y - 15.24)
        self.label(f"{jref}:gnd-name", "GND", x - 53.34, y - 15.24)
        self.wire(f"{tref}:gnd", x - 5.08, y + 5.08, x - 5.08, y + 12.7)
        self.label(f"{tref}:gnd-name", "GND", x - 5.08, y + 12.7)
        self.wire(f"{tref}:n", x + 5.08, y - 5.08, x + 20.32, y - 5.08)
        self.label(f"{tref}:n-name", negative, x + 20.32, y - 5.08, 1.1)
        self.wire(f"{tref}:p", x + 5.08, y + 5.08, x + 20.32, y + 5.08)
        self.label(f"{tref}:p-name", positive, x + 20.32, y + 5.08, 1.1)
        self.wire(f"{tref}:ct", x + 5.08, y, x + 26.67, y)
        self.wire(f"{rref}:gnd", x + 34.29, y, x + 48.26, y)
        self.label(f"{rref}:gnd-name", "GND", x + 48.26, y, 1.1)
        self.text(f"{rref}:population", "DNP / CT FLOAT", x + 33.02, y + 20.32, 1.27)
        self.text(f"{tref}:ratio", "1:2 impedance", x - 11.43, y + 20.32, 1.1)

    def finish(self, paper: str, title: str, comments: list[str]) -> str:
        assert set(self.instances) == set(self.placed), set(self.instances) - set(self.placed)
        rev = re.search(r'\(rev "([^"]*)"', self.source).group(1)
        items = "\n".join(f'        (comment {i} "{quote(v)}")' for i, v in enumerate(comments, 1))
        return f'''(kicad_sch
    (version 20260306) (generator "eeschema") (generator_version "10.0")
    (uuid "{self.root}") (paper "{paper}")
    (title_block (title "{quote(title)}") (date "2026-09-03") (rev "{rev}")
{items}
    )
{core.indent_block(self.library, 1)}
{chr(10).join(self.drawing)}
{chr(10).join(core.indent_block(self.placed[r], 1) for r in self.instances)}
    (sheet_instances (path "/" (page "1")))
    (embedded_fonts no)
)
'''
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

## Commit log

2026-08-12 feat: add Rev B RJ45 balun VNA fixture
    [balun_eth_rj45.kicad_pcb, balun_eth_rj45.kicad_sch, balun_eth_rj45_bom.csv]
2026-08-12 docs: align shield assembly variant
    [balun_eth_rj45.kicad_pcb]
2026-08-12 feat: add slip-ring VNA fixture drafts
    [balun_slipring_draft_bom.csv, balun_slipring_m12.kicad_pcb, balun_slipring_m12.kicad_sch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]
2026-08-13 feat: finalize slip-ring fixtures and floating CT baseline
    [balun_eth_rj45.kicad_pcb, balun_eth_rj45.kicad_sch, balun_eth_rj45_bom.csv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]
2026-08-13 feat: finalize JLC parts and measurement BOM
    [JLCPCB_FINAL_BOM.csv, balun_eth_rj45.kicad_pcb, balun_eth_rj45.kicad_sch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]
2026-09-05 feat: add complete VNA fixture design set
    [JLCPCB_FINAL_BOM.csv, balun_eth_rj45.kicad_pcb, balun_eth_rj45.kicad_sch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]
2026-09-05 Add connector-plane UnknownThru workflow and JLCPCB adapter designs
    Use SMA-SOLT-corrected exports to build reusable 100-ohm balanced DUT correction. Add tested Python CLI, static Ethernet screening guidance, and three routed RJ45-to-M12/Molex adapters with native KiCad verification.
    Connector pin maps are unchanged from existing public project sources. Mechanical mating, JLC impedance signoff, and hardware RF validation remain pending.
    [m12_llc.kicad_pcb, m12_llc.kicad_sch, m12_slipring.kicad_pcb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]
2026-09-05 Clarify design intent, review handoff, and current documentation scope
    Explain the common RJ45 fixture plus passive adapter architecture, adapter-plane UnknownThru workflow, user goals, provisional PCB choices, and prioritized technical review questions.
    Reconcile active fixture assembly guidance and mark dedicated-balun measurement and purchase documents as historical. Explicitly record missing OSL/T PCB designs, hardware RF validation, JLC impedance confirmation, mechanical fit, and adapter manufacturing exports.
    Documentation only. Calibration code, CAD, connector pin maps, and existing export behavior are unchanged.
2026-09-05 Verify JLC stack impedance, update PCB widths, and document ordering options with screenshots
    [balun_eth_rj45.kicad_pcb, m12_llc.kicad_pcb, m12_llc.kicad_sch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]
2026-09-05 Refine Molex slip-ring adapter routing
    [molex_slipring.kicad_pcb, molex_slipring.kicad_sch]
2026-09-05 Review M12 slipring routing and enforce pair constraints
    [m12_slipring.kicad_pcb]
2026-09-05 Refine Molex pair escapes and reduce skew without signal vias
    Keep the latest all-F.Cu layout and connector placement, use 0.234 mm signal traces throughout, and reduce PCB pair skew to 0.792/0.987 mm. Extend uniform coupled trunks while documenting inter-pair 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
    Preserve the concurrent M12 routing and shared constraint updates. Retain the new gap/skew/uncoupled/via DRC checks, remove only the Molex narrow-trace exception, and support per-board verification.
    KiCad 10.0.6 DRC/ERC/parity, exact pinmap, NC isolation, netclass settings and generator geometry checks passed. Include before/after evidence and clarify the scope of the 1.27 mm PHY guideline.
    [molex_slipring.kicad_pcb]
